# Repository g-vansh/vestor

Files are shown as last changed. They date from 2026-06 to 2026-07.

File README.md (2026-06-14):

# Vestor

An RGB LED matrix that shows aircraft passing over Boston as seen from a window in
Cambridge, MA — built on a Raspberry Pi 4 + Adafruit Triple RGB Matrix Bonnet driving
16× P5 (64×32) HUB75 panels. Grows from a single-panel flight tracker into a
modular dashboard (flights → weather → MBTA → Bluebikes → animations).

**Derived from [its-a-plane-python](https://github.com/ColinWaddell/its-a-plane-python)
(GPL-3.0).** See `NOTICE.md`.

## For the build agent
Read **`AGENTS.md`** — it is the complete, autonomous build brief (hardware, git
workflow, secrets, architecture, runbook, troubleshooting, roadmap). Progress is
logged in `docs/BUILD_LOG.md`.

## Phases
- **0** — software installed + one panel renders live flights.
- **1** — full 16-panel wall (3 chains of 6+5+5).
- **2** — rotating multi-scene dashboard.

## Quick map
- `config.py` — geometry, ZONE_HOME, scene config (no secrets)
- `display/__init__.py` — matrix init (Triple Bonnet: `regular` / `parallel` / `FM6126A`)
- `scenes/`, `data/` — modular scenes and data clients
- `scripts/` — `flash_sd.sh`, `setup_pi.sh`, `install_app.sh`, `install_service.sh`
- `services/vestor.service` — systemd unit

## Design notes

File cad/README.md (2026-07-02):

# cad/ — parametric CAD for the Vestor wall build

Parametric models (CadQuery) for a **virtual fit-check** of the wall + 16 panels +
mount, driven by the locked dimensions in `docs/design/WALL_PROFILE.md` +
`MOUNT_DESIGN.md`. Outputs a combined **STEP** (open in Fusion 360) + per-part STL
+ PyVista fit-check renders.

## Toolchain (macOS)
CadQuery/OCP need Python 3.12 (the system 3.14 is too new for the OCC wheels), in a
venv **outside** the repo:
```
brew install python@3.12
python3.12 -m venv <venv> && <venv>/bin/pip install cadquery build123d pyvista numpy trimesh
```
Current venv: `…/scratchpad/cadenv` (session-scoped; recreate with the above).

## Use
```
<venv>/bin/python cad/model.py     # build -> cad/out/*.stl + vestor_wall_assembly.step
<venv>/bin/python cad/render.py    # -> cad/out/img/{overview,corner,section}.png
```
`cad/out/` (STL/STEP/PNG) is gitignored — regenerate from source. All dimensions
are variables at the top of `model.py`; edit there and re-run.

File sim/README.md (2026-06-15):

# Vestor LED Wall Simulator

A faithful, zero-dependency browser simulator for the Vestor LED matrix wall.
It renders both the **64×32 single panel** (Phase-0 flights-only bring-up) and
the full **1024×32 wall** (16 panels, 201.6") exactly as the real HUB75 phosphor
will glow — round emitters with dark inter-pixel gaps, gamma 2.2, additive bloom,
64-px panel seams, scanlines, and a vignette.

> Full design rationale: [`../docs/design/DESIGN.md`](../docs/design/DESIGN.md).
> Data sources: [`../docs/design/API_REFERENCE.md`](../docs/design/API_REFERENCE.md).

## Run it
```bash
# from this folder
python3 -m http.server 8765
# open http://localhost:8765
```
Or just double-click `index.html` — it runs from `file://` (classic `<script>`
tags, no build step, no npm).

## Controls
- **Scene mode** — `DASHBOARD` (zoned city dashboard) · `FLIGHT TAKEOVER` (whole
  ribbon = one giant flight strip + departures board) · `MARQUEE` (scrolling
  ticker).
- **Data source** — `SIMULATED` (synthetic, offline, default) · `LIVE APIS`
  (pulls **real** Open-Meteo weather and Bluebikes availability; falls back to
  simulated on any error).
- **Brightness**, **View** (1:1 pan / fit-width), **Auto-pan**.

## Architecture
| File | Role |
|---|---|
| `led.js` | `LEDMatrix` (linear-light framebuffer, authored 5×7 + 3×5 pixel fonts, icon sprites, drawing primitives) and `LEDRenderer` (the faithful optical pipeline) |
| `scenes.js` | Every scene + animated helpers: `SplitFlap` (Solari flips), `Marquee`, `drawRadar`, `gauge`, and `FlightScene` / `WeatherScene` (°C **and** °F) / `BluebikesScene` / `ShuttleScene` / `ClockScene` / `ExtrasScene` / `StatusEndcap` |
| `data.js` | `DataModel` — believable synthetic animation, plus an optional real-API overlay shaped identically to the live endpoints |
| `app.js` | Builds both matrices/renderers, lays out the three wall modes, runs the render loop, binds the console |
| `index.html` + `styles.css` | The "Departure Board Noir" showcase page |

## Fidelity notes
The renderer models emission, not rectangles:
`linear framebuffer → brightness → gamma 2.2 LUT → nearest upscale →
destination-in round-dot mask → additive bloom (2 passes) → scanline/seam/vignette
overlay`. The single panel renders at a chunky 14-px pitch; the wall at a 5-px
pitch so the full 5120-px-wide ribbon pans like a transit ticker.

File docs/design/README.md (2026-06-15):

# VESTOR — Design & Simulation

This folder is the **design home** for the Vestor LED wall: what it shows, how it
looks, the data behind it, and the research that informed it. A fully interactive
**simulator** of everything here lives in [`/sim`](../../sim/).

## Contents
- **[DESIGN.md](DESIGN.md)** — the master visual design document: the two
  displays (64×32 Phase-0 and the 1024×32 wall), the "Departure Board Noir"
  aesthetic, palette, fonts, the faithful LED optical model, the wall zone map,
  per-scene specs, the three wall modes, and the design rules.
- **[API_REFERENCE.md](API_REFERENCE.md)** — every live data source with exact
  endpoints, station/route/stop IDs, field maps, and CORS/key notes.
- **[RESEARCH.md](RESEARCH.md)** — survey of cool HUB75/RGB-matrix projects and
  the 32-px-tall design patterns + power/color/motion findings that shaped the
  design.

## The simulator (`/sim`)
A faithful, dependency-free browser simulator that renders both displays exactly
as the phosphor will glow — round emitters, gamma 2.2, additive bloom, 64-px
panel seams, scanlines — driven by either synthetic or **real live** data.

```bash
cd sim && python3 -m http.server 8765   # then open http://localhost:8765
```
or just open `sim/index.html` directly (it runs from `file://`).

| File | Role |
|---|---|
| `sim/led.js` | `LEDMatrix` (framebuffer + 5×7/3×5 fonts + icons + primitives) and `LEDRenderer` (the optical model) |
| `sim/scenes.js` | All scenes + animated helpers (`SplitFlap`, `Marquee`, radar, gauges) |
| `sim/data.js` | `DataModel` — synthetic animation + optional live API overlay |
| `sim/app.js` | Wiring: builds both matrices, the 3 wall modes, the console |
| `sim/index.html` / `styles.css` | The showcase page |

**Controls:** scene mode (dashboard / flight-takeover / marquee), data source
(simulated / live), brightness, view (1:1 pan / fit-width), auto-pan.

## How this maps to the hardware
The simulator targets the final **1024×32 logical** surface. On the Pi, a
pixel-mapper folds the 3 physical chains (6+5+5 panels = 384×96) into that ribbon,
and Python scenes under `scenes/` render the same data shapes the simulator uses.
See `docs/HARDWARE.md` and `docs/RUNBOOK.md` for the build, and `tools/` for the
live data clients.

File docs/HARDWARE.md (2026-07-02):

# HARDWARE

- **Pi 4 Model B, 4GB** (not Pi 5 — hzeller driver maturity).
- **Adafruit Triple RGB Matrix Bonnet 6358** — active3, 3 chains, no onboard power, no soldering. Ports 1/2/3; Port 2 = center of 3 adjacent panels.
- **16× P5 HUB75** 64×32, ~320×160mm, 1/16 scan, **FM6124HJ** chip (a STANDARD driver — needs NO init string, unlike FM6126A/FM6127; A–D address, no E). **Brand CnGear, board rev JHT2.0, SMD2121** — verified off the physical boards 2026-06-29. Each panel has an **integrated plastic rear frame** (X-braced); **no magnets included** — mounting method TBD (see `INVENTORY.md` §6/§8).
- **Wall topology (LOCKED 2026-06-21): one continuous 16-wide row, fed from the CENTER as 2 chains of 8** (`--led-parallel=2 --led-chain=8`). Pi+bonnet center-mounted; chain 0 → left (panels 8→1, mounted 180°/SW-flipped), chain 1 → right (panels 9→16). Keeps every HUB75 ribbon <50cm. (Superseded the earlier 6+5+5 plan, which needed 1.9–3.5 m jump cables in a single row. See `docs/INVENTORY.md` §5.)
- **⚠️ Topology RECONSIDERED 2026-07-02 (corner electronics):** the Pi/bonnet now go in the room's **left corner** (the wall's grooved feature turns the corner). The corner is the row's left END, so the center-fed 2×8 would need a ~2.5 m bonnet ribbon (bad — HUB75 wants < ~50 cm). **CONFIRMED 2026-07-02: single chain of 16 from the corner** (`--led-chain=16 --led-parallel=1`), keeps every ribbon short + **removes the "snake"/180° left-half flip** in `display/__init__.py`. **Refresh MEASURED on the Pi** (slowdown=4): old 2×8 = 150 Hz @11-bit; 1×16 = 86 Hz @11-bit, **111 Hz @9-bit**, 123 Hz @8-bit, 139 Hz @7-bit. **Recommended: `pwm_bits=9` → 111 Hz** (flicker-free + 512 levels/ch, ample for text/logos/fades). Could raise further by dropping `gpio_slowdown` to 3/2 if signal stays clean (wall-time tune). Full analysis: `docs/design/MOUNT_DESIGN.md`.
- **Mount anchor (owner-confirmed 2026-07-02): a full-width STRUCTURAL WOODEN rail** at the top of the wall — a 2 cm lip standing **3.4 cm proud**, with a continuous **open-top pocket (1.4 cm wide × 5 cm deep)** running the full ~512 cm. Plan: hang the whole row from a **top cleat/tongue (≤1.4 cm) dropped into the pocket**; the 3.4 cm projection gives standoff behind the panels; PSUs mount separately. Full geometry, panel-row sizing, load path + constraints in **`docs/design/WALL_PROFILE.md`**. (Resolves the panel "mounting method TBD" above — the cleat replaces the need for magnets on the plastic rear frames.)
- **Power:** Mean Well **LRS-350-5** (5V/60A) ×2 for the wall (1 for Phase 0), fork-lug AC cord. Panels powered from PSU; **bonnet logic from Pi 5V GPIO rail**.
- **SD:** 64GB Verbatim microSDXC (V10/U1; image a backup once set up).
- **Flash host:** Mac + built-in SDXC + Raspberry Pi Imager.

## The 3 settings that matter
1. `--led-gpio-mapping=regular` (NOT adafruit-hat).
2. `--led-parallel=3` wall / `1` test; `--led-chain=6` wall / `1` test.
3. `--led-panel-type` **unset** — FM6124D is standard. Only if the panel stays BLACK, try `=FM6126A` then `=FM6127` as a fallback, then remove again.

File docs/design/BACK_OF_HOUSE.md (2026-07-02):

# VESTOR — BACK-OF-HOUSE (electronics siting + data topology)

Where every non-panel thing physically lives, how it's hidden, and the final data
topology. Backed by two cited research passes (HUB75 chain topology; back-of-wall
electronics hiding + PSU thermal). Companion: `../ELECTRICAL.md` (power),
`MOUNT_PARTS.md` (mount). Established 2026-07-02.

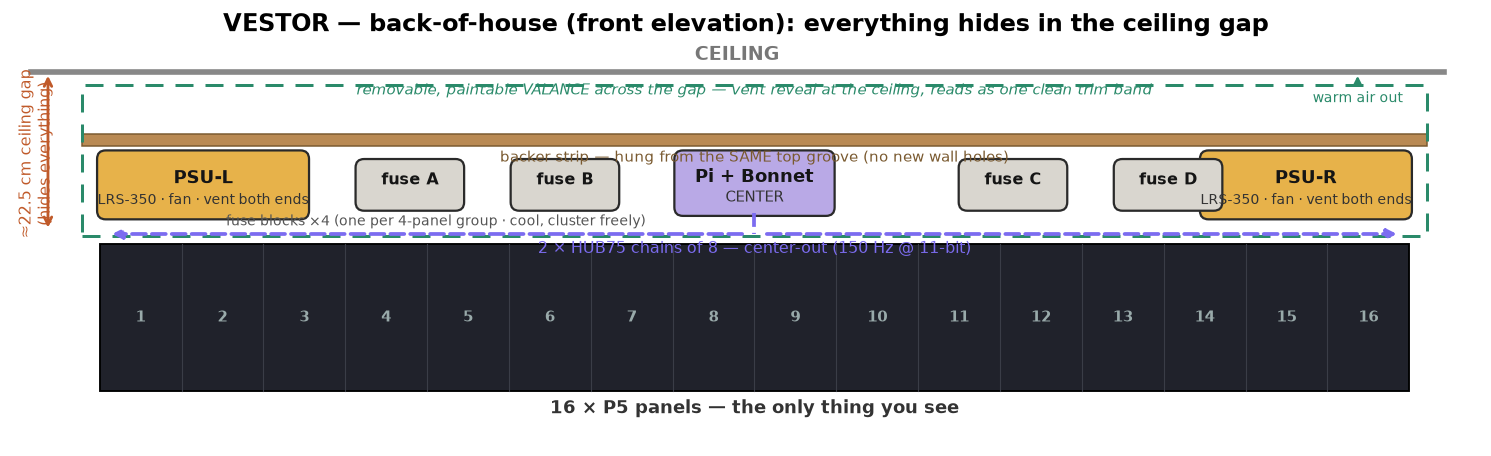
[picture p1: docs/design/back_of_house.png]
back of house


## The space: the ~22.5 cm ceiling gap is the service plenum

Behind the panels there is only ~1 cm — nothing hides there. The home for all the
hardware is the **~22.5 cm gap between the top of the panels and the ceiling**, running
the full 5.1 m. Everything mounts to a **continuous backer strip hung from the SAME top
wooden groove** (brackets drop a tongue into the groove and rise into the gap → **zero
new wall holes**; the groove is structural and the added load is ~2–3 kg). Optionally add
1–2 stud anchors for the strip itself as insurance — it's the only place dedicated anchors
would ever be worth it, and even that's optional given the groove's margin.

## What goes where (split by heat + the data topology)

| Item | Location in the gap | Why |
|---|---|---|
| **2× LRS-350-5 PSUs** (hot, fan) | **one near each END**, lying flat (horizontal), **both short-end vents clear**, ≥10–15 cm of air, not stacked over each other or a fuse block | Mean Well: fan is thermostatic (on ≥50 °C), airflow is **end-to-end**, and it derates above 50 °C ambient — so they must *breathe*. Ends stay coolest + shortest 5 V runs to each half. |
| **Raspberry Pi + Triple Bonnet** (cool) | **CENTER** | Feeds the two data chains outward (see topology). Runs cool → no thermal fuss; keep it off a PSU's exhaust. |
| **4× fuse blocks** (cool) | distributed, one per 4-panel group, on the strip | No heat → cluster freely wherever the DC trunks break out. |

**Thermal rule:** the valance (below) must make the gap behave like an **open shelf, not a
sealed box** — a gap sealed front+ends is a heat trap. If either end of the wall opens to a
cooler cavity/closet, dropping a PSU there (DC out into the gap) is the cleanest thermal answer.

## Hiding it: a breathing valance

Close the gap's front with a **removable, paintable valance** (MDF or 1× pine, full 5.1 m,
painted to match) standing off the wall — built as a **CHIMNEY, not a seal**: a **continuous vent
reveal at the ceiling (exhaust) + a low intake slot** so warm air convects out on its own
(optionally a quiet low-RPM exhaust fan). This is the highest-leverage permanent thermal decision —
retrofitting airflow into a closed 5 m gap is painful, and heat drives the top failure modes
(`../HARDENING.md`). It hides the row of silver boxes so the wall reads as **one clean trim band**,
and stays **removable** (magnets/cleat/few screws) for service — required, since a PSU can't be
permanently sealed (NEC) and terminals need re-torque access. Pro-standard for a floating wall with no rear clearance.

**EMI note:** run **wired Ethernet to the Pi and disable WiFi** — the wall is a broadband RF emitter
next to the Pi (Foundation-documented 2.4 GHz desense). Keep ribbons short and on a separate path
from the 60 A DC bus (cross at right angles). Details: `../HARDENING.md`.

## Wiring dress
- **10 AWG DC trunks** run along the strip, locked with adhesive/screw cable-tie mounts every
  ~15–20 cm; a **short vertical pigtail drop at each panel**.
- **Bundle like-with-like:** DC pigtails in one **spiral-wrap** loom (break out per panel), the
  16 **HUB75 ribbons** in a separate sleeved spine — power and data don't tangle. Keep ribbons
  gently arced (don't crease flat ribbon) and away from PSU exhaust.

## DATA TOPOLOGY — center-fed 2×8 (SUPERSEDES the single chain of 16)

**Locked: Pi in the CENTER, two chains of 8 in opposite directions** —
`--led-chain=8 --led-parallel=2 --led-pixel-mapper="U-mapper;Rotate:180"` (orientation tuned
once at bring-up). The Bonnet's two outputs land on the two **center panels (8 & 9)** → all
ribbons short. Chosen over the end-fed single chain of 16 because it wins on every axis that
matters for this content:

- **Color depth:** **11-bit (2048 levels) vs 9-bit (512)** — 4× finer gradients; banding shows
  worst in dark tones + slow fades, which *is* this board. (The big one.)
- **Signal integrity:** 16-on-a-chain = 32,768 px on one serial clock — 2× past hzeller's
  "already pushing limits," with ghosting on bright-text-over-dark as the documented failure.
  **8/chain is the safe sweet spot**; the active bonnet cleans the first hop but doesn't re-drive
  every panel. Center-feed also **shortens** every ribbon.
- **Refresh/camera:** **150 Hz vs 111 Hz** — margin for peripheral flicker (you stand close to a
  5 m wall), smoother swoop/split-flap motion, and cleaner phone video.
- **Cost:** the "snake" is a **built-in launch flag** (U-mapper/Rotate), not code you maintain;
  latency difference ~2 ms (imperceptible). Software already had the 2×8 snake logic.

**Implications:** revert `display/__init__.py` to `parallel=2, chain=8` + the U-mapper; the
"corner enclosure" CAD part becomes a **center enclosure**; the Pi's USB-C runs to center (its
GND bonds to the common V−). PSUs still split L/R (power is independent of data).

## Still to confirm on-site
- The **panel's power-connector position** (decides up-vs-down pigtail routing).
- Whether an end opens to a cooler cavity (better PSU home).
- Valance material/finish to match the room.

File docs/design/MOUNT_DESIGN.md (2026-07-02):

# MOUNT DESIGN — hanging the 16-panel wall (clean-slate, 2026-07-02)

**Supersedes `docs/INVENTORY.md` §8** (the old 80/20-into-studs plan, drawn before we
knew the wall has a built-in structural wooden pocket and before we had the MIT Hobby
Shop's full wood + metal + print capability). Reads with
`docs/design/WALL_PROFILE.md` (the wall) and `docs/FABRICATION.md` (the shop).

## ✅ LOCKED DECISIONS (2026-07-02)

1. **Hang from the wall's built-in grooves — zero new wall holes.** Wood **½″
   Baltic-birch top tongue-cleat** into the **top groove** (open-up, carries the load,
   ~10× margin) + a **bottom capture tab** up into the **bottom groove** (open-down,
   anti-swing). Fully captured top + bottom.
2. **Frame = two continuous horizontal aluminum rails** at the panel's 144 mm M3 rows
   (dead-flat reference). *(Can machine our own from bar/plate on the Hobby Shop mills/
   waterjet — no need to buy 80/20.)*
3. **Panels = MAGNETIC** (owner-tested OK): thin **steel strips** on the rails + the
   on-hand **magnet screws** (96/100) → snap-on, self-aligning, tool-free; **alignment
   pins** for lateral seams.
4. **Electronics in the LEFT CORNER** (the grooved piece turns the corner) — Pi + Triple
   Bonnet on the 3.4 cm ledge / hung. Resolves depth-behind-panels.
5. **Feed = SINGLE CHAIN OF 16 from the corner** (`--led-chain=16 --led-parallel=1`,
   **`pwm_bits=9` → measured 111 Hz**). All ribbons short; **removes the snake/180° flip**
   in `display/__init__.py`. (Supersedes the old 2×8 center-feed.)
6. **Power:** keep **PSU2 out near the right half** (short 5 V runs) — or a heavy 5 V bus
   if all-in-corner (keep drop < 3 %).
7. **Fit:** 16 × 320 = 5120 mm into **201.5″ (~5118 mm) usable → butt tight, no side
   frames.** Panels ~flush to the wall (connectors barely protrude).
8. **3D prints locate/interface only** (panel clips, Pi/PSU enclosures, cable clips) —
   PLA now, PETG/ASA later; nothing structural rides on PLA.

## ✅ DESIGN VALIDATED + REFINED (deep research, 2026-07-02)

Checked the locked plan against how commercial LED walls + architectural panels are
actually hung. It matches best practice on every axis; three refinements make it optimal.

**What the research says:**
- Coplanar seams come from a **rigid, precisely-LEVELED rail grid** + per-module
  **micro-adjustment in 3 axes** (esp. depth/Z). [LumenMatrix, ledlightsworld]
- Modules are **magnet-snapped** for quick positioning, then **alignment pins / micro-
  adjusters** refine seams; magnetic connectors cut install errors ~50%. [Radiant, MOUNT-IT]
- **Adjustable magnet HEIGHT is the standard coplanarity control** — exactly what our
  **thread-in magnet screws** provide (screw in/out = per-panel Z-adjust). [ledscreenparts]
- **6063-T5 aluminium** frames are the industry standard (dimensionally stable).
- **Continuous aluminium cleat / Z-clip rails** (6–12 ft lengths) are a proven concealed
  hanging system with easy **lateral adjustment** — validates a continuous cleat. [Eagle/Monarch/Orange Aluminum]
- Magnets are great for **indoor / light / low-vibration** + service; weaker than bolts in
  shear/vibration (irrelevant for 0.45 kg indoor panels) — but **rest the weight on the
  rail** so magnets only hold coplanarity, not shear.

**Three refinements to the locked plan:**
1. **Continuous cleat-tongue** in the top groove (not discrete cleats) → better load spread
   + easier leveling & lateral adjustment.
2. **Panel weight rests on the bottom rail / a lip** (magnets only hold it flat) → removes
   any long-term magnet-shear / creep worry.
3. **Alignment pins** between panels for lateral seam registration (magnets don't locate sideways).

**FINAL ARCHITECTURE (optimal, research-validated):**
1. Continuous **½″ Baltic-birch (or aluminium) tongue** in the TOP groove — the hang.
2. Two continuous **6063 aluminium rails** at the panels' 144 mm M3 rows → the flat reference
   grid, hung from the top groove + laser-leveled.
3. **Steel strips** on the rail faces → the ferrous plane for the magnets.
4. **Panels magnet-mount** via the on-hand magnet screws; **thread depth = per-panel Z
   coplanarity micro-adjust**; **alignment pins** set lateral seams; panel weight **rests on
   the bottom rail** (a lip), magnets hold it flat.
5. **Anti-swing tab** up into the BOTTOM groove (mid-height capture) → fully constrained,
   zero new wall holes.
6. **Corner electronics** hung from the LEFT-wall grooves (same tongue system).
7. **3D prints** = adjustable panel clips, alignment-pin holders, Pi/PSU enclosures, cable
   clips (PLA now → PETG/ASA later; nothing structural on PLA).

**Build sequence:** hang + **laser-level the rails on the wall** (using the top groove) →
populate panels **one at a time** (tool-free magnetic, self-coplanarizing via magnet-screw
depth + alignment pins), re-checking flatness every 2–3 → engage the bottom anti-swing tab →
hang the Pi/PSU in the corner → dress cabling. **Never handle a floppy 5 m assembly** (rails
first, then populate — the pro method).

## Design goals, in priority order

1. **Won't fall** (safety first).
2. **Dead flat / coplanar** across 5.12 m with tight, even seams — *this is the hard
   part; weight is trivial.*
3. **Reliable for years** — no creep, no sag, no humidity warp, no loosening.
4. **Serviceable** — pull one panel without dismantling the row.
5. **Minimal/zero new damage to the wall** — use what's already there.

## The key realization: the wall already gives us the hard part

The wall's **full-width structural wooden pocket** (1.4 cm × 5 cm, open-top —
`WALL_PROFILE.md`) is a **pre-built, continuous French cleat that's part of the
building**. Research: a wood French cleat holds **50–100+ kg**, and its reliability is
normally limited by *how well the cleat is anchored to studs* — here that's moot,
because the receiver is **solid structural wood spanning the whole width**. Our entire
assembly is **~10 kg**, so the hang has a **~5–10× safety margin** before we do
anything clever. **We hang from the pocket. Full stop.** No stud-hunting, no toggle
bolts, no lag screws — and the pocket supports *continuously*, which (per beam theory)
makes the frame go dead flat with a much lighter/shallower section than a stud-anchored
rail would need.

## Recommended architecture — "wood hangs it, metal keeps it flat, prints fine-tune it"

Each shop does what it's best at:

| Layer | Part | Material | Shop | Why |
|---|---|---|---|---|
| **Hang** | Continuous **tongue-cleat** dropped into the pocket (full width, ~2–3 sections) | **½″ (12 mm) Baltic-birch ply** | Woodshop (table saw / CNC) | Fits the 14 mm pocket; wood-on-wood; continuous compression into structural wood; the proven never-delaminate cleat material. |
| **Flatness** | Two continuous **horizontal rails** (top + bottom, ~144 mm apart = the panel's M3 hole rows), each in 2 halves (~2.56 m) spliced at center | **Aluminum T-slot (2020/2040)** | Metal shop (cold saw to length) | Dead straight + dimensionally stable (no humidity warp — the one knock on ply); T-slot = infinite micro-adjust, the pro requirement for coplanar seams. |
| **Registration** | **Adjustable panel clips** — bolt to the rail T-slot, screw into the panel's 6 M3 brass holes, with a screw for **depth (Z) micro-adjust** | **3D-print** (PLA now → PETG later) | Printers | Per-panel 3-axis fine-tune (research: micro-adjusters refine each seam); these *locate*, they don't bear sustained load → PLA-safe. |
| **Bottom capture** | **Tab that slides UP into the wall's BOTTOM groove** (1.8 cm × 5.7 cm, open at bottom) | ½″ birch or printed | Woodshop / printers | **UPDATE 2026-07-02:** the wall has a *second* groove open at the bottom → capture the frame's bottom in it (front-back + anti-swing) instead of a spacer-to-wall. Now the assembly is **fully captured at BOTH ends by built-in wall grooves → zero new holes.** |
| **Brain** | **Pi + Triple Bonnet enclosure** | 3D-print | Printers | Mount **below** the row center (depth — see below). |
| **Power** | **PSU cradles** ×2 (LRS-350-5, ~215×115×30 mm, ~0.6 kg ea) | Printed or wood/metal, **vented** | any | Separate from the hung row; warm → keep airflow, keep off PLA later. |

**Load path:** panel → printed clip → aluminum rail → bracket → **wood tongue-cleat →
wooden pocket → wall**. Every sustained-load link is **metal or structural wood**;
prints only locate. No PLA in the permanent load path → no creep.

```
 ceiling
 ▒▒│ TOP groove (open↓): ½" birch tongue-cleat drops in, rests on floor → HANGS load
 ██│ piece attached to wall (middle)
 ▒▒│ BOTTOM groove (open↑): tab slides up → CAPTURES bottom (anti-swing), no holes
 wall
        ┌─ TOP aluminum rail ────────────  ← panels clip/snap (top M3 row)
        │     [ open air: HUB75 + power behind panels ]
        └─ BOTTOM aluminum rail ─────────  ← panels (bottom M3 row, 144 mm)
              Pi+bonnet enclosure hangs just below center
```

## What the bottom groove changes (2026-07-02)

The wall has a **second groove, open at the bottom** (1.8 cm × 5.7 cm — see
`WALL_PROFILE.md`). This is a real upgrade:

- **Fully captured, zero new holes.** Before, only the top pocket carried load and
  the bottom needed a spacer/ledger (possibly a wall fixing). Now the frame is
  **captured at both ends by built-in wall grooves** — **top groove hangs the
  weight** (drop-in tongue rests on its floor), **bottom groove captures the bottom**
  (a tab slides up into it, locking it front-to-back and anti-swing). The wall does
  everything; we add **no holes at all.**
- **Rigidity.** Two engaged grooves 14 cm apart resist rocking/tip far better than a
  top hang + a contact spacer.
- **Assembly kinematics** (the one wrinkle): the **top groove opens up (drop in)** and
  the **bottom groove opens down (push up)** — opposite directions, so you can't
  translate a rigid frame into both at once. Plan: **hang the top tongue first** (bears
  the load), then engage the bottom with a **separate insertable/spring tab** pushed up
  into the bottom groove and locked. That tab is a small CAD part; the top hang alone
  is already safe (~10× margin), so the bottom tab is capture, not load.

## Magnet screws — the 100 on-hand feet (optional, good for service)

We have **100 magnet-screw feet** (they screw into the panels' M3 brass holes). Geometry
(owner-measured): they **jut 1.1 cm** off the panel back — **~0.8 cm of cylindrical
shaft**, then a **magnet base** (~0.3 cm) at the end. Magnets need **ferrous** metal
(they won't stick to wood/aluminum), so they only help if we **face the frame rails
with thin steel strips**.

- **If used (magnetic panel mount):** panels **snap on / pull off from the front**
  (tool-free service) and **self-align to the flat steel plane** (helps coplanarity in
  the depth axis). 6 magnets/panel × 16 = **96 (we have 100)**. Put the steel strips on
  the **flat aluminum rails** (aluminum sets flatness, steel gives the magnetic face),
  and add **alignment pins** for lateral (seam) registration — magnets don't locate
  sideways. **Watch the 1.1 cm standoff vs the panels' rear connectors** (~8–10 mm) —
  fine if the strips sit at the top/bottom **edge** rows (where there are no connectors;
  ribbons live in the open center).
- **If not used (magnet-free):** panels **screw** (M3) to printed brackets on the rails
  — positively located, no steel needed, but service = unscrew from behind (harder once
  wall-mounted).
- **CONFIRMED 2026-07-02 — GO MAGNETIC.** The owner tested it: the 1.1 cm standoff
  **clears the (barely-protruding) connectors + ribbons**, and the magnet hold is
  strong. So the plan is **magnetic panel mount**: thin **steel strips** on the flat
  aluminum rails + the on-hand magnet screws (6/panel × 16 = 96 of the 100) → panels
  **snap on/off from the front** (tool-free) and **self-align** to the flat steel plane.
  Add **alignment pins** for lateral (seam) registration. Magnet-free (M3 screws) stays
  a clean fallback but is no longer needed.
- **Note:** the magnets do **not** hang the panels from the wall (the grooves are wood,
  non-ferrous). They hold **panel → frame**; the **frame → wall** hang is the wood
  tongue in the grooves.

## The LEFT CORNER changes two electrical things (2026-07-02)

The Pi + Triple Bonnet now live **in the left corner** (see `WALL_PROFILE.md`) — great
for mounting/depth, but the corner is the **left END** of the row, which forces two
decisions (both researched):

### 1. Feed topology — recommend a SINGLE CHAIN OF 16 (supersedes the LOCKED 2×8)
- HUB75 is a high-speed parallel bus: **keep the bonnet→first-panel ribbon < ~50 cm**;
  long runs cause pixel corruption/noise. The old **center-fed 2×8** kept both feed
  ribbons short *because the bonnet was in the middle*. From the **corner**, a 2×8 split
  would need a **~2.5 m ribbon** to reach the middle panel (chain 1's start) — **not OK**.
- **A single chain of 16 from the corner keeps EVERY ribbon short** (bonnet→panel 1 at
  the corner, then short panel-to-panel daisy-chains 1→16). It's also **simpler in
  software** (direct 1024×32 map — **no "snake"/180° left-half flip**) and uses **1 of
  the bonnet's 3 ports** (2 spare).
- **Cost — MEASURED on the Pi (slowdown=4):** old 2×8 = **150 Hz** @11-bit color; 1×16 =
  **86 Hz** @11-bit, **111 Hz** @9-bit, 123 Hz @8-bit, 139 Hz @7-bit. All are flicker-free
  (eye fusion ~60–90 Hz; a monitor is 60–120 Hz). "Color depth" = brightness steps per R/G/B
  channel: 11-bit=2048, 8-bit=256 (= "true color", what a laptop screen shows). On flat
  text/logos the difference is **imperceptible** (only smooth photo gradients would band).
- **CONFIRMED: `--led-chain=16 --led-parallel=1`, `pwm_bits=9` → 111 Hz**, and **remove the
  snake/flip** in `display/__init__.py` (at wall-build). Could push higher by lowering
  `gpio_slowdown` (4→3/2) if the signal stays clean. Keep 2×8 only if max refresh mattered
  (it doesn't for a static board) — and it can't cleanly corner-mount anyway.

### 2. Power distribution — mind 5 V voltage drop over 5 m
- 5 V is drop-sensitive (**keep < ~3 % = 0.15 V**). The old plan put **PSU1 behind the
  left half, PSU2 behind the right half** so no 5 V run exceeds ~2.5 m.
- If **both** PSUs go in the corner, the right end is ~5 m away → big drop unless a
  **heavy 5 V bus** (thick gauge / copper bar, inject every ~1 panel).
- **Recommended:** Pi/bonnet in the corner; **keep PSU2 out near the right half** (short
  runs, less copper) — a PSU is just a box, it doesn't need to sit with the Pi. If you'd
  rather keep *everything* in the corner, run a **heavy 5 V bus + per-panel injection**
  and size it for < 3 % drop.

## Why this over the alternatives

- **vs the old 80/20-into-studs plan:** we no longer drill ~10 stud anchors; the
  pocket is a better (continuous, structural, zero-new-holes) anchor, and continuous
  support lets the rail be lighter/shallower — which matters because the lip only
  stands **34 mm** proud.
- **vs all-aluminum welded frame:** overkill for 10 kg; heavier; no aesthetic gain.
- **vs a solid plywood backer:** a solid sheet fights the panels' rear connectors and
  the depth budget; the open two-rail frame leaves the center free for cabling + the
  Pi/bonnet.

### Honest alternative — **all-Baltic-birch modular cassettes**

If you'd rather keep it **all-wood, all-in-house, and cheaper**: split the row into
**4 CNC-cut Baltic-birch cassettes of 4 panels** (~1.28 m each), each a ladder frame
(top+bottom rails + verticals) with the exact M3 hole grid + connector windows + a
tongue cut in one Laguna CNC job; hang each from the pocket; register cassette-to-
cassette with dowel pins. **Pros:** ~free (1 sheet or `reuse@mit`), matches the wooden
wall, modular = easy to carry/hang/service, short 1.28 m pieces stay flat. **Con:**
slightly less dimensionally stable than aluminum over years (humidity) — mitigated by
Baltic-birch quality, short spans, sealing, and the wall's continuous support. This is
a very strong option; I lead with the aluminum-rail version **only** because T-slot's
micro-adjust makes hitting perfect coplanarity easier. Either is reliable.

**My pick:** aluminum rails + wood cleat + printed clips for max flatness/adjustability;
switch the rails to Baltic-birch cassettes if you want zero-cost + all-in-house and
accept marginally less long-term stability.

## Measurements, checks & tests before CAD/build

The design is robust regardless, but these resolve the exact part geometry. Grouped:

### MEASURE (tape / calipers; do the wall ones at ~5 points across the 512 cm)
1. **Re-confirm the wall numbers + that they're UNIFORM full-width:** ceiling→top-of-piece
   (22.5), piece thickness (2), height (14), **top groove** width (1.4) + depth (5),
   **bottom groove** width (1.8) + height (5.7), middle attach (~3.3), wall step (0.4).
   Note the **usable** groove widths (a hair under, after paint/finish).
2. ~~Depth for the Pi behind the panels~~ — **RESOLVED 2026-07-02: the Pi/bonnet go in
   the LEFT CORNER, not behind the panels**, so no depth-behind constraint. (This was
   the only thing #2 needed; the flat cross-section already gives the wall geometry.)
   Still a *preference* to pick: the row's vertical position (top groove ≈ 22.5 cm below
   ceiling).
3. **Panel M3 hole grid:** vertical pitch (~144 mm) + horizontal column spacing + positions
   vs the panel edges. → the bracket/clip + steel-strip CAD.
4. **(nice-to-have)** confirm panel weight (~0.45 kg) — owner says light, so non-blocking.

### CHECK (eyes/hands)
6. **Continuity:** is the piece + both grooves **unbroken across all 512 cm** — any outlets,
   corners, nails, blobs, or spots where a groove is blocked/narrower?
7. **Groove interior:** clean wood a tongue slides freely in? Any paint/caulk narrowing it?
8. **Piece is solid + firmly attached** along its whole length (push/pull — does it flex?).

### TEST (5-minute, before committing parts)
9. **Tongue fit:** cut a short (~10 cm) scrap to the measured groove widths and **slide one
   into the top groove** (seats on the floor ~5 cm down, snug but free) and one into the
   **bottom groove** (1.8). Validates the cleat/tab thickness before making full-length ones.
10. ✅ **Magnet connector-clearance — PASSED (owner, 2026-07-02).** The 1.1 cm standoff
    clears the connectors/ribbons → **go magnetic.**
11. ✅ **Magnet hold — PASSED.** Firm hold (6/panel
    holds 0.45 kg with big margin, but confirm the magnets aren't weak).

## Build sequence at the Hobby Shop

1. **Measure** the depth + pocket-to-panel-height relationship (above) + confirm panel
   weight + pocket uniformity across 512 cm.
2. **Woodshop:** rip the ½″ Baltic-birch **top tongue-cleat** to fit the top groove
   (test-fit a short offcut first); make the **bottom capture tab** to fit the 1.8 cm
   bottom groove.
3. **Metal shop:** cold-saw the **aluminum rails** to length (2× ~2.56 m per rail,
   top+bottom); prep T-slot splice plates for the center joints.
4. **Printers:** run the **adjustable panel clips** (batch), the **Pi/bonnet
   enclosure**, **PSU cradles**, and **cable clips** (parametric CAD — see FABRICATION).
5. **Assemble on the wall:** drop the top tongue-cleat into the top groove → hang the
   top rail from it → **laser-level** → hang the bottom rail → **engage the bottom
   capture tab up into the bottom groove** and lock it → mount panels **one at a time,
   left of center outward** (snap-on if magnetic), refining each seam and **re-checking
   flatness every 2–3 panels** (research best practice) → hang the Pi/bonnet below →
   dress cabling → power up per chain.
6. **Maintenance:** re-check seam flatness + re-torque clips annually.

## Safety + longevity notes

- **~5–10× load margin** on the hang; verify nothing bears on PLA long-term (it
  doesn't, by design).
- **Heat:** panels run warm at `BRIGHTNESS ≤ 50`; keep PSUs **vented and separate**;
  don't tightly enclose electronics in wood/PLA.
- **Wall:** primary support is the built-in pocket → **no new structural holes**; the
  bottom spacer is contact-only if possible (a couple of discreet anchors optional as a
  belt-and-suspenders safety, TBD by wall material).

## Still open (small, non-blocking)
- Final rail material call (aluminum vs Baltic-birch cassettes) — after the depth
  measurement.
- Exact tongue-cleat ↔ rail bracket (a short CAD part) once depth is known.
- Whether to add a bottom safety fixing (depends on wall material below the lip).

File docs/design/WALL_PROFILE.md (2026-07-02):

# Wall top profile — the mounting rail for the 16-panel wall

Source: hand sketch `IMG_3822` (2026-07-02), reference image
[`wall_top_profile.jpg`](wall_top_profile.jpg). Cross-section (side view) of the
top of the wall where it meets the ceiling. Geometry **owner-confirmed** after
three passes. All units **cm** (inches noted where useful).

## TL;DR — what this is

Running the **full width of the wall (~201 in / ~512 cm)** there is a
**structural WOODEN rail** at the top: a **2 cm-thick lip, 14 cm tall, standing
~3.4 cm proud of the wall**, attached to the wall only across its **middle ~3.3 cm**
— so behind it are **TWO grooves** (updated 2026-07-02):
- **TOP groove** — 1.4 cm wide × ~5 cm tall, **open at the TOP** (drop a cleat in
  from above; bottoms out ~5 cm down).
- **BOTTOM groove** — 1.8 cm wide × 5.7 cm tall, **open at the BOTTOM** (slide a
  tab up into it from below; closed at its top).

It's load-bearing ("holds a lot of weight"). In effect it's a **built-in full-width
mounting rail captured at BOTH ends** — **hang** the panel row's weight from the
top groove and **capture** its bottom in the bottom groove, so the whole assembly
is fully constrained **with zero new holes in the wall**.

## Measured dimensions

| Label | Value | Role |
|---|---|---|
| `22.5 cm` | 22.5  | ceiling straight down to the **TOP of the piece** |
| `2 cm` | 2.0 | **thickness** of the jutting wooden piece/lip (uniform) |
| `14 cm` | 14.0  | **height** of the piece |
| **TOP groove** | ~5 cm tall × 1.4 cm | behind the piece **top**, **open at the top** |
| **BOTTOM groove** | 5.7 cm tall × 1.8 cm | behind the piece **bottom**, **open at the bottom** |
| middle | ~3.3 cm | band where the piece **attaches to the wall** (14 − 5 − 5.7) |
| projection | ~3.4 cm | piece front off the (main) wall — **uniform; the piece is straight** |
| wall step | 0.4 cm | the wall is **cut 0.4 cm deeper *below* the attachment** → that's why the bottom gap (1.8) > top gap (1.4), NOT because the piece tilts |

Full width (into the page): **~512 cm (~201 in)** — both grooves run the whole way.

## Geometry (confirmed; bottom groove added 2026-07-02)

A **2 cm-thick wooden piece** juts ~3.4 cm out from the wall, **14 cm tall**,
attached to the wall only across its **middle ~3.3 cm**. There is **no recess cut
into the wall itself** — the grooves *are* the space between the piece and the
wall, at the top and bottom:

- **TOP groove** — between the piece top and the wall: **1.4 cm wide × ~5 cm tall,
  OPEN AT THE TOP** (drop a cleat/tongue in from above; it bottoms out ~5 cm down).
- **MIDDLE ~3.3 cm** — the piece **attaches to the wall** here.
- **BOTTOM groove** — between the piece bottom and the wall: **1.8 cm wide × 5.7 cm
  tall, OPEN AT THE BOTTOM** (slide a tab up into it from below; closed at its top).
- Ceiling → top of piece: **22.5 cm**. Heights: 5 + 3.3 + 5.7 = **14**.
- The **piece is perfectly STRAIGHT** (uniform 2 cm, vertical front), projecting a
  **uniform ~3.4 cm** off the main wall. The bottom gap is **1.8 cm (vs 1.4 top)
  only because the WALL is permanently cut 0.4 cm deeper *below* the attachment**
  — the piece does NOT tilt.

```
   ceiling ─────────────────────────────
              │ 22.5 cm (to top of piece)
              ▼   ↓ drop cleat in
        ┌──┐▒▒│  ← TOP groove  OPEN at top   (1.4 wide × ~5 tall)
        │  │▒▒│
        │  │██│  ← MIDDLE ~3.3 cm: piece attached to wall
        │  │▒▒│  ← BOTTOM groove OPEN at bottom (1.8 wide × 5.7 tall)
   piece│  │▒▒│
        └──┘▒▒│  ↑ push tab up
   ────────wall────────   (piece 14 cm tall, 2 cm thick, ~3.4 proud)
```

## Full extent + the LEFT CORNER (owner update 2026-07-02)

- **Usable length: 201.5 in (~5118 mm) end-to-end.** The 16-panel row is 16 × 320 =
  **5120 mm** → an **essentially exact fit (~2 mm over)**. Plan for **zero spare
  width**: butt panels tight, **no side frames that add width**; any ~2 mm is
  absorbed at the corner / in seam tolerance.
- **The LEFT end is a room corner, and the whole grooved piece TURNS the corner**
  (continues onto the perpendicular return wall).
- **→ The left corner is the EQUIPMENT BAY.** The Pi + Triple Bonnet (and optionally
  a PSU) live **in the corner** — hung there or set on the piece's **3.4 cm ledge** —
  using the same grooved feature on the return. **This resolves the "where does the
  Pi go / depth behind the panels" question entirely** (electronics are off to the
  side, not behind the LED face). The panels themselves sit close to the wall (owner
  confirms the **rear HUB75 connectors + ribbons barely protrude**).

## What it must carry — the LED panel row

Wall topology is **LOCKED**: one continuous **16-wide row**, center-fed as 2
chains of 8 (see `docs/HARDWARE.md`). So the row is:

- **16 × 320 mm = 5120 mm = 512 cm (~201.6 in) wide** — matches the rail width.
- **160 mm = 16 cm tall** (single panel high).
- Logical render **1024 × 32 px**.
- Weight: est. **~0.5 kg/panel → ~8 kg of panels**, plus the mounting
  frame/cleat (confirm panel weight against `INVENTORY.md`).

The row (16 cm tall) is ~2 cm taller than the lip (14 cm), so panels hung at the
lip roughly **cover and hide the wooden rail** — a clean look.

## Mounting concept (leading candidate — pending on-site checks)

The pocket is a full-width, upward-open mortise → treat it as a **cleat slot**:

1. Build a rigid **top hanging rail** for the panel assembly (e.g. an aluminium
   extrusion / wood bar spanning the width) with a **downward tongue ≤ 1.4 cm
   thick** that **drops into the pocket from the top**. Aim ~1.0–1.2 cm tongue
   for clearance; engage ~4 cm of the 5 cm depth.
2. Mount the panel frame to/below that rail. **Load path:** panels → hanging rail
   → tongue → pocket → structural wooden rail → wall. The wood is load-bearing,
   so this carries the ~10–13 kg assembly.
3. The lip holds everything **3.4 cm off the wall** → a natural **air gap behind
   the panels** for HUB75 ribbons + cabling.
4. Add a **bottom restraint** (spacer/standoff to the wall, or a lower fixing) so
   the row can't swing/tip out at the bottom.

**Mount the two LRS-350-5 PSUs SEPARATELY** (heavy, hot, need airflow) — on the
wall/shelf below or behind, NOT hung from the pocket.

## Constraints to respect

- **Tongue/cleat thickness ≤ 1.4 cm** (pocket width). Straight & flat over 512 cm
  (or segment it).
- **Pocket depth 5 cm** — usable engagement; don't rely on the full 5 cm.
- **Standoff = 3.4 cm** only. The **center Pi + Triple Bonnet stack** (est.
  ~4–5 cm deep) likely needs MORE than 3.4 cm → plan a recess, a deeper local
  standoff, or mount the Pi/bonnet just **below** the row.
- **Level/flatness** of the rail over 512 cm — shim the tongue as needed.
- Panels shouldn't **sag/bow** across 5 m → the hanging rail must be rigid.

## Still to confirm on-site

1. **Depth behind the lip** for the Pi + bonnet stack (measure the stack; 3.4 cm
   may be tight).
2. **Panel weight** (confirm ~0.5 kg each) → total hung load.
3. Pocket is **uniform/continuous** across the full 512 cm.
4. Wall material behind (drywall/studs) for the **bottom restraint** fixing.
5. Exact **ceiling-to-floor** context (how far below the ceiling we want the row;
   the pocket puts the top ~22.5 cm down — is that the desired height?).

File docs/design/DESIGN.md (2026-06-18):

# VESTOR — Visual Design Document
### A 201-inch departure board for the sky over Cambridge

> Aesthetic codename: **"Departure Board Noir"** — sodium-amber phosphor on
> aviation-control black, the visual language of Solari split-flap boards,
> airport radar scopes, and 1970s flight-information displays, rebuilt pixel by
> pixel on real HUB75 LED hardware.

This document is the single source of truth for *what the wall shows and how it
looks*. The hardware/build truth lives in `docs/HARDWARE.md`, `docs/RUNBOOK.md`
and `AGENTS.md`; the API specifics live in `docs/design/API_REFERENCE.md`; the
projects/patterns survey lives in `docs/design/RESEARCH.md`.

A faithful, interactive **simulator** of everything described here lives in
[`/sim`](../../sim/) — open `sim/index.html` (or run the bundled static server)
to see both displays render exactly as the phosphor will glow.

---

## 1. The two displays

Vestor is **one panel geometry** driven in two configurations:

| | **Phase 0 — Single panel** | **Phase 1 — The Wall** |
|---|---|---|
| Pixels | **64 × 32** | **1024 × 32** |
| Panels | 1 | 16 (side by side) |
| Physical | 320 × 160 mm | **5120 mm = 201.6 in** wide |
| Wiring | data → Port 1 | 3 chains (6+5+5) on the Triple Bonnet |
| Content | **flights only** | full city dashboard |
| Purpose | hardware bring-up / tuning ladder | the finished installation |

The wall is deliberately an **ultra-wide 32:1 ribbon**, not a square. That aspect
ratio *is* the concept: it reads like the airport solari board / transit ticker
it's emulating, and it turns the awkward "16 panels of 64×32" into a single
narrative strip that the eye scans left-to-right.

### Electrical vs. logical geometry
hzeller's driver requires a uniform `chain_length`, so 3 chains of 6 give a
**384 × 96** physical canvas (3 rows of 6 panels). A **pixel-mapper** folds those
three stacked physical rows into the single **1024 × 32** logical ribbon the
scenes draw onto. The 6+5+5 split (16 panels, not 18) means the mapper leaves the
last two cells of chains 2 and 3 unpopulated — a Phase-1 engineering task tracked
in `docs/OPEN_QUESTIONS.md`. The simulator and all scene code already target the
final 1024×32 logical surface.

---

## 2. Aesthetic direction

A bold, committed point of view — not a generic dashboard.

### Palette (`PAL` in `sim/led.js`)
Authored in 0–255, stored as **linear light** so additive glow is physical.

| Token | Hex | Role |
|---|---|---|
| `amber` | `#FFB000` | **primary** — clocks, callsigns, headers (sodium-vapor) |
| `green` | `#39FF14` | phosphor — altitudes, "good", on-time |
| `cyan` | `#00E5FF` | data/labels, radar, routes, transit |
| `magenta`| `#FF2D95` | e-bikes, accents, alerts |
| `warm` | `#FFD678` | speeds, sun, secondary amber |
| `red` | `#FF3C32` | descending, delays, low-stock, LIVE dot |
| `blue` | `#5A96FF` | night, tide, cold |
| `purple` | `#AA78FF` | aircraft type chips, extras |
| `white` | `#EBF0FF` | emphasis only (used sparingly) |
| `ink` | `#08080C` | near-black substrate |

Dominant amber + sharp phosphor accents on black. Never a flat even palette;
never the AI-slop purple-on-white gradient.

### Typography
The simulator's *chrome* (the web page around the canvases) uses:
- **Major Mono Display** — the `vestor` wordmark (lowercase, mechanical)
- **Saira Condensed** — display headers (tall, transit-signage)
- **IBM Plex Mono** — all body/data text
- **Silkscreen** — pixel-perfect captions and labels

The *LED content itself* uses two **authored bitmap fonts** baked into
`led.js` — there are no system fonts on the matrix:
- **5×7** — the workhorse (uppercase, digits, punctuation, arrows, `°`, symbols)
- **3×5** — captions/labels where 5×7 is too tall (the ribbon is only 32px)

Both render at integer `scale` (1×, 2× …) so glyphs stay crisp on real pixels.

### Motion language
Motion is *diegetic* — it imitates real electromechanical/radar hardware:
- **Split-flap (Solari) flips** — `SplitFlap` advances each character cell
  mechanically through a charset toward its target, drawing a flap-seam line
  mid-glyph while turning. Used for callsigns and routes.
- **Radar sweep** — a rotating beam with a trailing afterglow; contacts brighten
  as the beam passes, then decay (pure additive deposition + the renderer's
  bloom = a real phosphor trail).
- **Seconds bar / sweeping fills** — smooth sub-pixel progress bars.
- **Marquee** — reserved for the low-priority ticker mode only (scrolling is
  costly to read; the dashboard prefers static zones + flips).
- **Pulses** — gentle sine-driven brightness on live/alert indicators.

---

## 3. The faithful LED optical model

The simulator is not "draw squares." `LEDRenderer` (in `sim/led.js`) reproduces
how a HUB75 panel actually emits, so the design is judged under real conditions:

1. **Linear framebuffer** — `Float32Array` of `cols×rows×3`, additive-capable.
2. **Brightness → gamma 2.2 LUT** → 8-bit per channel into a `cols×rows` texel
   buffer (one texel per LED).
3. **Nearest-neighbor upscale** to the display canvas → hard square pixels.
4. **Round-emitter mask** — a tiled radial-dot pattern composited `destination-in`
   carves every square into a round die with a dark inter-pixel gap, in **one**
   GPU pass for the whole 1024px ribbon (not 32k per-pixel draws).
5. **Additive bloom** — the dot image is downsampled, blurred and re-added
   `lighter` in two passes for the diffuser glow.
6. **Overlay** — faint horizontal scanlines, **64-px panel seams**, vignette.

Knobs: `pitch` (screen px/LED), `dot` (emitter diameter), `bloom`, `scan`,
`seam`, `vignette`, `brightness`. The wall renders at `pitch:5` (pannable like a
ticker); the single panel at `pitch:14` (chunky and tactile).

---

## 4. Wall zone map (1024 px)

All zone boundaries land on **64-px panel seams** so no element straddles a gap.

```
 px:  0      128     256                 576     704     832     960  1024
      |CLOCK |WEATHER|  FLIGHTS · RADAR  |BIKES  |SHUTTLS|EXTRAS |STAT|
      | DATE | °C/°F |  (hero, 5 panels) |       |MIT·BU |rotate |cap |
      |2 pnl |2 pnl  |                   |2 pnl  |2 pnl  |2 pnl  |1pnl|
```

| Zone | px | Source | Content |
|---|---|---|---|
| **Clock·Date** | 0–127 | system | Big `HH:MM` (2× flap-free), day, month/date, AM/PM, sweeping seconds bar |
| **Weather** | 128–255 | Open-Meteo | Condition icon + text, **°C and °F both**, hi/lo, humidity, wind vector, feels-like (both units) |
| **Flights** *(hero)* | 256–575 | ADS-B | **Carrier-led:** real full-colour airline logo, `ORIG CITY → DEST CITY` journey, type + ARRIVING/DEPARTING, FL/speed/vertical-rate, radar disc, carrier-tinted altitude gauge |
| **Bluebikes** | 576–703 | GBFS | Pacific St: **classic vs e-bike** counts (bike/bolt icons), free-dock bar |
| **Shuttles** | 704–831 | Passio + TransLoc | 4-line transit board: **Tech** / **Tech NW** / **SafeRide** (MIT) + **BU Hyatt**→GSU; "DUE" flash ≤1 min |
| **Extras** | 832–959 | mixed | Rotates every 6 s: ISS pass · MBTA Red Line · AQI · Moon phase · Charles tide |
| **Status** | 960–1023 | system | LIVE heartbeat, vertical `VESTOR` wordmark, data-freshness sparkline |

### Three wall modes
- **DASHBOARD** (default) — the zoned layout above; all domains at a glance.
- **FLIGHT TAKEOVER** — the whole 1024-px ribbon becomes **one cinematic boarding
  pass**, read left→right as three panels: **IDENTITY** (big real full-colour
  airline logo + callsign·type·reg), **JOURNEY** (split-flap origin/dest
  IATA codes with the full city names flipping beneath, and a carrier-coloured plane
  crossing the route line with a jet-wash trail), and **STATUS** (2×-scale `FL###`
  over `###KT`, a vertical altitude gauge, vertical-speed, an "IN RANGE" mini-board
  of nearby traffic, and a radar scope in the far corner).
- **MARQUEE** — a static LIVE/VESTOR end-block + one 2×-scale scrolling ticker
  combining every domain; for glanceable, low-attention moments.

---

## 5. Scene specifications

Each scene is a stateful class in `sim/scenes.js` with
`draw(matrix, x, y, w, h, data, t, dt)`. The Python app mirrors these as scenes
under `scenes/` driven by the same data shapes.

### 5.1 Flight (hero) — `FlightScene`
The showpiece — **carrier-led**, the way a real gate board identifies a flight by
the *real logo* before you read any text. Every layout opens with the carrier's
**genuine full-colour logo** (see §5.1a), then the human journey (cities, not just
codes), then telemetry. Two layouts auto-select by zone width:
- **Compact (64px / Phase 0):** real logo fit across the panel top, `ORIG → DEST`
  codes, bottom-left mini-radar, bottom-right stacked `FL###` /
  `###KT` / climb-descent. Exactly what the single-panel bring-up should show.
- **Wide (320px / wall):** left radar disc + "N TRK"; real carrier logo +
  callsign; `ORIG CITY → DEST CITY` journey; `TYPE ARRIVING/DEPARTING`
  + distance; `FL### · ###KT · ↑climb`; and a bottom **altitude gauge tinted to
  the carrier colour**.

**Full-wall TAKEOVER** (`drawTakeover` in `app.js`) is the same vocabulary blown
across all 1024 px as a three-panel boarding pass — see *Three wall modes* above.
The origin/dest IATA codes and full city names are **split-flaps** that physically
clack over each time the hero rotates; the plane's position along the route line
is derived from `distance` + the `_arriving` flag (arriving flights converge on
the destination dot, departing ones pull away from the origin).

Hero selection: nearest contact, weighted toward closer/arriving/international,
rotating every ~8 s. Radar contacts are mapped from each flight's bearing
(`track`) and range (`distance`).

### 5.1a Airline branding — `airlines.js` (REAL full-colour logos)
Real gate boards — and the reference product (theflightwall.com) — read as a
carrier *instantly* from the genuine logo, in full colour, at panel height. We
render the **real logo**, not a stylised mark.

**Source.** `pics.avs.io` (the TravelPayouts / Aviasales CDN) serves free,
CORS-enabled, transparent-background PNG wordmark logos keyed by **IATA** code at
any requested size. `tools/fetch_logos.py` downloads each carrier, crops to the
opaque bounding box, scales to a fixed **64-px tall** master, and writes
`sim/logos/<IATA>.png` plus a `manifest.json`. The wall is then fully **offline**
(no per-frame network, no CORS taint, no rate limits) — 64 carriers, ~1 MB.

**Flow.** ADS-B callsign → ICAO operator (first 3 chars, `DAL1387 → DAL`) →
**IATA** via the `ICAO_TO_IATA` table → logo PNG. At draw time the master is
downscaled into an offscreen canvas at the exact LED target height, read back with
`getImageData`, and alpha-composited over the black substrate straight into the
framebuffer (`m.set(x,y,[r,g,b],a)` — `set` premultiplies, so this *is* alpha-over-
black). The downscaled read-back is cached per `iata@height`, so the 60 fps
takeover only rasterises each carrier once.

**Colour.** `AIRLINE_DB` still carries hand-tuned **LED-boosted livery colours**
for the ~30 carriers we see most at KBOS (used to tint the route line, plane icon,
and altitude gauge); every other carrier gets an accent **sampled from its own
logo pixels** (weighted toward saturated/bright pixels, then normalised to glow).

**Fallback.** A carrier with no logo file (rare regionals/cargo) or an unknown
operator draws its **brand wordmark in the brand colour** — never a muddy mark.

API: `airlineFor(callsign)` → `{code, iata, name, color, accent}`;
`drawLogoH(m, iata, x, y, h, align)` → width; `fitLogoBox(m, iata, x, y, maxW,
maxH, align, valign)` → `[w, h]`; `logoReady(iata)`, `logoAspect(iata)`.
Re-fetch/refresh logos with `python3 tools/fetch_logos.py`.

### 5.2 Weather — `WeatherScene`  *(°C **and** °F — hard requirement)*
Condition icon (sun/moon/cloud/rain/snow by WMO code, day/night aware) + text;
large **`##°C`** (amber) stacked over **`##°F`** (green); right column hi / lo /
humidity / wind speed; an animated **wind-direction arrow**; a `FEEL ##°/##°`
ribbon (both units). °F is derived as `C×9/5+32` at render time.

### 5.3 Bluebikes — `BluebikesScene`
Header + "PACIFIC ST"; a **classic** row (bike icon, white, count) and an
**e-bike** row (lightning-bolt icon, magenta, count) — the two are always shown
separately per the brief; a bottom **free-dock bar** + count. Low-availability
(≤2 bikes) pulses the count red.

### 5.4 Shuttles — `ShuttleScene`
A multi-agency **departures board**. Bus icon + "SHUTTLES" header (with a green
live-feed dot when real data is flowing), then four right-aligned ETA rows at a
6-px pitch, each colour-coded:
- **TECH** (green) and **NW** (cyan) — MIT Tech lines at Grad Junction
- **SAFE** (purple) — MIT SafeRide at W98 @ Vassar (evening service)
- **BU** (scarlet) — BU "Hyatt" shuttle → GSU, boarding beside the wall

Each row shows the **lead** arrival bright + right-aligned with the **next-up**
dim to its left; **"DUE"** flashes when ≤1 min; **"—"** when the line is idle
(Tech overnight, SafeRide by day, BU outside service hours). BU is genuinely
live in-browser (CORS-OK TransLoc JSON); the MIT lines are synthetic in the sim
and live on the Pi.

### 5.5 Clock·Date — `ClockScene`
2×-scale `HH:MM` (amber), sub-minute **seconds bar**, day-of-week (cyan),
month+date (white), AM/PM (green).

### 5.6 Extras — `ExtrasScene` (rotating, 5 cards)
ISS overhead/"LOOK UP!" with an orbiting dot · MBTA Red Line @ Kendall/MIT
(Alewife/Ashmont ETAs, red bullet) · Air Quality (color-graded value + bar) ·
Moon phase (lit-fraction disc) · Charles tide (rising/falling + animated wave).
Rotation dots indicate position; cards cross-fade.

### 5.7 Status end-cap — `StatusEndcap`
Pulsing LIVE dot, vertical `VESTOR` wordmark, an 8-bar data-freshness sparkline.

---

## 6. Data model & live data

`sim/data.js` (`DataModel`) holds state shaped **exactly** like the real API
responses and animates it believably (flights advance along track, ETAs count
down and recycle, bikes check in/out, weather drifts). Two modes:

- **SIM** (default) — fully synthetic, offline, deterministic-ish; ideal for the
  showcase and for design review.
- **LIVE** — opportunistically overlays **real** data from the CORS-friendly
  public endpoints (**Open-Meteo** weather, **Bluebikes GBFS**) and falls back to
  SIM on any failure, so the wall never goes dark. *(Verified live: Open-Meteo
  and GBFS both return 200 with CORS from the browser.)*

On the Pi, the Python clients fetch the same shapes from the same endpoints plus
the ones that need a server (Passio GTFS-realtime protobuf, ADS-B). See
`docs/design/API_REFERENCE.md` and `tools/` clients.

---

## 7. Design principles (the rules)

1. **Zone to the seam.** Every element fits inside a 64-px panel; nothing
   straddles a physical gap.
2. **Anchors + rotation.** Persistent zones for always-needed info (time,
   weather, flights); rotation only inside the Extras zone.
3. **Brightness is the budget.** Worst-case all-white ≈107% of the 120A supply,
   so `BRIGHTNESS≤50` caps it (~64A). The design leans on a *dark* substrate with
   sparse bright glyphs — which is also the noir aesthetic. Win-win.
4. **Color carries meaning.** Amber=identity/time, green=good/altitude,
   red=caution/descending, cyan=transit/data, magenta=e-bike.
5. **Motion must mean something.** Flips on data change, sweep for the radar,
   pulse for live/alert. No decoration-only animation on the matrix.
6. **Legibility first.** 5×7 for primary, 3×5 only where height forces it; never
   smaller. Right-align numerics; left-align labels.

---

## 8. Running the simulator

```bash
# from the repo root
cd sim && python3 -m http.server 8765
# open http://localhost:8765
```
Controls: **scene mode** (dashboard/takeover/marquee), **data source**
(simulated/live), **brightness**, **view** (1:1 pan / fit-width), **auto-pan**.
The page also renders the **64×32 Phase-0 panel** live and lists every data
source. No build step, no dependencies — classic `<script>` tags, runs from
`file://`.

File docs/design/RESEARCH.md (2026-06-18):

# VESTOR — Research Findings
### Cool projects, design patterns, and what works on a 32-px-tall LED ribbon

Background research that shaped the design in `DESIGN.md`. Compiled 2026-06-15.

---

## 1. Projects surveyed (HUB75 / RGB-matrix dashboards)

What the hobbyist + maker community has built on exactly this hardware
(rpi-rgb-led-matrix + HUB75 panels), and the one idea worth stealing from each:

| Project / pattern | Steal-worthy idea |
|---|---|
| **its-a-plane-python** (our upstream, ColinWaddell) | Per-scene keyframe animation; FlightRadar24 nearest-plane focus; clean clock/date/weather rotation on a 64×32. Our flight scene extends its "one hero plane" idea with a **radar** + **split-flap**. |
| **TheFlightWall** (AxisNimble OSS + theflightwall.com) | The *cleanest* flight card we found: one flight, **framed**, three centered lines — **airline name in the brand colour + logo**, `From: <City>`, aircraft type. The wow is *legibility + branding*, not density. Drove our **carrier-led** rewrite: lead with the **real full-colour airline logo** (sourced from `pics.avs.io`) and show **city names** before codes. (OSS note "airline logo lookup added soon" — not in their OSS yet, and their product logos live in proprietary firmware; we found a free CORS-enabled CDN and built it.) |
| **Flightradar / "planes overhead" matrix builds** | A live **radar/compass sweep** with the home location at center reads instantly as "aircraft." We made it the flight zone's left anchor. |
| **MTA/transit countdown clocks & subway-sign clones** | Right-aligned **minutes-to-arrival** rows with a route **bullet**; the real signage flips between "now/2 min/4 min." Drives our shuttle + MBTA rows and the **split-flap** motion. |
| **Solari / split-flap board recreations** | The flip *is* the brand. Even a faked flip (cycling glyphs to target) sells "departure board." Implemented as `SplitFlap`. |
| **Weather-station matrix dashboards** | Icon + big number + a couple of micro-stats is the legible maximum on 32px; animated **wind arrow** and day/night icon swap add life cheaply. |
| **GBFS bike-share displays** | Show **availability split** (classic vs e-bike vs docks) as the headline number, not a map; a dock-fill bar communicates "can I return here." |
| **"Departures board for your city" art installs (ultra-wide)** | Ultra-wide ribbons want **zoned, anchored** content scanned L→R, with a single scrolling ticker reserved for overflow — not everything scrolling. |
| **ISS / satellite trackers** | A simple "overhead in N min / LOOK UP" beat is delightful and needs only one endpoint. |
| **Matrix "now playing" / sparkline status bars** | A thin **sparkline / heartbeat** end-cap signals "this thing is alive and fresh" — became the status zone. |

**Net takeaway:** the most-loved builds are *legible, anchored, and
motion-with-meaning*. The wow factor on a 201" ribbon comes from **one
unbroken narrative strip** + **diegetic motion** (flips, sweep), not from
cramming effects.

### Airline logos on a 32-px LED wall (resolved approach — REAL logos)

The reference product (theflightwall.com) shows **crisp, full-colour, real**
airline logos at panel height — not stylised marks. We chased the same look and
**found the source**, after an initial wrong turn into procedural marks (which
looked muddy and were rightly rejected).

- **Where the crisp logos come from → `pics.avs.io`.** The TravelPayouts /
  Aviasales CDN serves free, **CORS-enabled**, transparent-background PNG wordmark
  logos keyed by **IATA** code at any requested size
  (`https://pics.avs.io/<w>/<h>/<IATA>.png`). It returns the horizontal wordmark
  fitted to the requested width on a transparent canvas — ideal for a 1024-px-wide
  ribbon. (AirHex 403s without a paid key/hash; TheFlightWall's own
  `cdn.theflightwall.com` only serves *display names*, not logos — their product
  logos ship inside proprietary firmware.)
- **Real logos survive the optics — they don't become mush.** Downscaled with
  LANCZOS to LED-native height (≈20–26 px) and pushed through gamma 2.2 + round
  emitters + additive bloom, vector-derived wordmarks stay sharp and instantly
  legible: Southwest's gradient heart, United's globe, Delta's widget, the BA
  speedwing all read perfectly. (The thing that *did* turn to mush was hand-rolled
  procedural geometry — the opposite of what we first assumed.)
- **Transparent alpha keys cleanly against black.** Corners are `(0,0,0,0)`, so
  rendering is a straight alpha-over-black composite — no white-box matte to strip.
- **Decision → fetch once, render local.** `tools/fetch_logos.py` downloads ~64
  carriers, crops to content, stores 64-px masters in `sim/logos/`, and writes a
  manifest. The wall runs **fully offline** (no per-frame network, no taint, same
  pipeline usable on the Pi via Pillow). Mapped **ICAO→IATA** so the ADS-B feed
  resolves to a logo; brand colour still tints accents (hand-tuned for majors,
  sampled from the logo otherwise); no-logo carriers fall back to a brand
  wordmark. See `DESIGN.md` §5.1a.

---

## 2. Designing for a 32-pixel-tall surface

Hard constraints that drove concrete choices:

- **Vertical budget is brutal.** 32 px = at most **4 rows** of 5×7 text (with
  1px gaps) or **5 rows** of 3×5. Every scene is laid out on that grid:
  5×7 for primary values, 3×5 only where height forces it.
- **Zone to 64-px seams.** Real panels have a visible dark seam every 64 px.
  Straddling one cuts a glyph in half. All zone widths are multiples of 64 and
  all boundaries fall on seams.
- **Horizontal is the luxury dimension.** 1024 px wide is huge — use it for
  *whole words* (city names, "DEPARTING"), route arcs, and a real departures
  board, rather than squeezing vertically.
- **Right-align numbers, left-align labels.** Standard transit-board legibility;
  lets the eye lock onto the changing digits.
- **Dark substrate, sparse bright glyphs.** Both an aesthetic choice (noir) and
  a power choice (see §3).

---

## 3. Power & brightness reality (informs the visual budget)

From the hardware research (`docs/HARDWARE.md`):
- 16 panels at full white ≈ **107%** of the 2× LRS-350-5 (120 A) budget.
- `BRIGHTNESS = 50` caps worst case at ~64 A; typical dark-substrate content
  draws ~27–53%.
- **Design consequence:** a mostly-black board with bright accents isn't just the
  look — it's what keeps the install within its power envelope. The aesthetic and
  the electrical constraint point the same way.

---

## 4. Color semantics adopted

A consistent legend so the wall is readable at a glance from across a room:

- **Amber** — identity & time (wordmark, clock, callsigns, headers)
- **Green** — good / altitude / on-time / climbing
- **Red** — caution / delay / descending / low stock / LIVE
- **Cyan** — transit, data labels, radar, routes
- **Magenta** — e-bikes & special accents
- **Purple** — aircraft type / extras
- **Blue** — night, cold, tide
- **White** — emphasis only, used sparingly

---

## 5. Motion patterns adopted

| Pattern | Where | Why |
|---|---|---|
| Split-flap flip | callsign, route, big numbers | "departure board" signature; signals a data change |
| Radar sweep + decaying contacts | flight zone | instantly legible as aircraft; phosphor trail via additive bloom |
| Sweeping progress bar | seconds, dock-fill, gauges | smooth sub-pixel life without distraction |
| Pulse | LIVE dot, low-availability, "DUE" | draws the eye to the one urgent thing |
| Cross-fade | extras rotation | clean transitions between rotating cards |
| Marquee scroll | ticker mode only | reserved; scrolling is high-effort to read |

---

## 6. Open creative ideas (future scenes, not yet built)

Parked here so they aren't lost — candidates for the Extras rotation or future
modes:
- **Charles River sculling/regatta** activity or river temp.
- **MIT campus events / Stata "now open"** style status.
- **Sunrise/sunset golden-hour countdown** with a horizon gradient.
- **"On this day in aviation"** micro-trivia between flight foci.
- **Aurora / space-weather (Kp index)** alert when visible at this latitude.
- **A daily "wall woke up" boot animation** — staggered panel-by-panel power-on
  sweep across all 16 panels (great first-light moment for the install).
- **Sound-reactive** spectrum strip if a mic is ever added.

All of these fit the existing scene/zone framework and data-overlay model.

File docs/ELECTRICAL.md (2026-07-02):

# VESTOR — ELECTRICAL / POWER WIRING (validated)

The wiring plan for the 16-panel wall, verified by two cited research passes (power
distribution + fusing; LRS-350-5 datasheet + placement + grounding). Diagram source of
truth: the labeled wiring diagram in the design session. Companion: `INVENTORY.md` §9
(BOM), `HARDWARE.md`. **Safety-critical — read before wiring.**

## Architecture (one line)
**Split the two PSUs (one per 8-panel half) → each feeds 2 fuse blocks in a STAR with
10 AWG copper → every panel gets its own 5 A fuse → bond both PSU negatives + the Pi
ground at one point, keep the positives isolated → trim each PSU to ~5.15 V.**
Data is independent: a single HUB75 chain of 16 from the corner.

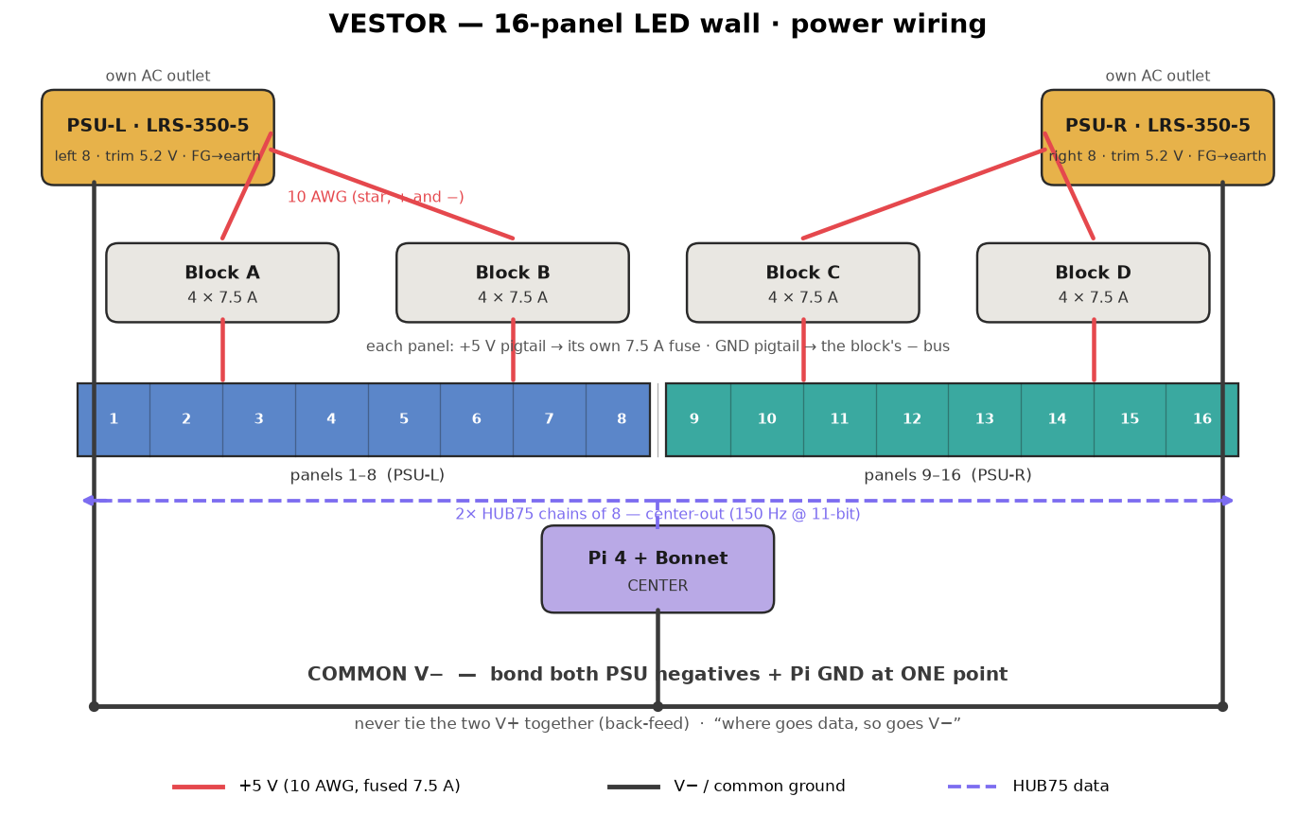
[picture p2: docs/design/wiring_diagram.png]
wiring diagram


## The decisions, with the numbers

### 1. Fuses — YES (per panel, 16 total). Value depends on the pigtail gauge.
- The LRS-350-5's own protection (OCP at **110–140 % → ~66–84 A**, hiccup auto-recover;
  **no 150 % peak on the 5 V model**) protects the *supply*, not your wiring. A soft short
  (pinched/chafed pigtail, backed-out terminal) draws **10–25 A** through a ~4 A pigtail and
  the 60 A PSU **never trips** → the wire becomes a cartridge heater. **The fuse protects the
  WIRE.** Genuine fire-safety item for a 24/7 wall.
- **The load:** each pigtail carries only its OWN panel (power is injected per-panel, not
  chained). A 64×32 P5 draws **~3.5–4 A at full white / 100 % brightness** (1/16 scan → 384
  sub-LEDs lit at once × ~10 mA; ~2.4 A measured on comparable panels), and only **~1–2 A at
  brightness ≤50**. So the fuse must sit **just above ~4 A** and **below the pigtail's ampacity**.
- **Value = 7.5 A (the fuses on hand).** The pigtail is marked **"RV … 450/750 V"** — RV is the
  Chinese spec for **solid-copper-core** flexible PVC wire, and it's already sized to carry the
  panel's own ~4 A, so it's ≥0.5 mm² copper (~7–10 A ampacity). **7.5 A > the 4 A load and ≤ the
  wire's ampacity → it protects the wire.** (5 A only if the pigtail turns out to be a thin
  0.3 mm² — glance at the mm² printed on it to be 100 % sure; ≥0.5 mm² → 7.5 A.)
- **Per-panel, not per-group.** A group fuse must be ≥16 A (4 panels) so it never blows for
  one panel's thin-pigtail short. 24 slots / 4 blocks → **16 fuses, one per panel**, 8 spare.

### 2. Trunks — **10 AWG copper**, star topology
Budget <3 % of 5 V (<0.15 V). Per-branch (4 panels ≈ 16 A) over ~2 m round-trip:

| Gauge | drop @16 A/2 m | % | verdict |
|---|---|---|---|
| **10 AWG** | 0.10 V | 2.1 % | ✅ use this |
| 12 AWG | 0.17 V | 3.3 % | marginal |
| 14 AWG | 0.27 V | 5.3 % | ✗ |

- **Star:** each fuse block gets its own 10 AWG feed straight off the PSU terminals (not
  daisy-chained). 2 branches × 4 panels per half → 4 trunks total.
- **Owner's trunk = 10 AWG CCA** (copper-clad aluminum, 25 ft spool). CCA carries like ~12 AWG
  copper, so drop is a bit higher — **acceptable here** given split PSUs, short runs, ~5.2 V trim,
  and the dark brightness-≤50 content (real ~4–8 A/trunk → <0.15 V; only a pathological all-white
  16-panel frame would droop, which this board never shows). Keep each block **close to its PSU**.
- Your **yellow 10–12 AWG ring terminals** land the trunk on the PSU/block studs (ring > fork on
  the high-current lugs; ≤2 wires per screw, ~8 kgf-cm). CCA → crimp + anti-oxidant + re-torque.

### 3. Placement — **SPLIT** (one PSU per half), each on its own AC outlet
- Split makes every panel ≤2.5 m from its PSU (vs ≤5 m). At 10 AWG, split holds ≥4.48 V even
  at a full-white 32 A worst case; **both-at-left on 10 AWG collapses to ~3.95 V (broken)** and
  would need 8 AWG + trim to barely reach ~4.3 V. Split = less copper, better voltage.
- **Separate AC outlets / circuits.** Steady draw is tiny (~1–2 A AC each at real load), but
  **cold-start inrush is ~60 A per unit** (2025 datasheet; older rev said 45 A — check your
  label). Two at once ≈ 120 A can pop a cheap switch → give each its own switched outlet, or
  stagger power-on. Left PSU + Pi in the corner, right PSU at the far end — outlets fall out
  naturally. Fan is thermostatic (on ≥50 °C) → usually silent at your <15 % load; keep 10–15 cm
  vent clearance. **Tie each PSU's FG to mains earth** (separate from the DC ground below).

### 4. Grounding — bond V−, isolate V+
- **Bond both PSU negatives (V−) together AND to the Pi/Bonnet GND at ONE star point.** HUB75
  data is ground-referenced across all 16 panels — "where goes data, so goes V−." A missing/
  divergent V− return gives flicker and "interesting random lighting."
- **NEVER connect the two V+ together.** Two 5 V supplies are never exactly equal → tying V+
  back-feeds circulating current into the lower unit (unequal load, OVP/hiccup trips). Each PSU
  owns only its half's V+.

### 5. CCA pigtail handling (the #2 ignition source after an unfused short)
- **Crimp, never solder** CCA (flux eats the cladding → cold joint). **Don't tin** the fork ends
  (solder creep loosens screw terminals). **Anti-oxidant paste** (Noalox-type) on the aluminum,
  and **re-torque the terminals after a few days** of thermal cycling. Keep pigtails as short as
  they ship (~55 cm); land them into crimped copper trunk — don't extend the CCA.

### 6. AC input + Pi/Bonnet power (the low-current side)
- **AC mains:** each LRS-350-5 has bare **L / N / ⏚ screw terminals** → each needs an **AC cord**
  (2 total; C13/hardwired to a plug). Set the **115 V** input switch. Each PSU on its **own outlet**
  (inrush). Land **⏚ (earth) → the PSU FG terminal**.
- **Pi power:** a USB-C charger (owner uses a 96 W MacBook charger — fine; the Pi pulls only the
  ~5 V/1.5 A it needs). Independent of the panel rail → no brownout.
- **Bonnet power: NONE separately.** The level-shifters run off the Pi's 5 V through the GPIO header,
  so the USB-C charger already powers them. **Leave the Bonnet's 5 V terminal EMPTY** — wiring a PSU
  there too would parallel two 5 V sources (back-feed).
- **Ground bond (critical, esp. with an isolated USB-C charger):** wire the **Bonnet's GND terminal →
  PSU-L V−**, plus a **~16 AWG V− bond between the two PSUs**. This is the ONLY solid ground reference
  tying the Pi/data to the panel supplies — the thin HUB75 ribbon ground isn't enough across 16 panels.
  Missing it → flicker/garbage. ("Where goes data, so goes V−.")

## Are the pigtails long enough? Yes — because the blocks are distributed
~55 cm reaches ±1.7 panels, so **one fuse block per 4-panel group** (blocks A/B/C/D at panels
1–4, 5–8, 9–12, 13–16) puts every panel within reach of its block. Distributing the 4 blocks is
what makes the pigtails sufficient *and* keeps the 10 AWG runs short. (Putting all blocks in the
corner would strand the far pigtails 5 m away.)

## Shopping delta — the electrical side needs NOTHING
- **All on hand:** 2× LRS-350-5, 2 AC cords, 4× 6-way fuse blocks (built-in +/− bus), 7.5 A fuses,
  10 AWG CCA trunk, copper RV pigtails, yellow rings, 100 cable ties + mounts, Pi 4 + Triple Bonnet,
  a 96 W USB-C charger for the Pi, 16 panels + ribbons (ribbons reach panel-to-panel).
- **CCA trunk (reliability pass corrected the earlier "skip the paste"):** for a permanent wall,
  either **treat every CCA joint** — Noalox anti-oxidant + AL/CU-rated crimp lugs + **re-torque at
  ~30 days then annually** — **or swap the ~7 m trunk to copper**. Ampacity is fine for the 16 A
  branches; the risk is termination oxidation/creep over years. See **`../HARDENING.md`**.
- **Not needed:** 5 A fuses (7.5 A work), a negative bus bar (block has one).
- **Add per the hardening pass:** bootlace ferrules + crimp (not solder-only), Belleville/Nord-Lock
  washers on the M3.5 PSU studs, latching JST-VH plugs, bulk decoupling caps at the center feeds,
  clip-on ferrites, and **wired Ethernet (disable WiFi)** — full list in `../HARDENING.md`.
- **PSU placement LOCKED = split:** PSU-L at the corner, PSU-R at the right end (its own AC outlet, confirmed).
- (Only ~16 AWG for the V− bond + Bonnet-GND wire — reuse trunk offcut.)

## Confirmed on the owner's parts (2026-07-02, from photos)
- **Fuse blocks (×4): 6-way, enclosed, blown-fuse LEDs, with BOTH a fused +bus and a −ground bus.**
  Terminal map: **bottom center stud = + IN** (PSU +5 V trunk), **top center stud = − IN** (PSU ground),
  **6 side screws = fused + OUT** (one per panel), **6 top-bar screws = − ground OUT** (one per panel).
  → no separate negative bus bar needed; each block = a complete +fused/−bus unit for ≤4 panels.
- **Trunk cable = 10 AWG CCA** (TYUMEN, 25 ft) → acceptable (see §2).
- **Pigtail = "RV … 450/750 V" = solid-copper flexible wire** → **7.5 A fuses on hand are the right value.**
- **100 cable ties + adhesive mounts** → dress the HUB75 ribbons + power leads along the rails so nothing
  sags or **chafes** (chafing is the fault the fuses guard against — tidy routing is itself a safety measure).

## Only thing left to eyeball
- The **mm² printed on the pigtail** (≥0.5 mm² → 7.5 A good; a rare 0.3 mm² → drop to 5 A). Optionally
  clamp-meter one panel at full white to log the real per-panel max (~2.4–4 A expected).

## Sources
Mean Well LRS-350 datasheet + Enclosed-Type install manual; hzeller rpi-rgb-led-matrix `wiring.md`
(4.5 V floor, ≤50 mV target, star, common ground); AusChristmasLighting (fuse-the-wire, 5 A pixel
wire, "where goes data, so goes V−", power injection); electricaltechnology.org AWG tables; VoltPlan
fuse sizing; Romtronic/MWS/IAEI on CCA ampacity. (Full URLs in the research transcripts.)

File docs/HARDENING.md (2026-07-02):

# VESTOR — RELIABILITY HARDENING (permanent 24/7 wall)

Synthesis of six cited research passes (strain relief · IDC ribbons · grounding/
decoupling · 24/7 failure modes · power terminals · EMI/RFI) into one prioritized,
buildable checklist. This is what makes a 16-panel HUB75 wall still work in 5–10 years.
Companion: `ELECTRICAL.md`, `design/BACK_OF_HOUSE.md`, `design/MOUNT_PARTS.md`.

## What actually fails first (years-scale, 24/7) — plan around this
1. **PSU cooling fan** — the only moving part, in a warm dusty gap. *But you load each
   LRS-350-5 to ~13 % (≤50 brightness), far under the 50–60 % derate knee → the fan
   essentially never spins.* Keep it that way + stock a spare 80 mm fan.
2. **PSU electrolytic caps** — wear-out item; life halves per +10 °C. Run cool + light (both true).
3. **Panel driver/shift-register ICs** — cause whole-row/half-panel/stuck-color death; not
   repairable → **swap the panel** → keep same-batch spares.
4. **Solder joints + IDC ribbon/connectors** — "a loose ribbon is the #1 cause of a dark section."
5. **Individual LEDs / lumen droop** — slowest mode; the ≤50 cap makes this a non-issue for years.
   → **The ≤50 brightness cap is your single best free move** (Arrhenius: cuts LED-junction,
   driver-IC, PSU, and cap stress all at once). Keep it; drop lower at night.

## DESIGN-IN-NOW (impossible/painful to retrofit behind a mounted wall)

### Connectors & cabling — the dominant long-term risk
- **Retain every one of the ~17 HUB75 connectors** — a zip-tie/clip/side-bead of hot glue
  capturing the *housing* (not the mating faces, so it stays serviceable). No latch + tin
  contacts + daily thermal cycling → fretting corrosion → flicker over years; gravity walks
  them off a vertical wall.
- **First anchor point 50–100 mm from every connector** (screw-down `cable_clip`, Part 8 —
  **NOT adhesive**, which peels in a warm gap and drops the load onto the connector).
- **Cut every cable with a 25–75 mm service loop** at each end — for service *and* to absorb
  daily thermal expansion. You cannot add slack to an exact-cut cable. (The ~15 % slack in the
  10 AWG cut list stays.)
- **Support each vertical drop's weight at the top** so no pigtail/ribbon header ever bears cable weight.
- **Ribbons: keep short, turn corners with a rolled U-fold (never crease — ~40 % of cable
  failures are bend-radius), engage the IDC strain clip, don't zip-tie tight across the flat.**
- **Bootlace ferrules** on every stranded wire into a screw terminal; **crimp, never solder-only**
  (ABYC — solder melts at a hot joint + fatigue-cracks).
- **Latching JST-VH panel plugs** + strain relief on each pigtail.

### Electrical
- **CCA trunk decision (corrects "skip the paste"):** for a permanent wall, either **(a)** treat
  every CCA joint — **Noalox anti-oxidant + AL/CU-rated crimp lugs + the re-torque schedule** —
  **or (b)** swap the ~7 m trunk to real copper. Ampacity is fine for the 16 A branches; the risk
  is termination oxidation/creep over years. Pick one; don't leave CCA bare-crimped.
- **Belleville (or Nord-Lock) + flat washer** under the PSU-stud/busbar nuts (split lock-washers
  are proven useless) to hold preload against creep. LRS-350 studs = **M3.5 @ 8–10 kgf·cm**.
- **Single-point V− star + isolated V+** (already designed): both PSU negatives + both chain
  returns + Pi/Bonnet GND to ONE node; never a second ground path; never tie the two V+.
- **Space for bulk decoupling caps** at the two center feed points (~2200–4700 µF low-ESR ≥16 V)
  — cuts scan-transient flicker/sag; cheap, but leave the terminals reachable.
- **Per-branch positive fusing** (7.5 A, already designed); **stagger PSU turn-on** for cold-start inrush.
- **Leave every terminal + fuse block physically accessible** (the removable valance does this) for
  re-torque + IR scans.

### EMI — wire it out now
- **Run wired Ethernet as the primary link and disable/strip WiFi** (`dtoverlay=disable-wifi`,
  remove bluez/pi-bluetooth). A 16-panel HUB75 wall is a broadband RF emitter right next to the
  Pi; the Pi-4 2.4 GHz desense is Foundation-documented. 5 GHz is a fallback, **Ethernet is robust.**
- **Shortest ribbons; route the ~17 ribbons on a SEPARATE path from the 60 A DC bus** (cross at
  right angles, don't bundle) → less crosstalk/ghosting + less coupling into the Pi.
- **Grounded metal backing behind the Pi/Bonnet**; keep the Pi as far from the panel mass as wiring allows.

### Thermal / structural
- **Make the ceiling gap a chimney:** the valance's top vent reveal is the exhaust — **add a low
  intake** so warm air convects out (optionally a quiet low-RPM exhaust fan). Retrofitting airflow
  into a closed 5 m gap is the painful one. Panels don't need active cooling; the *trapped ambient* does.
- **PSUs at the ends, lying flat, both short-end vents clear, ≥10–15 cm air.**
- **Service access:** a single panel pulls off the front (magnets) and a PSU pulls out (removable
  valance) without dismounting the 5 m row — verify this holds in the final layout.

## ADD-LATER / TUNE AFTER POWER-ON (cheap, non-structural)
- **Clip-on ferrite cores** (common-mode, whole-ribbon) at the Bonnet end of each ribbon + on DC
  leads at the panel input — add/adjust after observing behavior. Don't over-wind power leads.
- **Software:** `--led-slowdown-gpio=2`(+), `--led-pwm-lsb-nanoseconds` 150–300 (ghosting),
  `--led-pwm-bits`, `--led-limit-refresh`, `isolcpus=3`, `dtparam=audio=off`. Favor a rock-solid
  100–150 Hz over a jittery max.
- **Dielectric/contact grease** in the HUB75 + JST plugs (anti-fretting; do at assembly if you can).
- **Bulk decoupling caps** installed at the feed points.
- **Blue (low-strength) Loctite** on threads *where the ring terminal, not the thread, carries current.*

## SPARES KIT (buy the panels NOW; rest as budget allows)
- **1–2 same-batch P5 64×32 panels** ← the one that must be bought with the order (batch-matching
  avoids driver init incompatibilities). The not-repairable, single-point-of-visible-failure item.
- 1 spare **LRS-350-5**, 1–2 spare **80 mm fans**, a few short **HUB75 ribbons**, 1 spare **Triple
  Bonnet**, 1 spare **Pi 4 + a cloned SD image** (SD corruption on 24/7 Pis is common).

## MAINTENANCE (low-effort, high-payoff)
- **~30 days after commissioning: re-torque every power terminal** (thermal-creep settle-in — the
  single most valuable free action). Then **annually.**
- **Every 3–6 months:** listen for PSU fan noise, blow out dust, re-seat any backed-out connectors.
- **Annually:** IR-scan the terminals/fuse blocks under load (a phone-clip thermal cam) — a hot
  terminal is a loosening one; check PSU case temp + output voltage under load.
- **The tell:** end-of-chain pixels going pink/dim = 5 V droop → add injection/trim, not a panel swap.

## Small shopping additions from this pass
Noalox (if keeping CCA) · bootlace ferrules + crimper · Belleville/Nord-Lock washers (M3.5) ·
latching JST-VH housings · dielectric grease · a bag of clip-on ferrite cores · bulk low-ESR caps ·
an Ethernet run to the Pi · the spares above. (Screw-down `cable_clip` prints free.)

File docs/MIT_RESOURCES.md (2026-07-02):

# MIT BUILD RESOURCES — fabricate the wall on campus (free/cheap)

For the owner (g-vansh), an **MIT grad student**, building the Vestor LED wall frame
(see `INVENTORY.md` §8). Researched 2026-06-21 (3 web-research agents). **Bottom
line: fabrication and 3D printing are FREE for grads; materials are free-to-cheap via
MIT give-away channels + a $500 grant. The frame can cost close to nothing.**

> ⚠️ Access rules / fees / perks change each year — treat the specifics below as
> "verify when you go," not gospel. Emails + URLs included so you can confirm.

---

## 1. WHERE TO BUILD (machine shops & makerspaces, grad access)

| Space | Bldg/Room | Cost (grad) | Tools relevant to the frame | How to get in |
|---|---|---|---|---|
| **MIT Hobby Shop** ⭐ | **N51-120** | **Free** for students (fee reportedly dropped for AY26-27) | **Waterjet, MIG+TIG welding, metal lathes/mills, bandsaws** (cut extrusion/steel to length), drill presses, FDM + resin 3D printers | Email **hayami@mit.edu** → Calira invite → **1-hr in-person orientation** (Wed 1-2 / Fri 3-4, first 6 wks of term). [studentlife.mit.edu/hobby-shop](https://studentlife.mit.edu/campus-communities/hobby-shop/) |
| **MITERS** ⭐ | **N52-115** | **Free, no fee, no application** | Bridgeport + CNC mill, lathe, h/v bandsaws, drill press, **MIG welder**, 3D printers, full EE bench | Show up during open hours with a project; a keyholder onboards you. 24/7 keyholder status after ~1-2 semesters. [miters.mit.edu/membership](https://miters.mit.edu/membership.html) |
| **Project Manus / MIT MAKE — Metropolis** | **6C-006B** | Free w/ training | FDM hub: Prusa MK3S/MK4 (~250×210×210); laser cutters; drill press, bandsaw, hand tools | Free **M1T** (ex-MakerLodge) orientation → tool trainings → free credentials. [make.mit.edu/metropolis](https://make.mit.edu/metropolis) |
| **Project Manus — The Deep** | **37-072** | Free w/ training | SLA/resin (Form 3 ~145×145×185), 3D printers, prototyping | Same M1T path. [project-manus.mit.edu](https://project-manus.mit.edu/thedeep-metropolis.html) |
| **Edgerton 6C Student Shop** | 6C | Free w/ training | Mills/lathes; 1st-floor fab has CNC + **waterjet** | **12-hr training** (build a steel flashlight); contact **Mark Belanger, mdbelang@mit.edu**. [edgerton.mit.edu student-shops](https://edgerton.mit.edu/for-MIT-students/student-shops) |
| Pappalardo (MechE) | Bldg 3 basement | Course-2 gated | Lathes, CNC, **big waterjet**, laser | Mostly via 2.00x classes/UROP — harder for non-MechE. |

### ⭐ HOBBY SHOP — the plan for THIS build (scouted 2026-06-29; owner getting access)
N51-120 · 265 Mass Ave · (617) 253-4343 · Director **Hayami Arakawa hayami@mit.edu**,
Assoc. instructor **Charlotte Reiter creiter@mit.edu**. **FREE for students.**
- **Cut the 2 steel rails to ~1.6 m:** **Baileigh 14" cold saw** (best — clean square cuts
  on flat bar/angle); backups: DoAll 24" metal bandsaw, Omax waterjet. **Confirm max stock
  length with staff** (1.6 m is long).
- **Wall-anchor holes in steel:** Clausing drill press. (Also Bridgeport/Haas mills,
  MIG+TIG welders if needed.)
- **3D printers — CONFIRMED 2026-07-02 (Charlotte Reiter email). The Stratasys uPrint is
  GONE.** Now **3 printers: Bambu P2S** (FDM, 256³ mm), **Bambu H2S** (FDM, 340×320×340 mm,
  65 °C chamber / 350 °C hotend → PLA/PETG/ABS/ASA/PC/CF), **Formlabs Form 3L** (resin SLA,
  335×200×300). **PLA is FREE** (only filament stocked now; more soon). **Resin = $0.25/mL**
  (assorted). → Full fabrication plan (parts, printer/material per part, PLA-creep strategy)
  in **`docs/FABRICATION.md`**. Also Epilog **120 W laser** (40×28") + Laguna 4×8 CNC router
  for acrylic/ply jigs.
- **Steel stock = BRING YOUR OWN** (no metal store). Source order: **`reuse@mit.edu`** (free
  scrap + Unistrut) → **MIT Central Machine Shop** ([web.mit.edu/cmshop](https://web.mit.edu/cmshop/services.html), stocks/pulls steel/alu) → OnlineMetals off-campus. Ask Hayami for offcuts.
- **⚠️ Orientation REQUIRED before any tool use** — Wed 1–2 / Fri 3–4, **first 6 wks of term
  only** (tours Mon 12–12:30). **Email hayami@mit.edu now** for a Calira slot; ask (a) max
  cold-saw stock length, (b) steel/Unistrut offcuts availability.
- Hours: Mon 10–8, Tue–Fri 10–7, Sat 10–4, Sun closed. **Cash/TechCash only.** Ethos =
  finished projects; staff give 1-on-1 help.

#### 🧰 Full equipment (access GRANTED 2026-07-02) — what each buys THIS build
The Hobby Shop is a full metal **and** wood shop. Relevant machines, grouped by build use:
- **Precision metal cutting:** **Omax Micro Jet waterjet** (cut aluminum/steel plate to any
  shape — brackets, cleats, **steel magnet strips**), **Baileigh 14″ cold saw** + **DoAll 24″
  bandsaw** (cut rail/extrusion to length), **Epilog 120 W laser** (acrylic diffusers/bezels,
  thin jigs/templates), **sheet-metal tools** (form the steel magnet strips).
- **Precision machining:** **Bridgeport mills ×2**, **Prototrak DPM2 mill**, **Haas Mini Mill 2**,
  **Menig micro mill**, **Prototrak/Trak lathes** → machine custom aluminum rails/brackets with
  exact hole patterns (means we **don't have to buy 80/20** — we can mill our own rails), turned parts.
- **Welding:** **Miller MIG + TIG** → a welded steel/aluminum frame if ever wanted (likely overkill).
- **Big CNC (wood/plastic sheets):** **Laguna Swift 4×8 CNC router** (8 ft!) + **ShopBot Buddy**
  → cut wood cassettes/frames/tongues from full sheets with exact hole grids + connector windows.
- **Shaper Origin** (handheld precision CNC) → cut the tongue-cleat, mortises, brackets — even
  in-place work.
- **Flat-stock prep:** **Martin 20″ jointer + 24″ planer + SawStop table saws ×2 + Oliver 30″
  bandsaw** → mill our OWN dead-flat/straight hardwood (mitigates the ply-warp concern), **Laguna
  LMB 200 mortiser** (precise mortise-and-tenon for the tongues), **Finishing Room** (SEAL wood
  against humidity → dimensional stability), **glue-up table** (laminate cleats / torsion boxes).
- **Formtech 989 vacuum former** → thermoform plastic covers/diffusers if desired.
- **Printers:** Bambu **P2S** + **H2S**, Formlabs **Form 3L** (the auto-generated access list still
  shows a Stratasys uPrint, but **Charlotte's email says it's GONE — treat as gone**).
- Not build-relevant (but available): leatherworking, tufting guns, sewing, **softserve machine**.

**Upshot:** we can build the mount to a high standard entirely in-house in **either metal or wood**,
and make every precise interface part (tongues, steel strips, brackets) on the waterjet/mills/CNC.
This removes the "buy 80/20" dependency and de-risks flatness/precision. Hours: Mon 10–8, Tue–Fri
10–7, Sat 10–4. Orientation required first (email hayami@mit.edu).

**⚠️ None stock 80/20 T-slot extrusion** — buy the raw extrusion/steel (or source free,
§2) **or machine our own rails from aluminum bar/plate on the mills/waterjet** (now viable).

**Best plan:** **Hobby Shop** for the metal cutting/welding/waterjet (one orientation,
everything in one room) **+ MITERS** for free 24/7 iterative drilling + electronics +
printing. Use **Metropolis/The Deep** for extra 3D printing & laser-cut brackets.

---

## 2. MATERIALS — free first, then cheap

### Free
- **`reuse@mit.edu` + `reuse-ask@mit.edu`** ⭐ — MIT give-away list; lab/shop cleanouts
  dump steel, extrusion, fasteners, electronics. **Post a request now:** "grad student
  looking for 80/20 extrusion / steel sheet / M3 T-nuts." High odds for steel/scrap/
  fasteners; real-but-moderate for 80/20. Sub: [mailman.mit.edu/.../reuse](https://mailman.mit.edu/mailman/listinfo/reuse) + [.../reuse-ask](https://mailman.mit.edu/mailman/listinfo/reuse-ask). [web.mit.edu/reuse](https://web.mit.edu/reuse/)
- **Edgerton Student Project Lab (4-409)** — free-use plywood, metal rods, machine
  screws/nuts/wood screws. [edgerton.mit.edu/.../student-project-lab-4-409](https://edgerton.mit.edu/for-MIT-students/student-shops/student-project-lab-4-409)
- **Makerspace scrap bins** — MITERS scrap piles (ask members in person).
- **Rheaply / Equipment Exchange (WW15)** — surplus routed through departments; ask
  your lab/dept admin to grab extrusion or steel shelving for you. [vpf.mit.edu/acquire-surplus](https://vpf.mit.edu/acquire-surplus-equipmentfurniture)

### Cheap
- **MIT Swapfest (Flea at MIT)** — 3rd Sunday monthly, **Apr–Oct**, Albany St Garage,
  9am-2pm, ~$6 cash, haggle. Metal, extrusion, test gear, hardware. [w1mx.mit.edu/flea](https://w1mx.mit.edu/flea-at-mit/)
- **MIT Furniture Exchange (FX), WW15-182** — Tue/Thu 10-4 + 1st Sat; cheap shelving to
  cannibalize for steel. [fx.mit.edu](https://fx.mit.edu/)
- **Off-campus:** Home Depot (Cambridge/Somerville) — Superstrut/Unistrut, plywood, lag
  screws, **TOGGLER SNAPTOGGLE** toggle bolts. Boston Building Resources & Habitat
  ReStore — cheap reuse lumber/steel/hardware. New 80/20 via [8020.net distributor lookup](https://8020.net/distributorlookup) (Air Inc. = regional distributor).

---

## 3. FUNDING (apply as a grad student)

- **Project Manus "Design-to-Making" mini-grant — up to $500** ⭐ for supplies/materials;
  best fit for a personal hardware build. + **$100 MakerBucks** after free MakerLodge/M1T
  training (spend on stock + machine time). [make.mit.edu](https://make.mit.edu/) · [project-manus.mit.edu/students](https://project-manus.mit.edu/students)
- **MIT Sandbox — $1K–$25K** seed; open to grad students but **venture-oriented** — only
  worth it if framed as a product/startup prototype. [mit-sandbox.smapply.io](https://mit-sandbox.smapply.io/)
- **Departmental discretionary funds** — ask advisor/admin; a faculty cost-object can buy
  MIT surplus for free.

---

## 4. 3D PRINTING — print the interface parts, buy the structural metal

**Where (grad-accessible, free):** Metropolis (FDM, free white **ABS** + MakerBucks for
PLA/PETG), The Deep (SLA/resin), MITERS (free), MakerWorkshop (lists FDM as free).
**Libraries do NOT 3D print.** The old paid Project Manus print service ended Dec 2023 —
it's all self-serve after training now.

**Material:** **ABS (free at Metropolis) or PETG/ASA** for anything load-bearing or near
the warm PSUs. **Avoid PLA** (creeps under load, softens with heat). Reserve SLA/resin
for cosmetic detail only (too brittle for brackets).

**Why this split:** structural metal (the extrusion carrying ~15 kg over 5 m) must be
bought/machined — stiffness/load is a job polymer can't do over that span. The
*interface* parts (brackets, clips, trays) are geometry-matching, not load-bearing, and
you need ~60 identical ones → printing wins.

**What to print:**
| Part | ~Size / qty | Why print | Material |
|---|---|---|---|
| **Panel-corner T-slot brackets** ⭐ | ~40×40×15 mm, 60+ | biggest win — M3 clearance into panel corners, hammer-nut onto 80/20; 60+ to buy | ABS/PETG |
| **Depth spacers / M3 standoffs** | 5-15 mm | set uniform panel standoff for ribbon clearance | ABS/PETG |
| **HUB75 ribbon + 5V cable raceways/clips** | snap into T-slot | corral cable along 5.1 m | PETG |
| **Pi 4 + bonnet tray** | ~90×60 mm | bolts to T-slot, clean HUB75 routing | ABS/PETG |
| **LRS-350-5 PSU brackets** | ~50×30 mm ×2 | clamp PSU flange to extrusion (heat) | **ASA/PETG** |
| **End caps** | 20×20 mm | cap 80/20 ends; pennies vs $1-2 ea | any |
| **Magnet holders** (magnet-mount only) | for 10-12 mm discs | vs Adafruit ~$0.63 ea × 60+ | ABS/PETG |

**Reusable designs:** Printables [1055338](https://www.printables.com/model/1055338),
[1294572](https://www.printables.com/model/1294572-brackets-for-joining-hub75-led-panels),
[1259766](https://www.printables.com/model/1259766) (HUB75 joiners); [463278](https://www.printables.com/model/463278),
[10750](https://www.printables.com/model/10750-corner-brackets-for-2020-extrusion) (2020 brackets);
Thingiverse [thing:2815656](https://www.thingiverse.com/thing:2815656).

---

## 5. RECOMMENDED MOVE ORDER
1. **Subscribe** to `reuse` + `reuse-ask` and **post a request now** (longest lead time).
2. Do the **free M1T/MakerLodge training** → bank $100 MakerBucks + makerspace access.
3. **Email Hobby Shop** (hayami@mit.edu) for the orientation — your one-stop metal shop.
4. **Apply** for the $500 Design-to-Making mini-grant.
5. Hit the next **Swapfest** + **FX** for cheap fill-ins.
6. **3D print** brackets/clips/PSU mounts in ABS/PETG at Metropolis or MITERS.

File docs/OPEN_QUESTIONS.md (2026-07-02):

# OPEN QUESTIONS
Anything ambiguous or needing the owner. Everything else was built. Updated 2026-07-01
(Phase 0 / first light complete).

## Resolved this session (owner provided / decided)
1. **WiFi** — SSID + password provided by the owner and baked ONLY into the
   gitignored `scripts/custom.toml` (plaintext, `password_encrypted = false`). Never
   committed; lives only in the SD image.
2. **pi user password** — provided by the owner; baked into `scripts/custom.toml`
   under `[user]` (plaintext). Never committed.
3. **Project code name / hostname = `vestor`.** The owner set the code name to
   "vestor"; the whole repo is standardized to it — hostname `vestor`
   (`ssh pi@vestor.local`), on-Pi path `/home/pi/vestor`, `services/vestor.service`.
4. **Entry point = `vestor-tracker.py`** (renamed from upstream `flight-tracker.py`);
   `services/vestor.service` `ExecStart` points at it.

## ✅ RESOLVED — Pi reachability (2026-07-01)
8. **Tailscale — DONE.** Auth key baked in, the Pi enrolled, and it's reachable:
   **root Tailscale SSH works from the Mac** (`ssh root@vestor` / `100.91.127.127`,
   identity auth, no password). *Gotcha fixed 2026-07-01:* WiFi wouldn't re-provision
   because `cmdline.txt` hardcoded the cloud-init instance-id (`ds=nocloud;i=…`),
   overriding `meta-data` — so an added network never applied. Fixed by changing `i=`
   in `cmdline.txt` (see BUILD_LOG). Pi runs on **MIT 5 GHz** (client isolation is moot
   for outbound Tailscale); `Vestor` phone hotspot configured as a backup network.

## Decisions I made autonomously (flagged so the owner can override)
- **Tailscale chosen over MIT SECURE / Ethernet for reachability.** MIT SECURE
  (802.1X) was rejected (Kerberos credential exposed on a wall appliance, brittle,
  uncertain it even fixes peer reachability); no Ethernet cable on hand; personal
  APs/routers are barred on MITnet. Tailscale is outbound-only, policy-compliant, and
  durable for a wall-mounted display. To undo: `sudo tailscale down && sudo apt remove
  tailscale` on the Pi and delete the node in the console.
- **GitHub repo renamed `g-vansh/flightwall` → `g-vansh/vestor`** to match the code
  name. GitHub auto-redirects the old URL. To revert: rename back in repo Settings
  and `git remote set-url origin`.
- **On-Pi directory `/home/pi/vestor`** (matches repo + code name). The clone target
  in `install_app.sh` and all service paths use it. Safe because the Pi is not yet
  provisioned — nothing to migrate.

## Not blocking (can be done anytime later)
5. **API keys** (`OPENWEATHER_API_KEY`, `MBTA_API_KEY`) are blank placeholders in the
   Pi's `.env`. The app runs fine without them. Add the free keys later, then
   `sudo systemctl restart vestor`. NWS weather + Bluebikes need no key.

## Wall mount — profile captured (owner-confirmed 2026-07-02)
9. **RESOLVED — how to hang the row.** The top of the wall has a **full-width
   (~512 cm) structural WOODEN rail** with a continuous **open-top pocket
   (1.4 cm × 5 cm)** and a **3.4 cm-proud lip**. Plan: **top cleat/tongue (≤1.4 cm)
   dropped into the pocket** carries the whole row; lip gives standoff; PSUs mount
   separately. Full spec: `docs/design/WALL_PROFILE.md`. (Supersedes the panel
   "mounting method TBD" / magnet question — the plastic rear frames don't need
   magnets if the assembly hangs from a cleat.)
10. **TO CONFIRM ON-SITE (before building the cleat):**
    - Depth behind the 3.4 cm lip for the **center Pi + Triple Bonnet stack**
      (~4–5 cm deep) — may exceed 3.4 cm → recess it or mount the Pi/bonnet just
      below the row.
    - **Panel weight** (≈0.5 kg each?) → total hung load (~10–13 kg est.).
    - Pocket is **uniform/continuous** across the full 512 cm.
    - Wall material behind (studs?) for a **bottom restraint** fixing.
    - Desired **height** of the row (pocket puts the top ~22.5 cm below the ceiling).

## ✅ CONFIRMED on hardware at first light (2026-07-01)
6. **RGB order / row addressing / slowdown — CONFIRMED, no tweaks needed.**
   `rgb_sequence=RGB` (colors correct, no swap), `row_address_type=0`, `gpio_slowdown=4`
   all worked on the first real run. Matches `display/__init__.py` / `config.py` as-is.
7. **FM6126A init — NOT needed (confirmed).** Panel lit fully with **no** `--led-panel-type`;
   adding `FM6126A` made zero difference. FM6124HJ = standard driver, exactly as
   determined. *(The actual first-light gotcha was physical — ribbon on the wrong bonnet
   port shows a stuck half-lit block that mimics a driver fault; see BUILD_LOG 2026-07-01.)*

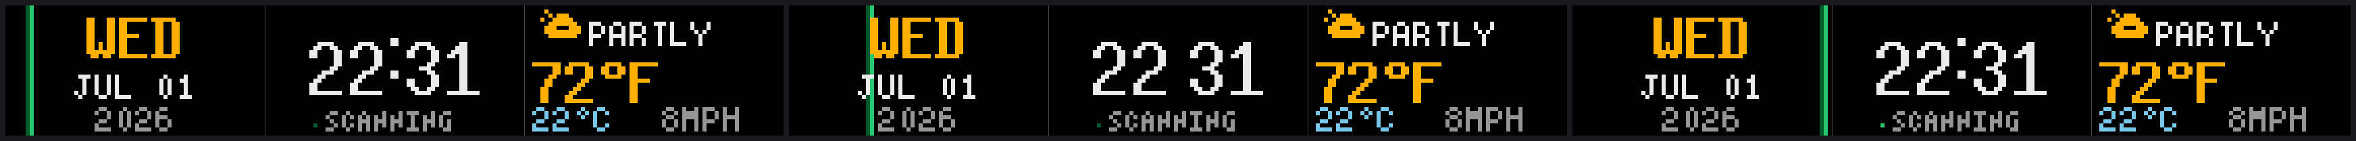
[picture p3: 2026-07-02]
docs/design/idle_preview.png

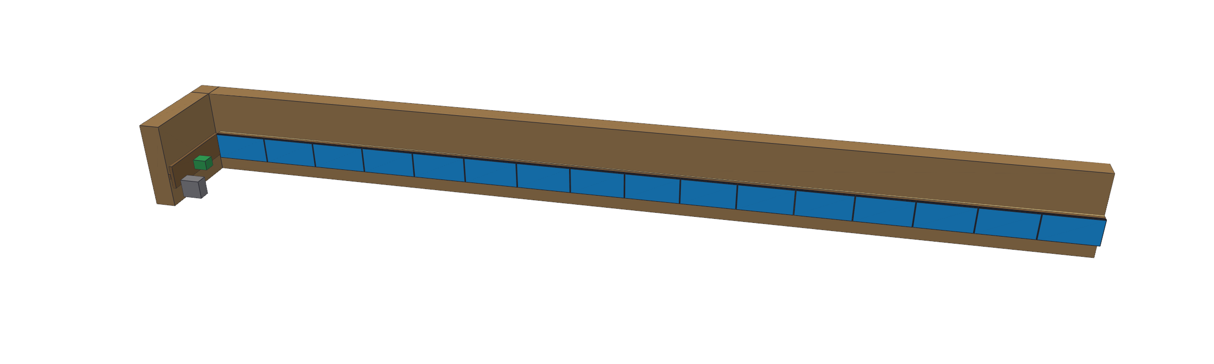
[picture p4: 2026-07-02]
docs/design/cad_overview.png

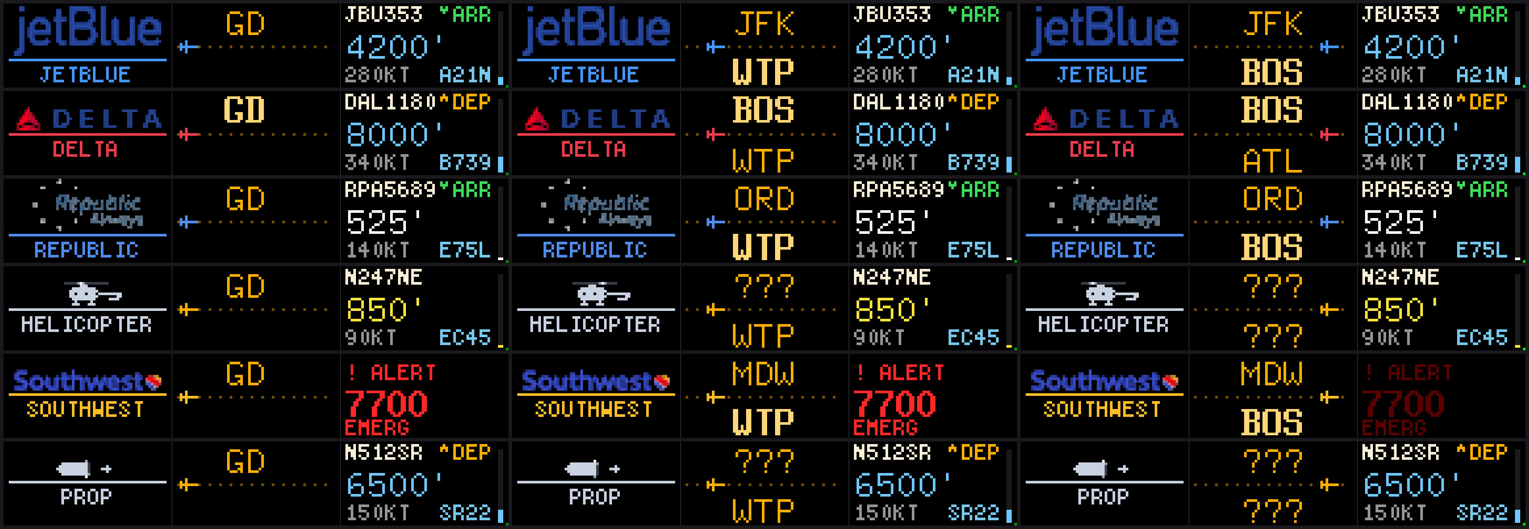
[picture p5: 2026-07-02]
docs/design/flight_card_preview.png

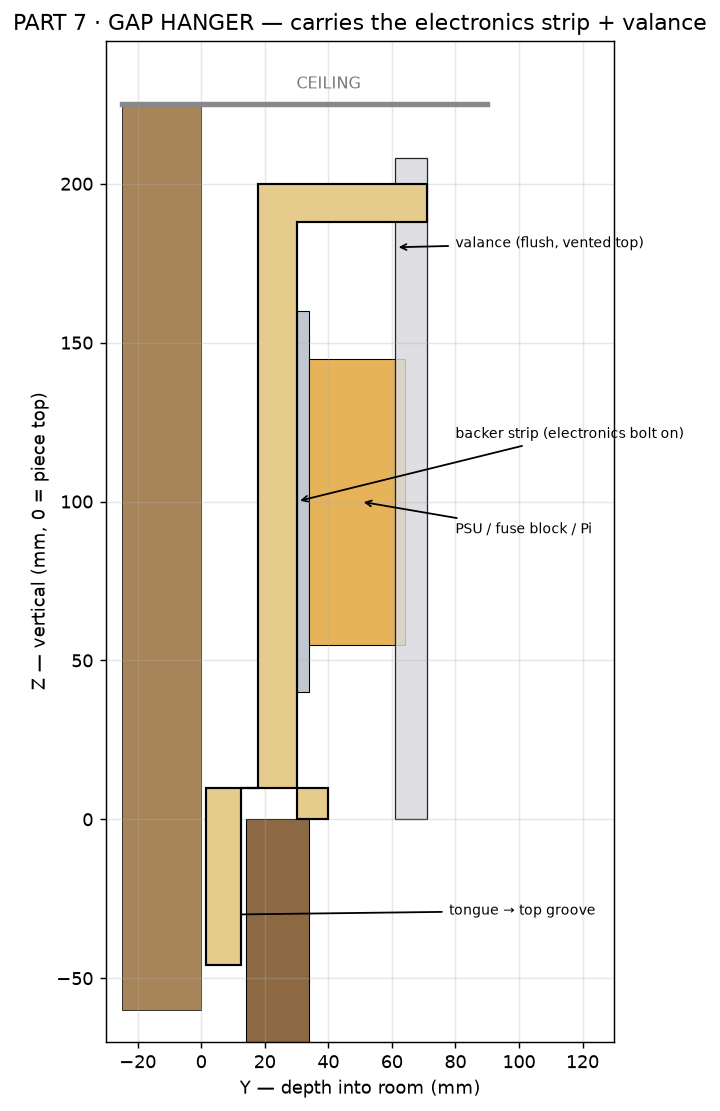
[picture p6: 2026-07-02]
docs/design/part_gap_hanger_fit.png

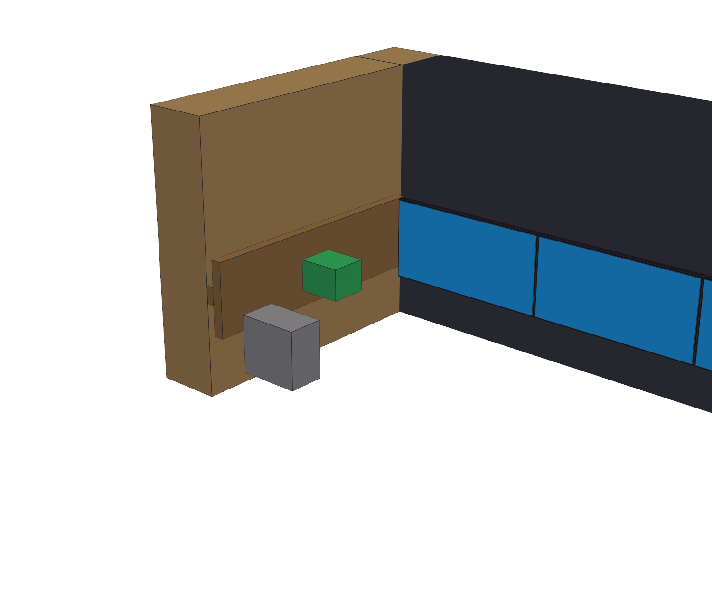
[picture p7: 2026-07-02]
docs/design/cad_corner.png

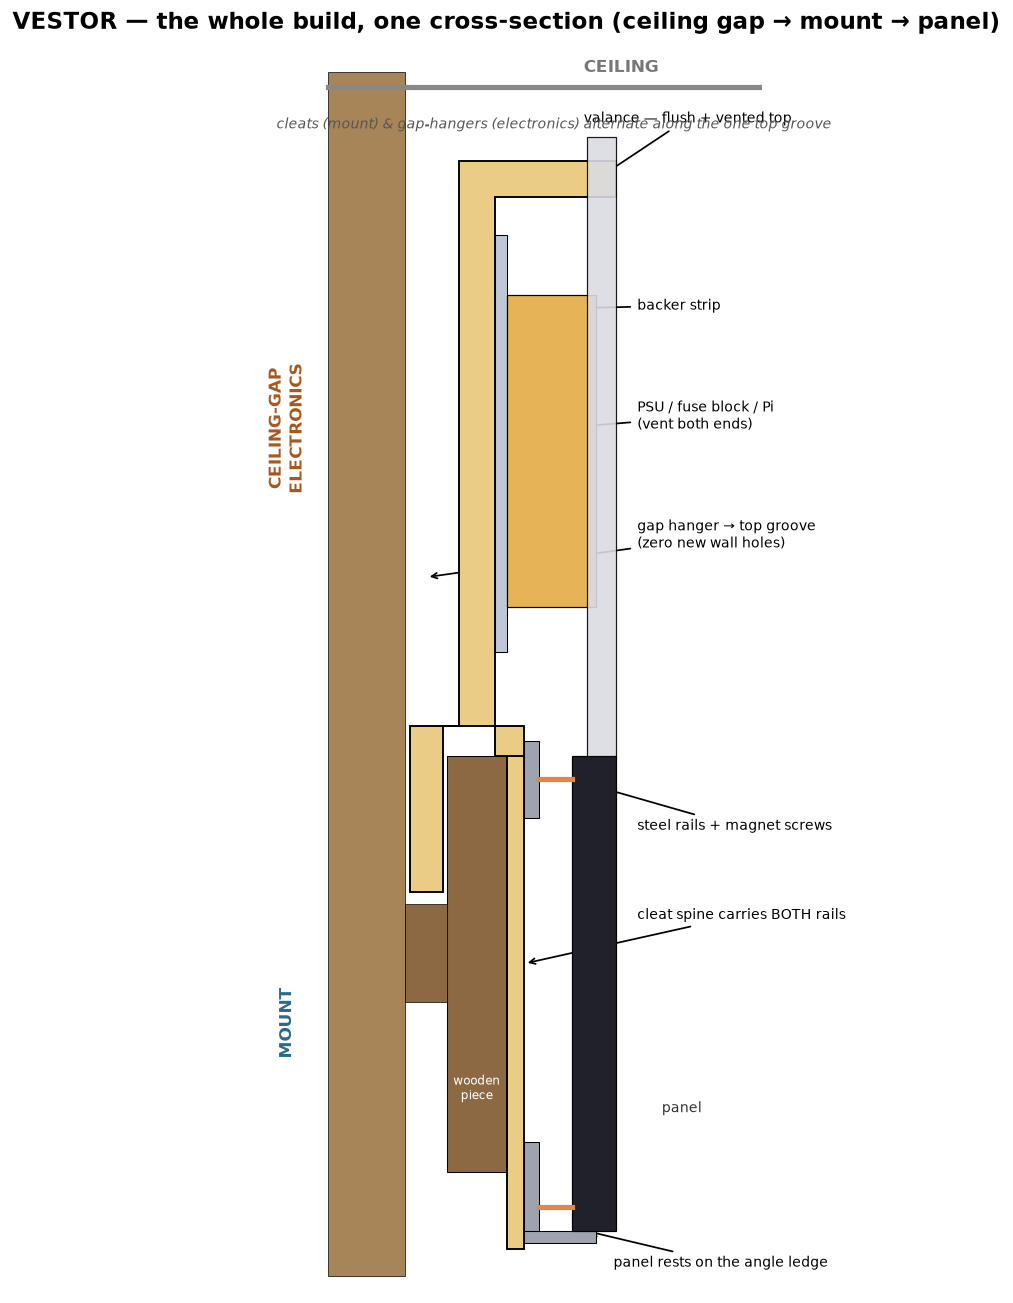
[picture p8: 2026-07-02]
docs/design/full_section.png

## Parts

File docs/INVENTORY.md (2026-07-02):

# INVENTORY — Vestor 16-panel wall

Inventory & gap analysis. Compiled 2026-06-21, **revised 2026-06-21** against the
owner's actual on-hand list. Sources: `HARDWARE.md`, `AGENTS.md`, `BUILD_LOG.md`
(2026-06-14 power research), Adafruit product pages (6358 / 1466), Mean Well
LRS-350-5 datasheet/listings.

> **Headline (updated 2026-07-01):** ✅ **Phase 0 DONE — one panel is lit** (Pi + Triple
> Bonnet + riser + LRS-350-5 + hzeller, driven over Tailscale SSH). All electrical parts
> are on hand or ordered. **Remaining for the full 16-panel wall:** finish per-panel QC,
> then the **mount + power distribution** (fuse blocks, steel rails, magnets) — full
> plan in **§9**, order status in **§9.2**.

---

## 1. WHAT I HAVE  ✅

| Item | Spec | Status |
|---|---|---|
| Raspberry Pi 4 Model B | brain; runs the hzeller driver | ✅ on hand |
| Adafruit **Triple** RGB Matrix Bonnet | PID 6358, "active3", 3 chains, **no onboard power** | ✅ on hand |
| **45 W USB-C power supply** | powers the **Pi** (and the bonnet's logic via the Pi header) | ✅ **fine** |
| microSD card | flashed with the Vestor image | ✅ on hand |
| **CnGear P5 HUB75 panels ×16** | 64×32, FM6124HJ, 1/16 scan; framed; each w/ data ribbon + fork-terminated power pigtail | ✅ **on hand (arrived 2026-06-29)** |
| **Mean Well LRS-350-5 ×2** | 5 V / 60 A / 300 W | 🛒 **ORDERED 2026-06-29** (Wired Watts #225740, $29.50 ea; up to 10 biz days) |
| **Double Stack Mount Kit** (Mean Well) | bracket to stack the 2 PSUs | 🛒 ordered (same order, $4.50) |
| **Panel Magnets ×100** | $0.10 ea screw-in magnet feet for the M3 holes | 🛒 ordered (same order, $10) — enables magnetic mount (96 = 6×16) |

> ⚠️ **GAP in that order: NO AC power cords.** The LRS-350-5 has bare L/N/⏚ screw
> terminals — it needs a **2× AC mains cord** (3-conductor, US plug → bare/fork ends,
> ~$8 ea) to power on. Order 2. Also: set each PSU's input-voltage switch to **115 V**.

**45 W USB-C note:** safe and more than enough. A spec-compliant USB-C PD charger
outputs **5 V by default** and won't go above 5 V unless the device negotiates up
— which the Pi 4 never does. The Pi 4 only draws ~15 W, so the extra headroom is
harmless. Just make sure it's a reputable/compliant unit (the official Raspberry
Pi 45 W is ideal).

---

## 2. WHAT I NEED

### 🔴 BUY NOW — unblocks Phase 0 *and* required for the wall anyway
| Need | Spec | Qty | ~Cost | Why |
|---|---|---|---|---|
| **Mean Well LRS-350-5** PSU | 5 V / **60 A** / 300 W | **2** (1 lights Phase 0; 2 for the full wall) | ~$33 ea | The only thing that can power the panels. Stocked at DigiKey/Mouser/Arrow/Jameco/Amazon. |
| **AC mains cord** for the PSU | fork/ring-lug or IEC tail → 120 V; fused+switched is nicer | **2** (1 per PSU) | ~$8 ea | LRS-350-5 has bare L/N/⏚ screw terminals — needs a mains cord. |

> With **one** LRS-350-5 + **one** AC cord you can do **Phase 0** the day the panels
> land: wire PSU → the panel's power cable, panel ribbon → bonnet **Port 1**, Pi on
> its 45 W USB-C, and run the single-panel flight test.

### 🟠 BUY BEFORE THE FULL WALL — power distribution (SIMPLIFIED, no-solder — see §9)
**Revised 2026-06-29 (3-agent optimization pass).** The panels each ship a
**fork-terminated power pigtail**, so distribution collapses to **one automotive
fuse block per PSU** — no bus bars, no copper trunks, no crimping, no soldering.

| Need | Spec | Notes |
|---|---|---|
| **8-way ATC fuse block** w/ negative bus | ~20 A/circuit, ~75 A/block, ~$16 | **1 per PSU** (PSU1→8 panels, PSU2→8). Panel **+5 V forks land on the fused studs, GND forks on the common negative bus** — the block's negative bus *is* your ground bus. One fuse per panel. |
| **ATC blade fuses** | **7.5 A** (10 A if running bright) | one per panel + spares; panel ≈4 A @ BRIGHTNESS 50. |
| **10 AWG wire**, red + black | short PSU→block jumpers | Carries the **full ~32 A per PSU** (current only splits *after* the fuses → NOT 14 AWG). Land bare stranded under the screws — no lugs needed. |
| **Common-ground bond** | 14 AWG | One jumper **PSU1 V− ↔ PSU2 V−**; the bonnet already ties Pi GND to panel GND via the ribbon. Bare wire under screws. |
| *(NOT needed)* Hanson distro / bus bars / crimp tool / ferrules / copper AWG6 / 3rd PSU | — | All cut. Fork terminals + screw blocks do it all, solder-free. Keep `BRIGHTNESS≤50` so each PSU sits ~32 A < 60 A. |

### 🟡 BUY BEFORE THE FULL WALL — mounting / structure
| Need | Notes |
|---|---|
| Rigid frame/backing | **Layout LOCKED: one continuous 16-wide row ≈ 5120 × 160 mm** (16.8 ft). **WON'T free-stand — wall-mount above the window** (full buildout + parts list + cost in **§8**). TL;DR: **80/20 1530 backbone** ≈ $210, panels **screwed** via M3 corner holes (magnets need a ferrous sheet — see §8.2), supported every 3–4 ft so it stays flat. Mount **Pi + bonnet at center-back**; **PSU1 behind the left half, PSU2 behind the right half**. |
| ~~HUB75 ribbon extensions~~ | **Not needed** — the center-mount 2×8 topology (§5) keeps every ribbon short (bonnet→center panel, then panel-to-panel). The included short data cables suffice. |

---

## 3. WHAT TO RETURN

### ✅ Adafruit 5V **4A** supply — PID **1466** ("P1466") — *already returning, correct call*
It's the companion for the **single** Matrix Bonnet (3211), not the Triple. On the
6358 there's **no barrel jack to plug it into**, its logic comes from the **Pi
header**, and at **4 A** it's ~6 % of one LRS-350-5 (one P5 panel alone can pull
~8 A all-white). It also can't power the Pi 4 (USB-C, not barrel). Redundant on
connector, role, and capacity. Refund ≈ $14.95.

> *Optional:* if you want to flash-test a single panel **before** the LRS-350-5
> arrives, the P1466 + a $2 "barrel-jack → screw-terminal" adapter can limp one
> panel at low brightness. But real Phase-0 tuning should use the LRS-350-5 (a
> sagging 4 A supply causes flicker/color shift that masquerades as driver-config
> bugs). If you don't want the hassle, just return it.

---

## 4. STATUS SUMMARY

| Phase | Can I do it with what I'll have tomorrow? |
|---|---|
| **Phase 0** (light 1 panel) | ✅ **DONE 2026-07-01** — one panel fully lit (demo -D4), driven over Tailscale SSH. Config confirmed: standard driver, slowdown 4, RGB. |
| **Phase 1** (full 16-panel wall) | ❌ Need **2× LRS-350-5 + AC cords + 2 bus bars + trunk wire + lugs + ground bond + a frame**. |

---

## 5. LAYOUT — LOCKED: one long 16-wide row, fed from the center  (2026-06-21)

**Decision: one continuous 1024×32 row (5120 × 160 mm), Pi+bonnet center-mounted,
2 chains of 8 daisy-chaining outward** (`--led-parallel=2 --led-chain=8`).

**Why not 3 chains of 6+5+5?** HUB75 ribbons must stay **< 50 cm** (raw parallel
TTL @ ~15–20 MHz, no differential signaling). All three bonnet ports sit at one
physical point; splitting 6+5+5 from one end forces **1.9 m / 3.5 m jump cables**
to the starts of chains 2 & 3 → corruption + flicker. Center-feeding two 8-panel
chains keeps **every** ribbon short.

| Item | 2×8 center-feed (chosen) | 3×6 from end | 1×16 single chain |
|---|---|---|---|
| Long jump cables | **none** ✅ | 1.9 m + 3.5 m ❌ | none ✅ |
| Wasted panel slots | **0** (16=2×8) ✅ | 2 (needs 18) | 0 ✅ |
| Refresh on Pi 4 | hundreds of Hz ✅ | highest | marginal/flicker ⚠️ |
| Assembly wrinkle | left 8 mounted **180°** + SW flip | rotation/long cable | none (simplest) |

**Bring-up plan:** validate first-light with the dead-simple `parallel=1 chain=16`
(no rotation), then switch to the 2×8 center-feed for the real install.

**Software:** we own `display/__init__.py`, so the hardware canvas is **512×64**
(chain 0 = left half, chain 1 = right half); compose the 1024×32 render into it
with the **left half rotated 180°** (snake). Replaces the earlier 6+5+5
`pixel_mapper_config` TODO in `BUILD_LOG`.

**Confirm on the bench:** which HUB75-D connector is IN vs OUT (sets the daisy
direction and which half needs the 180° flip).

---

## 6. PANEL-SPEC COMPATIBILITY — ✅ VERIFIED FROM PHYSICAL PANELS 2026-06-29
The 16 panels arrived. Specs read directly off the boards (photos IMG_3780-82).
**Brand: CnGear. Board rev: JHT2.0. Marking: `P5(2121)64×32-16S-JHT2.0`.**

| Spec | Verdict | Note (verified on-board) |
|---|---|---|
| 64×32, P5, **SMD2121** | ✅ | silkscreen `P5(2121)64×32`. 16 wide = 1024 px (matches sim/design). |
| 1/16 scan (`16S`), **A–D** address (no E) | ✅ | `row_addr_type=0`. Pinout table shows only A B C D — confirms standard 1/16. |
| HUB75-D pinout (R1 G1 / B1 GND / R2 G2 / B2 GND / A B / C D / CLK LAT / OE GND) | ✅ | Read off the board's own pinout table. Standard HUB75 — plug-compatible with the bonnet. |
| Driver **FM6124HJ** | ✅ start standard | `HJ` is a package/grade variant of the standard FM6124 (≈ICN2037/2038S), **no init**. `panel_type` empty. Fallback `FM6126A`→`FM6127` only if black. (Listing image said `FM6124ZD` — same family, no impact.) |
| **HUB75-D connector**, 16-pin 2×8 | ✅ | IN + OUT per module (daisy). |
| 5 V power — **4-pin keyed plug** (`POWER`), NOT screw terminals | ✅ | Panel power cable plugs into this; PSU-side end TBD (confirm on unboxing). |

**Likely bring-up tweaks (not blockers):** (1) **R/B swap** is common on FM6124 →
set `--led-rgb-sequence` (`RBG`/`BGR`); (2) raise `--led-slowdown-gpio` 4→5 if
flicker. The scary `row-addr-type=3` / forced-`FM6126A` GitHub cases are all
**128×64 1/32-scan "ABC"** panels — **not** this 64×32 1/16-scan A–D panel.

> ✅ **MOUNTING RESOLVED (2026-06-29) — framed panels with 6 brass M3 holes.** Each
> CnGear panel has an **integrated plastic rear frame** with **6 M3-threaded brass
> holes** (4 corners + 2 mid-edge, ~144 mm vertical pitch) = the magnet-mount points.
> **No magnets shipped**, but the holes take screws/brackets. Depth ~15 mm; panels
> don't interlock. Full mounting plan + recommendation in **§8.0**. Power/data cabling
> fully included (§7.3) — the distro now mounts on the **backbone**, not a panel, so the
> 144 mm-on-panel fit is **moot**.

---

## 7. WHAT THE ALIEXPRESS REVIEWS CHANGE — sourcing & QC, NOT compatibility  (2026-06-21)

Reviewed the listing's reviews + seller back-photos (NovaStar receiving-card demo
rig, power-wiring guide, customer module-back shots). **Verdict: nothing here
changes panel compatibility (§6) or the locked 2×8 center-feed topology (§5).**
The complaints are the well-known failure modes of cheap HUB75 panels — wire
quality, shade variation, and unit-to-unit defects. Three hardening actions:

### 7.1 The included power pigtails are probably CCA — buy copper, inject at ≥2 points/half
Reviewers report **copper-clad-aluminum (CCA)** power leads: ~**1.55–1.6× copper
resistance** and **won't take solder** (aluminum-oxide skin). Voltage-drop math
(5 V rail, far panel must stay ≥4.8 V → **≤0.2 V budget**):

| Wire | Current | Length | Drop | Verdict |
|---|---|---|---|---|
| AWG10 Cu | 32 A | 2.5 m | **0.52 V** | ❌ far panels redshift |
| AWG10 Cu | 64 A | 2.5 m | 1.05 V | ❌❌ |
| AWG8 Cu | 32 A | 0.64 m | **0.085 V** | ✅ |

**Starvation looks exactly like a driver bug** — blue dies sag first, so an
under-fed panel tints **red**. Don't chase it in software. Fix is geometry + copper:
- **Center each PSU behind its own half** (PSU1 ≈ behind panel 4, PSU2 ≈ behind panel 12) so the longest run is ~4 panels, not 8.
- **Inject 5 V at ≥2 points per 8-panel half = 4 injection points total** (parallel taps off the bus bar, never daisy-chain panel power through HUB75).
- **Keep the two PSU 5 V positives ISOLATED** — don't parallel two LRS-350-5 onto one rail (they won't current-share; one hogs, the other coasts). Split is already PSU1→left 8, PSU2→right 8.
- **Common-ground bond still mandatory** (PSU1 ⏚ ↔ PSU2 ⏚ ↔ Pi/bonnet ⏚) — that's a *signal-reference* tie, not a power-rail parallel.
- **~40 A fuse per PSU 5 V output.** **Crimp, never solder, the CCA** (won't tin). Use included CCA pigtails only for the final short bus→panel hop; trunks = pure-copper **AWG6**, taps **AWG8/10**.

> ⚠️ **SUPERSEDED by §9 (2026-06-29):** the Hanson-distro plan below is replaced by
> **one 8-way ATC fuse block per PSU** (cheaper, fewer items, no-solder, panel forks
> land directly). The voltage-drop *principles* here still hold; the *part* changed.

**~~Recommended part for the injection points: Hanson "hanpaneldistro" fused distro
boards~~** (wiredwatts.com, ~$14.50, **US-stocked Alpharetta GA**, vetted 2026-06-21).
Each is a passive **5 V-in → 4× fused (7 A) 5 V-out** PCB that bolts to a panel back
(144 mm M3 holes). It IS a bus-bar + fuses + mount in one part — controller-agnostic
(power only; never touches HUB75), so it works identically with the Pi + Triple
Bonnet + hzeller. **Better than one 40 A PSU fuse:** per-panel fusing isolates a
shorted panel to its own 7 A fuse; panel-back mount shortens the high-current runs.
- **Derate for P5: 1 panel per 7 A fuse → 4 panels/board → buy 4 boards** (2 per PSU
  = the 4 injection points above). The listing's "up to 8 panels" is a **P10**
  (low-current) figure; our P5 pulls ~4 A (bright) to ~8 A (all-white), so a single
  white panel would pop a 7 A fuse and 8×4 A > the 30 A board. **Keep BRIGHTNESS≤50.**
- **Still need:** 2× LRS-350-5, AC cords, **copper trunk PSU→board input** (~16 A/board
  → AWG10+ Cu), and the common-ground bond. The board only does the *last leg* +
  fusing; it is **not** a PSU and does nothing for data.
- **Land** the panel pigtail's fork lug or bare wire on the screw terminals (no adapter).
- **✅ Update (2026-06-29):** each panel ships its own **fork-terminated power pigtail**,
  so **mount the distro on the BACKBONE, not a panel** — the 144 mm-on-panel fit concern
  is **moot**. Just land the blue forks (4 per board). Still worth a clamp-meter check of
  one all-white panel vs the 7 A fuse before buying 4. Bus bars + inline fuses also fine.
- **US alternatives if it doesn't fit:** Falcon3DParts distro, QuinLED Dig-Octa
  powerboard (12–16 fused outs), CZH-Labs panel-mount fuse blocks (~$15), or plain
  copper bus bars + inline ATO fuse holders (cheapest, most flexible injection points).
- **Split at the PSU too:** the Hanson **PDist1** (~$15) bolts onto the LRS-350-5 screw
  terminals (4×15A+1×10A fused) — clean injection split *at the supply*, feeding the
  panel-side boards. See `docs/GEAR.md` §1.
- **🔧 No remote-sense on the LRS-350-5 → trim its output to ~5.1–5.2 V** (front trim
  pot) to pre-compensate the run drop; target far-panel ≥4.8 V, don't exceed ~5.3 V.
  **Verify with a DC clamp meter** (most cheap meters read AC only — get a UNI-T UT210E).

### 7.2 Panel-to-panel shade variation is real — and hzeller can't fully fix it
"Different shades between panels" reviews are accurate. **Every hzeller color/brightness
knob is GLOBAL** — `--led-brightness`, `--led-pwm-bits`, `--led-pwm-lsb-nanoseconds`,
`--led-pwm-dither-bits`, `--led-rgb-sequence`, CIE-1931 (on by default). There is
**no per-panel / per-region LUT, no gamma or color-temp flag, and no way to ingest
a NovaStar `.cal` file**. True per-panel correction = hand-patching `MapColors()`
with per-coordinate R/G/B multipliers (hzeller issues #222, #193) — a DIY fork, last
resort. Mitigations, in priority order:
1. **Insist on one batch / one production lot** (biggest lever).
2. **Run lower brightness** (BRIGHTNESS≈50 already planned — also fixes §7.1 sag).
3. **Favor dark/sparse content** — our departure-board aesthetic (black bg, text/logos) hides field uniformity far better than full-screen color would.
4. **Warm up** before judging; LED tint drifts in the first minutes.
> Accept it won't match a NovaStar-controlled wall. At low brightness on black, fine.

### 7.3 Incoming-QC protocol — test all 16 BEFORE mounting (do tomorrow)
DOA units, dead ICs, dead rows, and stuck-color data faults all show up in reviews.
Test each panel **individually** on Port 1 with the hzeller `demo`:

```
sudo ./demo --led-cols=64 --led-rows=32 --led-chain=1 --led-parallel=1 \
            --led-gpio-mapping=regular --led-slowdown-gpio=4 \
            --led-brightness=80 -D <mode>
```

| Mode | Shows | Fault signature |
|---|---|---|
| `-D3` | DOA / first-light | whole panel black = DOA (try `--led-panel-type=FM6126A` before condemning) |
| `-D4` | per-channel color cycle | missing R/G/B = bad channel / RGB-seq |
| `-D5` | grayscale ramp | **16-px-wide dead column = dead FM6124 IC**; horizontal line = dead row; uneven = shade |
| `-D11` | brightness pulse | flicker/lag on one IC = weak driver |
| `-D0` | rotating square | tearing/wrong position = addressing/`row_addr_type` |

- **Log panels 1–16** (pass / which fault). **Keep 2–3 as spares** (~10–15%).
- **RMA defects with video** inside the AliExpress Buyer-Protection window — push for **partial refund without return** (shipping a panel back rarely worth it).
- ✅ **CONFIRMED on unboxing (2026-06-29):** **16 data ribbons** (short 16-pin 2×8 keyed IDC, `UL2651 28AWG`) + **16 power pigtails** (1-per-panel: white 4-pin plug → **blue fork/spade** terminal at the PSU end) + **ZERO magnets**. Data + panel-power cabling is fully covered by the box — buy neither. The forks land directly on distro/bus-bar screw terminals.

---

## 8. MOUNTING & FRAME — how the wall physically hangs  (researched 2026-06-21)

> ⛔ **SUPERSEDED 2026-07-02 by `docs/design/MOUNT_DESIGN.md`.** This §8 plan (80/20
> backbone lag-bolted into wall studs) predates knowing the wall has a **built-in
> full-width structural wooden pocket** (`docs/design/WALL_PROFILE.md`) and predates
> Hobby Shop access. The new plan **hangs from that pocket** (a pre-built French cleat,
> ~10× margin) instead of drilling studs. Kept below for the still-valid panel facts
> (dims, 6× M3 holes, ~0.45 kg, depth budget, "won't free-stand").

> 🏗️ **Build it at MIT for free/cheap:** the owner is an MIT grad student — see
> **`docs/MIT_RESOURCES.md`** for where to cut/weld/3D-print on campus (Hobby Shop,
> MITERS, Project Manus), free materials (`reuse@mit.edu`, Swapfest), and a $500
> Design-to-Making grant. Print the corner brackets/clips, buy only the metal.

### 8.0 ✅ MOUNTING INTERFACE CONFIRMED (2026-06-29, from the real panels)
The CnGear panels have an **integrated plastic rear frame** with **6 brass M3-threaded
holes** = **4 corners + 2 mid-long-edge** (a 3-col × 2-row grid; vertical pair ≈144 mm).
**These 6 holes ARE the magnet-mount points** — the (missing) magnet feet screw into
them. With no magnets, the holes are free for screws/brackets. Panel = 320 × 158 ×
**~15 mm** deep; panels **do NOT interlock** (each mounts independently → the backbone
must set alignment/coplanarity).

**RECOMMENDED MOUNT (best for a 16-wide row): 80/20 backbone + 3D-printed brackets**
(free at MIT) that screw into the 6 brass holes and bolt into the T-slot, *locating*
each panel so the row stays coplanar + evenly gapped. No magnets, no steel backing,
and serviceable (unbolt a panel's brackets to pull it). Print designs: Printables
1294572 / 578204 (HUB75 joiners), adapt for the 144 mm hole pitch.

**Native alternative (tool-free swaps):** buy ~64 magnet feet (~$8–40, screw into the
6 holes) + face the backbone with **two steel strips** at the top-/bottom-row hole
heights; panels snap on, butt edges to align. More serviceable, but +magnets +ferrous
strip and alignment isn't positively located.

> **Provenance note (resolved):** the earlier "magnets + screws" claim came from the
> listing's "Free Parts" image. **Reality: zero magnets shipped**, but the frame's 6
> M3 brass holes mean screw/bracket mounting works regardless.

### 8.1 It will NOT free-stand — wall-mount it
A rigid strip **5120 × 160 mm (16.8 ft × 6.3 in)** has a ~**32:1 aspect ratio** and a
paper-thin base. It **tips sideways**, **bows/sags** under its own ~7 kg, and
**twists** (near-zero torsional stiffness). Free-standing would need a heavy wide
base + A-frame supports every 2–3 ft + a truss spine — far more than just hanging
it. **Wall-mounting (above the window, as planned) is dramatically the right fit:**
the wall is the spine, the anti-tip, and the anti-sag, for free.

### 8.2 No off-the-shelf frame fits — build it (~$200)
Commercial LED cabinets are **640×480** (4×3) or **960×960** — *too tall*, waste
rows. A 1-row cabinet = OEM/custom; truss ground-support stands ≈ **$2000** (wrong
proportions). So we build a backbone.

**Governing physics** (`sag = 5WL³/384EI`): an *unsupported* 5.1 m span sags badly
(metric 4040 ≈ 32 mm in the middle). **The decisive lever is intermediate support,
not beam size** — anchor the rail every **~3–4 ft** and *any* reasonable profile
goes dead flat (<0.2 mm).

**CRITICAL — magnets need FERROUS metal.** They will **NOT** stick to aluminum
extrusion, wood, or MDF. Two paths:
- **(A) Screw-mount (simplest):** bolt panels' **M3 corner holes** to the frame with
  T-nuts — **skip magnets entirely.** Recommended for a permanent install.
- **(B) Magnet-mount:** add a **steel sheet** (e.g., 26-ga galvanized on plywood) as
  the substrate, then panels snap on.

| Build | What | Anchoring | ~Cost |
|---|---|---|---|
| **Recommended (stud-mount)** | continuous **80/20 1530** alu extrusion backbone; panels bolt via T-nuts (path A) | lag screws into wall studs every 16–32" (≤1.7 m bays → dead flat) | **~$210** |
| **Renter-friendly** | lightweight backbone (2040 alu or ½" plywood); 26-ga steel sheet if using magnets (path B) | **French cleats + TOGGLER SNAPTOGGLE** toggle bolts (~238 lb each in ½" drywall; wall ≈ 15 kg = 10× margin); ~6 spackle-fillable holes, no stud-hunting | **~$190** |

### 8.3 Budget for
- **Depth:** ~**30–35 mm** behind the LED face (panel ~15 mm + magnet studs 16.6 mm +
  IDC/power connectors). Leave frame clearance.
- **Weight:** ~0.45 kg/panel → **~7 kg panels** + ~1.5 kg PSUs + frame ≈ **12–15 kg**
  total. Trivial for studs; fine for the toggle-bolt variant's 10× margin.
- **Handling:** the strip is **floppy out-of-plane until mounted** — build & carry in
  **2–3 sections**, join on the wall. Laser-level the ledger/rail before final tighten.

### 8.4 Shopping (frame) — buy before the full wall
| Item | Spec | Why |
|---|---|---|
| **80/20 1530** profile (or 2040 for renter variant) | ~17 ft, cut to ~5.1 m + splice plates | the backbone |
| **T-nuts + M3 bolts** | ~80 pc (4 corners × 16 panels + frame) | screw-mount panels (path A) |
| **Lag screws ⅜"×3"** *(stud)* **or TOGGLER SNAPTOGGLE** *(renter)* | ~10 anchors | wall attachment |
| *(magnet path only)* **26-ga steel sheet** | laminate to ½" ply | ferrous substrate |
| **Leveling shims / end brackets** | — | flat & level over 5 m |

**Sources:** Adafruit DIY LED Video Wall (frame), 80/20 deflection calculator
(1530 Ix=1.80 / 1545 Ix=5.69 in⁴), Unistrut P1000 load tables, TOGGLER SNAPTOGGLE
rating, Adafruit #2277 (453 g, 318×158×15 mm, M3) / #4631 mini magnet feet.

---

## 9. ⭐ FINAL OPTIMIZED BUILD — fewest parts, cheapest, NO-SOLDER  (2026-06-29)
Result of a 3-agent optimization pass (power / mounting / prebuilt+control) against
the owner's priorities: **fewest items, cheap, no soldering, buy-don't-build.**
Supersedes the per-part recommendations above where they conflict.

### 9.1 Verdicts
- **Control = $0.** Keep the **Pi 4 + Triple Bonnet** + existing Python. No prebuilt
  1024×32 wall worth buying (custom signage = several× the panel cost, locks you to
  NovaStar video). NovaStar/ESP32 are downgrades. Keep **2×8 center-feed**
  (`parallel=2 chain=8`); cap `--led-pwm-bits 7–8` for refresh headroom. *(The "use
  3 lanes / 6+5+5" idea is rejected — a 3rd chain needs a >50 cm jump cable in a
  single 1-D row; see §5.)*
- **Power = ~$52, no-solder.** **One 8-way ATC automotive fuse block (w/ negative
  bus) per PSU.** Panel **fork terminals land directly** (+5 V on fused studs, GND on
  the common bus). Replaces the 4× Hanson distro + bus bars + crimping. Per-panel
  fusing kept (a 60 A rail will feed a fire into a shorted 4 A panel — fusing is
  consensus-mandatory). Bare stranded wire clamps under screws → no crimp tool.
- **Mounting = MAGNETIC (revised 2026-06-29 — owner bought 100 panel magnets).** Screw
  a magnet into each panel's 6 M3 holes (96 used) → panels **snap onto 2 horizontal
  ferrous rails** at the top-row and bottom-row magnet heights. **Tool-free panel
  removal** (great for QC/service) and **no brackets to design/print.** The earlier
  "reject magnets" call was about a full flat steel *sheet* (heavy/not-flat) — **2
  narrow rails** (Unistrut steel strut, or steel flat bar/angle) avoid that: the rail
  is spine + magnetic surface + wall mount in one. Wall is only ~30 lb assembled →
  anchor the rails every ~2–3 ft (toggle bolts, no studs needed). *Fallback if you skip
  steel: 2020 aluminum extrusion + 3D-printed brackets bolted to the 6 holes (free at
  MIT), keep the magnets as spares.*

### 9.2 ORDER STATUS

**✅ ALL EQUIPMENT ARRIVED (2026-06-29) — on hand:**
- **Control:** Pi 4 · Triple Bonnet · 45 W USB-C · microSD
- **Panels:** 16× CnGear P5 + data ribbons + fork-terminated power pigtails
- **Power:** 2× LRS-350-5 · Double Stack Mount Kit (spare) · 100× Panel Magnets
- **Power dist:** 4× 6-way fuse block · 7.5 A fuses · 10 AWG wire · yellow #8/#10 ring terminals
- **AC + cable mgmt:** 2× AC mains cord · cable ties + self-adhesive tie mounts

**→ Phase 0 (first-light single-panel test) IN PROGRESS. Full-build assembly begins.**

**STILL TO BUY:**
| Item | Qty | ~$ | Source |
|---|---|---|---|
| **2 ferrous rails** (steel — light flat bar/angle **or** Unistrut, ~17 ft ea; magnets need STEEL, not aluminum) | 2 | **FREE** at MIT, else ~$40–70 | `reuse@mit.edu` / Hobby Shop → else Home Depot |
| **Wall anchors / toggle bolts + rail brackets** (or French cleat) | ~8 | $20 | hardware store |
| **3D-printed alignment aids** (end-stops + registration combs — see §9.7) | ~6–10 | **FREE** | print at MIT |
| *(recommended)* **DC clamp meter** UT210E (QC current checks) | 1 | $35 | Amazon |

**Total still-to-buy ≈ $20 essential** (rails + prints free at MIT; only wall anchors)
**+ ~$35 recommended** (clamp meter). If buying steel rails too, add ~$40–70.
*(Power layout LOCKED — pigtail = 55 cm → 4 fuse blocks, PSUs SPLIT one per half. See §9.5.)*

### 9.3 CUT / already covered (do NOT buy)
Hanson distro boards · copper AWG6 trunks · ferrule/crimp tool · fork-lug kit · bus
bars · 3D brackets+extrusion (magnetic route instead) · steel *sheet* · data cables ·
panel power cables · 3rd PSU · NovaStar/ESP32.

### 9.4 No-solder assembly order (screwdriver only)
1. **Power:** fuse block by each PSU → 10 AWG jumpers PSU V+→block input, V−→bus →
   land the panel forks → 14 AWG bond PSU1 V− ↔ PSU2 V−.
   - *Trunk → block STUDS: use a **ring terminal** (gas-tight, set-and-forget for 16 A/24-7).
     ~8 needed (4× +input, 4× V−); crimper free at MIT. **Alt = bare-wire J-hook** under the
     nut — $0/no tool, but stranded wire loosens over thermal cycling → resistance/heat at
     16 A; needs a tight twist + periodic re-tighten. PSU-end is screw-clamp = bare wire OK.*
2. **Frame:** mount 2 ferrous rails to the wall (level, every ~2–3 ft) at the top/bottom
   magnet heights → screw a magnet into each panel's 6 M3 holes → snap panels on,
   butting edges.
3. **Data:** daisy the included ribbons panel→panel, 2 chains of 8, bonnet at center.
4. **Power on** with the PSU switch set to **115 V**.
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

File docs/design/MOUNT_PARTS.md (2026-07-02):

# VESTOR MOUNT — PARTS MANIFEST (buildable)

> **⚠️ REVISED 2026-07-02 by the manufacturing-strategy research → see `MANUFACTURING_PLAN.md`
> (authoritative).** Key changes since this manifest was first written: rails are now
> **steel** (flat bar top + **angle** bottom), not aluminium + a glued strip; the cleat is
> now a **tall C-bracket carrying BOTH rails** (coplanarity datum); the **16 rest-shoes are
> deleted** (the bottom angle's leg is a continuous ledge); rails are center-anchored +
> slotted for thermal. The CAD (`cad/parts/`) already reflects this; the tables below are
> being updated to match — trust `MANUFACTURING_PLAN.md` + the code where they differ.

Every printable/stock part of the mount, modelled as a real CadQuery solid on a
**single shared parameter set** (`cad/parts/mount_params.py`) so nothing can drift
out of alignment. Source: `cad/parts/*.py`. STL (print) + STEP (Fusion) regenerate
into `cad/out/` (gitignored). Companion specs: `SETUP_SPEC.md` (the wall),
`MOUNT_DESIGN.md` (why this design). All dims mm. Frame: X = along wall, Y = depth
into room (0 = wall surface), Z = vertical (0 = piece top, −down).

## The idea in one paragraph

Two aluminium **bars** run the full 5.1 m at the panels' two M3 hole rows. The
**top bar** hangs from the wall's top groove on printed **cleats** (all vertical
load → compression into solid wood, zero new holes). The **bottom bar** is captured
in the wall's bottom groove by printed **anti-swing feet**. Thin **steel strip** on
the front of both bars is the magnet target; each panel's six **magnet screws** snap
it on and, being individually adjustable, dial out any residual waviness — so the
bars need only be *roughly* straight. Panels **butt each other** from the corner to
self-space in X, and each rests on a printed **shoe** so magnets never carry weight
in shear. The brain lives in the **corner** on the side wall; the PSUs sit in vented
**cradles** off the mount.

## Full cross-section — all parts, one frame

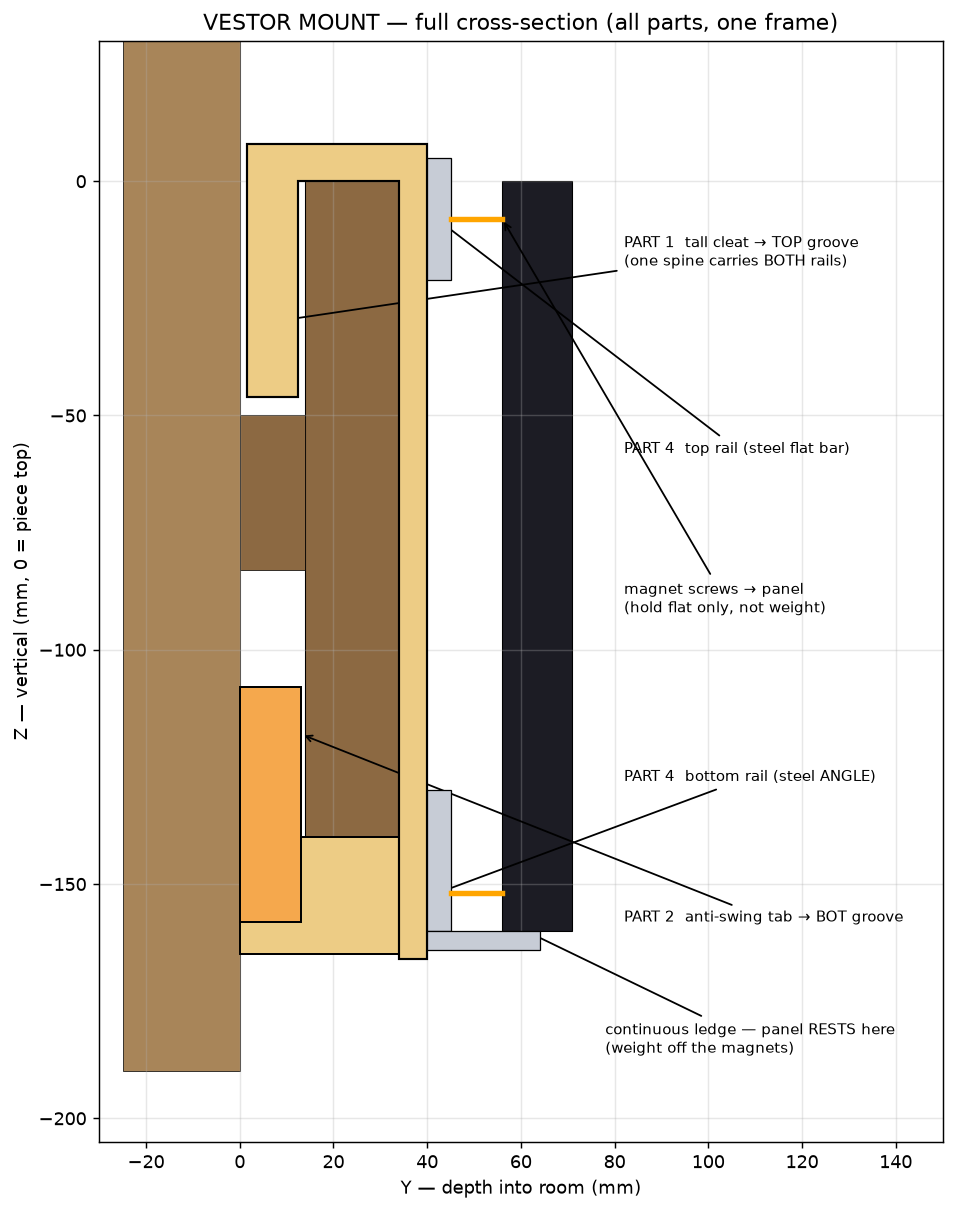
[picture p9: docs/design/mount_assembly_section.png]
assembly section


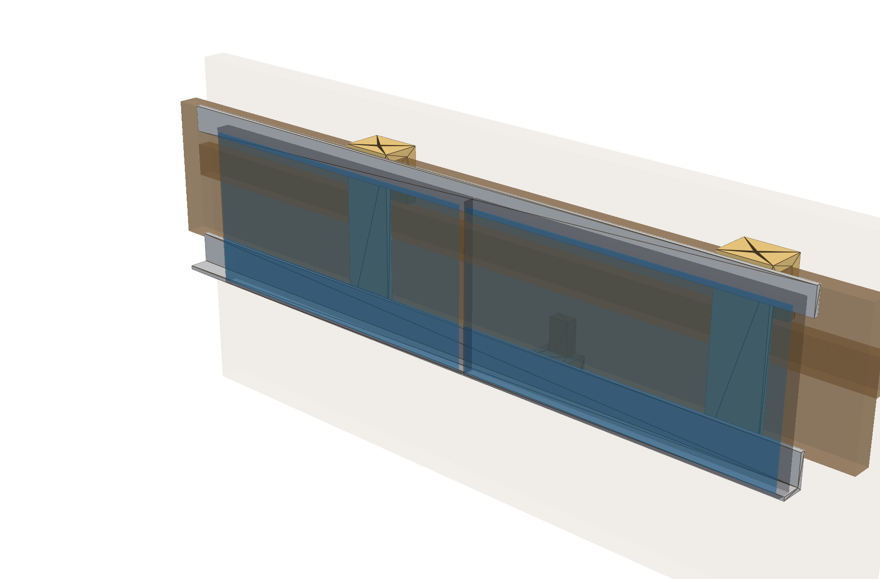
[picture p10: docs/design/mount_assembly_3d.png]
assembly 3D


*Verified: an automated boolean `collide_check()` confirms no bracket shares solid
volume with a panel or the wooden piece (it already caught + fixed a 2 mm upright
interference).*

## Parts

| # | Part | File / STL | Qty | Fn | Load | Material |
|---|---|---|-----|----|---|---|
| 1 | **Top cleat** | `top_cleat.py` | 13 (1/station) | Hangs everything from the TOP groove; carries the top bar | Full weight (compression into wood) | PLA now → **PETG/ASA** later |
| 2 | **Anti-swing foot** (base + slide-up tab) | `anti_swing_foot.py` | 7 (every 2nd station) | Wedges a tab UP into the BOTTOM groove; carries the bottom bar | Light (anti-swing only) | PLA |
| 3 | **Panel rest shoe** | `panel_rest.py` | 16 (1/panel) | Ledge under each panel bottom → creep stop + sets height | Light (panel weight relief) | PLA |
| 4 | **Bars + steel strip** | `bars.py` (stock) | 4 bar cuts + 2 steel runs | Continuous flat reference + magnet target | Structural (spread) | 6063-T5 alu + adhesive ferrous steel |
| 5 | **Corner enclosure** | `corner_enclosure.py` | 1 | Hangs Pi 4 + Triple Bonnet from the LEFT-wall groove | Light | PLA |
| 6 | **PSU cradle** | `psu_bracket.py` | 4 (2/PSU) | Holds each LRS-350-5, raised + vented, off the mount | Light | PLA |

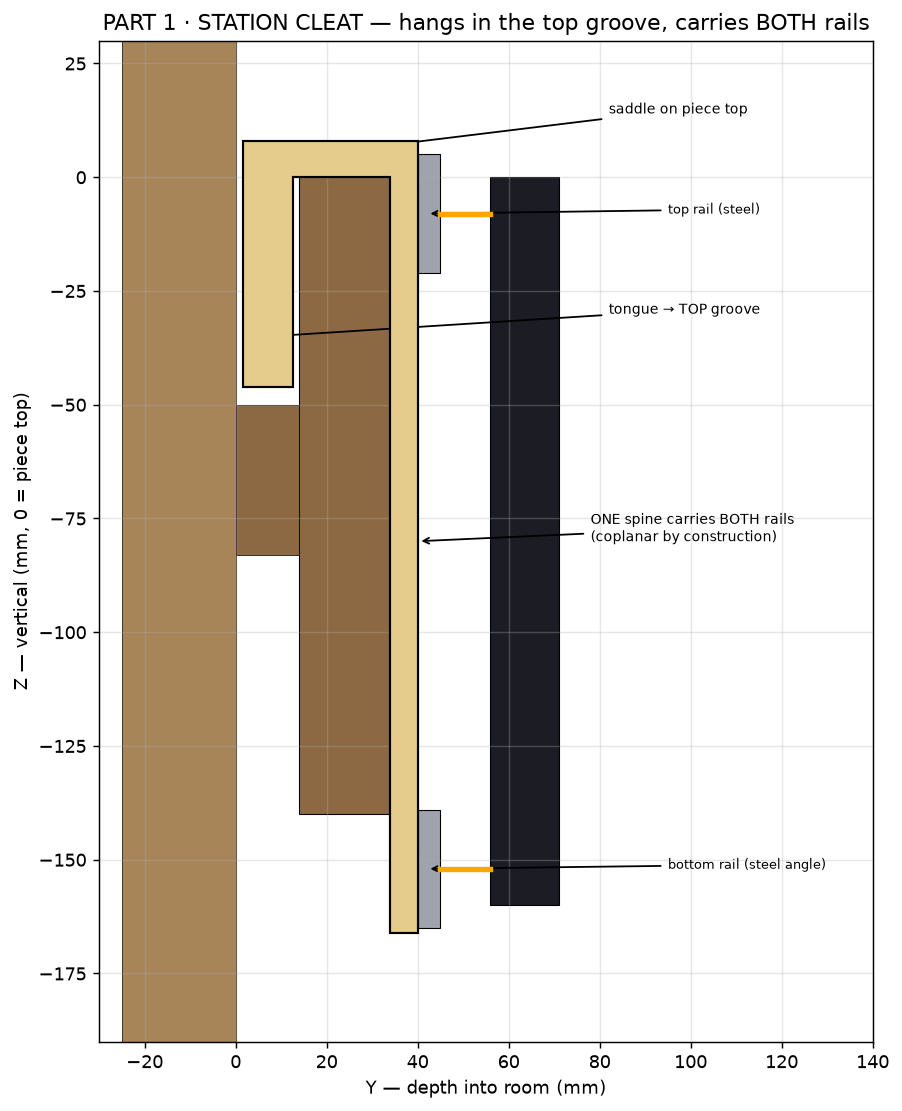
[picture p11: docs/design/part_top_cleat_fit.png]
### 1 · Top cleat  
Upside-down hook: **tongue** (11 mm in the 14 mm groove, 46 mm deep → rests near the
50 mm floor) + **saddle** on the piece top (resists the forward-tip moment) +
**upright** flush on the piece front (Y 34→40; the piece face shares the load). Two
**M4 heat-set inserts** in the upright bolt the top bar; one saddle set-screw levels
it. Bbox 50 × 39 × 54. *Print the upright vertical-ish so layer lines don't split
under the pull; over-built in PLA, reprint in PETG/ASA for the long term.*

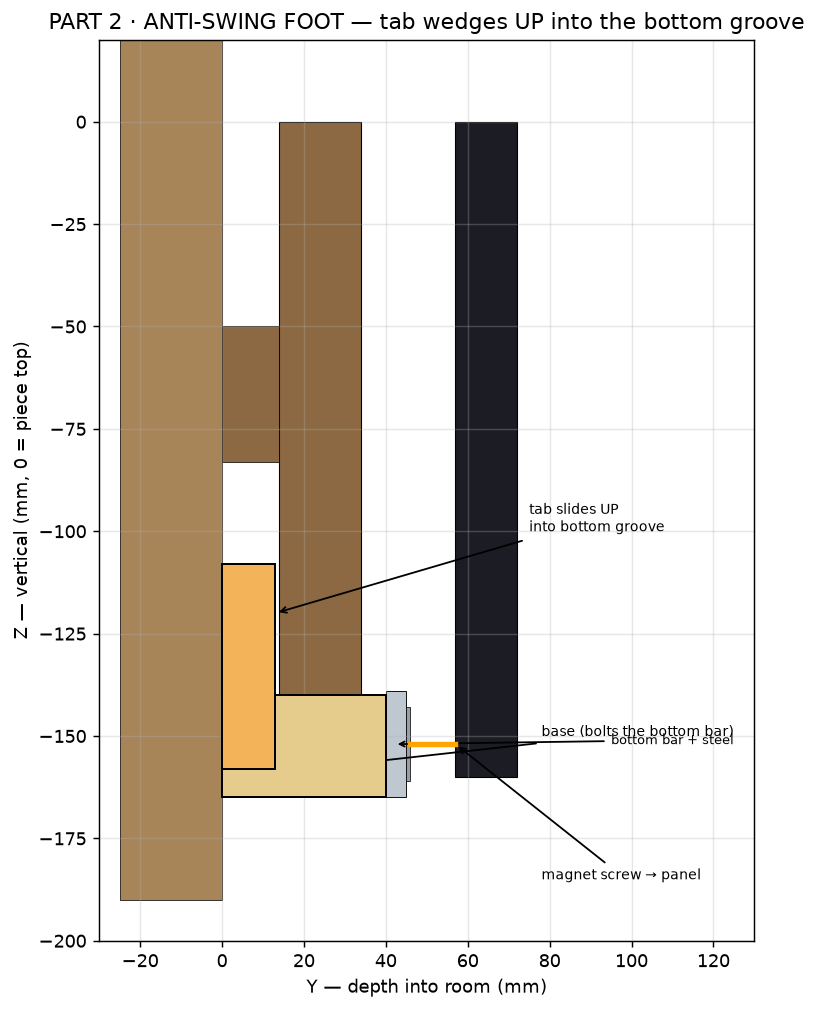
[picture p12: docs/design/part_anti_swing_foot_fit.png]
### 2 · Anti-swing foot  
The bottom groove opens **upward**, so its tab can't drop in with the assembly (it
would hit the solid attach band). The **base** bolts the bottom bar and sits entirely
below the piece; after hanging, you **slide the tab up** ~32 mm into the groove and
pinch it with a side M4 set-screw. Base 40 × 40 × 25, tab 20 × 12 × 50.

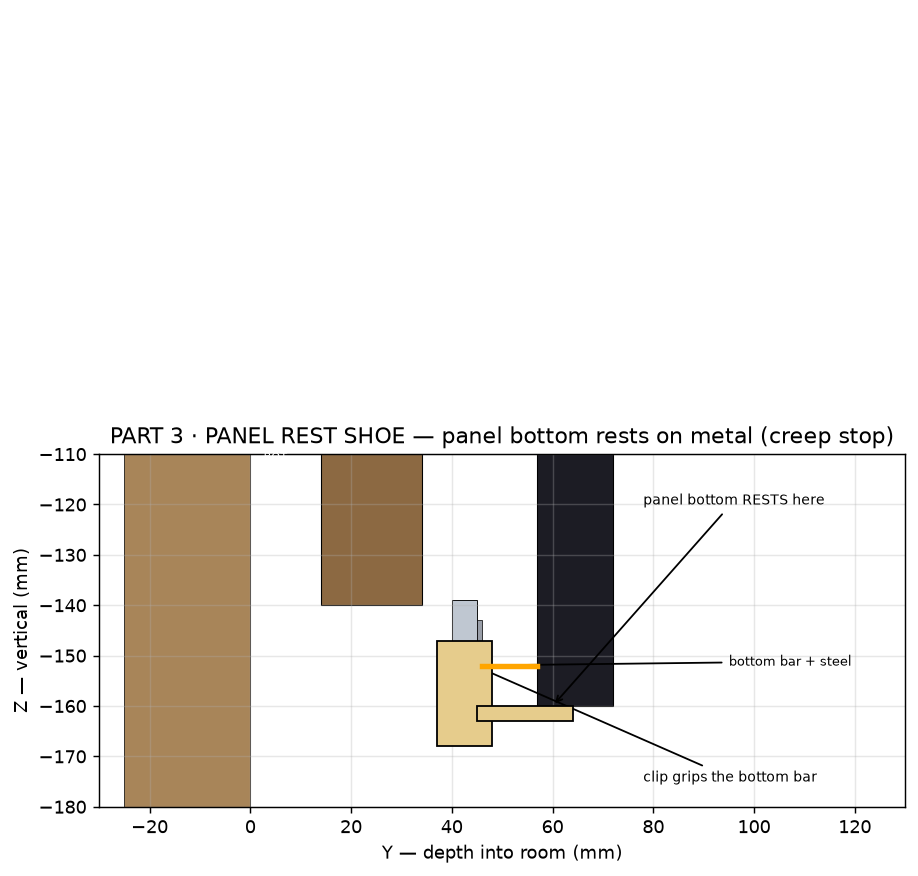
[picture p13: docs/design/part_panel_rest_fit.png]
### 3 · Panel rest shoe  
Clips the bottom bar's lower edge; a ledge at Z = −160 catches each panel's bottom
edge below the magnet row. Magnets then only hold the panel *flat*, not *up*. 40 × 27 × 21.

### 4 · Bars + steel (cut list)
`26 × 5 mm` 6063-T5 flat bar: **4 × 2559 mm** (2 per rail × top+bottom); joints land
at the middle station so a cleat/foot splices them (no splice plate). Steel magnet
strip (adhesive ferrous, ~20 mm × ~1 mm): **2 × 5118 mm**. Drill M4 at all 13 stations.

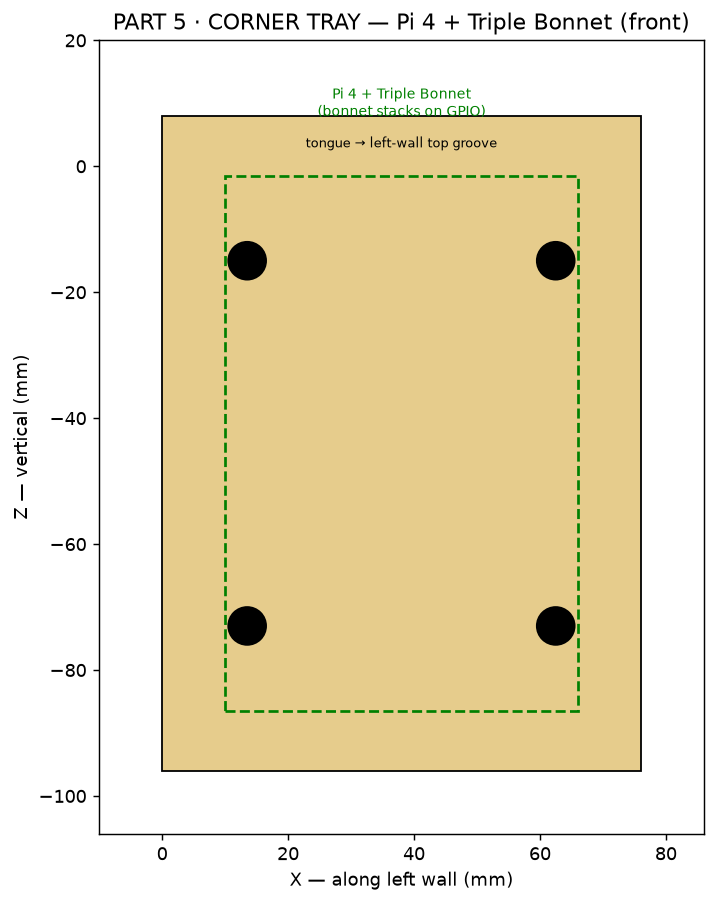
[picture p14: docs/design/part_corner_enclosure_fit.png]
### 5 · Corner enclosure  
Open, vented tray, hangs on the left-wall top groove (same tongue). Four M2.5 bosses
on the Pi 4's 58 × 49 pattern; Bonnet stacks on the GPIO; HUB75 ribbon → panel 0. 76 × 39 × 104.

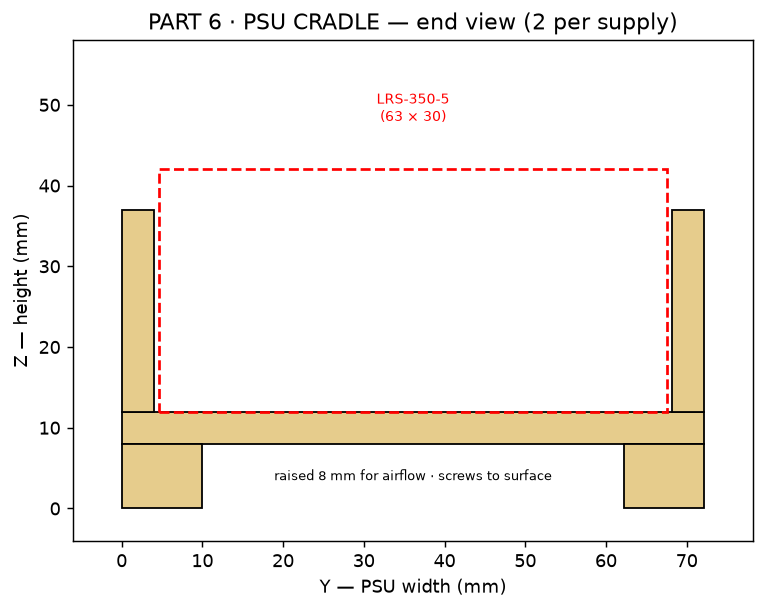
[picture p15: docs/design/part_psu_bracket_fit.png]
### 6 · PSU cradle  
LRS-350-5 (215 × 63 × 30) drops in; corner nubs + zip-tie retain; raised 8 mm and
vented; screws to a surface (spot TBD on-site). 34 × 72 × 37, two per PSU.

## Stackup (Y, depth off the wall)
`piece front 34 → cleat/foot face 40 → alu bar 45 → steel 46 → +11 magnet → panel back 57 → panel face 72`
→ panels float **~38 mm proud** of the trim (generous ribbon room; can tighten to
~28 mm by seating the cleat face flush at 34 if a slimmer look is wanted).

## Install sequence
1. **Drill + splice the bars**, stick on the steel strip. Bolt the **cleats** to the
   top bar and the **feet bases** to the bottom bar at their stations.
2. **Drop the top bar in** — cleat tongues into the top groove; saddles rest on the
   piece; set-screws level it. The whole frame now hangs, zero wall holes.
3. **Slide each foot tab up** into the bottom groove; pinch the set-screws → captured.
4. Clip the **rest shoes** under each panel position.
5. Screw **magnet feet** into all 6 M3 holes of every panel.
6. **Hang panels** from the corner, butting each to its neighbour; drop each onto its
   shoe; magnets snap to the steel. Dial the 6 screws per panel until the face is
   coplanar with neighbours.
7. Hang the **corner enclosure** on the left-wall groove; wire the Pi/Bonnet, run the
   HUB75 chain of 16 rightward; seat the **PSUs** in their cradles; power up.

## Bill of materials (mount)
- 6063-T5 alu flat bar 26 × 5 — ~10.3 m (4 cuts). Steel magnet strip — ~10.3 m.
- **Printed (free PLA @ Hobby Shop):** 13 cleats, 7 foot-bases + 7 tabs, 16 shoes,
  1 enclosure, 4 cradles (~1 kg total).
- M4 bolts + **M4 heat-set inserts** (2 × 13 = 26 in cleats), M4 set-screws (feet + saddles),
  M2.5 for the Pi. **Magnet screws:** 96 (own; have 100).
- Reprint the load path (cleats) in PETG/ASA when the H2S is stocked — PLA creeps.

## Still to confirm on-site (non-blocking)
- Real panel **M3 hole positions** (the −8 / −152 rows + column pitch) — the one CAD estimate.
- Groove widths **after finish** (tongue/tab clearances), uniform over 5.1 m.
- Left-wall groove identical (for the enclosure); wall material where the PSUs mount.

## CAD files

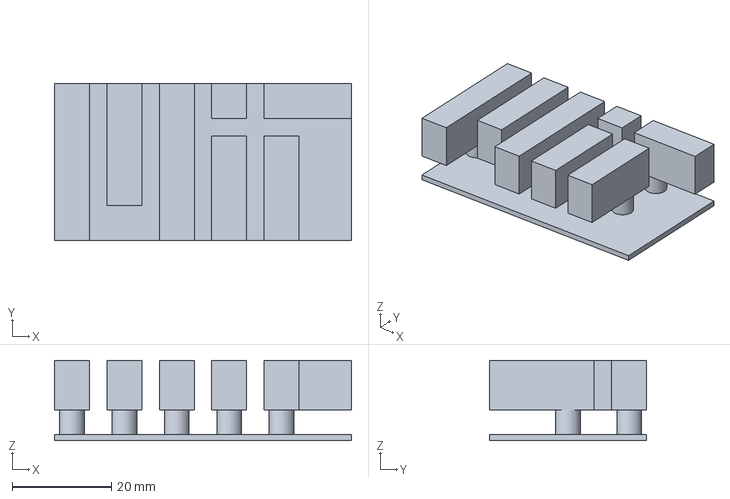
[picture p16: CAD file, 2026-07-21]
cad/print_profiles/Vestor_Light_P2S.3mf
60.0 x 31.8 x 16.2 mm

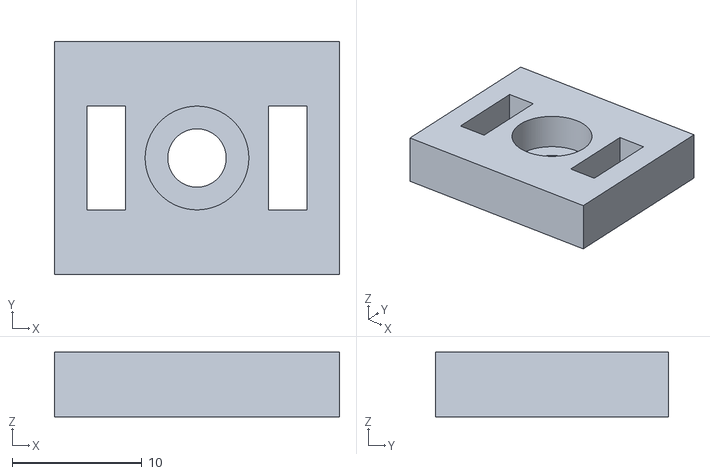
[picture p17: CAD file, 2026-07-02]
cad/print_stl/08_cable_clip.stl
22.0 x 18.0 x 5.00

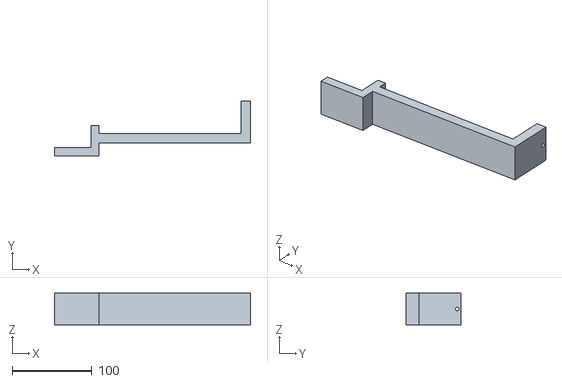
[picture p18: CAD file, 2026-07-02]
cad/print_stl/07_gap_hanger.stl
246.0 x 69.5 x 40.0

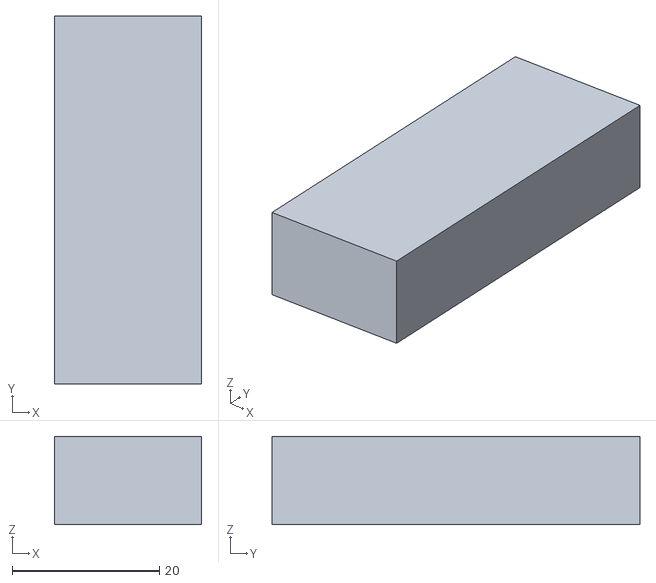
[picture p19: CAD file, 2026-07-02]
cad/print_stl/02_foot_tab.stl
20.0 x 50.0 x 12.0

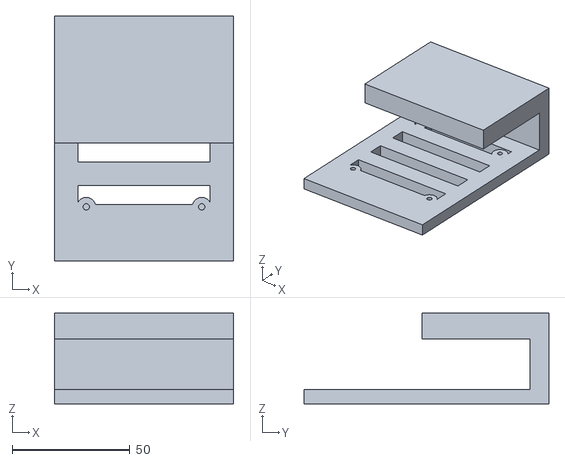
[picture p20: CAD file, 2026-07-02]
cad/print_stl/05_center_enclosure.stl
76.0 x 104.0 x 38.5

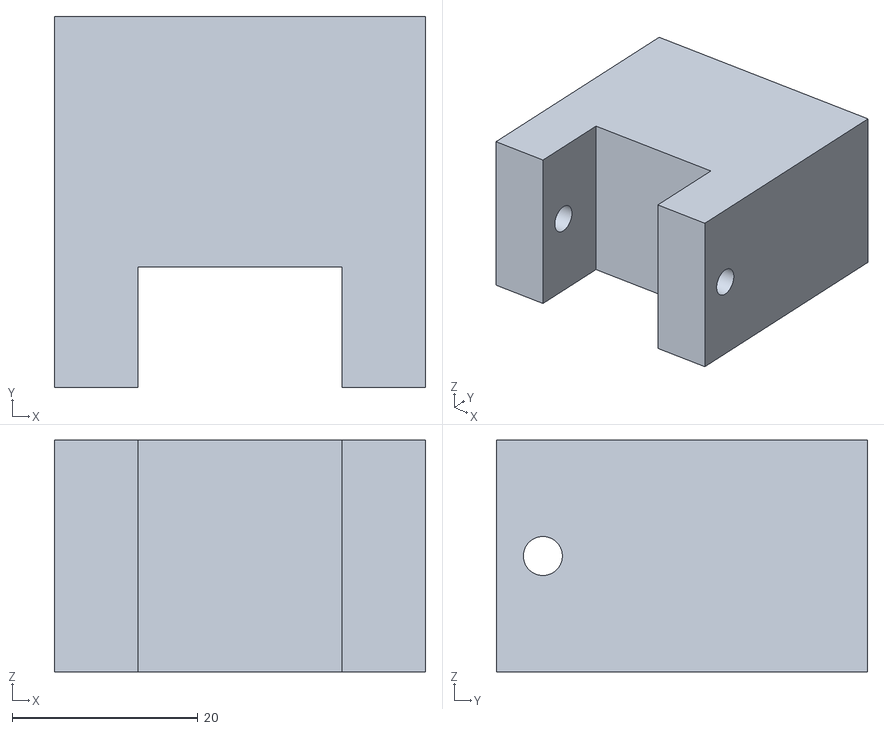
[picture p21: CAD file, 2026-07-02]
cad/print_stl/02_foot_base.stl
40.0 x 40.0 x 25.0

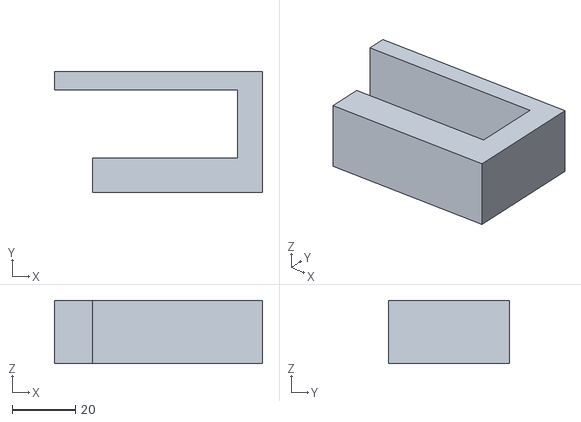
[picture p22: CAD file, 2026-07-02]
cad/print_stl/00_coupon_tongue.stl
66.0 x 38.5 x 20.0

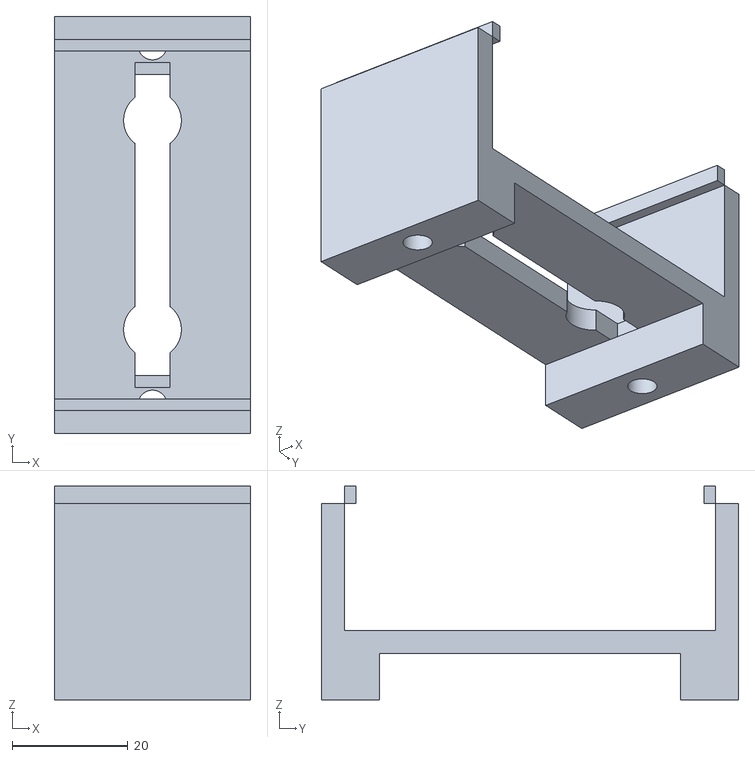
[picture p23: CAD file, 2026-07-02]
cad/print_stl/06_psu_cradle.stl
34.0 x 72.2 x 37.0

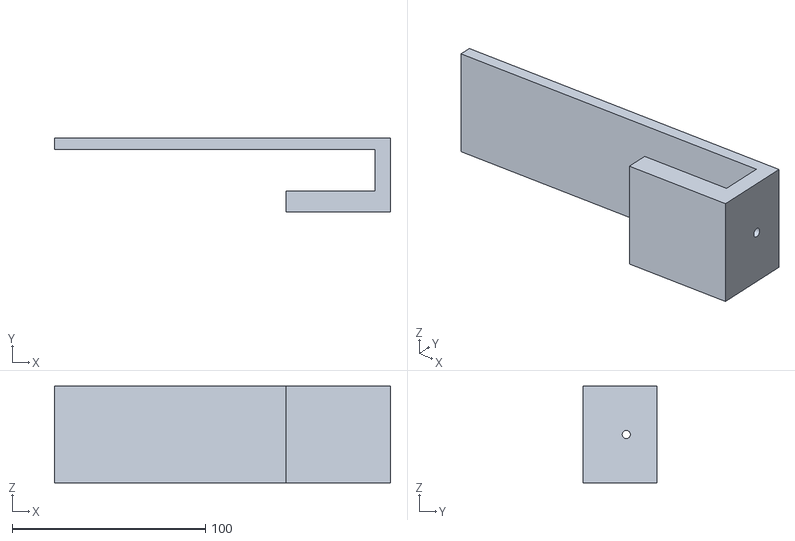
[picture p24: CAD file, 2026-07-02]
cad/print_stl/01_top_cleat.stl
174.0 x 38.5 x 50.0

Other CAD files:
cad/print_profiles/Vestor_Light_H2S.3mf
cad/print_profiles/Vestor_Structural_P2S.3mf
cad/print_profiles/Vestor_Structural_H2S.3mf

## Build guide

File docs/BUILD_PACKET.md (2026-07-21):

# VESTOR — BUILD PACKET (print & carry)

One self-contained sheet for the Hobby Shop + install. Everything here is decided; the
deep detail lives in `MANUFACTURING_PLAN.md`, `ELECTRICAL.md`, `HARDENING.md`,
`design/BACK_OF_HOUSE.md`, `design/PRINTING.md`. **Do Phase 0 (measure) before cutting steel.**

**What you're building:** a 16× P5 64×32 LED wall, one row 5120 mm × 160 mm, hung from the
wall's built-in top groove (zero new wall holes). Center-fed 2×8 data; split 2× LRS-350-5 power;
all electronics + wiring hidden in the ~22.5 cm ceiling gap behind a vented valance.

---

## ▢ PHASE 0 — MEASURE + FIT-TEST (at the wall, before you cut steel or batch-print)

### A. Measure the printed coupon itself (do this first — it separates printer error from wall variance)
- ▢ **Tongue blade thickness** with calipers, 2–3 spots → **should be 11.0 mm.**
  If it reads 11.2–11.4, the printer is running oversize (normal: elephant foot / over-extrusion)
  and I compensate in CAD rather than blaming the groove.
- ▢ **Tab thickness** → should be **13.0 mm** (nominal, before clearance).

### B. Measure the actual grooves (calipers, or feeler gauges)
- ▢ **Top groove WIDTH at ≥5 points** along the 5.1 m → record the **narrowest** (that's what governs).
- ▢ **Top groove DEPTH** (how far a probe drops before bottoming) — expected ~50 mm.
- ▢ **Bottom groove width + depth** — expected 18 × 57 mm.
- ▢ Confirm grooves are unbroken (no outlets/nails); note the AC outlet at the right end.

### C. Fit-test the TONGUE coupon in the TOP groove (the real answer)
1. ▢ **Drop it in.** It should seat **under its own weight** — no forcing, no hammering.
2. ▢ **Saddle contact:** does the flat saddle land on the piece top, or is there a **gap under it**?
   A gap = the tongue is bottoming on the groove floor first (groove shallower than 50 mm) → the
   saddle can't bear, and I shorten the tongue. **This is the most important single observation.**
3. ▢ **Spine contact:** is the front face flush against the piece front, or held off it?
4. ▢ **Play:** seated, rock it front-to-back. **Target ~0.5–1.5 mm total.**
   *No feeler gauges?* Printer paper ≈ 0.1 mm, business card ≈ 0.3 mm — slide them in the gap and count.
5. ▢ **Repeat at 2–3 spots** along the wall (grooves vary; the tightest one governs).

### D. Fit-test the TAB in the BOTTOM groove
- ▢ Slide it **UP** into the groove: should go smoothly, not forced. Falling back out is **fine**
  (a set-screw pinches it in the real build) — **binding is not.**

### ▢ Report back these six things
`printed tongue thickness` · `narrowest top-groove width + depth` · `bottom-groove width + depth` ·
`fit verdict (forced / slight play / loose)` · `saddle sits flat? Y/N` · `spine flush? Y/N`
→ I retune the tongue/tab clearances + the rail drill layout, then you cut steel and batch-print.

---

## ▢ SHOPPING / BRING LIST

**On hand — just bring:**
▢ 16 panels + ribbons ▢ 2× LRS-350-5 + 2 AC cords ▢ 4× 6-way fuse blocks ▢ 7.5 A fuses (16+)
▢ 10 AWG CCA red/black trunk (25 ft) ▢ copper RV pigtails ▢ yellow ring terminals ▢ 100 magnet feet
▢ Pi 4 + Triple Bonnet + 96 W USB-C charger ▢ 100 cable ties + (adhesive mounts — light dressing only)

**Steel (rails):**
▢ Mild-steel **flat bar 25 × 5 mm**, 2 × ~2.6 m (top rail) — Hobby Shop stock or metal supplier, **bare**
▢ Mild-steel **angle 25 × 25 × 3 mm**, 2 × ~2.6 m (bottom rail = magnet target + panel rest ledge), **bare**

**Fasteners / hardware:**
▢ **M4 brass heat-set inserts** (100-pack) ▢ M4 bolts 10–16 mm (~60) ▢ M4 grub/set screws 8–12 mm (~50)
▢ M2.5 screws + 4 inserts (Pi) ▢ **M3.5 Belleville or Nord-Lock washers** + flat washers (PSU studs)
▢ M4 screws for the cable clips → strip

**Electrical hardening (the reliability pass):**
▢ **Bootlace ferrules** + ferrule crimper ▢ **dielectric/contact grease** ▢ bag of **clip-on ferrite cores**
▢ **bulk low-ESR caps** ~2200–4700 µF ≥16 V (×2–4, for the center feeds) ▢ **16 AWG wire** (V− bond ~5.5 m + Bonnet-GND ~1 m)
▢ **Ethernet cable/run to the Pi** ▢ **Noalox anti-oxidant** *(only if keeping the CCA trunk — else swap the 7 m to copper)*
▢ latching JST-VH housings *(optional, for the pigtail plugs)*

**Cabling / valance / strip:**
▢ **backer strip** — aluminium angle 40×40 or 1×3 pine, ~5.1 m ▢ **valance** — MDF/1× pine board ~5.1 m × ~0.25 m, paintable
▢ spiral-wrap (DC loom) + cable sleeving (HUB75 spine)

**Spares (buy the panels NOW with the order):**
▢ **1–2 same-batch P5 64×32 panels** ← must be same batch. Later: spare PSU, 80 mm fan, ribbons, Bonnet, Pi + cloned SD.

**Tools:** ▢ torque driver (in·lb / kgf·cm) ▢ crimper ▢ soldering iron (inserts) ▢ clamp meter ▢ laser level or string + feeler gauge ▢ IR thermometer

---

## ▢ PRINT LIST (Bambu H2S, PLA, chamber door OPEN) — pre-oriented STLs in `cad/print_stl/`
**Coupons FIRST** (check the real groove fit before batching):
▢ `00_coupon_tongue` ×1 ▢ `02_foot_tab` ×1  → test in grooves; if off, I tweak params + you reprint.

**Then the batch (~1 kg PLA total):**
▢ `01_top_cleat` ×13 ▢ `02_foot_base` ×7 + `02_foot_tab` ×7 ▢ `05_center_enclosure` ×1
▢ `06_psu_cradle` ×4 ▢ `07_gap_hanger` ×6 ▢ `08_cable_clip` ×40

**Settings:** 0.2 mm layer · **4–5 walls · 15–20 % gyroid infill** · supports **off** (except `05` = light) ·
**brim** on cleat/tab/hanger · **keep the exported orientation** (cleat + hanger print on-side — do NOT auto-rotate).
Optional later: reprint the 13 cleats in **PETG/ASA** for zero creep worry.

---

## ▢ CUT & DRILL LIST
**Steel (bandsaw/cold saw + drill press):**
▢ Top rail: 25×5 flat bar → **2 × 2559 mm** (splice at the center station)
▢ Bottom rail: 25×25×3 angle → **2 × 2559 mm**
▢ Drill **M4 clearance holes at 13 stations × 2 per rail** (X per your measured M3 columns); **slot all but the center station** (thermal). Deburr; keep magnet faces bare.

**10 AWG trunk (cut with service-loop slack included):**
▢ PSU-L → block A ~**1.1 m** ▢ PSU-L → block B ~**2.4 m** ▢ PSU-R → block D ~**1.1 m** ▢ PSU-R → block C ~**2.4 m**
▢ 16 AWG V− bond ~**5.5 m** + Bonnet-GND ~**1 m** (separate wire, not the 10 AWG)

**Wood/strip (saw):** ▢ backer strip ~5.1 m ▢ valance ~5.1 m (cut a **top vent reveal + low intake slot** = chimney)

---

## ▢ HOBBY-SHOP SESSION (order of operations)
1. ▢ **Start the prints first** (long pole, unattended) — coupons, then the batch across ~3 H2S plates.
2. ▢ **Saw** the 4 steel rail pieces + backer strip + valance to length.
3. ▢ **Drill + slot** the rail bolt holes (to your measured M3 columns).
4. ▢ **Set heat-set inserts** (soldering iron) into the 13 cleats + the enclosure.
5. ▢ **Crimp** ring terminals (trunk) + ferrules (stranded ends); **stick nothing structural with adhesive.**

---

## ▢ INSTALL SEQUENCE (on-site) — full detail in `BUILD_WALKTHROUGH.md`
1. ▢ **QC all 16 panels** on the Pi (`demo`) before mounting; log 1–16, set spares aside.
2. ▢ Bolt cleats + feet to the rails; **splice rails at center; slot all but the center bolt.**
3. ▢ **Drop the 13 cleats into the top groove**; **laser-line + shim their faces flat to ≤0.3 mm** ← the precision hour, before any panels.
4. ▢ Bolt on the two steel rails (anchor center, slotted ends); wedge the anti-swing feet into the bottom groove.
5. ▢ Hang the **gap hangers** + backer strip in the ceiling gap; mount PSUs at the ends (vents clear), Pi+Bonnet at center, 4 fuse blocks distributed.
6. ▢ Screw magnet feet into all 6 M3 holes of each panel; **hang panels from center outward**, resting on the ledge, butting neighbors; magnets snap on.
7. ▢ **Data:** Bonnet → center panels 8 & 9, chain 8 each way; **retain every connector housing + first-anchor strain relief + service loops.**
8. ▢ **Power:** star trunks → fuse blocks → per-panel 7.5 A → pigtails; **bond both V− + Pi GND at one node, never V+**; decoupling caps at the feeds; trim ~5.2 V under load.
9. ▢ **Ethernet to the Pi**; dress DC + ribbon in separate looms; close the vented valance.
10. ▢ Power on → config below → tune.

---

## ▢ QUICK-REFERENCE CARD
- **Fuse:** 7.5 A per panel (16). **Brightness:** ≤ 50.
- **Data config:** `--led-chain=8 --led-parallel=2 --led-pixel-mapper="U-mapper;Rotate:180" --led-pwm-bits=11 --led-slowdown-gpio=2` · `dtparam=audio=off` · `isolcpus=3` · disable WiFi, use Ethernet.
- **Ground:** bond both PSU V− + both chain returns + Pi/Bonnet GND at ONE node. **Never tie the two V+.**
- **Torque:** LRS-350 M3.5 studs **8–10 kgf·cm** (~7–8.5 in·lb). **Re-torque at ~30 days, then annually.**
- **PSU trim:** ~5.1–5.2 V measured at the farthest panel under load (stay ≤ 5.5 V).
- **Do-not-forget:** service loops in every cable · screw-down (not adhesive) anchors · rolled ribbon folds (no crease) · same-batch spare panels bought with the order.

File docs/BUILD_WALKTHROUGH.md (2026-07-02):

# VESTOR — FULL BUILD WALKTHROUGH (16-panel wall)

The master checklist from parts to a lit, running wall. Each stage points to the deep
doc for detail. Frame/mount = `design/MANUFACTURING_PLAN.md` + `design/MOUNT_PARTS.md`
+ `design/PRINTING.md`; wall geometry = `design/SETUP_SPEC.md`; electrical = `INVENTORY.md`
§9 + `HARDWARE.md`; operate = `RUNBOOK.md`. Phase 0 (one panel, first light) is already ✅.

Order matters: **fabricate → QC → hang the frame flat → panels → power → software.**

---

## STAGE 0 · Measure + gather (do before printing the batch)
- [ ] **Measure the real grooves** at ~5 points along the 5.1 m: top-groove width/depth,
      bottom-groove width/depth, and that they're uniform + unbroken (no outlets/nails).
      Compare to the CAD (top 14×50, bottom 18×57). Tell me any delta — I retune clearances.
- [ ] **Measure a real panel's M3 holes** (the two rows' Z + the 3 columns' X pitch) off one
      panel. The rail drill positions key off this — send me the numbers if they differ from
      the estimate (rows at −8/−152 mm, ~144 mm apart).
- [ ] **Gather stock/hardware:** free PLA (H2S); steel flat bar + angle (rails); M4 bolts +
      **52 M4 heat-set inserts** + M4 jack/set screws; M2.5 for the Pi; the **100 magnet feet**;
      2× LRS-350-5 + 2 AC cords; 2× 8-way ATC fuse blocks + 7.5 A fuses + 10/14 AWG wire + forks;
      Pi 4 + Triple Bonnet; the 16 panels + their ribbons/pigtails. (Buy-list status: `INVENTORY.md`.)

## STAGE 1 · Print the mount parts (H2S, PLA — chamber door OPEN for PLA)
- [ ] **Coupons FIRST:** print `00_coupon_tongue.stl` + `02_foot_tab.stl` → test in the real
      grooves (want a slight ~0.5–1 mm wiggle). If off, I tweak `mount_params.py` + you reprint.
- [ ] **Batch:** 13× `01_top_cleat`, 7× `02_foot_base`, 7× `02_foot_tab`, 1× `05_corner_enclosure`,
      4× `06_psu_cradle`. Keep the exported orientation (cleat on its side). Settings: `PRINTING.md`
      (4–5 walls, 15–20 % infill, supports only on the enclosure). ~0.9 kg total, ~3 H2S plates.
- [ ] **Heat-set inserts:** press 52× M4 into the cleats (4 each) + M2.5 into the enclosure with a
      soldering iron. (Optional creep-proof upgrade later: reprint the 13 cleats in PETG/ASA on the H2S.)

## STAGE 2 · Fabricate the two steel rails
- [ ] **Cut** (bandsaw/cold saw): TOP = low-carbon steel flat bar ~26×5 mm, 2×2559 mm. BOTTOM =
      steel angle ~30×24×4 mm, 2×2559 mm (leg = magnet target, other leg = panel rest ledge).
- [ ] **Drill** M4 at each of the 13 stations × 2 per rail, positioned to your measured M3 columns.
      **Slot** every hole except the center station in X (lets the 5 m rail expand ~1.2 mm/20 °C).
- [ ] Splice each rail's two halves at the center station (a cleat bridges the joint). **Deburr.**
      Keep the **magnet faces BARE** (no paint/zinc). Optional: a thin wax on the back/edges vs rust.

## STAGE 3 · QC all 16 panels (before they go on the wall)
- [ ] Run each panel on the Pi (`demo -D3/-D4/-D5`) one at a time. Dead IC = a 16-px column out;
      dead row = a horizontal line. **Log 1–16, keep 2–3 as spares**, RMA any dud with video. (`INVENTORY.md` §7.3)

## STAGE 4 · Prep panels + electronics (bench work)
- [ ] Screw **6 magnet feet into every panel's M3 holes** (96 total). Don't over-drive (rear parts).
- [ ] Build the **corner brain:** Pi 4 + Triple Bonnet stacked on the GPIO, mounted in `05_corner_enclosure`.
- [ ] Seat the **2 PSUs** in their cradles; pre-wire each PSU → its 8-way fuse block (10 AWG trunk,
      common-negative bus, 7.5 A fuses). Set the PSU input switch to **115 V**. (`INVENTORY.md` §9)

## STAGE 5 · Hang the frame — THE PRECISION STAGE (get this flat)
- [ ] **Drop the 13 cleats** into the TOP groove, ~427 mm apart; saddles rest on the piece; snug the
      Z set-screws. Zero wall holes.
- [ ] **Laser-level the cleat faces:** run a laser line (or taut string) across all 13 front faces and
      **jackscrew/shim each cleat until every face is in one vertical plane, ≤0.3 mm.** ← do this now,
      before any rail or panel. This one step is what makes the seams disappear.
- [ ] **Bolt on the two steel rails:** anchor the **center** station first, then work outward with the
      slotted holes snug-but-sliding. Splice the halves at center. Verify both rails are flat, parallel
      (144 mm apart), and their magnet faces are coplanar (same Y).
- [ ] **Wedge the anti-swing tabs** up into the BOTTOM groove (between cleats) and pinch the set-screws.

## STAGE 6 · Hang the panels
- [ ] Start at the **corner**. Panel 0: rest its bottom edge on the angle ledge, butt it to the corner,
      let the magnets snap to both rails. Panel 1: **butt tight to panel 0** (they self-space), rest,
      snap. Repeat across all 16 (the +2 mm slack lands at the far end).
- [ ] **Chain the HUB75 ribbons: single chain of 16 from the corner** (panel 0→1→…→15). All ribbons stay short.
- [ ] **Coplanarity trim:** the flat rail does most of it — set each panel's 6 magnet screws to a uniform
      depth with a gauge, then nudge any proud corner. Sight down the face under raking light.

## STAGE 7 · Power + data → first light of the full wall  (full spec: `ELECTRICAL.md`)
- [ ] **Split the PSUs — one per half**, each on its **own AC outlet** (inrush ~60 A). Mount with 10–15 cm
      vent clearance; tie each **FG to earth**. Trim each to **~5.15 V** (measured at the farthest panel).
- [ ] Distribute the **4 fuse blocks** (one per 4-panel group). Feed each block its own **10 AWG** copper
      run straight from the PSU (**star**). Land each panel's pigtail on **its own 5 A fuse** (16 total —
      **NOT the 7.5 A**, too high for the thin CCA pigtails). Crimp CCA + anti-oxidant paste; re-torque.
- [ ] **Ground:** bond both PSU **V−** + the Pi GND at ONE point (a negative bus bar). **Never tie the two V+.**
- [ ] Connect the Bonnet's HUB75 output → panel 0; power up the Pi. **Full-wall first light.**

## STAGE 8 · Software
- [ ] **Config the single chain of 16:** `--led-chain=16 --led-parallel=1`, `pwm_bits=9` (~111 Hz),
      `BRIGHTNESS ≤ 50`, `panel_type=""` (FM6124HJ), regular mapping. **Remove the old snake / 180° left-half
      flip** in `display/__init__.py`, and revert the Phase-0 Port-3 shim. (`ROADMAP.md`, `RUNBOOK.md`)
- [ ] **Port the multi-zone app** (weather °C/°F + flights + Bluebikes + MIT shuttle) onto the 1024×32 wall —
      this is the real Phase-1 software build (design lives in `sim/` + the design docs). Tune + verify health.

## STAGE 9 · Finish + harden (optional)
- [ ] Cable management; optional smoke-gray acrylic front tint (deepens blacks, hides shade variation);
      always-on hardening (systemd watchdog, remote power-cycle plug). (`GEAR.md`, `ROADMAP.md`)

---

### The 3 things that most decide success
1. **STAGE 5 laser-leveling** — flat frame first = invisible seams. Everything downstream rides on it.
2. **STAGE 0 measurements** — the grooves + real M3 positions are the only unknowns; measure before you cut/batch.
3. **STAGE 3 QC** — find dead panels on the bench, never after they're mounted and wired.

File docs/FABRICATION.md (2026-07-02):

# FABRICATION — 3D-printed parts for the Vestor wall

Notes on how to fabricate the wall's mounting/enclosure parts now that the owner
has **MIT Hobby Shop** access. Companion to `docs/INVENTORY.md` §8 (the 80/20
metal backbone plan) and `docs/design/WALL_PROFILE.md` (the wooden mounting rail).
Written 2026-07-02.

## Machines available (Hobby Shop — confirmed with Charlotte Reiter, 2026-07-02)

Three printers (the Stratasys uPrint is **gone**):

| Printer | Tech | Build volume | Notes |
|---|---|---|---|
| **Bambu H2S** | FDM CoreXY | **340 × 320 × 340 mm** | 65 °C heated chamber, **350 °C** hotend, ~1000 mm/s. Runs PLA/**PETG/ABS/ASA/PC**/PA/PET/TPU + CF/GF. → our **large + structural + future-engineering-filament** workhorse. |
| **Bambu P2S** | FDM CoreXY | 256 × 256 × 256 mm | 300 °C nozzle, 110 °C bed, enclosed (no *active* chamber). → **small parts, parallel printing, everyday**. |
| **Formlabs Form 3L** | Resin SLA | 335 × 200 × 300 mm | 25 µm XY, 25–300 µm layers. → **small precision / cosmetic parts only**. |

**Materials:** **PLA is FREE** for students — but it's the **only filament stocked
right now** (more "coming soon"). **Resin is $0.25/mL** (assorted). Everything else
(machine time, PLA, tools, metal cutting/welding/waterjet) is free.

## Material strategy — the one real gotcha: **PLA creep**

Research is unambiguous: **PLA is the worst common filament for CREEP** — it slowly
deforms under *sustained* load, worse when warm (the textbook failure is "a printed
shelf bracket that sags over weeks"). PETG/ASA/ABS/PC resist creep far better; **PETG
is the standard choice for load-bearing printed mounts.** Our shop only has PLA today.

So the plan is deliberately **hybrid** — don't let creep-prone PLA solely carry the
permanent ~12–15 kg hang:

1. **Metal carries the sustained load.** The wall's own **structural wooden pocket**
   + a **metal spine (80/20 extrusion)** take the weight. Printed parts **locate and
   interface**; they are not the sole load path.
2. **PLA is fine NOW for:** panel alignment brackets, the Pi/bonnet enclosure, cable
   clips, jigs, spacers, and any low- or short-term-load part. PLA is free →
   **over-build** (thick walls, high infill, load oriented along the layers).
3. **Any part under real sustained load** (cleat hooks, PSU cradles): print in PLA
   now as a first install, then **reprint in PETG/ASA on the H2S** once the shop
   stocks it. Design so PLA loads in **compression/shear** (strong), never long-term
   bending/tension across layer lines.
4. **Anti-creep design rules:** short unsupported spans; ribs + fillets; spread load
   over a **large contact area**; orient layer lines with the principal load; keep
   parts **away from PSU heat** (PLA softens ~55–60 °C).

## Mounting architecture (updated by the wooden pocket)

> **The authoritative mount design is now `docs/design/MOUNT_DESIGN.md`** (clean-slate,
> 2026-07-02: wood tongue-cleat in the pocket + aluminum rails + printed adjustable
> clips). The summary below is consistent with it; the printed-parts BOM here still
> applies (clips, Pi/bonnet enclosure, PSU cradles, cable clips).

The full-width **structural wooden pocket** (1.4 cm × 5 cm, open-top, ~512 cm long —
see `WALL_PROFILE.md`) is a **built-in continuous cleat rail**. It **replaces the
lag-screws-into-studs / toggle-bolt wall anchoring** from `INVENTORY.md` §8, and being
*continuous* it lets us hang the spine at close intervals → the metal spine can be
**smaller/shallower** than the originally-specced 80/20 1530 (good, because the lip
only stands **34 mm** proud — depth is tight).

**Load path:** panel (M3 holes) → printed alignment bracket → **metal spine** →
printed **cleat hook (tongue in the wooden pocket)** → **wooden rail** → wall.
A printed **bottom spacer** holds the assembly's lower edge 34 mm off the wall so it
can't swing/tip (classic French-cleat behavior: top cleat bears load, bottom spacer
keeps it flush).

```
   ceiling
   ┌─pocket─┐   ← printed CLEAT HOOK tongue drops in here (≤1.4 cm, ~4 cm deep)
   │██wood██│
   │   ┌────┴──── metal spine (80/20 or lighter) ── printed panel brackets ── PANELS
   │   │  Pi+bonnet enclosure (center, behind/below)
   wall│  ...  bottom spacer (34 mm) keeps the row flush
```

## The printed BOM

Qtys are for the full 16-panel wall. "Later" = reprint in PETG/ASA when stocked.

| # | Part | Qty | Printer | Material (now → later) | Load | Notes |
|---|---|---|---|---|---|---|
| 1 | **Cleat hook** (spine-top → wooden pocket) | ~8–10 | H2S | PLA over-built → **PETG/ASA** | ~1.5 kg ea (compression on tongue) | Tongue ≤ 14 mm wide (target ~11), engage ~40 of the 50 mm pocket. Rest tongue on pocket floor so load is compression. Bolts to spine T-slot. |
| 2 | **Panel alignment bracket** (M3 holes ↔ spine) | ~32–48 | P2S (+H2S) | PLA | locating only | Screws into the panel's 6 M3 brass holes (4 corners + 2 mid-edge, ~144 mm pitch), bolts to spine. **Sets coplanarity + even gaps** across 16 panels. Adapt Printables 1294572 / 578204 to our pitch. |
| 3 | **Bottom spacer / anti-swing foot** | ~6–8 | P2S | PLA | low | 34 mm deep standoff to the wall along the bottom edge. |
| 4 | **Pi + Triple Bonnet enclosure/mount** | 1 | H2S | PLA → PETG | low | Center-back. **Depth-critical:** stack is ~40–50 mm; lip only gives 34 mm → recess it or **hang it just BELOW the row**. Vented. Parametric (CadQuery). |
| 5 | **PSU cradle** (LRS-350-5, ~215×115×30 mm, ~0.6 kg ea) | 2 | H2S | PLA → **PETG/ASA** | moderate + warm | Open/vented (PSUs run warm — PLA risk). Mount **separately** from the hung row (wall/shelf), PSU1 left half, PSU2 right half. |
| 6 | **Cable management** (HUB75 ribbon clips, power-wire routing, strain reliefs) | many | P2S | PLA | none | Print a batch; also a mount for the 8-way ATC fuse block. |
| 7 | **Spine splice alignment jig** (if spine is 2–3 sections) | 2 | P2S | PLA | none | Metal splice plates do the joint; print alignment aids so sections stay coplanar. |
| 8 | **Assembly jigs**: gap combs, cleat-position drill template | few | P2S / **Form 3L** | PLA / resin | none | Resin worth it here for precision (small volume, ~$5–10). |
| 9 | **(Optional) front bezel / seam trim, Vestor logo badge** | — | P2S / Form 3L | PLA / resin | none | Bezel over 5 m = FDM segments (resin too costly). Logo badge = resin (nice finish, ~$2). |

## Resin — when it's worth $0.25/mL

Reserve the Form 3L for **small precision or cosmetic** parts; FDM (free) does all
structure. Rough costs: logo badge ~5–10 mL → **~$1.25–2.50**; a gap-comb jig set
~20–40 mL → **~$5–10**; a detail bezel corner ~15–30 mL → **~$4–8 ea**. A structural
bracket in resin (~30–60 mL → $7.50–15) is **not** worth it — brittle *and* paid.
Budget **~$10–30** total for nice-to-haves; everything load-bearing stays free PLA/PETG.

## Parametric CAD workflow (Claude/Codex, per the owner's stack)

The owner drives CAD with Claude/Codex → generate **parametric code**, not one-shot
STLs. Proposed repo layout (new `cad/` dir), one folder per part:

```
cad/
  cleat_hook/      model.py (CadQuery/build123d)  exports/{step,stl,3mf}  checks/validate.py  README.md
  panel_bracket/   ...
  pi_enclosure/    ...
  psu_cradle/      ...
```

Rules for every part script: **all dims as top variables**; export **STEP (CAD edit)
+ STL/3MF (slice)**; print bounding box; assert min wall thickness; comment each
design choice; design for **FDM constraints** (overhangs ≤45°, no unsupported
bridges > ~10 mm, holes sized for M3). Validate mesh (trimesh/MeshLab) before
printing. Slice in **Bambu Studio** (H2S/P2S profiles); OrcaSlicer for tuning.

## Print-setting defaults (structural PLA, H2S/P2S)

- Walls: **4–6 perimeters**; infill **40–60 %** (gyroid); top/bottom 5 layers.
- Layer height 0.2 mm (0.28 for big non-cosmetic parts to save time).
- **Orientation = load along layers**, weak Z-axis never across the load.
- Brim on tall/small-footprint parts; PLA needs no chamber but the enclosed P2S/H2S
  reduce warp.
- For eventual PETG/ASA: H2S only (chamber); expect to re-tune supports/gaps.

## Measure on-site BEFORE printing finals

1. **Depth behind the 34 mm lip** — does the Pi+bonnet stack fit, or recess/relocate it?
2. **Panel weight** (confirm ~0.45 kg ea) → total hung load → cleat-hook count.
3. **Pocket uniformity** across the full 512 cm (width, depth, straightness).
4. **Ceiling-to-desired-row-height** (pocket puts the row top ~22.5 cm below ceiling).
5. Wall material at the bottom edge (for the anti-swing spacer fixing, if any).

## Next steps

- Confirm the 5 measurements above.
- Decide the metal spine (lighter than 1530 now that the pocket supports continuously).
- Then I can generate the parametric CAD (`cad/`) for parts #1–#6, starting with the
  **cleat hook** and **panel alignment bracket** (the two that gate everything).

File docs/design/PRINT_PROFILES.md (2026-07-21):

# VESTOR — PRINT PROFILES ("Vestor Structural" + "Vestor Light")

Evidence-based slicer settings, from a research pass over CNC Kitchen's tensile/hook tests
and peer-reviewed FDM studies. **Supersedes the "4–5 walls / 15–20 % infill" guidance in
`PRINTING.md`.** Optimization target: filament + machine-hours are FREE, so we spend both to
buy strength. Plate/schedule: `PRINT_PLAN.md`.

## What actually matters (ranked by measured strength-per-effort)
1. **Orientation — worth ~2×** (PLA hook: 73 kg with load *along* layers vs 40 kg across).
   **Already correct** in our STLs — never let Studio auto-orient the cleat or hanger.
2. **Total wall cross-section.** 2 → 4 wall loops took a test hook from **20 kg → 33 kg (+65 %)**.
   Wall *width* matters as much as count: 2 loops at 200 % width (39 kg) **beat** 4 loops at 100 % (33 kg).
3. **Solid vs sparse.** Infill **20 %→80 % is statistically flat** (noise-level, non-monotonic).
   Only going fully **100 %** does anything (+37 % modulus over 60 %).
4. **Don't print cold or wet.** 190 °C loses **50 %** of layer adhesion vs 230 °C. Wet filament = steam voids.
5. **Layer height ≤ 50 % of nozzle.** 0.3 mm on a 0.4 nozzle **halves** interlayer strength.

**Placebo / counterproductive — don't bother:** infill % between 20–80 · very slow printing
(30 vs 500 mm/s was "minimal") · **annealing** (zero layer-adhesion gain, up to **10 % dimensional
distortion** — wrong trade for precision brackets) · 0.28 mm layers "for strength" · a bigger nozzle ·
**the H2S heated chamber with PLA** (65 °C chamber > PLA's 60 °C Tg → curling + heat-creep jams).

---

## ▶ Ready-made profile files (just load these)
`cad/print_profiles/Vestor_Structural_H2S.3mf` and `..._P2S.3mf` — built from the shop's own
Medium profile with every value below already applied.

**To load:** Bambu Studio → **File → Import → Import Configs…** → pick the `.3mf`. That imports the
*settings only* (no model). Then import the STLs from `cad/print_stl/` as usual.
*(If you open the `.3mf` as a project instead, it will also bring the shop's placeholder model —
just delete it and import ours.)*

⚠️ **After importing, always check the plate:** parts must be **lying down**, not standing.
Use **Arrange (`A`)** to shuffle in XY — never **Auto orient**, which re-picks the resting face.
If a part is upright: select it → **Place on face** → choose the big flat profile face.

## ▶ "VESTOR STRUCTURAL" — for `01_top_cleat`, `07_gap_hanger`, `02_foot_base`, `02_foot_tab`
Start from the shop's **H2S Medium** profile, then change:

**Quality**
- Layer height **0.16 mm** · first layer **0.20 mm**
- Line width — outer wall **0.42** · inner wall **0.55** · sparse infill **0.55** · internal solid **0.50**
  *(0.55 ≈ 140 % of nozzle, near the measured layer-adhesion peak)*
- Precise wall **ON** · seam position: put it on a **non-loaded face**

**Strength**
- **Wall loops: 8** ← the big one. Our parts have thin 6–12 mm sections, so 8 loops makes them
  **effectively solid** and infill becomes irrelevant. Check the preview: no sparse infill left in
  the critical section.
- Top shell **6** · bottom shell **6**
- Sparse infill **100 %** (if any sparse region survives, use **grid**, not gyroid — grid tested
  strongest in-plane: 21.9 vs 13.1 MPa for adaptive cubic)
- Infill/wall overlap **25 %** · wall order **Inner/Outer/Inner**

**Material / temp**
- Nozzle **230 °C** (first layer 235) · bed 55–60 °C
- **Chamber heating OFF** (keep internal < ~40 °C; crack the door if it climbs)
- Dry the filament **45–55 °C for 6–8 h** if a dryer is available

**Cooling**
- Part cooling **40 %** (min 30 / max 50) · **0 % for the first 3 layers** · min layer time ~5 s

**Speed** *(speed is nearly a myth for strength — this is free insurance)*
- Outer wall **80** · inner wall **150** · sparse infill **200** · solid infill **150** mm/s
- **Max volumetric speed 12 mm³/s** (well under PLA's ~21) so the melt is fully saturated at 230 °C

**Other:** supports **OFF** · brim **ON** · **do NOT anneal**

> **Time cost:** this roughly **doubles** print time vs the shop Medium profile (near-solid parts).
> That's the right trade when machine time is free — see `PRINT_PLAN.md` for the adjusted schedule.
> **If you need it faster:** 6 wall loops + 50 % grid infill gets ~85 % of the strength at ~65 % of the time.

## ▶ "VESTOR LIGHT" — for `08_cable_clip`, `06_psu_cradle`, `05_center_enclosure`
These carry no meaningful load. **Use the shop's Medium profile as-is** (0.20 mm, 2 walls, 15 %),
with one change: **supports OFF** — except `05_center_enclosure`, which wants **light supports**.

---

## Material verdict: PLA is genuinely the right choice (with one thing to verify)
PLA **beats** PETG and ASA on the three properties that matter here — hook strength (73 vs 55 vs 57 kg),
bending modulus (3300 vs 1900 vs 2300 MPa), and layer-adhesion retention (55 % vs 46 % vs 29 %).
It loses only on impact (irrelevant — static load) and heat.

**Creep is not our failure mode.** 24 kg ÷ 13 cleats ≈ **1.85 kg ≈ 18 N each** → roughly **0.1–0.2 MPa**
in the load-bearing section, i.e. **under 2 % of PLA's ~60 MPa UTS**. The creep studies that show PLA
failing operate at **50–90 % of UTS**. At ~35 °C below its Tg, PLA is firmly glassy here.

### ⚠ The one assumption to check on-site
Our "18–27 °C indoor" figure is the **room** — not the air **behind the panels**, where the LEDs, and
especially the PSUs, add heat. Once the wall runs, **IR-gun the actual temperature at the bracket
locations** (this also validates the ceiling-gap chimney from `../HARDENING.md`):
- **< 40 °C** → PLA, comfortably. Proceed as built.
- **40–50 °C** → switch the **cleats** to PETG (accept ~25 % lower strength, compensate with wall thickness).
- **> 50 °C** → ASA, and re-check orientation (its layer adhesion is poor).

## Validate it, don't trust it
Print **one extra cleat and pull it to destruction.** Service load is ~18 N per cleat; you want
**≥ 10× that**. Free to do, and it turns the whole analysis into a measured fact.

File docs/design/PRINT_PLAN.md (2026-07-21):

# VESTOR — PRINT PLAN (orientations · nesting · overnight batching)

How to get the whole part set printed in the **fewest overnight runs** using both free
Hobby-Shop printers. Nesting numbers are computed (`cad/parts/plate_plan.py`), not guessed.
Profile settings: see `PRINT_PROFILES.md`. Files: `cad/print_stl/` (already oriented).

**Optimization target:** filament and machine-hours are FREE and unlimited, and jobs can run
overnight. So we spend both freely to buy **strength and spare parts** — never to save time or plastic.

---

## 1. Orientations (already baked into the STLs — do NOT let Studio auto-orient)

| Part | Printed orientation | Why | Supports | Brim |
|---|---|---|---|---|
| `01_top_cleat` | **on its side** — profile flat on the bed, the 50 mm width up Z | constant-section prism → **zero supports**, and the ~1.5 kg hanging load runs **along** the layer lines, not across them (the difference between a PLA hook failing at ~15 kg vs holding 100+) | none | yes |
| `07_gap_hanger` | **on its side**, same logic | support-free + load along layers | none | yes |
| `02_foot_base` | channel + bolt holes vertical | holes print clean, no bridging | none | yes |
| `02_foot_tab` | 50 mm length flat on the bed | layers run along the tab's length | none | yes |
| `06_psu_cradle` | base down | retaining nubs bridge fine | none | no |
| `05_center_enclosure` | backplate flat | only part needing help | **light** | no |
| `08_cable_clip` | flat | trivial | none | no |

> Do not print the cleat or hanger standing upright to save bed space — that puts the layer
> lines **across** the load and is the one orientation that would actually make them fail.

## 2. What fits per plate (computed: 10 mm edge margin, 6 mm spacing, 5 mm brim where used)

| Part | Size (mm) | Need | +spares | **P2S** /plate | **H2S** /plate |
|---|---|---|---|---|---|
| `01_top_cleat` | 174×39×50 | 13 | **15** | 4 | **5** |
| `07_gap_hanger` | 246×70×40 | 6 | **7** | **✗ too big** | **3** |
| `02_foot_base` | 40×40×25 | 7 | 9 | 16 | 25 |
| `02_foot_tab` | 20×50×12 | 7 | 10 | 18 | 36 |
| `06_psu_cradle` | 34×72×37 | 4 | 5 | 18 | 28 |
| `05_center_enclosure` | 76×104×39 | 1 | 1 | 4 | 6 |
| `08_cable_clip` | 22×18×5 | 40 | 50 | 80 | 132 |

**The binding constraint:** the **gap hanger is 246 mm long — it does not fit the P2S at all**
(256 mm bed, no room for brim + edge exclusion). All 7 must run on the H2S, 3 per plate.
That single fact sets the whole schedule.

## 3. The batching plan — 3 overnight rounds, both printers in parallel

| Round | **H2S** (340×320) | **P2S** (256×256) |
|---|---|---|
| **1** | 3 × gap hanger | 4 × top cleat |
| **2** | 3 × gap hanger | 4 × top cleat |
| **3** | 1 × gap hanger **+ 4 × top cleat** | 3 × top cleat **+ all small parts** |

**Totals delivered:** 7 gap hangers ✓ · 15 top cleats ✓ (13 needed + 2 spares) · all feet, tabs,
cradles, enclosure, and 50 cable clips ✓.

**Why not 2 rounds?** 7 hangers ÷ 3 per H2S plate = 3 plates minimum, and the hangers can't be
offloaded to the P2S. Even dropping the spare hanger (6 → 2 plates) leaves ~7 cleats + all the
small parts undone. **3 is the floor.**

**How to compress it anyway:** the small-parts plate is quick (a few hours, not a full night).
If someone can swap a plate mid-day, run **small parts as a daytime job on day 1** and pull the
round-3 work forward — that can collapse this into **~2 nights + a daytime swap**.

## 4. Spares are free — print them
Included above: **+2 top cleats, +1 gap hanger, +2 foot bases, +3 foot tabs, +10 cable clips.**
Zero cost, and it means a bad fit or a cracked part never blocks the build. The cleats are the
load-bearing part — having 2 in reserve is the highest-value spare.

## 5. Practical notes
- **Trust Bambu Studio's time estimate** over any number here — hit *Slice* and read it.
- ⚠ **The "Vestor Structural" profile (`PRINT_PROFILES.md`) roughly DOUBLES print time** (near-solid
  parts, 0.16 mm layers). Expect a big structural plate ≈ **15–25 h**, not 10–15. So think in
  **~24 h plate cycles, not strict overnights** — start a plate in the evening, collect it the next
  afternoon. The 3 rounds above become **~3 days** with both printers running, which is still the floor.
- The small-parts plate uses **Vestor Light** and stays quick (≈ 4–6 h) — run it as a **daytime job**
  so it never consumes a cycle.
- If you want it faster, the **6 walls + 50 % grid** variant in `PRINT_PROFILES.md` gets ~85 % of the
  strength at ~65 % of the time.
- **Save each sliced plate as a `.3mf` to your USB** — the shop computer won't keep your profile
  between sessions, and you'll want to re-run a plate if a part fails.
- **Label parts as they come off** (masking tape) — the foot bases and tabs look similar.
- **Check the first layer** on every plate start; after that they're unattended.
- If a coupon fit came back off, **re-slice only the affected part** before committing a full plate.

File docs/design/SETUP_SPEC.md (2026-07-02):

# VESTOR — FULL SETUP SPEC (authoritative)

The single source of truth for the physical build, owner-confirmed and validated in
CAD (`cad/model.py`; STEP: `cad/out/vestor_wall.step`). Build to these numbers.
Companions: `WALL_PROFILE.md`, `MOUNT_DESIGN.md`, `FABRICATION.md`, `../HARDWARE.md`.
All dims in **mm** (inches noted). Established 2026-07-02.

---

## 1. The room

Three walls: **FRONT** (the panels go here), **LEFT**, **RIGHT**. You walk in and
face the front wall. The **LEFT wall is a room corner on your left that comes toward
you**, and it is **built IDENTICALLY to the front wall** — same grooved wooden piece,
same top/bottom grooves. (The right wall is not used by the build.)

---

## 2. The grooved wooden piece (cross-section) — IDENTICAL on BOTH walls

A structural **wooden** piece runs the full length near the top of each wall. Profile
(side view; the piece is perfectly STRAIGHT / uniform):

```
   ceiling ───────────────────────────────
              │ 22.5 cm (225 mm) ceiling → TOP of the piece
              ▼   ↓ drop a cleat in
        ┌──┐▒▒│  ← TOP groove   OPEN at top    (1.4 cm wide × ~5 cm tall)
        │  │▒▒│
        │  │██│  ← MIDDLE ~3.3 cm: piece ATTACHED to the wall
        │  │▒▒│  ← BOTTOM groove OPEN at bottom (1.8 cm wide × 5.7 cm tall)
   piece│  │▒▒│
        └──┘▒▒│  ↑ push a tab up
   ───────wall────────  piece: 2 cm thick, 14 cm tall, 3.4 cm proud
```

| Feature | Value | Notes |
|---|---|---|
| Piece thickness | **2.0 cm** (20 mm) | uniform, straight |
| Piece height | **14 cm** (140 mm) | = 5 + 3.3 + 5.7 |
| Piece projection (proud of wall) | **3.4 cm** (34 mm) | = groove 1.4 + piece 2.0 |
| Ceiling → top of piece | **22.5 cm** (225 mm) | |
| **TOP groove** | **1.4 cm wide × ~5 cm tall** | behind the piece top; **OPEN AT THE TOP**, closed at its bottom |
| Middle attach band | **~3.3 cm** (33 mm) | piece joined to the wall here |
| **BOTTOM groove** | **1.8 cm wide × 5.7 cm tall** | behind the piece bottom; **OPEN AT THE BOTTOM**, closed at its top |
| Wall step | **0.4 cm** (4 mm) | the WALL is cut 0.4 cm deeper BELOW the attach band → that's why the bottom gap (1.8) > top gap (1.4). The piece does NOT tilt. |

The grooves are the **gap between the piece and the wall** (not cut into the wall).
Both grooves run the **full length** of each wall.

**Why the grooves matter (the whole mounting idea):** the TOP groove is a continuous,
structural, open-top slot → a **built-in French cleat**: drop a wood tongue in, it rests
on the slot floor and carries load in compression into solid wood (wood cleats hold
50–100+ kg; the whole assembly is ~10 kg → ~10× margin, zero new wall holes). The BOTTOM
groove (open at bottom) takes an anti-swing tab pushed up into it → the assembly is
**captured at both ends**. Both walls have this, so the corner electronics hang the same way.

---

## 3. The corner + the usable face (CRITICAL)

- **Usable panel FACE = 201.5 in (5118 mm)** — the flat mountable length, measured from
  the far end to the **INSIDE CORNER**.
- The **inside corner is where the LEFT wall's proud piece BEGINS**, NOT the left wall's
  back surface. The panels **stop there**.
- Because the left wall's piece juts **34 mm** into the room (identical build), the left
  wall's **SURFACE sits 34 mm BEHIND the inside corner** (`left-wall surface = corner + 34`).
- So the panels butt the corner cleanly; the left piece front lands exactly where the last
  panel ends — **no overlap**.

---

## 4. The panels

- **16× CnGear P5 HUB75**, 64×32 px, **~320 × 158 × 15 mm**, **~0.45 kg** each, FM6124HJ
  (standard driver, no init string).
- **6× M3 brass threaded holes** per panel: a **3-col × 2-row grid**, top+bottom rows
  ~**144 mm** apart (vertical). These are the mount points.
- Rear HUB75 connectors + ribbons **barely protrude**.
- Row = **16 × 320 = 5120 mm** wide × **160 mm** tall (one panel high) → logical **1024×32 px**.
- Fit: 5120 mm into 5118 mm usable → **+2 mm, which overshoots the FAR end** (never the
  corner). Butt panels tight; no width-adding side frames.

---

## 5. Mount — LOCKED (rationale in `MOUNT_DESIGN.md`; **buildable parts in `MOUNT_PARTS.md`**)

1. **Hang from the wall's built-in grooves — zero new holes.** A **½″ (12 mm) Baltic-birch
   tongue-cleat** drops into the **TOP groove** (carries the load) + a **tab** up into the
   **BOTTOM groove** (anti-swing). Captured top + bottom.
2. **Frame = two continuous aluminium rails** at the panels' 144 mm M3 rows (dead-flat
   reference). Can be machined in-house (Hobby Shop mills/waterjet) — no need to buy 80/20.
3. **Panels = MAGNETIC** (owner-tested OK): thin **steel strips** on the rails + the on-hand
   **magnet screws** → panels snap on/off from the front, self-align; add alignment pins for
   lateral seams. Magnet-free (M3 screws) is the fallback.
4. **Electronics in the LEFT CORNER**, hung from the LEFT wall's grooves (same tongue system).
5. **3D prints locate/interface only** (panel clips, Pi/PSU enclosures, cable clips) — PLA
   now (over-built), reprint load-bearing parts in **PETG/ASA** on the H2S when stocked.
   Nothing structural rides on PLA (it creeps).

---

## 6. Electrical — LOCKED

- **Feed: center-fed 2×8** — `--led-chain=8 --led-parallel=2 --led-pixel-mapper="U-mapper;Rotate:180"`,
  **`pwm_bits=11` → measured 150 Hz** on the Pi. Pi in the CENTER, two chains of 8 outward
  (Bonnet outputs land on center panels 8 & 9). Chosen over the single chain of 16 for **11-bit
  vs 9-bit color depth, 150 vs 111 Hz, and safe 8/chain signal integrity** (16/chain risks
  bright-text ghosting) — see `BACK_OF_HOUSE.md`. (Reverses the earlier "single chain of 16".)
- **Power: 2× Mean Well LRS-350-5** (5 V/60 A), **SPLIT one per half** (PSU-L left end, PSU-R
  right end, each own AC outlet); per-panel **7.5 A** fused; **10 AWG** star trunks; trim ~5.2 V;
  bond both V− + Pi GND, never V+. `BRIGHTNESS ≤ 50`. Full detail: **`../ELECTRICAL.md`**.
- **Brain: Raspberry Pi 4 + Adafruit Triple RGB Matrix Bonnet 6358** — in the **center** of the
  ceiling gap; USB-C powered; Bonnet 5 V terminal empty, Bonnet GND → PSU-L V−.
- **Siting: all electronics in the ~22.5 cm ceiling gap** on a groove-hung backer strip, hidden
  by a removable vented valance (`BACK_OF_HOUSE.md`).

---

## 7. Materials on hand / hardware

- **100 magnet-screw feet** — screw into the panels' M3 holes; jut **1.1 cm** off the panel
  back (**~0.8 cm cylindrical shaft** + a **magnet base** ~0.3 cm). Need a **ferrous** face
  to stick (→ steel strips on the rails). 6/panel × 16 = 96 used.
- 2× LRS-350-5 PSUs; AC cords; 8-way ATC fuse blocks; fork terminals (see `INVENTORY.md`).
- Wood/metal/print stock free at the MIT Hobby Shop (`MIT_RESOURCES.md`).

---

## 8. CAD

`cad/model.py` — parametric box model (dims match this spec). Coords: **X = along the wall
(0 = far end .. 5118 = inside corner)**, **Y = depth into room** (0 = wall surface, +Y toward
viewer), **Z = vertical** (0 = piece top, −down). `render_pv.py` (shaded 3D), `render_mpl.py`
(ortho + cross-section), `export_step.py` → `cad/out/vestor_wall.step` for **Fusion 360**.
Toolchain: Python 3.12 venv (CadQuery/PyVista) — see `cad/README.md`.

---

## 9. Still to confirm on-site (non-blocking)

- Groove dims **uniform across the full 512 cm** (measure at ~5 points); **usable** groove
  widths after paint/finish; grooves unbroken (no outlets/nails).
- Panel **M3 hole positions** (column spacing + edge offsets) from a real panel — the one
  estimate in the CAD.
- Depth of room behind the corner for the electronics; wall material for any bottom fixing.
- Exact usable face length (if a hair under 5118, the shortfall shows at the FAR end).

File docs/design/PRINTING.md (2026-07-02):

# VESTOR MOUNT — 3D PRINTING GUIDE

Everything you need to print the mount parts on the Hobby Shop's Bambu P2S / H2S.
Pre-oriented STLs are in `cad/out/print/` (regenerate: `cad/parts/print_orient.py`).
STEP files for Fusion 360 review are in `cad/out/*.step`. The parts are parametric —
to change any dimension, edit `cad/parts/mount_params.py` and re-run, don't edit STLs.

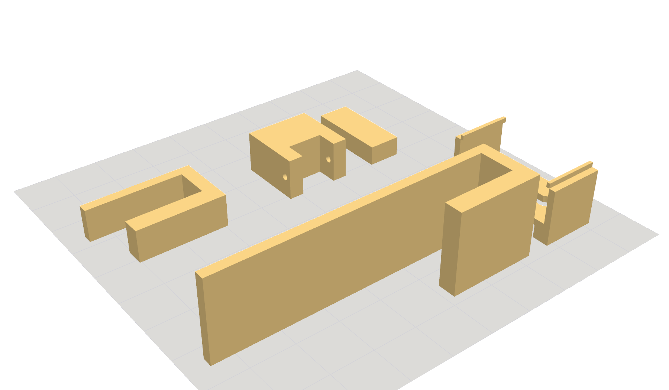
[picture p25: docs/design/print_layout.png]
print bed layout


## Golden rule: print the COUPONS first

Do **not** batch-print 13 cleats until you've verified the fit against your *actual*
grooves (their width changes with paint/finish). First print just the two coupons:

| Coupon | File | Tests | ~Time / filament |
|---|---|---|---|
| **Tongue** | `00_coupon_tongue.stl` | the cleat tongue dropping into the **TOP** groove + saddle seating on the piece top | ~25 min · ~13 g |
| **Tab** | `02_foot_tab.stl` | the anti-swing tab sliding up into the **BOTTOM** groove | ~40 min · ~7 g |

**Check:** the tongue should drop in with a **slight** side-to-side wiggle (~0.5–1 mm total),
not force-fit and not sloppy; the saddle should sit flat on the piece top. The tab should
slide up smoothly and stay when pinched.
**Adjust:** if too tight/loose, change `TONGUE_Y0/TONGUE_Y1` (tongue width) or `TAB_W` in
`mount_params.py`, re-run `print_orient.py`, reprint the coupon. Only then batch the rest.

## Parts, orientation & quantities

| # | File | Qty | Orientation (as exported — keep it) | Supports | Notes |
|---|---|-----|---|---|---|
| 1 | `01_top_cleat.stl` | **13** | **on its side, 50 mm width UP** | none | the load-bearing part — orientation is critical (see below) |
| 2 | `02_foot_base.stl` | ~7 | channel + holes vertical | none | |
| 2 | `02_foot_tab.stl` | ~7 | 50 mm length flat on bed | none | also Coupon B |
| 5 | `05_corner_enclosure.stl` | 1 | backplate flat | **light** | supports only under the tongue/saddle overhang |
| 6 | `06_psu_cradle.stl` | 4 | base down | none | retaining nubs bridge fine |

Total ≈ **0.9 kg** of filament (free PLA). Everything fits **both** the P2S (256 mm) and
H2S (340 mm) beds. On the P2S you fit ~5 cleats per plate → ~3 plates for all 13; the H2S
fits more. The cleats are the bulk of the print time — run them on the **H2S** (faster) or
overnight.

### Why the cleat orientation matters (don't let the slicer auto-rotate it)
The cleat is printed with its cross-section flat on the bed and the 50 mm width pointing up.
Two reasons, both from the research: (1) the body is then a constant-section prism → **zero
supports**; (2) the ~1.5 kg hanging load runs **along** the layer lines, not across them —
a PLA hook printed this way holds **100+ kg** vs failing at ~15 kg the weak way. If Bambu
Studio's "auto orient" flips it upright, undo that.

## Bambu Studio settings

Quick-start: install Bambu Studio → pick your printer (P2S/H2S) and **Bambu PLA Basic** →
drag in the `cad/out/print/*.stl` → **turn OFF auto-orient** (they're already placed) →
apply the settings below → Slice → send to printer or export to SD.

| Setting | Value | Why |
|---|---|---|
| Nozzle / layer height | 0.4 mm / **0.2 mm** (0.28 "draft" fine for coupons) | strength + speed balance |
| **Wall loops** | **4** (5 for cleats) | walls carry the load in FDM — more walls beats more infill |
| **Infill** | **15–20 %** gyroid | load is 4–5× under the PLA creep limit, so light infill is plenty (saves time/filament) |
| Top/bottom layers | 4 / 4 | |
| Supports | **off**, except `05_corner_enclosure` (tree/normal, under the tongue only) | prisms need none |
| Brim | **5 mm** on the cleat + tab (tall/narrow footprints) | anti-tip / adhesion |
| Build-plate adhesion | textured PEI, 55 °C bed | standard PLA |
| Seam | back / aligned | cosmetic (parts are hidden anyway) |

**Material:** start in **free PLA** — it's genuinely fine here (validated 4–5× margin). If
you want zero long-term creep worry or a cleat sits near LED heat, reprint the **13 cleats**
in **PETG or ASA** on the H2S (65 °C chamber) later — same STL, just a hotter profile. The
feet/shoes/cradles can stay PLA forever.

## Hardware that goes into the prints (order alongside)
- **M4 heat-set inserts** (brass) — 2 per cleat rail-mount × 2 rails × 13 = **52**; press in
  with a soldering iron after printing. Plus **M4 bolts** (rail → cleat) and **M4 grub/jack
  screws** (leveling + saddle set-screw + tab pinch).
- **M2.5** screws + heat-set for the Pi in the corner enclosure.
- (Rails, steel, magnet feet: see `MANUFACTURING_PLAN.md` §7.)

## Regenerating / tweaking
```
cadenv/bin/python cad/parts/print_orient.py     # → cad/out/print/*.stl + print_layout.png
cadenv/bin/python cad/parts/assembly.py         # re-check the fit (collide_check) + renders
```
Change a dimension once in `cad/parts/mount_params.py`; every part + coupon + the assembly
move together. (Toolchain setup: `cad/README.md`.)

## Fusion 360 (optional)
Open any `cad/out/*.step` in Fusion to spin the part around or tweak it by hand. But since the
parts are parametric in `mount_params.py`, dimension changes are cleaner there (edit → re-export)
than redrawing in Fusion. Fusion is best for a visual review or a one-off manual mod.

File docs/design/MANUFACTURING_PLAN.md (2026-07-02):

# VESTOR MOUNT — MANUFACTURING PLAN (validated, least-labor)

The airtight answer to "what is the easiest way to actually build this mount, given
the MIT Hobby Shop." Backed by four parallel research passes (LED-wall best practice,
off-the-shelf hardware, makerspace process-labor, adversarial engineering validation),
each web-sourced and cross-checked. Companion: `MOUNT_PARTS.md` (the parts),
`SETUP_SPEC.md` (the wall). Established 2026-07-02.

## Bottom line

**Print the interface parts, saw-and-drill two steel rails, hang it in the grooves.**
No CNC, no waterjet, no laser for any part. Your hands-on time is roughly **one
slicing session + a few plate swaps + ~1 hr of sawing/drilling + a half-day install**
— the printers do the work unattended. The research changed the *design* (steel rails,
one-piece tall cleats, weight on a ledge) more than the *method* (printing was right).

---

## 1. Manufacturing method — why printing wins (and CNC/waterjet lose)

FDM 3D-printing the custom brackets is the least-*human-labor* route by a wide margin —
not because it's fast (it's slow in wall-clock) but because it's the only process where
**quantity is nearly free**: nest more parts on the plate, hit go, walk away. Zero
fixturing, no material sourcing (free PLA), near-zero post-processing.

| Process | Why it loses here |
|---|---|
| **Waterjet** | The cleat needs its width from **50 mm-thick plate** → cuts at ~2–4 ipm with taper, tabs you hand-grind, and small parts fall through the bed slats. Per-part manual labor printing doesn't have. |
| **CNC mill** | A 3-D hook needs **~3 re-clamped setups per part × ~13** + the steepest CAM learning curve in the shop. Worst fit. |
| **Laser** | Can't cut aluminum or 50 mm plastic; Hobby Shop isn't even confirmed to have one. |
| **Custom extrusion** | Die is **$750+ / 2–3 wk lead** — absurd for ~13 parts. |

The cleat's constant cross-section is a **printing** advantage, not a machining one:
lay it on its side (profile in the build plane, the 50 mm width up Z) → overhangs stay
support-free *and* the shear load runs **along** the layer lines (the orientation that
takes a PLA hook from failing at ~15 kg to holding 100+ kg).

*Sources:* [Hubs 3DP-vs-CNC](https://www.hubs.com/knowledge-base/3d-printing-vs-cnc-machining/) · [MakerStage](https://www.makerstage.com/resources/3d-printing-vs-cnc) · [TechniWaterjet speeds](https://www.techniwaterjet.com/waterjet-cutting-speed/) · [WARDJet tabbing](https://my.wardjet.com/news/tabbing-waterjet-parts) · [SUNLU PLA strength/orientation](https://store.sunlu.com/blogs/products-knowledge/is-pla-strong-enough-real-life-strength-tests-explained) · [Sovol 45° rule](https://sovol.eu/blogs/new/45-degree-rule-3d-printing-overhangs-support-quality-guide) · [MIT Hobby Shop equipment](https://mitadmissions.org/blogs/entry/machine_shops_part_1/) (waterjet/mills/saws confirmed; laser + CNC router NOT).

## 2. What the adversarial validation changed (the "airtight" fixes)

The load-bearing skeleton was already sound (the wood groove has **20–100× margin**;
PLA cleats run **4–5× under** the creep threshold). Every real risk was in the *panel
interface* — and each has a low-labor fix now baked into the CAD:

1. **🔴 Coplanarity (was a showstopper).** A "roughly straight" bar + dialing 96 magnet
   screws will *not* make P5 seams vanish (need ≤0.2–0.3 mm panel-to-panel); it just
   telegraphs the bar's waviness. The nearest real build to ours (Caudell's 48-panel
   jumbotron, magnet-screws-on-bars) ended up **cable-tying panels on**.
   **FIX:** make the rails a single flat **datum** you level once. The cleat is now a
   **tall C-bracket carrying BOTH rails on one rigid spine** → both rails coplanar by
   construction; you laser-level ~13 cleats (jackscrew + slotted holes), screws are trim.
2. **🟠 Magnet shear is marginal.** Friction is only ~15 % of pull force → 0.5–1.8×
   margin, decaying with heat/vibration/dust — the slow "walk down over months" failure.
   **FIX:** the **bottom rail is a steel angle whose horizontal leg is a continuous ledge
   every panel RESTS on.** Magnets then only hold the panel *flat*, never *up*.
3. **🟠 Thermal expansion.** A 5 m metal rail grows ~1–2.4 mm per 20 °C into a butt-tight
   row → bowed seams. **FIX:** anchor each rail to **one central cleat**, slot the other
   cleats' rail-holes, leave a sub-mm end gap (hidden at the corner). Steel (below) also
   halves the movement vs aluminium.
4. **🟢 Steel spec.** Magnets need **bare low-carbon steel ≥2–3 mm** — thin/coated/alloy
   silently loses 40–60 %. **FIX:** the rails ARE steel (see below), bare on the magnet face.
5. **🟢 PLA / wood / galvanic** all cleared: PLA fine if chunky + oriented (PETG/ASA a
   free upgrade near LED heat); wood groove 20–100× margin (leave 0.3–0.5 mm tongue
   clearance for humidity); galvanic a non-issue indoors.

*Sources:* [LED flatness](https://ledscreenfactory.com/understanding-led-screen-flatness-a-comprehensive-guide/) · [Caudell jumbotron (magnet failure)](https://medium.com/@phillipcaudell/how-to-build-your-very-own-large-led-jumbotron-video-wall-and-go-insane-in-the-process-8c515a49a07d) · [K&J magnet friction/shear](https://www.kjmagnetics.com/blog/leverage-and-friction-when-using-magnets) · [K&J steel thickness](https://www.kjmagnetics.com/blog/steel-thickness-and-magnetic-fields) · aluminium/steel CTE (material data) · [PLA creep](https://www.ryandynamics.com/insight/materialcreep/).

## 3. The one change that simplifies everything: steel rails, double duty

Replacing "aluminium bar + glued steel strip + 16 printed rest-shoes" with **two steel
rails** collapses several risks into one material choice:
- **Top rail** = steel **flat bar** (~26×5 mm) — the magnet target, 3× stiffer than
  aluminium (holds the flat datum), no adhesive strip to shear-peel.
- **Bottom rail** = steel **angle** (~30 × 24 × 4 mm) — vertical leg is the magnet target,
  **horizontal leg is the continuous rest ledge**. Deletes all 16 rest-shoes at once.

Weight goes from ~4 kg (alu) to ~16 kg (steel) — still **trivial** for the wood groove
(20–100× margin). The only real cost is heavier handling; the payoff is stiffness +
magnet grip + thermal + fewer parts.

## 4. The magnets decision — kept, with the fixes

The best-practice research leaned toward **bolting** panels' M3 straight to the rails
(most reliable, fewest parts). But bolting a wall-hugging panel has **no rear access**,
forcing face-down **section assembly** and losing tool-free service. Since you **own +
bench-tested the 100 magnet screws**, want tool-free front service, and the engineering
pass confirms **magnets are fine once the weight rests on the ledge and the rail is a flat
datum** — magnets stay. *Fallback if you'd trade tool-free service for the most bomb-proof
seams: bolt panels' M3 to the rails in 4-panel sections on a table, then hang the sections.*

## 5. Revised parts (was ~43 printed → now ~25)

| Part | Change | Qty |
|---|---|---|
| **Tall station cleat** | now carries BOTH rails (coplanarity datum) + jackscrew leveling | 13 |
| **Anti-swing foot** | pure anti-swing now; sits between cleats | ~7 |
| ~~Rest shoe~~ | **deleted** — the bottom-rail angle is a continuous ledge | 0 |
| **Rails** | **steel** (flat bar top + angle bottom); no separate strip | 2 (4 cuts) |
| Corner enclosure, PSU cradles | unchanged | 1 + 4 |

cross-section
3D

*Verified by an automated boolean `collide_check()`: no bracket shares solid volume with
a panel, the piece, or another bracket.*

## 6. Your actual labor

**Make:** slice/nest the printed parts once → run unattended on the P2S/H2S (free PLA;
PETG/ASA for the cleats if you want zero creep worry) → saw the 4 rail pieces + drill
the bolt holes (~1 hr) → set M4 heat-set inserts in the cleats (~1 hr, soldering iron).

**Install:** drop the 13 cleats into the top groove (no wall holes) → **laser-line the
cleat faces + jackscrew/shim them flat to ≤0.3 mm** (the one precision hour — do this
before any panels) → bolt on the two rails (center-anchored, ends slotted) → wedge a few
anti-swing tabs into the bottom groove → screw the magnet feet into the panels → hang
panels from the corner, each **resting on the ledge + butting its neighbour**, magnets
snap to the steel. Set the 6 screws to a uniform depth with a simple gauge; the flat rail
does the coplanarity.

## 7. Bill of materials
- **Steel:** low-carbon (A36/1018) flat bar ~26×5 mm ×5.1 m + angle ~30×24×4 mm ×5.1 m
  (each in 2 cuts, spliced at the center cleat). Bare on the magnet faces; 430 stainless
  if corrosion is a worry. ~16 kg total.
- **Printed (free PLA / optional PETG-ASA):** 13 tall cleats, ~7 anti-swing feet + tabs,
  1 corner enclosure, 4 PSU cradles (~1 kg). No rest-shoes.
- **Fasteners:** M4 bolts + **M4 heat-set inserts** (2/rail × 13), M4 jackscrews + set-screws,
  M2.5 for the Pi. **Magnet feet:** 96 (own, have 100).

## 8. Still to confirm on-site (non-blocking)
- Real panel **M3 hole positions** (the −8 / −152 rows + column pitch).
- Groove widths **after finish** (tongue/tab clearances); uniformity over 5.1 m.
- Where the PSUs mount (wall vs corner shelf) for the cradles.

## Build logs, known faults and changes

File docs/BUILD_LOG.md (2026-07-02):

# BUILD LOG
Append a dated entry after each meaningful step: what you did, what worked, what changed.
Never record secret values — only that a secret was set.

---

## 2026-07-02 — Manufacturing strategy researched + design revised → `MANUFACTURING_PLAN.md`
Owner asked to deep-research the EASIEST/least-labor way to actually build the mount
(print vs CNC vs waterjet vs off-the-shelf) and make the plan airtight. Ran 4 parallel
web-research agents: (1) LED-wall mounting best practice, (2) off-the-shelf hardware,
(3) makerspace process-labor, (4) adversarial engineering validation.
- **Method verdict:** printing the custom parts + saw/drill the rails is least-*human*-labor
  by a wide margin (quantity is nearly free on a printer; waterjet needs 50 mm plate + tab-
  grinding, CNC needs ~3 setups/part, laser can't do it, custom extrusion die $750+). Print
  cleats on-side (support-free + shear along layers). Hobby Shop confirmed waterjet/mills/saws,
  no laser/router.
- **Validation caught 3 real problems** (skeleton was fine — wood 20-100× margin, PLA 4-5×
  under creep): 🔴 coplanarity (roughly-straight bar + 96 screws won't give invisible P5 seams;
  the Caudell jumbotron that used our exact magnet-on-bars scheme cable-tied panels on),
  🟠 magnet shear-only is marginal (friction ~15% of pull; needs a load-bearing ledge),
  🟠 5 m thermal growth (~1-2.4 mm) into a butt-tight row.
- **Design revised (CAD updated, collide-check clean):** (a) cleat → **tall C-bracket carrying
  BOTH rails** on one rigid spine = coplanarity datum you level once (jackscrew + slotted holes);
  (b) rails → **steel** (flat bar top + **angle** bottom whose leg is a continuous rest ledge →
  weight off the magnets, deletes 16 rest-shoes); (c) center-anchor + slotted rail holes (thermal);
  (d) bare 2-3 mm low-carbon steel for magnet grip. **Magnets KEPT** (owner owns/tested them +
  tool-free service; engineering says fine once weight's on the ledge & rail is flat) — bolt-in-
  sections documented as the fallback. Part count ~43 → ~25. Full cited writeup: `docs/design/
  MANUFACTURING_PLAN.md`; `MOUNT_PARTS.md` banner-flagged as superseded.
- Next: owner review; then print 1 cleat + 1 foot as fit coupons against the real grooves.

## 2026-07-02 — Mount hardware designed (all 6 parts) → `cad/parts/`
Built the whole mount as real CadQuery solids on ONE shared parameter set
(`cad/parts/mount_params.py`) so parts can't drift: **(1)** top cleat, **(2)**
anti-swing foot (base + slide-up tab), **(3)** panel rest shoe, **(4)** two alu bars
+ steel strip (cut list), **(5)** corner Pi/Bonnet enclosure, **(6)** PSU cradle.
Each exports STL + STEP + a fit-check PNG; `assembly.py` unions them all and renders
the full cross-section + a 3D section. Manifest: **`docs/design/MOUNT_PARTS.md`**.
Design calls: two independently wall-referenced rails (no ladder stiles); coplanarity
via the adjustable magnet screws (bars only need to be roughly straight); panels
self-space in X by butting from the corner; bottom capture is a SEPARATE slide-up
motion (kinematic constraint — the bottom groove opens up, a rigid drop-in tab would
hit the solid attach band). **Verified:** an automated boolean `collide_check()` — no
bracket shares volume with a panel or the piece. It CAUGHT a real 2 mm upright/piece
interference → fixed (upright now bears flush on the piece front, sharing the forward
load). Dropped from the earlier brief: the machined continuous T-slot rail (magnet
adjust makes it unnecessary) + the seam-alignment key (butting self-registers). Next:
owner review, then print PLA test coupons (one cleat + one foot) to check the
tongue/tab fit against the real grooves before batch-printing.

## 2026-07-02 — Corner + magnets + length confirmed → feed-topology reconsidered
Owner updates: usable wall length **201.5 in (~5118 mm)** ≈ 16×320=5120 mm (**exact fit, zero spare**).
The **left end is a room corner and the grooved piece turns it** → host the **Pi/bonnet (+ maybe a PSU)
in the corner** (hung or on the 3.4 cm ledge) — **resolves the depth-behind-panels question** (electronics
off to the side; connectors barely protrude). **Magnets tested → viable → GO MAGNETIC** (steel strips on
the aluminum rails + on-hand magnet screws, panels snap on/self-align + alignment pins). **Corner forces a
feed change:** center-fed 2×8 would need a ~2.5 m bonnet ribbon (HUB75 wants <~50 cm, research-backed) →
**propose a single chain of 16 from the corner** (`--led-chain=16 --led-parallel=1`, pwm_bits≈8–9, ~100 Hz —
fine for this static board; also removes the snake/180° flip). **Supersedes LOCKED 2×8, pending owner OK.**
Power: keep PSU2 near the right half (short 5 V runs) or a heavy bus if all-in-corner. Updated WALL_PROFILE,
MOUNT_DESIGN, HARDWARE.

## 2026-07-02 — Mount design, clean-slate (hang from the wooden pocket)
Owner asked to disregard the old §8 mount plan and design fresh given the confirmed wall pocket +
full Hobby Shop (wood + metal + print). Research: a wood French cleat holds 50–100+ kg and is
limited by its anchoring — but our pocket IS solid structural wood spanning the full width, and the
assembly is only ~10 kg → **~5–10× margin, hang straight from the pocket** (no stud lags/toggles).
The hard part is coplanarity over 5 m, not weight. New design in **`docs/design/MOUNT_DESIGN.md`**:
**wood ½″ Baltic-birch tongue-cleat in the pocket (hang) + two continuous aluminum T-slot rails
(flatness, top+bottom at the 144 mm M3 rows) + 3D-printed adjustable clips (per-panel micro-adjust)
+ bottom spacer (anti-swing, no new holes) + Pi/bonnet below the row + PSUs separate/vented.** Every
sustained-load link is metal or structural wood; prints only locate (no PLA creep). Honest
alternative documented: all-Baltic-birch modular cassettes (4×4 panels, CNC'd) — cheaper/in-house,
marginally less stable. Gating measurement: clear depth wall→lip-front + pocket-to-panel height
(decides Pi behind vs below). Marked `INVENTORY.md` §8 SUPERSEDED; pointed `FABRICATION.md` at it.

## 2026-07-02 — 3D-printing plan (MIT Hobby Shop: Bambu P2S/H2S + Form 3L)
Owner joined the MIT Hobby Shop. Confirmed (Charlotte Reiter) 3 printers (Stratasys gone):
**Bambu P2S** (256³), **Bambu H2S** (340×320×340, 65 °C chamber/350 °C hotend → PLA/PETG/ABS/ASA/PC/CF),
**Formlabs Form 3L** (resin). **PLA free** (only filament now, more soon); **resin $0.25/mL**. Wrote
**`docs/FABRICATION.md`** — the printed BOM per part, printer/material assignment, and the load path
integrating the wooden pocket (`WALL_PROFILE.md`) + the 80/20 spine (`INVENTORY.md` §8). **Key finding:**
PLA is the worst common filament for **creep** (sags under sustained load) → the ~12–15 kg hang goes
through METAL; printed parts locate/interface; reprint load-bearing parts (cleat hooks, PSU cradles)
in PETG/ASA on the H2S when stocked. Resin reserved for small precision/cosmetic (~$10–30 total).
Parametric CadQuery/build123d workflow proposed (`cad/`) for Claude/Codex-generated parts. Updated
`MIT_RESOURCES.md` with the confirmed lineup. Next: measure depth behind the 34 mm lip + panel weight,
then generate CAD for the cleat hook + panel bracket first.

## 2026-07-02 — Wall mount profile captured (full-width wooden cleat rail)
Owner sketched + confirmed the top-of-wall cross-section (photo `docs/design/wall_top_profile.jpg`).
It's a **full-width (~512 cm / ~201 in) structural WOODEN rail**: a 2 cm lip standing **3.4 cm
proud** of the wall, with a continuous **open-top pocket (1.4 cm wide × 5 cm deep)** behind it
(open from the top, closed at the bottom; piece anchored to the wall at its bottom). Ceiling → top
of piece = 22.5 cm; piece 14 cm tall. It's load-bearing ("holds a lot of weight"). This is a
**built-in full-width cleat rail** → the plan to **hang the entire 16-panel row (512 cm × 16 cm,
~8 kg) from a top cleat/tongue (≤1.4 cm) dropped into the pocket**, with the lip's 3.4 cm giving
standoff for cabling; PSUs mount separately. Full geometry, panel-row sizing, load path,
constraints, and on-site checks in **`docs/design/WALL_PROFILE.md`**; summarized in `HARDWARE.md`
(resolves panel "mounting method TBD") and `OPEN_QUESTIONS.md`. Took 3 sketch-reading passes to get
the geometry right (was NOT a stepped ledge, and the pocket is open at the TOP not the bottom).

## 2026-07-02 — Plane-swoop scene transitions + fuller center jet
A big airliner now swoops left→right on every scene change (flight↔flight, flight↔clock):
NEW screen reveals to the LEFT of the plane, OLD stays frozen to the RIGHT, with a bright
sweep line at the seam + a contrail (commit 14f435f, deployed + verified: 68/68 logos, 0
restarts, ~54% CPU steady, 51°C). Design doc image: `docs/design/swoop_preview.png`.
- **How the wipe works on a single-buffer renderer:** the display draws into ONE persistent
  canvas and each scene clears+redraws only its own zone per frame. `utilities/transition.py`
  installs a **clip window `[0,edge)`** that every primitive obeys during a wipe, so scenes
  only repaint the revealed left side and the OLD frame is left frozen on the right — no second
  framebuffer, no pixel readback. `edge` sweeps 0→WIDTH under the plane. Steady-state hot path
  is byte-identical (clip is `None`). Text can't be pixel-clipped in the C `DrawText`, so a
  whole-glyph **prefix** is drawn using the real binding's `CharacterWidth` (a straddling glyph
  sits under the wide plane body anyway).
- `install()` also **subsumes the Port-3 lane-offset shim** (the old ad-hoc `graphics.DrawText`
  `+64` monkeypatch is gone). `TransitionMixin` provides `set_pixel`/`draw_square` (offset+clip),
  overrides `reset_scene` to launch a swoop instead of a hard cut, and adds the `swoop` keyframe
  (alphabetically after all scene draws, before `sync`). Toggle: `config.TRANSITIONS_ENABLED`.
- **Two display variants:** repo `display/__init__.py` = clean (lane 0, parallel 1). The Pi runs
  a Port-3 variant (lane 64, parallel 3, `panel_type=FM6126A`) with the SAME transition wiring —
  deployed by hand (NOT rsynced), previous copy backed up on-Pi as `display/__init__.py.preswoop`.
- `journey.py`: center track plane is now a fuller mini-jet (2px fuselage + tail fin + swept
  wing), not a 1px stick. Offline validation: `tools/preview_transition.py` (swoop filmstrip).

## 2026-07-01 — Route accuracy + operator logos (NetJets/PAL/Envoy) + real plane sprite
Five field-reported fixes (commit f6e2904), deployed + verified on-Pi (68/68 logos, 0 restarts):
- **`BOS→???` for ENY4047 (real: BOS-DCA):** FR24's lightweight feed returned the origin
  but an empty destination that instant, and we cached that partial route for the full 30-min
  TTL — so it stuck. Now: partial FR24 routes are completed from adsbdb **only when adsbdb
  corroborates the endpoint FR24 already knows** (adsbdb is often a stale *different* leg —
  it had ENY4047 as PHX-SLC), and partial routes cache for just **25 s** (`INCOMPLETE_TTL`)
  so the next FR24 scan (refreshed every 20 s) fills the gap. Self-heals in ~25 s vs. never.
- **NetJets logo:** `EJA→1I`; wordmark from kiwi (served on white → white-keyed to alpha).
- **PAL Airlines (PVL7668) showed "AIRLINER":** `PVL→PB` + `AIRLINE_DB["PVL"]="PAL"`. Note
  **adsbdb mislabels ICAO PVL as an Italian operator "Professione Volare"** — our AIRLINE_DB
  overrides the name; PVL=PAL Airlines confirmed (IATA PB, callsign PROVINCIAL, airhex/wiki).
- **Envoy shown as "American Eagle":** `ENY` mapped to `MQ` (= American Eagle). Now `ENY→ENY`,
  keying Envoy's **own** navy "envoy" wordmark (Wikimedia SVG, rasterised via the MediaWiki
  thumbnailer). MQ.png (American Eagle) is now orphaned/unused but left on disk.
- **Center-panel plane** was a 7×5 blob → **14×5 side-view jet** (tail fin + swept wing +
  brightened nose tip) in `scenes/journey.py`.
- `tools/fetch_logos.py` gains a `SPECIAL_LOGOS` pipeline (non-avs sources + optional white-key)
  so NetJets/Envoy are reproducible; `PVL→PB` added to the avs map. Re-run reproduces all 66.

## 2026-07-01 — Single-panel flight-tracker app RUNNING LIVE (as a service)

Found the "one-screen" app already installed on the Pi at `/home/pi/vestor` (venv,
`rgbmatrix` + `FlightRadarAPI` import OK, `.env` present). Ran it and it's now **live and
persistent**: enabled `vestor.service` with a `User=root` drop-in (the hzeller lib must
start as root for GPIO, then drops privileges). `Restart=always`, starts on boot. Pulls
live Logan/Boston flights (found + detailed a real flight) + weather + clock.

**Port-3 shim (TEMP):** the test panel is on bonnet **Port 3** (lane 2), but the app
hardcodes `parallel=1` (Port 1). Rather than move the ribbon, patched the Pi's
`display/__init__.py`: `parallel=1→3` + a +64-row draw offset on `graphics.DrawText/
DrawLine` and `SetPixel` (app uses no image blits, so 3 primitives cover it). Backup at
`display/__init__.py.port1bak`. **REVERT before the full-wall build** (which uses 2×8
center-feed, `parallel=2`, Ports 1&2). Manage: `systemctl {start,stop,restart,status}
vestor`; `journalctl -u vestor -f`.

- Docs: RUNBOOK (+Phase-0-confirmed/operate section, fixed stale 6+5+5 → 2×8);
  OPEN_QUESTIONS + INVENTORY headline updated post-first-light. On-Pi code is a static
  copy (not a git repo) and slightly behind the repo's comment edits — functionally same.

## 2026-07-01 — ✅ FIRST LIGHT — Phase 0 COMPLETE

One panel fully lit and animating (demo -D4 pulsing color, all 32 rows, correct
colors), driven over Tailscale SSH from the Mac. **Every link validated together:**
CnGear FM6124HJ panel + Triple Bonnet + riser + LRS-350-5 (5 V, correct polarity) +
hzeller driver on the Pi 4.

**Confirmed working config (matches the locked plan exactly):**
`--led-rows=32 --led-cols=64 --led-gpio-mapping=regular --led-slowdown-gpio=4
--led-brightness=50` · **no `--led-panel-type`** (FM6124HJ = standard, no init — FM6126A
made no difference) · **default RGB sequence** (colors correct, no swap).

**The one gotcha (not config — physical):** the demo drives chain/lane 0 = bonnet Port 1;
the ribbon was on **Port 3**. A panel on the wrong port gets no data and shows a stuck
half-lit ("top-half white") block that looks like a driver fault but isn't. Drove it with
`--led-parallel=3` (lane 2 = Port 3) → full panel lit. Lesson: "only half lights / static
white" first suspect = wrong bonnet port or IN/OUT connector, not the panel-type.

**Next:** QC the remaining 15 panels on the rig (per-panel demo -D3/-D4/-D5), log 1-16,
keep spares; then full-wall build (mount + power distribution).

## 2026-07-01 — Pi ONLINE + bonnet working; WiFi root cause found (cmdline instance-id lock)

Long bring-up session. Bare Pi connected once, then nothing would connect (bonnet or
bare) for hours. **Root cause found by inspecting the SD boot partition:** `cmdline.txt`
had `ds=nocloud;i=rpi-imager-1781482529670` — the cloud-init instance-id **hardcoded in
the kernel command line**, which **overrides `meta-data`**. So the earlier "bump the
instance-id in meta-data" never took effect → cloud-init never re-rendered `network-config`
→ the added `Vestor` network was **never applied**; the Pi only ever knew `MIT`.

**Fix:** changed `i=` in `cmdline.txt` (+ matched `meta-data`) to a new value
(`vestor-fix-20260701`). Next boot, cloud-init re-provisioned → **`Vestor` + `MIT` both
configured**. Also added a `user-data` runcmd that writes `/boot/firmware/vestor-netdiag.txt`
(offline instrumentation) — validated + used.

**Confirmed working (root Tailscale SSH from the Mac):**
- Online via **MIT on 5 GHz** (ch 149), signal **-52 dBm/80% bare, -48 dBm/85% with the
  bonnet** → **the bonnet does NOT shadow the WiFi antenna**; all prior bonnet-WiFi
  failures were the config bug, not RF. `Vestor` hotspot kept as configured backup.
- Power clean: 42-44 C, `throttled=0x0` (official Pi brick + **riser header** for solid
  GPIO contact — the riser was required to clear the Pi 4 PoE pins; a marginal USB-C
  supply had caused brown-out before).
- **hzeller `demo` present** at `~/rpi-rgb-led-matrix/examples-api-use/demo` → first light
  ready once a panel is powered.
- Tailscale SSH works as `root` (identity auth, no password); `pi` sudo needs a password;
  `iw` not installed (use `nmcli` / `/proc/net/wireless`); nmcli can't modify the
  netplan-managed connections (powersave toggle deferred).

**Recommendations captured:** operational wall should use **MIT 5 GHz (or wired MITnet)**,
not a 2.4 GHz phone hotspot — 5 GHz also dodges the matrix's future 2.4 GHz RFI. Resolves
the OPEN_QUESTIONS Tailscale/reachability item.

**Next:** power one panel (LRS-350-5 + AC cord, 115 V, red->+V/black->-V) → run the demo
over SSH → first light.

## 2026-06-29 — PSU sizing confirmed: keep 2× LRS-350-5 (not downsizing)

Owner asked whether the lower-than-budgeted draw means a smaller/cheaper supply
would suffice (and whether to cancel the order). Worked the math:
- Per 64×32 P5 panel: **~4 A** full-white-full-bright conservative max (Adafruit); 2.4 A
  measured (WiredWatts). 16 panels = **64 A (max) / 38 A (measured)**; per-PSU (8) =
  32 A / 19 A. **Real use (BRIGHTNESS≤50 + dark content) ≈ 5–16 A total** (~10–20 %/PSU).
- **One PSU? No** — 64 A max > a single 60 A unit, and central feed reintroduces the
  voltage-drop the split avoids. **Keep two.**
- **2× LRS-350-5 (60 A): correctly sized** — 53 % at conservative peak, ~10–20 % typical.
- **Alternative considered: 2× LRS-200-5 (40 A, FANLESS).** Would suffice (32 A peak =
  80 %); main upside is fanless (silent/fewer failure modes) for a living-space wall.
- **DECISION: keep the LRS-350-5s.** Overspecced = cooler/longer life; the fan is
  thermostatic and won't run at ~10–20 % load (so fanless benefit is moot in practice);
  ~$15 savings not worth the cancel/reorder. Switch to 200s only if guaranteed-fanless
  is a personal priority — it's a preference, not a fix.
- No doc/BOM change (order stands). Recorded in `INVENTORY.md` §9.5.

## 2026-06-29 — Layout VALIDATED (research agents) → PSUs split + config notes

Validation research (data-integrity / power-injection+voltage-drop / grounding+thermal
sub-agents) against real long-row HUB75 builds. Layout sound; one change + notes
(`INVENTORY.md` §9.5):

- ✅ **2×8 center-feed confirmed** — 8/chain is the sweet spot; ghosting/tearing starts
  at 12+/chain (hzeller README + issue #1370). Center-feed halves worst-case run.
- ✅ **Per-panel power + 4 fuse blocks confirmed best practice** (HUB75 can't pass power;
  AusChristmasLighting consensus: fuse +only, common −, never tie the 2 V+ together).
- ✅ **Real draw lower than assumed:** 1.7–2.4 A/panel full white (WiredWatts measured),
  not 4 A → 7.5 A fuses + budget very comfortable.
- 🔧 **CHANGE: split the PSUs (one behind each half), do NOT center-stack.** (a) voltage
  drop ~4× less (far panel ~4.95 V; hzeller targets <50 mV); (b) **LRS-350-5 has a
  built-in fan** (verified — not convection) → don't block airflow, ~10–15 cm clearance;
  (c) inrush ~20 A cold-start each @115 V → separate outlets vs a 15 A breaker. **Double
  Stack Mount Kit now unused** (keep as spare).
- ⚡ **Grounding:** star-point bond PSU1 V− ↔ PSU2 V− ↔ Pi GND (data ground reference);
  never parallel V+.
- 📝 **Pi config notes** banked: pwm-bits=7, lsb-ns≈100→300, dither=1, isolcpus a core,
  **audio off + blacklist snd_bcm2835** (mandatory), slowdown 2–4. ~400–500 Hz.
- 📝 Magnet hold over 5 m is anecdotal → bench-test a few panels on the rail first.
- Changed: `INVENTORY.md` §9.5 (PSU split + grounding + config + draw). Diagram's center
  box → Pi+bonnet only; PSUs move behind each half.

## 2026-06-29 — Physical layout LOCKED (power pigtail = 55 cm)

Owner measured the panel power pigtail = **55 cm** (white 4-pin plug → 2 blue forks).
This sets the power distribution. Worked the full back-of-wall layout (`INVENTORY.md`
§9.5; diagram shown to owner):
- 55 cm reach ÷ 320 mm pitch ≈ **±1.7 panels → one fuse block serves ~4 panels.**
- **→ 4× 6-way fuse blocks** (not 2× 12-way), one per 4-panel group (1–4/5–8/9–12/13–16),
  fed by 10 AWG trunk from the center PSUs. Each panel's 55 cm pigtail reaches its block;
  no extension leads needed.
- **PSUs center-stacked** (uses the Double Stack Mount Kit) in a center "brain box" with
  the Pi + Triple Bonnet + AC entry — single service point. Data 2×8 center-feed
  unchanged; magnetic mount unchanged.
- **No redesign** — only the fuse-block count/spacing changed (2→4, +~$18). BOM total
  still-to-order ~$115–145.
- Launched a background agent to validate injection spacing / voltage drop / grounding /
  cable mgmt against real long-row HUB75 builds; fold in refinements.
- Changed: `INVENTORY.md` §9.2 (4× 6-way blocks) + §9.5 (layout resolved).

## 2026-06-29 — PSUs + magnets ordered; mounting revised to MAGNETIC

Owner placed Wired Watts order #225740 ($90.60): **2× LRS-350-5** ($29.50 ea — the
Phase-0/wall power blocker is now resolved, up to 10 biz days), a **Double Stack Mount
Kit** ($4.50, stacks the 2 PSUs), and **100× Panel Magnets** ($10, screw-in feet for
the M3 holes — "just in case").

- **⚠️ GAP: no AC cords ordered.** LRS-350-5 has bare L/N/⏚ terminals → needs **2× AC
  mains cords** (~$8 ea). Added to the still-to-order list. Set PSU input switch to 115 V.
- **Mounting revised → MAGNETIC** (`INVENTORY.md` §9.1/9.2). 100 magnets = 6×16 + spares,
  so screw a magnet into each panel's 6 holes and snap onto **2 ferrous rails** (Unistrut
  / steel flat bar) at the magnet-row heights. Tool-free service, no bracket printing.
  The earlier "reject magnets" was about a full steel *sheet*; 2 narrow rails avoid that.
  3D-bracket+extrusion kept as the fallback.
- **New open item (§9.5):** measure the **panel power-pigtail length** — it sets whether
  one fuse block per half reaches all 8 panels or we split/extend. Also the Stack Kit
  implies central PSU placement → plan 5 V runs to reach both ends, or mount split.
- Still to order (~$95–125): 2 AC cords, 2× Nilight fuse blocks, 7.5 A fuses, 10/14 AWG
  wire, 2 ferrous rails (free at MIT possible), wall anchors, optional clamp meter.
- Changed: `INVENTORY.md` §1 (ordered items + AC-cord gap), §9.1/9.2/9.3/9.4 (+§9.5).

## 2026-06-29 — Panels arrived: specs verified off the boards + framed-panel discovery

**Context:** the 16 panels landed. Owner photographed the backs (IMG_3780-82, HEIC →
converted + zoomed). Read exact specs directly off the PCBs.

**Verified on-board (supersedes listing-image assumptions):**
- Marking **`P5(2121)64×32-16S-JHT2.0`** → P5 pitch, SMD2121 LEDs, 64×32, **1/16 scan**.
- Pinout table on the board: **R1 G1 / B1 GND / R2 G2 / B2 GND / A B / C D / CLK LAT /
  OE GND** — standard HUB75, **A–D only (no E)**. Connector labeled **HUB75-D**, 16-pin 2×8.
- Driver **FM6124HJ** (chip UB2). `HJ` = package/grade variant of the standard FM6124;
  no init needed. (Listing image had said `FM6124ZD` — same family, no impact.)
- Power: **4-pin keyed plug** labeled `POWER` (NOT screw terminals).
- Brand **CnGear**; 220 µF/10 V decoupling caps.
- **Electrical verdict: 100% compatible, zero config changes** to the locked plan.

**Key new finding — FRAMED panels, not bare PCBs:**
- Each panel has an **integrated black plastic rear frame** (X-braced, brass corner
  screws). **No magnets included** (owner confirmed). This invalidates the prior
  "6 M3 magnet holes on a flat PCB back" mounting assumption and may affect whether the
  Hanson distro bolts flat. **§8 mounting + distro fit now PENDING owner detail.**

**Asked owner for (can't get from photos):** confirm 16 individual panels; panel
W×H×**depth** (incl. frame); straight-down photo of the frame's rear mounting
provisions; whether frames join/align panel-to-panel; full accessory inventory (power
cable type + count, data ribbon count + **length**, screws/clips, confirm zero magnets).

- Changed: `docs/INVENTORY.md` §6 (verified table + mounting-changed flag),
  `docs/HARDWARE.md` (FM6124HJ/CnGear/JHT2.0/framed). Docs only.

**Update (same day, later) — 3-AGENT OPTIMIZATION PASS → §9 final no-solder build:**
Owner asked to minimize parts/cost/hassle (no soldering) and check for prebuilt
options. Ran 3 research agents (power, mounting, prebuilt+control) across web + Reddit
+ xLights/Falcon forums. Outcome (full detail → `INVENTORY.md` §9):
- **Control = $0:** keep Pi 4 + Triple Bonnet + Python. No prebuilt 1024×32 wall worth
  buying (custom = several× panel cost, NovaStar-locked). NovaStar/ESP32 = downgrades.
  Keep 2×8 center-feed; cap `--led-pwm-bits 7–8`. **Rejected the agent's "3-lane/6+5+5"
  idea** — a 3rd chain needs a >50 cm jump in a 1-D row (the constraint that locked 2×8).
- **Power = ~$52, no-solder:** drop the 4 Hanson distros → **one 8-way ATC automotive
  fuse block (w/ negative bus) per PSU**; panel forks land directly (+5 V fused, GND on
  bus). Per-panel fusing kept (60 A rail + shorted 4 A panel = fire). Bare wire under
  screws → no crimp tool. **Corrected agent error:** PSU→block trunk carries full ~32 A
  (splits only *after* fuses) → **10 AWG, not 14 AWG**.
- **Mounting = ~$48 + free MIT parts:** 2020 extrusion + 3D-printed brackets (free at
  MIT). Magnets+steel **rejected** for a long thin row (flat 16.8 ft steel = heavy/
  pricey/not-flat). ~30 lb assembled → French cleat + few toggle bolts, no studs.
- **Net:** earlier ~$230–330 BOM → **~$100** (≈$155 if buying extrusion). Cut: Hanson
  distros, copper AWG6, crimp tool, bus bars, magnets/steel, data+power cables, 3rd PSU.
- Changed: `INVENTORY.md` §2 (fuse-block table), §7.1 (Hanson superseded), **+§9**.

**Update (same day) — mounting + cabling RESOLVED from frame/cable photos (IMG_3783-85):**
- Owner confirmed **16 individual panels**, each its own CnGear frame; **320 × 158 ×
  ~15 mm**; panels **do NOT interlock**.
- **Mounting interface:** frame has **6 brass M3-threaded holes** (4 corners + 2 mid-
  long-edge, 3×2 grid, ~144 mm vertical pitch) = the magnet-mount points. **Zero
  magnets** shipped → holes free for screws/brackets.
- **RECOMMENDED:** 80/20 backbone + **3D-printed brackets** (free at MIT) into the 6
  holes, locating panels coplanar; no magnets/steel needed; serviceable. Alt: buy ~64
  magnet feet + 2 steel strips on the rail. → `INVENTORY.md` §8.0.
- **Cabling fully included:** 16 short 16-pin IDC data ribbons (`UL2651 28AWG`) + 16
  power pigtails (white 4-pin plug → **blue fork** PSU end). **Buy neither.** Forks land
  on distro/bus-bar screw terminals → distro mounts on the **backbone** (144 mm-on-panel
  fit moot). → §6, §7.1, §7.3.
- Net buy-list shrinkage: no data cables, no panel power cables, no magnets (if bracket
  route). Real blocker still just 1× LRS-350-5 + AC cord.

## 2026-06-21 — Panel-spec compatibility check + single-row data-routing decision

**Context:** owner shared the actual MUEN P5 listing + module-back photos (driver
marked `FM6124(Z)D`, connector `HUB75-D`) and locked the physical layout to **one
long 16-wide row**. Deep-researched whether every spec is compatible end-to-end.

**Compatibility — all PASS (4 web-research passes, primary sources):**
- 64×32 / 1/16 scan / **A–D address (no E)** / HUB75-D pinout (R1 G1 / B1 GND /
  R2 G2 / B2 GND / A B / C D / CLK LAT / OE GND) = the standard HUB75 the Adafruit
  bonnet drives. Plug-compatible.
- **FM6124(Z)D ≈ ICN2037/ICN2038S** — basic constant-current driver, **no init**.
  Confirms `panel_type=""`; `FM6126A`→`FM6127` stays a black-screen-only fallback.
  The alarming `--led-row-addr-type=3` / forced-`FM6126A` GitHub threads are all
  **128×64 1/32-scan "ABC"** panels — NOT our 64×32 1/16 A–D panel.
- Likely live tweaks: **R/B swap** (`--led-rgb-sequence RBG/BGR`, common on FM6124),
  slowdown 4→5 if flicker. "Epstar" = LED emitter die brand, not the driver.
- Power re-confirmed: 16 × ~4 A design ≈ 64 A @ BRIGHTNESS=50 on 2× LRS-350-5
  (120 A). All-white-full = 128 A > 120 A → keep brightness capped (already do).

**Decision — single-row data routing → 2 chains of 8, fed from CENTER.**
HUB75 ribbons must stay <50 cm; a 16-panel row is ~5 m and all 3 bonnet ports are
co-located, so the old **6+5+5** plan would need **1.9 m + 3.5 m** jump cables to
the starts of chains 2 & 3 → corruption/flicker. **New plan:** Pi+bonnet
center-mounted, `--led-parallel=2 --led-chain=8`; chain 0 → left (panels 8→1),
chain 1 → right (panels 9→16). Every ribbon short (included cables suffice, no
extensions). 16 = 2×8 exactly (no wasted slots vs 3×6's 18-slot canvas). Refresh
stays in the hundreds of Hz on a Pi 4. **Cost:** left 8 panels mount **180°** and
that half is flipped in software (`display/__init__.py`, hardware canvas 512×64) —
the classic snake. Bring up first-light with the trivial `parallel=1 chain=16`,
then move to 2×8.

- Changed: `docs/HARDWARE.md` wall topology line (6+5+5 → 2×8 center-feed);
  `docs/INVENTORY.md` §5 (layout LOCKED) + §6 (panel-spec compat table) + §2
  (ribbon extensions struck — not needed). Supersedes the 6+5+5
  `pixel_mapper_config` TODO from the 2026-06-14 geometry note.
- Next: Phase 0 still gated on ≥1 LRS-350-5 + AC cord (see INVENTORY §2).

## 2026-06-21 — AliExpress review/QC pass (3 research agents)

**Context:** owner shared the listing's reviews + seller back-photos. Question:
"anything that needs to change?" Ran 3 parallel research agents (power/voltage-drop,
hzeller color uniformity, incoming-QC). **Bottom line: compatibility (§6) and the
2×8 center-feed topology (§5) are UNCHANGED.** Reviews are sourcing/QC issues, not
spec mismatches. Three hardening actions added → `docs/INVENTORY.md` §7:

1. **CCA wire / voltage drop (§7.1).** Included pigtails are likely copper-clad
   aluminum (~1.55–1.6× Cu resistance, won't solder). AWG10 Cu @32 A/2.5 m = 0.52 V
   drop → far panels redshift (blue sags first; *looks* like a driver bug). Fix is
   geometry+copper: center each PSU behind its half, inject 5 V at ≥2 points/half
   (4 total), keep the two PSU positives ISOLATED, ~40 A fuse each, crimp-not-solder,
   AWG6 Cu trunks. Updated §2 harness rows accordingly.
2. **Shade variation (§7.2).** All hzeller knobs are GLOBAL — no per-panel LUT, no
   NovaStar `.cal` ingestion. Per-panel = DIY `MapColors()` patch (issues #222/#193).
   Mitigate: same batch, low brightness, dark/sparse content (our aesthetic), warm-up.
3. **Incoming QC (§7.3).** Test all 16 individually with `demo` -D3/-D4/-D5/-D11/-D0
   before mounting; dead FM6124 = 16-px dead column, dead row = horizontal line.
   Log 1–16, keep 2–3 spares, RMA with video for partial refund. If dark/garbled,
   try `--led-panel-type=FM6126A` before condemning.

- Changed: `docs/INVENTORY.md` (+§7, updated §2 trunk/fuse rows). No code touched.

## 2026-06-21 — Software audit vs. locked plan (post-topology / post-QC)

**Context:** owner asked "anything on software that needs to change?" after the
topology + review/QC research. Audited the live code against the locked decisions.

**Found + FIXED (`display/__init__.py`):** the code still hard-coded the **rejected
6+5+5 wall plan** in its comments — told a future session to set `parallel=3,
chain=6` and to "build a mapper for the uneven 6+5+5 chains." That contradicts the
LOCKED 2×8 center-feed decision and would cause the wrong wiring/config. Rewrote the
comments to the 2×8 center-feed plan: `parallel=2, chain=8`, compose 1024×32 →
512×64 canvas with the LEFT half rotated 180° **in our code, not pixel_mapper_config**.
Also lowered the `except`-fallback `BRIGHTNESS` default **100 → 50** (+ slowdown
1→4, HAT_PWM True→False) so a missing config can't over-draw the 120 A PSU budget.

**Confirmed already-correct (no change):** `config.py` `BRIGHTNESS=50`,
`GPIO_SLOWDOWN=4`, `panel_type=""`, `row_address_type=0` all match the verified
panel spec + power budget.

**Big note written down:** the on-Pi app is STILL the upstream single-panel (64×32)
flight tracker. The full multi-zone 1024×32 design (weather + planes + Bluebikes +
shuttle, dual °C/°F) lives **only in `sim/`** — porting it (the 512×64 snake
composition layer + new data sources) is the real Phase-1 software build. Captured
as the ⭐ prerequisite at the top of `ROADMAP.md`. Also added TROUBLESHOOTING rows
for voltage-drop redshift, shade variation, and dead-IC/row signatures.

- Changed: `display/__init__.py` (comments + brightness fallback), `docs/ROADMAP.md`
  (wall-composition layer), `docs/TROUBLESHOOTING.md` (+3 rows). No behavior change
  to the running single-panel app.

## 2026-06-21 — Mounting & frame research (3 agents)

**Context:** owner asked where the "magnets/screws" claim comes from, whether the
wall free-stands, and how to buy/build a frame. Ran 3 research agents (panel mount
hardware, DIY frame/sag, free-standing physics + commercial options). New
`docs/INVENTORY.md` §8.

- **Provenance:** "magnet screws" traces to the **MUEN listing's "Free Parts" image**
  (owner-supplied), not a datasheet. Generic P5 modules usually ship 4 M3 magnet
  screws but it's vendor-dependent (Adafruit-brand ships none since 2020). Panel
  backs have **M3-threaded corner holes** regardless → screw-mount always works.
  Flagged "confirm on unboxing."
- **Free-stand: NO.** 32:1 aspect ratio, ~6.3" base → tips/bows/twists. Wall-mount
  (above the window, as planned) is the right fit.
- **Buy vs build: BUILD.** No off-the-shelf 1-tall × 16-wide frame; cabinets are
  640×480 / 960×960 (too tall), custom 1-row = OEM, truss stands ≈ $2000. DIY ≈ $200.
- **Physics:** `sag=5WL³/384EI`; unsupported 5.1 m sags badly (4040 ≈ 32 mm) but
  **intermediate support every ~3–4 ft makes any profile flat**. **Magnets need a
  FERROUS surface** (won't stick to alu/wood) → either screw panels via M3 corners
  (recommended) or add a steel sheet.
- **Recommended:** 80/20 1530 backbone, panels bolted via T-nuts, lag-screwed to
  studs (~$210). **Renter variant:** plywood/2040 backbone on French cleats +
  TOGGLER SNAPTOGGLE toggle bolts (~$190, ~6 fillable holes). Depth budget ~30–35 mm;
  total weight ~12–15 kg; build/carry in 2–3 sections (floppy until mounted).
- Changed: `docs/INVENTORY.md` (+§8 mounting/frame, §2 🟡 row + §7.3 caveat). Docs only.

## 2026-06-21 — Ecosystem gear scout (5 agents) → docs/GEAR.md

**Context:** owner asked to scour wiredwatts.com + adjacent vendor/community sites for
any tech that makes the build easier. Ran 5 domain agents (power, HUB75 cabling,
mounting, front-face/diffusion, reliability/remote-ops). New `docs/GEAR.md` (ranked,
with honest SKIP flags). Highlights folded into existing docs:

- **CCA fix:** ferrule kit + ratchet crimper (AWG6–10, ~$45) = gas-tight no-solder
  connection. **DC clamp meter** (UNI-T UT210E, ~$35) to verify the power plan
  (cheap meters read AC only). → noted in INVENTORY §7.1.
- **PSU-side distro:** Hanson **PDist1** (~$15 ×2) bolts onto LRS-350-5 terminals
  (4×15A+1×10A fused). **PSU has no remote-sense → trim output to ~5.1–5.2 V** to
  pre-compensate run drop. → INVENTORY §7.1.
- **Front face = dark TINT, not white diffuser** (white smears 5 mm text). Smoke-Gray
  #2064 acrylic deepens blacks + hides shade variation (§7.2). → ROADMAP finishing.
- **Reliability (all FREE, work with Tailscale/systemd):** systemd hardware watchdog,
  overlayfs read-only root, remote logging; **smart plug** (Shelly/Kasa) to remote-
  power-cycle the PSUs. → ROADMAP "always-on hardening". **Hard constraint logged:**
  Triple Bonnet eats the full 40-pin header → no GPIO UPS HATs / fan SHIMs.
- **Honest skips:** included ribbons cover 14/16 data links (only make 2 feed cables);
  Electrodragon board = the bonnet's active-3 (no gain); die-cast cabinets, 230V inrush
  units, Pi UPS HATs — overkill/wrong-spec.
- Changed: new `docs/GEAR.md`; INVENTORY §7.1 (PDist1 + PSU trim + clamp meter);
  ROADMAP (+hardening +finishing). Docs only.

## 2026-06-21 — Vetted Hanson "hanpaneldistro" fused power-distribution board

**Context:** owner found the Hanson Electronics "Panel Power Distribution" board
(wiredwatts.com, $14.50) and asked if it's useful/compatible. Vetted via research
agent. **Verdict: YES — buy 4.** It's the recommended concrete part for the §7.1
injection points.

- **What it is:** passive **5 V-in → 4× fused (7 A) 5 V-out** PCB, bolts to a panel
  back (144 mm M3 holes), 30 A board rating. = bus-bar + fuses + mount in one.
- **Compatible:** fully — touches only power rails, never HUB75 data, so identical
  behavior on Pi 4 + Triple Bonnet + hzeller. Falcon/xLights heritage irrelevant.
- **Derate:** the "8 panels" claim is a low-current **P10** figure. Our P5 pulls
  ~4 A (bright) to ~8 A (white) → **1 panel per 7 A fuse = 4 panels/board = 4 boards**
  for 16 panels (2 per PSU = the 4 injection points). Keep BRIGHTNESS≤50.
- **Better than 1× 40 A PSU fuse:** per-panel fusing isolates a shorted panel; panel-
  back mount shortens high-current runs (helps §7.1 voltage drop).
- **Doesn't replace:** PSUs, AC cords, copper trunk PSU→board (~16 A → AWG10+), or the
  common-ground bond. Nothing for data.
- **Sourcing:** US-stocked (Alpharetta GA, ~2–4 days). "Origin: Australia" = mfg only.
- **Bench-verify before buying 4:** (1) measure panel rear M3 hole spacing ≈144 mm;
  (2) clamp-meter one all-white panel vs 7 A fuse; (3) board-vs-frame-bracket M3 hole
  contention. US alts: Falcon3DParts, QuinLED Dig-Octa, CZH-Labs, or bus bars + ATO.
- Changed: `docs/INVENTORY.md` §7.1 (+distro recommendation) + §2 🟠 row. Docs only.

## 2026-06-21 — MIT on-campus build resources (3 agents)

**Context:** owner is an MIT grad student; asked whether they can build/source/3D-print
the frame on campus cheap/free. Ran 3 research agents (makerspaces+access, materials+
funding, 3D printing+printable parts). New `docs/MIT_RESOURCES.md`.

- **Build (free for grads):** **Hobby Shop (N51-120)** = one-stop metal shop (waterjet,
  MIG/TIG, lathes/mills, bandsaws, 3D printers; free, 1-hr orientation via hayami@mit.edu).
  **MITERS (N52-115)** = free, 24/7, no paperwork (mill/lathe/MIG/3D). **Project Manus
  Metropolis 6C-006B / The Deep 37-072** = FDM/SLA via free M1T training. None stock
  80/20 — bring your own metal.
- **Materials (free→cheap):** **#1 = `reuse@mit.edu` + `reuse-ask@mit.edu`** (post a
  request now). Swapfest (3rd Sun Apr-Oct), Edgerton Project Lab 4-409 (free ply/screws),
  FX shelving, MITERS scrap. Off-campus: Home Depot/ReStore.
- **Funding:** Project Manus **Design-to-Making mini-grant up to $500** (best fit) +
  $100 MakerBucks after training. Sandbox ($1K-25K) is venture-oriented.
- **3D print** the interface parts (corner T-slot brackets ×60, cable raceways, Pi/bonnet
  tray, PSU brackets, end caps) in **ABS/PETG/ASA — not PLA**; buy the structural metal.
  Free FDM at Metropolis/MITERS. Reusable designs on Printables.
- Caveat noted in-doc: access rules/fees change yearly — verify on arrival.
- Changed: new `docs/MIT_RESOURCES.md`; `docs/INVENTORY.md` §8 cross-link. Docs only.

## 2026-06-14 — Dry session plan (no hardware)

**Goal of this session:** every software/repo/config/script task achievable with NO LED
panels attached. STOP before any live panel hardware test (hard stop #5).

**Environment discovered (Mac, this session):**
- git 2.50.1, gh 2.83.2 **authenticated as `g-vansh`** (scopes: repo, workflow) → can create + push the repo autonomously.
- brew 5.1.11, python3 3.14.5, openssl 3.6.2.
- Installed this session: shellcheck 0.11.0, Raspberry Pi Imager (cask).
- **No SD card present** (only internal disk0/disk9 + disk images) → flashing is PENDING (hard stop #1, no card to risk).
- **Pi not reachable** (`flightwall.local` / `flightpi.local` both silent) → all Pi-side steps PENDING.
- Network to github.com OK.

**Plan (mirrors AGENTS.md §7 / master prompt execution plan):**
1. [done] Read AGENTS.md + scaffold + setup guide. Write this plan.
2. [done] Mac tooling: shellcheck + rpi-imager installed & verified.
3. Repo: cloned upstream `ColinWaddell/its-a-plane-python` → `flightwall`, renamed origin→`upstream`. Overlay scaffold. Create `g-vansh/flightwall`, push main.
4. Overlay scaffold files/scripts; verify tree.
5. GPL: keep upstream `LICENSE`; finalize `NOTICE.md` attribution.
6. Edit `display/__init__.py` → Triple Bonnet options (regular / FM6126A / parallel=1 test, 3 wall / HW pulsing on).
7. Write `config.py` (540 Memorial Drive geometry + Pi4 tuning, no secrets).
8. Secrets: gitignored `.env` + `config_secrets.py` placeholders; commit only `.example` templates; verify git status clean.
9. Flicker/quality tweaks in scripts; validate `bash -n` + shellcheck.
10. systemd service: venv python, not root, correct entry point.
11. SD flashing prep: `flash_sd.sh` + `custom.toml` (mark flashing PENDING — no card).
12. Pi-side steps → PENDING in OPEN_QUESTIONS.md with exact commands.
13. Final verification + report.

**Key decisions made this session (recorded, not stalled):**
- **Repo strategy:** clone-and-re-point (not fork). Keeps full upstream history + lets us `git fetch upstream` later. `origin` → `g-vansh/flightwall`, `upstream` → ColinWaddell.
- **Entry point:** upstream's real entry is `flight-tracker.py` (NOT `main.py`). The scaffold `services/flightwall.service` shipped `main.py` — **corrected to `flight-tracker.py`**. (Discrepancy with scaffold; the actual file on disk wins.)
- **Hostname:** master prompt says `flightwall` (`flightwall.local`); AGENTS.md + setup guide say `flightpi`. **Chose `flightwall`** (matches repo/project name, master prompt is the immediate instruction). Standardized scripts/docs/.env to `flightwall.local`. Owner can override — see OPEN_QUESTIONS.md.
- **Secrets in config.py:** `config.py` is committed and must stay secret-free, but `scenes/weather.py` does `from config import OPENWEATHER_API_KEY`. Resolved by reading keys from `os.environ` in `config.py` (`os.environ.get(...)`), populated by `.env` via the systemd `EnvironmentFile`. No gitignored-file import at module top (would crash the whole app if missing).
- **gpio_slowdown / brightness in display:** kept upstream's config-driven `options.gpio_slowdown = GPIO_SLOWDOWN` / `options.brightness = BRIGHTNESS` (config.py sets GPIO_SLOWDOWN=4, BRIGHTNESS=50) rather than hardcoding — resolves to the prompt's values while staying DRY.

**config.py symbol contract (from grepping the codebase):** required `WEATHER_LOCATION`,
`ZONE_HOME`, `LOCATION_HOME`, `BRIGHTNESS`, `GPIO_SLOWDOWN`, `HAT_PWM_ENABLED`; used-optional
`TEMPERATURE_UNITS`, `MIN_ALTITUDE`, `JOURNEY_CODE_SELECTED`, `JOURNEY_BLANK_FILLER`,
`OPENWEATHER_API_KEY`. (`RAINFALL_ENABLED`, `LOADING_LED_ENABLED/_GPIO_PIN` are guarded by
try/except in the code and intentionally left unset → disabled.)

---

## Log entries

### 2026-06-14 — Repo established
- Did: cloned upstream → `flightwall`; `git remote rename origin upstream`; installed shellcheck + rpi-imager; overlaid scaffold (AGENTS, README, NOTICE, .gitignore, .env.example, config_secrets.example, docs/, scripts/, services/).
- Verified: `git remote -v` shows `upstream` → ColinWaddell; `LICENSE` present (GPL-3.0, 35 KB); tree matches intended layout.
- Changed from brief: none structural. Scaffold `.gitignore` replaces upstream's (which ignored `config.py` — we commit `config.py`).
- Next: display edit, config.py, secrets, scripts, service, push.

### 2026-06-14 — Config, code edits, scripts, service (all dry)
- Did:
  - `display/__init__.py`: replaced single-bonnet options with Triple Bonnet active3
    (`hardware_mapping="regular"`, `panel_type="FM6126A"` added, `chain_length=1`/`parallel=1`
    for Phase 0 with wall values commented, `disable_hardware_pulsing=False`, `drop_privileges=True`).
  - `config.py`: 540 Memorial Drive geometry (ZONE_HOME/LOCATION_HOME), MIN_ALTITUDE=100,
    BRIGHTNESS=50, GPIO_SLOWDOWN=4, JOURNEY_CODE_SELECTED="BOS", weather Cambridge,MA,US;
    keys read from os.environ (no secrets committed).
  - Secrets: created gitignored `.env` + `config_secrets.py` (placeholders, chmod 600);
    committed only `.env.example` + `config_secrets.example.py`.
  - Scripts: rewrote `flash_sd.sh` (canonical Bookworm custom.toml, refuses internal disk,
    requires ERASE + filled toml); added `scripts/custom.toml.example`; `.gitignore` now
    blocks the filled `custom.toml`. `setup_pi.sh` already covers blacklist snd_bcm2835 +
    audio=off + isolcpus=3 (with .bak backups, single-line append).
  - `services/flightwall.service`: corrected entry point `main.py`→`flight-tracker.py`,
    added PYTHONUNBUFFERED; runs as `pi` (not root).
- Verified:
  - `python3 -m py_compile` clean on display/__init__.py + config.py; config symbol contract PASS.
  - display grep shows regular / FM6126A / parallel / drop_privileges.
  - `bash -n` + `shellcheck` clean on all 4 scripts.
  - `git check-ignore` confirms `.env` + `config_secrets.py` ignored; `git status` shows no secrets.
  - systemd unit structural check PASS (not root, flight-tracker.py present).
- Changed from brief: entry point `main.py`→`flight-tracker.py`; hostname `flightpi`→`flightwall` (repo-wide).
- Next: commit in logical groups, create `g-vansh/flightwall`, push main. Flashing + all Pi steps PENDING (no card, Pi offline).

### 2026-06-14 — Rebrand to "vestor" (owner code name)
- Did: owner set the project code name to **vestor**. Standardized the whole repo:
  - `git mv flight-tracker.py vestor-tracker.py`; `git mv services/flightwall.service
    services/vestor.service` (ExecStart + WorkingDirectory + EnvironmentFile →
    `/home/pi/vestor`, entry point `vestor-tracker.py`).
  - Hostname `flightwall` → `vestor` everywhere (`vestor.local`): scripts, AGENTS,
    RUNBOOK, OPEN_QUESTIONS, `.env`/`.env.example` PI_HOST, `custom.toml.example`.
  - On-Pi path `/home/pi/flightwall` → `/home/pi/vestor`; clone URL + repo refs
    `g-vansh/flightwall` → `g-vansh/vestor` (install_app.sh, install_service.sh, AGENTS).
  - Brand `FlightWall` → `Vestor` in README, NOTICE, config.py header, display comment.
  - Fixed stale `main.py` entry-point refs in AGENTS/RUNBOOK → `vestor-tracker.py`.
- Verified: `git grep -i flightwall` / `flight-tracker` → no tracked refs remain
  (except upstream artifact `assets/FlightTracker.service`, left untouched for
  attribution); `python3 -m py_compile` clean; `bash -n` clean on scripts.
- Owner inputs received this session: WiFi SSID/password, pi password = `vestor`
  (baked only into gitignored `scripts/custom.toml`, never committed).
- Changed from brief: code name flightwall → vestor (owner instruction); GitHub repo
  renamed to `g-vansh/vestor` (flagged in OPEN_QUESTIONS).
- Next: generate gitignored `custom.toml`, commit+push, flash SD (rpi-imager GUI —
  device confirmation needed), then owner powers on the Pi.

### 2026-06-14 — SD card flashed (rpi-imager GUI, screen-controlled)
- Did: flashed the microSD (in this Mac's built-in SDXC reader) with **Raspberry Pi
  Imager v2.0.8**, driven via screen control after the owner explicitly confirmed the
  target device AND authorized GUI automation ("yes i can confirm both").
  - Device = Raspberry Pi 4; OS = **Raspberry Pi OS Lite (64-bit)**; Storage =
    "Apple SDXC Reader Media" (verified earlier as 58.2 GB / `/Volumes/Untitled` —
    NOT the internal SSD; satisfies hard stop #1, 100% device certainty).
  - Applied settings via Imager's **built-in OS Customisation wizard** (not custom.toml):
    hostname `vestor`; locale Washington D.C. → tz America/New_York, keymap us;
    user `pi` / password `vestor`; Wi-Fi SSID `MIT` (password verified char-by-char via
    the reveal eye before writing); **SSH enabled, password authentication**; Raspberry
    Pi Connect left OFF (declined cloud sign-in — local SSH is sufficient).
  - Confirmed the ERASE warning named "Apple SDXC Reader Media" before clicking
    "I UNDERSTAND, ERASE AND WRITE". Imager v2.0.8 began the write without prompting for
    the macOS admin password.
- Changed from brief / deviations (recorded, not stalled):
  - **OS version: Bookworm → Trixie.** Imager no longer offers a Bookworm 64-bit Lite
    image; the current "Raspberry Pi OS Lite (64-bit)" is Debian **Trixie**-based. Chose
    Trixie Lite 64-bit. Implication: the hzeller `rgbmatrix` build + `gpio_slowdown=4`
    were tuned for Bookworm; Trixie ships a newer kernel/libgpiod, so re-confirm timing
    at the Phase 0 single-panel test.
  - **First-boot config method: Imager wizard, not `custom.toml`.** The settings were
    baked into the image by the wizard, so the gitignored `scripts/custom.toml` is now a
    redundant backup path rather than the active mechanism. No plaintext secrets land on
    the FAT boot partition this way.
- Verified: write initiated; "Writing in progress — do not disconnect the storage
  device" / "Unmounting drive…" observed. (Completion + eject pending.)
- Next: confirm "Write Successful", eject the card, owner inserts it in the Pi and powers
  on. Then SSH to `vestor.local` (pi/vestor). STOP before any live LED-panel test (#5).

### 2026-06-14 — Tailscale first-boot enrollment (reachability fix, coded)
- Context: the Pi booted fine but is **unreachable** over MIT's "MIT" SSID. That SSID
  is a Juniper Mist **per-user-PSK (BYOD/IoT)** network with **client isolation +
  blocked mDNS by design** — `vestor.local` never resolves, the Mac's ARP table shows
  only the gateway, and MIT publishes no DNS for the device. Mac SSH client itself
  verified healthy (OpenSSH 10.2, GitHub auth OK), so this is a network-fabric block,
  not an SSH problem. MIT SECURE (802.1X) rejected: storing a Kerberos master
  credential on a wall appliance is brittle + a credential-exposure risk, and likely
  wouldn't fix peer reachability anyway. Personal APs/routers are barred on MITnet.
- Decision: **Tailscale** overlay mesh. The Pi dials OUTBOUND (WireGuard / DERP
  relays) to the tailnet, sidestepping L2 isolation; opens no inbound ports; is not a
  personal AP → MITnet-policy-compliant. Keeps the Pi on the correct MIT PSK Wi-Fi.
  Doubles as the connectivity test (node appears in the Tailscale admin console).
- Did (all code, no hardware, no secrets committed):
  - `scripts/tailscale_bootstrap.sh` — **[PI] stage-2** oneshot. Idempotent +
    self-cleaning: installs Tailscale if missing, `tailscale up --hostname=vestor
    --ssh --accept-dns=false` using a key read from `/etc/vestor/tailscale.authkey`,
    reports the tailnet IP, then **shreds the key and `systemctl disable`s itself**.
  - `services/vestor-tailscale-bootstrap.service` — `Type=oneshot`,
    `After/Wants=network-online.target` (install + control-plane both need internet,
    which the early firstrun stage lacks). No `Restart=`; stays enabled so a failed
    run retries next boot, script self-disables on success.
  - `scripts/install_tailscale_firstboot.sh` — **[MAC]** stager. Run AFTER Imager's
    wizard flash, BEFORE eject. Copies the 3 payload files into `<bootfs>/vestor/`
    and **prepends a fully `|| true`-guarded block after firstrun.sh's shebang**
    (stage 1) that, on first boot, installs the script+unit+key into the rootfs and
    enables the oneshot. Self-guarded so it can NEVER abort the wizard's `set -e`
    Wi-Fi/SSH setup. Idempotent (marker-guarded). **Does NOT touch cmdline.txt**
    (hard stop #2 untouched).
  - `scripts/vestor-tailscale.auth.example` (committed) + gitignore for the real
    `vestor-tailscale.auth` / `*.authkey` (hard stop #3).
- Verified: `bash -n` + `shellcheck` clean on both scripts; `git check-ignore`
  confirms the real auth-key file is ignored; **dry-ran the stager against a synthetic
  bootfs/firstrun.sh** → block injected after shebang, result still valid bash, second
  run idempotent (1 marker), cmdline.txt line-count unchanged, key staged chmod 600.
- Two-stage rationale: Tailscale is *how* we'll get SSH, so it can't be installed
  *over* SSH — it must self-bootstrap from the card. Stage 1 (firstrun, no network)
  only drops a persistent unit; stage 2 (next boot, network up) does the networked
  install + enroll.
- Changed from brief: adds a VPN layer not in the original plan, forced by MIT client
  isolation. `ssh pi@vestor.local` (mDNS) is replaced by `ssh pi@vestor` over the
  tailnet (Tailscale SSH / MagicDNS).
- Next (owner-gated): owner creates a free Tailscale account + a **Reusable +
  Pre-approved** auth key → I re-flash (cached Trixie image, same settings) + run the
  stager + eject → owner powers on → `vestor` appears in the console → install
  Tailscale on the Mac → `ssh pi@vestor` → run setup/install scripts. STOP before any
  live LED-panel test (#5).

### 2026-06-14 — Tailscale armed on the existing card (no re-flash) + key received
- Owner provided the Tailscale auth key (Reusable). Stored ONLY in gitignored
  `scripts/vestor-tailscale.auth` (chmod 600); `git status` confirms untracked.
  Owner also installed + logged into Tailscale on the Mac.
- Decision: **skip the re-flash.** The card already boots and joins MIT Wi-Fi
  (proven), so instead of erasing a working install (and driving the Imager GUI
  again) I re-armed the Pi's own first-boot mechanism directly on the FAT `bootfs`
  partition. macOS can't write the ext4 rootfs, so a tiny on-Pi `firstrun.sh` is the
  bridge that copies the payload into the rootfs and enables the one-shot.
- Did (card in Mac's SD slot = `/dev/disk9`, boot partition `/Volumes/bootfs`;
  positively NOT the internal SSD = disk0/disk3, 500 GB APFS):
  - Backed up `cmdline.txt` → `cmdline.txt.bak` (hard stop #2).
  - Staged `bootfs/vestor/{tailscale_bootstrap.sh, vestor-tailscale-bootstrap.service,
    vestor-tailscale.auth}`.
  - Wrote `bootfs/firstrun.sh` (set +e, guaranteed `exit 0`; installs the stage-2
    one-shot + key into the rootfs, `systemctl enable`, shreds the FAT key copy, logs
    to `bootfs/vestor-firstboot.log`, then strips its own token + deletes itself).
  - Appended exactly one token to the single-line `cmdline.txt`:
    `systemd.run=/boot/firmware/firstrun.sh systemd.run_success_action=reboot
    systemd.unit=kernel-command-line.target`.
  - Captured the whole procedure as a reusable, shellcheck-clean script:
    `scripts/rearm_tailscale_existing_card.sh` (idempotent; verifies one line; restores
    backup if the edit ever produced >1 line).
- Verified: `firstrun.sh` passes `bash -n`; `cmdline.txt` 169→282 bytes, still ONE
  line, no trailing newline, `diff` shows ONLY the appended token, token present once;
  AppleDouble metadata cleaned (`dot_clean`); card ejected (`diskutil eject` →
  "disk9 ejected", device gone).
- Boot flow expected: power on → systemd runs firstrun (early, no net) → installs +
  enables `vestor-tailscale-bootstrap.service` → reboots → service waits for
  network-online → installs Tailscale + `tailscale up --hostname=vestor --ssh` →
  shreds key, self-disables. `vestor` then appears in the Tailscale console; reach via
  `ssh pi@vestor`. ETA a few minutes after power-on (Tailscale download dominates).
- Changed from brief: chose the no-reflash re-arm over the documented re-flash path
  (`install_tailscale_firstboot.sh`); both now exist in the repo.
- Next: owner powers on the Pi. STOP before any live LED-panel test (#5).

### 2026-06-14 — On-Pi provisioning over Tailscale (driver + app + service, NO panel)
- Owner confirmed "vestor is on tailscale now." Pi enrolled: `vestor` @ `100.91.127.127`
  (direct LAN path 10.31.134.31). SSH works over the tailnet via **Tailscale identity
  auth** — no Unix password needed (`ssh pi@100.91.127.127`, Trixie, Python 3.13.5).
- Did (all over SSH, as `pi`, never root; sudo via `echo vestor | sudo -S`):
  - git + clone `g-vansh/vestor` → `~/vestor`; clone hzeller upstream matrix →
    `~/rpi-rgb-led-matrix` (commit `41809e4`, 2026-06-07).
  - apt build toolchain: build-essential, python3-dev/venv, **cmake + ninja-build**,
    libcap2-bin, curl.
  - venv `~/vestor/env`; upgraded pip/wheel; Cython.
  - Built the `rgbmatrix` binding from the matrix **repo root** via scikit-build-core +
    CMake, then `pip install` of app deps with `rgbmatrix` filtered out. `import
    rgbmatrix` → **OK**.
  - `setcap cap_sys_nice=eip` on the resolved interpreter (`/usr/bin/python3.13`) for
    non-root RT scheduling (#4). Verified via `getcap`.
  - Scaffolded `.env` (chmod 600; weather/MBTA keys optional, default ""). Byte-compiled
    app sources; ran a **hardware-free import smoke test** (`import config; import
    display` — `BRIGHTNESS=50`, full scene/animator/rgbmatrix import graph resolves
    WITHOUT constructing `RGBMatrix`, which only happens in `Display.__init__`).
  - Flicker tweaks (root, with backups): `dtparam=audio=off` in config.txt; blacklist
    `snd_bcm2835`; appended `isolcpus=3` to cmdline.txt — verified still **ONE line**,
    no trailing newline (#2). Backups: `config.txt.vestorbak`, `cmdline.txt.vestorbak`.
  - Installed `vestor.service` + daemon-reload, then **left it `disabled` + `inactive`**
    — the panel must not start unsupervised (#5).
- **Key deviation (driver build):** modern hzeller upstream moved Python packaging to
  **scikit-build-core/CMake with a root `pyproject.toml`** — there is NO
  `bindings/python/setup.py` anymore, so the old `pip install bindings/python` fails.
  Correct path is `pip install <repo-root>`, which needs cmake + ninja. Its CMakeLists
  also compiles `shims/pillow.c` unconditionally, which `#include`s Pillow's private
  libImaging headers (`Imaging.h`, `ImPlatform.h`, `Mode.h`, `Arrow.h`,
  `ImagingUtils.h`) — NOT shipped in Pillow wheels. Fix: fetch those 5 headers (pinned
  Pillow 12.2.0) onto `CPATH` at build time only. The app never calls
  `SetImage(PILImage)` and the shim doesn't link libpillow, so this adds **no runtime
  Pillow dependency** (Pillow stays absent from requirements.txt).
- Reconciled the repo scripts to this proven process (shellcheck-clean):
  `setup_pi.sh` (drop the interactive Adafruit installer → apt cmake/ninja + clone
  upstream; newline-safe cmdline edit), `install_app.sh` (repo-root scikit-build-core
  build + CPATH Pillow headers + filtered requirements + correct ordering),
  `install_service.sh` (install only — no `enable --now`), and RUNBOOK steps 3–5.
- Verified: `rgbmatrix import OK`; app import graph OK; `getcap` shows cap_sys_nice;
  cmdline.txt = 1 line; `systemctl is-enabled vestor` = disabled, `is-active` = inactive.
- Changed from brief: adapted to upstream's scikit-build-core migration (cmake/ninja +
  Pillow-header workaround) — not anticipated in the brief, which assumed the classic
  `make` + `bindings/python` build.
- Next: **supervised Phase 0** — wire ONE panel (data→Port 1, power→PSU), `systemctl
  start vestor` (or run `vestor-tracker.py`) WHILE watching; tune rgb-sequence /
  row-address / gpio-slowdown on real hardware; only then `systemctl enable vestor`.

## 2026-06-14 — Pre-hardware validation (panels ~2 weeks out)

**Goal:** while the 16 P5 panels ship, (a) deeply confirm the whole hardware chain is
compatible and (b) run every software test possible WITHOUT panels, to maximize Phase 0
confidence. No live LED test (hard stop #5 still in force).

**Panels being bought (owner, confirmed from listing photos):** 16× MUEN P5 indoor,
320×160 mm, **64×32**, **1/16 scan**, HUB75, SMD2121, 5V, driver chip **FM6124D**.
Driven by the Adafruit **Triple** RGB Matrix Bonnet (PID **6358**, "active3"); powered by
**2× Mean Well LRS-350-5** (5V/60A each).

### Research (3 web-research passes, primary sources) — findings & what changed
- **Triple Bonnet 6358 → `hardware_mapping="regular"` (NOT adafruit-hat), `parallel=3`.**
  Adafruit's own guide: the active3 pinout = library `regular` mapping + `--led-parallel=3`
  (there is no mapping literally named "active3"). The `adafruit-hat`/`-pwm` mappings only
  support 1 parallel chain. **Confirms our committed config.** The Address-E line is
  irrelevant for 64×32 1/16-scan panels (A–D only); the bonnet's on-board E switch matters
  only for 64×64. `disable_hardware_pulsing=False` is correct (the no-hardware-pulse flag is
  debug-only and hurts stability; the right fix for the PWM/audio conflict is blacklisting
  `snd_bcm2835`, already done).
- **FM6124D needs NO init sequence → `panel_type` should start EMPTY.** FM6124 is a standard
  constant-current driver (like MBI5124/ICN2038S); only **FM6126A**/**FM6127** need a
  power-on init string. The `demo` binary's own `--help` lists only `FM6126A`/`FM6127` as
  supported panel-types — FM6124's absence is deliberate. Forcing `FM6126A` onto an FM6124
  sends register writes it interprets as pixel data → garbage, which masks a working panel.
  **CHANGE:** `display/__init__.py` `panel_type` `"FM6126A"` → `""`, with a comment demoting
  `FM6126A`→`FM6127` to fallback #1 (set only if the panel stays black, then remove again).
- **Power: 2× LRS-350-5 = 120 A / 600 W is comfortable for real content, NOT for all-white.**
  LRS-350-5 is 5V/60A/**300W** (derated; "350" is the series, not the 5V wattage). Per 64×32
  P5 panel: ~8A all-white max, ~4A Adafruit design figure, ~2A typical. 16 panels: all-white
  **128A/640W = 107% (over)**; design **64A/320W = 53%**; typical **32A/160W = 27%**. Verdict:
  fine for flight-tracker content, but cap brightness so a stray full-white frame can't exceed
  capacity — our `BRIGHTNESS=50` already ~halves worst case (→ ~64A, well within 120A). For
  unrestricted full white, add a 3rd LRS-350-5. **Injection:** parallel-inject 5V at every
  panel/pair (never daisy-chain power through HUB75), bus-bar topology, AWG 10–12 trunks /
  AWG 14–16 pigtails, keep the far panel ≥4.8V, common-ground all PSUs + the Pi/HAT.

### Tests run on the Pi (network/CPU only — no LED hardware)
- **Live flight-data fetch (FlightRadar24 / `utilities.overhead.Overhead`)** for the Cambridge
  ZONE_HOME: **PASS** — returned a live flight (e.g. `DAL888` A321 MCO→BOS @650ft). Benign
  noise: FR24 sets `Content-Encoding: gzip` on already-decompressed JSON; the API layer logs a
  warning and falls back to raw bytes (parses fine). Data items are **dicts**
  (`plane/origin/destination/vertical_speed/altitude/callsign`), which is what the scenes read.
- **End-to-end headless render via RGBMatrixEmulator (`raw` adapter):** **PASS.** Added a
  committed test harness `tools/emulator_capture.py` + a `tools/rgbmatrix_emulator_shim/`
  package that makes `import rgbmatrix` resolve to the emulator (inserted at `sys.path[0]`, no
  app source edits). Ran the REAL `display.Display()` and captured 12 PNG frames. Visual
  inspection confirmed: **clock** (`23:46`), **day/date** (`Sunday 14-6-2026`), and a full
  **live-flight render** (`DCA ▶ BOS`, `AAL3207`, `1/2`, `Airbus`) — i.e. clock/day/date/weather/
  overhead/journey/plane-details scenes, fonts, colours, and scene transitions all render
  correctly. (Emulator + its Pillow dep installed in the venv for testing only; not a runtime
  dependency of the app.)

### Bug found & fixed via the render test
- **`scenes/weather.py: grab_current_temperature` crashed the whole app** when a temperature
  fetch fails AND `TEMPERATURE_UNITS="imperial"`: it caught `WeatherError`, left `current_temp`
  = `None`, then ran `None * (9.0/5.0)` → `TypeError`. That `TypeError` is not a `WeatherError`,
  so it escaped the provider loop's `except WeatherError` and killed the app. This path triggers
  whenever the (optional) weather provider is unreachable — i.e. it would also crash on real
  hardware. **FIX:** guard the conversion (`if units == "imperial" and current_temp is not
  None:`) so failure returns `None` — the contract the caller already handles (`if
  self.current_temperature:`). Re-ran the render test: all 12 frames clean, exit 0.

### Geometry math (validated)
- **Phase 0:** 1×64×32 P5 = 2048 px; 64×5mm × 32×5mm = **320×160 mm** — matches the datasheet
  (P5 pitch internally consistent).
- **Phase 1 wall (6+5+5):** hzeller requires a **uniform** `chain_length`, so canvas =
  `chain_length=6 × parallel=3` = **384×96** logical px. 16 real panels = 32 768 lit px; the
  remainder **4096 px = exactly 2 panel-slots** are unused/dark (the missing 6th panel on the
  two 5-panel chains). Physical rows: 1920 / 1600 / 1600 mm wide × 480 mm tall. **Phase-1 TODO:**
  a `pixel_mapper_config` (e.g. `Rotate`/`Remap`) to fold the layout into the intended physical
  shape — exact mapper depends on the final wall arrangement (not yet locked); leave the two
  tail slots unrendered or remap them out.

### Phase 0 supervised test plan (ready; DO NOT run until owner present + panel wired)
hzeller `demo` binary already built at `~/rpi-rgb-led-matrix/examples-api-use/demo` (ARM64,
verified via `--help`; not yet run on hardware). With ONE panel (data→Port 1, power→PSU):
1. **Driver-level smoke test** (sudo; drops privs after init):
   `sudo ~/rpi-rgb-led-matrix/examples-api-use/demo -D0 --led-gpio-mapping=regular
   --led-rows=32 --led-cols=64 --led-chain=1 --led-parallel=1 --led-slowdown-gpio=4
   --led-show-refresh`  (NO `--led-panel-type` first; FM6124D is standard).
2. **Tuning ladder if output is wrong:** black → add `--led-panel-type=FM6126A` (then `FM6127`),
   then REMOVE again · wrong colours → cycle `--led-rgb-sequence` RBG/GRB/GBR/BRG/BGR ·
   split/doubled rows → `--led-multiplexing=1..3` · scrambled rows → `--led-row-addr-type=1/2` ·
   flicker → raise `--led-slowdown-gpio` to 5. Confirm refresh >100 Hz (>300 Hz if filmed).
3. **Then the app:** `sudo systemctl start vestor` + `journalctl -u vestor -f` while watching;
   port the winning rgb-sequence/row-addr/slowdown into `display/__init__.py`; only once correct
   `sudo systemctl enable vestor` for boot persistence.

- Did: 3 research passes; reconciled `panel_type`→`""`; live FR24 fetch test; headless
  end-to-end emulator render (new `tools/` harness+shim); found+fixed the weather `None`
  crash; validated geometry; verified the prebuilt `demo` binary; wrote the Phase 0 plan.
- Verified: FR24 returns live Cambridge flights; 12 emulator frames render clock/date/flight
  correctly; weather fix → clean exit 0; `demo --help` confirms FM6124 needs no panel-type.
- Changed from brief: discovered FM6124 (not FM6126A) is our chip → `panel_type` emptied;
  found a real upstream weather crash on the no-API-key path and fixed it.
- Next: **supervised Phase 0** once panels arrive — run the demo command above WHILE watching
  the single panel, tune, then port settings into the app and enable the service.

## 2026-06-15 — Design system + faithful simulator + live data clients
Big autonomous build answering the "design it mind-blowingly, simulate it, save the
docs" request. Two display targets: the **64×32** Phase-0 flights-only panel and the
full **1024×32** (16-panel, 201.6") wall as one ultra-wide ribbon.

- Did:
  - **`sim/`** — a zero-dependency browser simulator (`file://`, classic `<script>`,
    no build step) that renders the real HUB75 phosphor optically: linear framebuffer
    → gamma 2.2 LUT → round-dot mask (destination-in) → 2-pass additive bloom →
    scanline/seam/vignette. `led.js` (LEDMatrix + LEDRenderer, two authored bitmap
    fonts), `scenes.js` (split-flap Solari board, radar sweep, flight hero, weather
    **°C + °F**, Bluebikes, shuttle, clock, extras, status endcap), `data.js`
    (synthetic model + live overlay), `app.js` (3 wall modes: dashboard / flight
    takeover / marquee + the single panel). "Departure Board Noir" aesthetic
    (sodium-amber on control-black; Major Mono / Saira / IBM Plex Mono / Silkscreen).
  - **`docs/design/`** — DESIGN.md (full visual system), API_REFERENCE.md (every
    source with verified endpoints/ids/CORS), RESEARCH.md (projects surveyed + 32px
    patterns), README.md index.
  - **`tools/clients/`** — stdlib Python clients shaped to mirror the sim DataModel:
    `weather.py` (Open-Meteo, both units), `bluebikes.py` (GBFS, classic/e-bike
    split), `mit_shuttle.py` (Passio GTFS-rt + static-GTFS route fallback),
    `flights.py` (adsb.lol + hexdb enrichment, haversine, TTL cache), `_http.py`,
    `test_live.py` harness.
- Verified (all live, 2026-06-15):
  - `test_live.py` → **ALL PASS**: weather (22°C/72°F), bikes (18 classic/0 e-bike),
    shuttle (empty — Tech is daytime-only, correct), flights (hero on Logan approach).
  - Browser sim renders all 7 zones, both panel sizes, 3 modes — **no console
    errors**; LIVE toggle pulls real weather + bikes + **airplanes.live** flights
    (hero seen live: TAP216L BOS→LIS, JBU560 KIN→JFK, with hexdb route/city/operator
    enrichment). Synthetic shuttle math validated with an injected protobuf
    (`tech=[3,12]`, `tech_nw=[7]`).
- Changed from brief / corrected earlier research:
  - **Shuttle "Tech NW = 63319" was wrong** — that route doesn't exist. Grad Junction
    West (`180113`, confirmed) is served by `63220` "Tech Shuttle" and
    `56642`/`71674` "Tech Shuttle 2" (the 2nd is what `tech_nw` now carries).
  - **ADS-B CORS split:** adsb.lol/adsb.fi omit CORS → browser blocked; **airplanes.live**
    sends CORS with the identical schema, so the sim reads it while the Pi reads
    adsb.lol. Documented in API_REFERENCE.md.
- Next: wire the Python clients into the real `display/` render path (Phase-1) and
  fold the 384×96 electrical canvas → 1024×32 logical via `pixel_mapper_config`.

## 2026-06-16 — Simulator visual QA pass + label polish
Full "does everything fit and look good" review of the wall, driven by a crisp
debug-readout technique: read `wallM.buf` (linear-light Float32) directly, apply
gamma 2.2 per pixel, and blit each logical LED at integer scale into an injected
overlay canvas — legibility verification decoupled from the optical bloom/dot-mask
layer. Top-level `<script>` consts (`wallM`, `data`, `mode`, `WMO_TEXT`) are
reachable by name from the page eval context, which makes this possible.

- Verified (all fit, no overflow/collision):
  - Dashboard ribbon — all 7 zones: clock (`11:47` + date), weather (icon · °C · °F ·
    H/L · %RH · wind · feels-like), **flight hero** (radar sweep + "N TRK", split-flap
    callsign, type, route, city pair, FL/kt/vspeed, distance), bikes (classic vs
    e-bike split + docks), shuttle (TECH / TECH NW soonest-big + next-ups dim),
    extras (moon phase + %), status endcap (vertical VESTOR, ● LIVE, heartbeat
    sparkline).
  - Flight **takeover** mode — giant Solari callsign + arriving/route across the full
    1024px ribbon, fits.
  - **°C and °F both rendered** in the weather zone (the explicit brief requirement),
    confirmed at scale 8.
- Changed (polish):
  - Weather condition label ladder cleaned: WMO code 1 `MFAIR` → **`FAIR`** (read like
    a render glitch; now CLEAR→FAIR→PARTLY→CLOUDY reads as a clarity gradient).
    `sim/scenes.js` `WMO_TEXT`. (Python `weather.py` keeps the verbose "MOSTLY FAIR" —
    it isn't pixel-constrained.)
  - Wind unit `KH` → **`KPH`** (`sim/scenes.js`); one extra 3×5 glyph, still clears the
    left-column temps in the 128px zone.
  - Added `?v=2` cache-busting to the four local `<script>` tags in `sim/index.html`
    so reloads (dev + Pi kiosk) reliably pick up edited JS instead of heuristically
    caching it (server sends only `Last-Modified`, no `Cache-Control`).
- Next: same Phase-1 wiring as the 06-15 entry (Python clients → real `display/`
  render path; 384×96 electrical → 1024×32 logical via `pixel_mapper_config`).

## 2026-06-16 — Layout-bug fixes: circular radar, takeover hero spacing, bikes overlap
User-reported visual defects, all root-caused with the crisp debug-readout technique
(read `wallM.buf` linear → gamma → blit each LED at integer scale into an overlay
canvas) and fixed by arithmetic, then re-verified at high zoom.

- **Radar was an ellipse, not a circle.** `drawRadar` (`sim/scenes.js`) multiplied every
  vertical coordinate by `0.62` (a zone-fit squash) — on a square-pixel canvas that
  reads as a flattened oval. Fix: equal x/y radius (true circle); instead *shrink* the
  radius and re-center it higher so the full circle fits a 32px-tall zone. Denser
  angular sampling (`step = 0.9 / rr`) so the outer ring reads continuous; outer ring
  brightened. Call sites updated: flight-hero wide (`r=12, cx=x+16, cy=y+14`), takeover
  (`drawRadar(wallM, 24, 14, 12)`); dropped the "RADAR" word and centered "N TRK" under
  the disc so the taller circle doesn't collide with labels.
- **Takeover hero: yellow callsign overlapped/clipped by the lines below it.** Root cause
  = font-baseline metrics: 5×7 glyphs draw downward from `y`, so route at `y+26` spanned
  rows 26–32 and clipped (zone is rows 0–31), and the type/route lines crowded the
  scale-2 callsign. Fix (`sim/app.js drawTakeover`): callsign `y=0` (rows 0–13), type +
  ARRIVING/DEPARTING `y=16`, route `y=23` (rows 23–29). Mid-stats column similarly
  un-clipped: ALT label `y1`/value `y8`, SPD label `y17`/value `y24`; climb & distance
  aligned to those value rows. Verified `AAL519 / B738 DEPARTING / BOS-DCA` and
  `ALT 18,220 FT / SPD 306 KT / +CLIMB / 13.9` all clear with no row-31 clip.
- **Bikes: "10 DOCKS" overlapped "E-BIKE".** A 2-digit dock count widened the bottom-left
  `N DOCKS` label until it ran horizontally and vertically into the e-bike row. Fixed by
  a layout-flow change (`sim/scenes.js BluebikesScene`), not a nudge: the free-dock count
  now shares the station-name row, right-aligned (`textRight(x+w-1, y+7, …)`); classic
  row at `y+14`, e-bike row at `y+23`, occupancy bar on the bottom edge. Stress-tested at
  worst case (classic 18 / e-bike 14 / 12 docks) — every count 2-digit, zero collision.
- Also: corrected a stale source-card doc (`sim/app.js buildSources`) — MIT shuttle
  routes are `56642/71674` (Tech / Tech NW), not the old `63319`. Bumped script
  cache-bust `?v=2` → `?v=3` so reloads pick up the new JS.
- **API liveness (answering the user's question):** all four Python clients live-tested
  PASS. In the browser sim, SIM mode is synthetic; the LIVE toggle pulls real Open-Meteo
  weather + Bluebikes GBFS + airplanes.live flights (CORS-OK). The shuttle stays
  synthetic *in-browser only* (zero-dep JS can't decode GTFS-realtime protobuf); on the
  Pi the Python `mit_shuttle.py` client decodes it for real. **Tech Shuttle confirmed
  live**: route 63220 present, real arrivals `tech=[1,13,15]` min at Grad Junction West
  (180113); the NW line was simply not running that late evening (correctly shows `--`).
- Next: wire the Python clients into the real `display/` render path (Phase-1).

## 2026-06-18 — Multi-agency transit: + MIT SafeRide + BU "Hyatt" shuttle (live tracking)
User asked to add **MIT SafeRide** and the **BU shuttle from the Hyatt to BU**, using the
live-tracking features. Deep-researched both, found they need *two different* integrations,
and built both the Pi (Python) and the in-browser (sim) live paths.

- **Research — SafeRide is the *same* MIT Passio feed, not a new system.** Every MIT shuttle
  (Tech, Tech 2, SafeRide, Boston Daytime, Grocery) shares ONE GTFS-realtime TripUpdates
  feed (`passio3.com/mit/passioTransit/gtfs/realtime/tripUpdates`). Discovered the SafeRide
  trips live on `route_id 56140` "Saferide Campus" serving **`stop_id 3813` = "W98 @ Vassar
  St"** — at **~43 m this is the closest stop of all to the wall**. SafeRide is an
  **evening/overnight service (~6 pm–3 am)**, so by day the feed has no SafeRide trips and
  the field is correctly empty (the inverse of the daytime-only Tech lines).
- **Research — the BU "Hyatt" shuttle runs on TransLoc, not Passio.** Boston University's
  fleet ("the BUS") is on **TransLoc**; the named **"Hyatt"** route (`RouteID 5`) boards at
  **Amesbury St @ Vassar St** (`StopId 21`) — *right by the wall, beside the Hyatt Regency* —
  and crosses the Charles to BU's GSU. The TransLoc3 JSONPRelay backend
  (`bu.transloc.com/Services/JSONPRelay.svc`, public map key `8882812681`) returns plain
  **JSON with `Access-Control-Allow-Origin: *`** → the **simulator can fetch it live in the
  browser** (unlike the protobuf MIT feed). Endpoints: `GetRoutesForMapWithScheduleWithEncodedLine`,
  `GetStopArrivalTimes?routeIDs=5`, `GetMapVehiclePoints?routeIDs=5`. Live ETAs come from
  `Times[].Seconds` where `EstimateTime` is non-null (tracked vehicle vs schedule-only).
- **Did (Pi clients):**
  - `tools/clients/mit_shuttle.py` — extended to classify each trip into `tech`/`tech_nw`/
    `saferide` by **route name** (`route_long_name` starts "Saferide") rather than hard-coded
    ids, pull SafeRide from stop `3813`, and expose `shuttle.saferide[]`. `discover()` now
    reports `saferide_routes_live` + `w98_vassar_present`.
  - `tools/clients/bu_shuttle.py` — **new** TransLoc client: `fetch()` → `BuShuttleArrivals`
    (`hyatt[]` minutes ascending, `live_vehicles`), `.NET /Date()/` parser, `discover()`.
  - `tools/clients/test_live.py` — added `bu_hyatt` to the smoke test + EMPTY checks +
    summary lines for SafeRide and BU.
- **Did (simulator):**
  - `sim/led.js` — added `scarlet`/`scarletDim` to PAL (BU brand colour).
  - `sim/data.js` — `shuttle` now carries `saferide[]`; new `buShuttle{hyatt[],vehicles,…}`;
    synth ticker drives all four lines; **new `_liveBuHyatt()`** does the real CORS fetch to
    bu.transloc.com (same fields as the Python client) and is wired into `fetchLive()`.
  - `sim/scenes.js` — `ShuttleScene` redesigned from a 2-line MIT board into a **4-line
    multi-agency departures board**: header "SHUTTLES" + live dot, then TECH (green) / NW
    (cyan) / SAFE (purple) / BU (scarlet), each lead-bright + next-up-dim, "DUE" flash ≤1 min,
    "—" when idle.
  - `sim/app.js` — zone renamed "SHUTTLES" (src "Passio + TransLoc"); marquee now lists
    SafeRide + BU; added a **BU HYATT SHUTTLE** source card and corrected the MIT card.
  - `sim/index.html` — hero lede now says "MIT & BU shuttles"; cache-bust `?v=3` → `?v=5`.
- **Verified:** `python3 -m tools.clients.test_live` → **5/5 PASS**; BU live path proven on an
  active route (returns real `Seconds`→minutes ETAs; route 5 itself idle on a summer
  afternoon → correctly empty, same pattern as SafeRide-by-day / Tech-overnight). In the sim,
  reloaded at `?v=5` (no console errors), and re-ran the crisp debug-readout on the shuttle
  zone (x=704, w=128, scale 4–5): all four rows render cleanly — `TECH 16·4M / NW 24·9M /
  SAFE DUE / BU 18·3M` — no label↔ETA overlap and no row-31 clip (BU row at y+26 → rows
  26–30). Marquee segment renders "TECH … NW … SAFERIDE … BU HYATT …" with no exception.
- **Changed from brief:** SafeRide turned out to need *no* new integration (same Passio feed)
  — the work was discovery + name-based classification. BU needed a genuinely new vendor
  (TransLoc), but its CORS-open JSON means the *simulator* shows it **live**, while MIT
  shuttles stay synthetic in-browser (protobuf) and live on the Pi.
- **Next:** wire all Python clients (incl. `bu_shuttle.py`) into the real `display/` render
  path for Phase-1; SafeRide will populate the board after dusk on the Pi.

## 2026-06-18 — Carrier-led flight redesign + airline branding (sim)

**Prompt:** referenced `AxisNimble/TheFlightWall_OSS` — *"look how clean their airplane
tracking is… we have so much space to play around with… this also shows airline logos we
should do that too."* Goal: make the flight display dramatically cleaner/more spacious and
add airline branding.

- **Why the reference reads clean (diagnosis):** it identifies a flight by **brand colour +
  emblem + human "From: City"** in a single framed card — one flight, spacious, branded. Ours
  led with a cryptic callsign + cluttered radar/gauges. Fix = lead with the *carrier*, show
  *cities* not just codes, and spend the 1024 px on breathing room.
- **New `sim/airlines.js`:** `AIRLINE_DB` of ~27 carriers keyed by **ICAO operator code**
  (first 3 callsign chars → works for SIM *and* LIVE). LED-boosted brand colour + accent +
  `mark`. **Procedural** marks (shape math, no bitmaps/PNGs/CORS) so one emblem renders crisp
  at h=26 (takeover) and h=7 (panel): swept tail-fin (default, livery-tinted) + bespoke Delta
  widget / United globe / Southwest heart / Lufthansa ring / Air Canada roundel. Generic
  sodium-amber fin fallback for unknown operators. API `airlineFor` / `drawAirlineMark` /
  `markWidth`.
- **`sim/scenes.js` `FlightScene` rebuilt** — both `_drawCompact` (64 px Phase-0) and
  `_drawWide` (320 px dashboard hero) now open with the emblem + brand-coloured wordmark, show
  `ORIG CITY → DEST CITY`, then telemetry; wide adds a carrier-tinted altitude gauge.
- **`sim/app.js` `drawTakeover` rebuilt** as a **3-panel cinematic boarding pass**:
  IDENTITY (big emblem + 2× brand wordmark + callsign·type·reg) · JOURNEY (split-flap IATA
  codes + full city names that clack over on hero rotation, plane crossing the route on a
  `distance`/`_arriving`-derived track with a jet-wash trail) · STATUS (2× `FL###`/`###KT`,
  vertical alt gauge, V/S, "IN RANGE" traffic mini-board, corner radar scope).
- **`sim/led.js`:** added a `·` (middot) glyph to **both** FONT3x5 and FONT5x7 — the takeover
  separator was rendering as `?` (unknown-glyph fallback).
- **Verified (preview emulator, crisp gamma-corrected pixel readout @ scale 3–8):**
  takeover panel-by-panel across **two carriers** — *Southwest* (heart + gold "SOUTHWEST" +
  `SWA2299·B737·N8642E`, BWI/BALTIMORE→BOS/BOSTON, gold plane mid-route) and *United* (globe +
  blue "UNITED", SFO/SAN FRAN→BOS/BOSTON, blue plane, `ARRIVING · 12.0 MI`). Also confirmed
  the 320 px dashboard hero and 64 px Phase-0 panel render carrier-led and clean. No overlap,
  no row-31 clip; fixed one tight spacing on the IN-RANGE rows (`21 + i*6`). Cache-bust
  `?v=5` → `?v=8`.
- **Changed from brief:** chose **procedural pixel marks + brand colours baked into JS** over
  fetching AirHex/airline PNGs — at 7–26 px tall, real logos turn to anti-alias mush and the
  fetches are CORS-blocked; the *brand colour* is the strongest identifier on an LED wall
  anyway. Bespoke geometry only for the few truly iconic marks.
- **Next:** mirror `airlines.py` brand table + the carrier-led layout into the Pi's Python
  `display/` render path for Phase-1; consider per-carrier accent on the dashboard zone seams.

### 2026-06-18 — REAL airline logos (procedural marks rejected, replaced)
- **Why:** owner compared the procedural marks against the actual theflightwall.com product
  (photos: Southwest gradient heart, United globe, Air France wing-stripe — crisp, full-colour,
  full panel height) and called them "nowhere close." Direct instruction: *find where the real
  crisp logos come from and use them; 32 px / full height is fine.* The prior call (procedural
  because "real logos are CORS-blocked mush") was wrong on both counts — corrected here.
- **Source found → `pics.avs.io`** (TravelPayouts/Aviasales CDN): free, **CORS-enabled**,
  transparent-background PNG wordmark logos keyed by **IATA** code, any size. Verified 200s +
  `access-control-allow-origin: *`. (AirHex 403s w/o paid key; TheFlightWall's own CDN serves
  only display *names* — their logos live in proprietary firmware. Both ruled out.)
- **`tools/fetch_logos.py` (new):** ICAO→IATA table → downloads 64 carriers → crops to opaque
  bbox → scales to a 64-px master → `sim/logos/<IATA>.png` + `manifest.json` (~1 MB total).
  5 codes 404 (UPS/Republic/PSA/Piedmont/ABX) → handled by wordmark fallback. Re-runnable;
  wall is then **fully offline** (no per-frame net, no CORS taint, Pi-reusable via Pillow).
- **`sim/airlines.js` rewritten:** dropped all procedural mark geometry. New pipeline loads a
  logo PNG → offscreen-canvas downscale to exact LED height → `getImageData` → alpha-composite
  over black into the framebuffer (`m.set` premultiplies). Read-back **cached per `iata@height`**
  so the 60 fps takeover rasterises each carrier once. Brand accent colour = hand-tuned for ~30
  KBOS majors, else **sampled from the logo's own saturated pixels**. No-logo/unknown →
  brand **wordmark** in brand colour (never a muddy mark). New API: `airlineFor`, `drawLogoH`,
  `fitLogoBox`, `logoReady`, `logoAspect`.
- **Call sites updated:** `app.js drawTakeover` PANEL 1 now fits the real logo big into rows
  3–23 (wordmark fallback) + callsign·type·reg beneath; `scenes.js _drawWide` opens with the
  logo at h=9; `_drawCompact` (64 px) fits the logo across the panel top. Cache-bust `?v=8`→`?v=9`.
- **Verified (preview emulator, gamma-corrected pixel readout):** Southwest takeover (blue
  "Southwest" + gradient heart, crisp, full height) across all 3 panels; United on the 320 px
  dashboard hero **and** the 64 px Phase-0 panel (wordmark + globe + `SFO→BOS` + `FL185`/radar);
  18-carrier sweep rendered 17/18 real logos crisply (1 a load-timing miss, not a missing file);
  wordmark fallback confirmed for Republic (YX, no file) + unknown operators. Buffer-sampled to
  confirm logo + radar pixels lit in every layout.
- **Changed from brief:** reversed the earlier procedural-mark decision entirely. Updated
  `DESIGN.md` §5.1a and `RESEARCH.md` "Airline logos" section to document the real-logo approach
  and retract the "logos turn to mush / CORS-blocked" claim.
- **Next:** port the same logo pipeline to the Pi's Python `display/` path (PIL: load
  `sim/logos/*.png` → resize → blit with gamma) for Phase-1; the manifest + ICAO→IATA map are
  already shared-ready.

### 2026-07-01 — Legendary single-panel flight card (on-Pi, logos + split-flap)
- **Did:** built the airline-branded 64×32 flight scene on the real Pi — the
  hardware sibling of the sim's logo takeover. New/rewritten:
  `scenes/airlinelogo.py` (logo band + livery rule), `scenes/journey.py` (route
  with **split-flap flip-in** + brand-colour chase marker, relocated to rows
  13–25), `scenes/flightdetails.py` (telemetry: warm-white callsign + right
  field **rotating** altitude/type/index, off-blue), `scenes/planedetails.py`
  (now a headless ~7 s dwell/cycle controller). `setup/airlines.py`
  (ICAO→IATA + brand + names + **FR24 altitude ramp**), `setup/logos.py`
  (stdlib pack loader). `utilities/overhead.py` +`aircraft_code`.
  `setup/frames.py` → **20 fps**. `display/__init__.py` wires `AirlineLogoScene`.
- **Logo pipeline (this delivers the last BUILD_LOG "Next"):** reuse the sim's
  64 wordmark PNGs + manifest, but bake them **offline** with
  `tools/bake_logos.py` → `assets/airline_logos.pkl` (12px tall, alpha flattened
  on black, **no gamma** — the driver auto-applies CIE1931; packed 5 bytes/px,
  ~75 KB). On the Pi we render with **`SetPixel` (no runtime Pillow)**, so the
  code rides the existing Port-3 `+64` shim and stays panel-lane-agnostic.
  *(Chose pre-baked pixels over PIL-at-runtime: dependency-free + shim-friendly.)*
- **Verified:** `tools/preview_card.py` — a pixel-accurate offline harness that
  mocks `rgbmatrix` with a real BDF renderer — confirmed the full composition
  (United/jetBlue/British Airways, split-flap settling, FR24 altitude colours,
  climb/descent triangles, BA Speedmarque revealed by the marquee); 0 stray red
  in non-BA route bands. On hardware: `import display` OK in the venv, pack
  loads, **service active, no tracebacks**, 35% CPU (driver baseline, not
  pegged), 52 °C, `throttled=0x0`, pulling live Logan flights at 20 fps. The
  FR24 `Content-Encoding=gzip` log lines are a benign library warning (JSON
  still decodes).
- **Changed from brief:** the Pi path renders logos via pre-baked `SetPixel`
  pixels rather than the sim's live-canvas/PIL blit — same assets + ICAO→IATA
  map, but zero runtime image deps and compatible with the temporary shim.
  Dropped the upstream blue callsign (worst LED text colour per research).
- **Next:** (1) revert the Port-3 shim + `parallel` when the centre-fed wall is
  wired; (2) optional polish — a pulsing brand "LIVE" dot, scene wipe
  transitions; (3) port the same card into the wall's multi-panel layout.
- **Design doc:** [design/FLIGHT_CARD_PI.md](design/FLIGHT_CARD_PI.md)
  (+ `design/flight_card_preview.png`).

### 2026-07-01 — Fix: American logo + switch logos to runtime Pillow
- **Did:** the American logo showed as faint gray "American Airlines" text — its
  livery is a **dark-navy wordmark**, the worst case on a black HUB75 panel
  (blue = dimmest subpixel; the driver's CIE1931 curve dims mids further). Added
  an **LED legibility lift** in `setup/logos.py` (raise HSV *value* `v**0.62`
  floored at 0.50, keep hue) so dark liveries read and their colourful marks pop
  (AA eagle, BA Speedmarque); already-bright logos barely move.
- **Also (owner directive — "install/use whatever packages you need, don't
  reinvent the wheel"):** replaced the offline pre-baked pixel-pack
  (`tools/bake_logos.py` → `assets/airline_logos.pkl`, both removed) with
  **runtime rendering via Pillow** straight from `sim/logos/*.png`, cached per
  carrier. Pillow is now a **declared dep** (`requirements.txt`) and is used on
  the Pi as intended (venv already had 12.2). One code path, no custom byte
  format, `sim/logos/` is the single source of truth. Shipped `sim/logos/` (64
  PNGs, 1 MB) to the Pi.
- **Verified:** offline preview (American now bright + recognisable, United/
  Delta unaffected); on the Pi `get_logo("AA")` → 239-px lifted logo; service
  active, no tracebacks, ~41% CPU (per-carrier render cached), 52 °C.
- **Changed from brief:** dropped the "no runtime Pillow dep" goal entirely — it
  was needless wheel-reinvention. To tune a carrier now: edit `LIFT_*` in
  `setup/logos.py` + restart (no bake step). Updated
  [design/FLIGHT_CARD_PI.md](design/FLIGHT_CARD_PI.md) §2.

### 2026-07-01 — Fix: logos showed as name-text (drop_privileges vs file reads)
- **Symptom:** panel showed airline **names as plain text** (the AirlineLogoScene
  text fallback), not logos — even though the new code was deployed and
  `get_logo("AA")` worked in a manual `ssh root` venv test.
- **Root cause:** `display/__init__.py` sets `options.drop_privileges = True`.
  `RGBMatrix()` maps the PWM hardware as root, then **drops to the `daemon`
  user**. `daemon` cannot read the logo PNGs because **`/home/pi` is 0700**
  (`drwx------ pi`) — so `daemon` can't even traverse into it. Fonts render fine
  because `setup/fonts.py` `LoadFont` runs at **import** (pre-construction, still
  root); my logos loaded **lazily at render time** (post-drop) → `Image.open`
  → PermissionError → `_render` returns None → text fallback. The manual test
  never constructed the matrix, so it never dropped privileges — masking the bug.
- **Fix:** `setup/logos.py preload_all()` renders + caches all 64 logos, called
  from `Display.__init__` **before** `RGBMatrix()` (i.e. while still root).
  Post-drop rendering hits the warm module-level cache and never touches disk.
  Logs `"[logos] preloaded 64/64 airline logos"` at startup for observability.
- **Rule learned (important):** with `drop_privileges=True`, **every file the app
  reads must be read before the matrix is constructed** — load assets at import
  or in `__init__` pre-`RGBMatrix()`, never lazily during rendering. (Backup on
  Pi: `display/__init__.py.prepreload`.)
- **Verified:** restart → `preloaded 64/64`, service active, no errors, still
  drops to `daemon` (cache warm).

### 2026-07-01 — Live data: FR24 → airplanes.live + adsbdb (free, no key, 10s poll)
- **Why:** FR24's unofficial feed throttles/blocks under continuous polling (a
  45-mile Boston box returned 0 flights after our polling tripped it). It's also
  ToS-fragile for a 24/7 wall. Researched the free community ADS-B landscape and
  chose **airplanes.live** (positions + aircraft type, `/v2/point/{lat}/{lon}/
  {radius}`, ~1 req/s, no key) + **adsbdb.com** (callsign→route, cached, no key)
  — the same route enricher upstream its-a-plane uses. (Rejected OpenSky: 4000/
  day cap + OAuth2 + no route; AeroDataBox: ~600 units/mo free ≠ 24/7.)
- **Did:** new `utilities/overhead.py` self-polls on a background daemon thread
  every `POLL_SECONDS` (config, default **10s**) and emits the identical
  per-flight dict, so every scene AND `display/__init__.py` are unchanged (no
  Pi-shim re-patch). Config adds `SEARCH_RADIUS_NM=10`, `POLL_SECONDS=10`,
  `MAX_FLIGHTS=5`. FR24 impl preserved as `utilities/overhead_fr24.py`.
- **CA gotcha (same family as the logo bug):** `requests` verifies with certifi's
  bundle under `/home/pi` (0700) — unreadable by the dropped `daemon` user — so
  point `verify` at the OS trust store `/etc/ssl/certs/ca-certificates.crt`.
  Tested by replicating the service's `import-as-root → setuid(daemon) → HTTPS`
  sequence: airplanes.live + adsbdb both 200 as uid 1.
- **Verified:** real flights over Cambridge with routes (JFK→BOS on approach,
  Republic IND→PHL, a NetJets Citation TVC→BED), types (A21N/E75L/C68A), vspeed;
  service healthy, `preloaded 64/64` logos, no fetch errors across poll cycles,
  `DEMO_MODE=False`.
- **Legit, not evasion:** declined FR24 identity-rotation (ToS-violating, fragile
  on a fixed-IP appliance); switched to a source that's free + unthrottled by
  design. Ultimate path remains a local RTL-SDR + dump1090 receiver.

### 2026-07-01 — Fix: logos invisible (SetPixel can't be monkeypatched) + static logos + box
- **Symptom (from panel photos):** route codes + telemetry rendered, but the
  logo band was empty — no logo AND no fallback text — even for carriers with
  logos (United LAX→JFK, Delta ATL→CDG).
- **Root cause:** the Port-3 shim added its +64 lane offset to `SetPixel` by
  monkeypatching `FrameCanvas.SetPixel` — but that's an **immutable method on the
  compiled C-extension type** (`TypeError: cannot set 'SetPixel' attribute of
  immutable type`), swallowed by the shim's `try/except`. So every SetPixel-drawn
  element (the whole logo, chase marker, vs triangle, loading dot) was written to
  lane 0 (**Port 1 = no panel**) and vanished, while `DrawText`/`DrawLine`
  (module-level functions, genuinely patched) rendered on Port 3. Verified the
  TypeError directly on-Pi.
- **Fix:** stop monkeypatching. Added `Display.set_pixel(x,y,r,g,b)` that adds
  `self._lane_offset_y` (**0** in-repo, **64** on the Pi shim) — mirroring how
  `draw_square` wraps `DrawLine`. All scenes now call `self.set_pixel`, never
  `canvas.SetPixel`. Lesson: **never rely on monkeypatching methods of the
  rgbmatrix C-extension types.**
- **Also (owner requests):** logos now **static** — `setup/logos.py` fits each
  logo WHOLE within 64×12 (no marquee); `airlinelogo.py` centres it H+V.
  `MAX_ALTITUDE` back to **10000** (visible-overhead only). Bounding box: added
  `USE_ZONE_BOX` — `overhead.py` filters airplanes.live results to `ZONE_HOME`
  (the same box FR24 used; point+radius stays the query, radius must cover it).
- **Verified:** offline preview (all logos static + whole), on-Pi import OK,
  service stable (`set_pixel` resolves or the every-frame logo draw would
  AttributeError-loop), `preloaded 64/64`, box+10000ft returned Cape Air
  LEB→BOS at 225 ft with a 24×12 static logo.

### 2026-07-01 — 3-panel departure board (airline | route | telemetry)
- **Did:** owner chained 2 more panels left of the original. **Calibrated** the
  geometry with a labelled test pattern (`scratchpad/calibrate3.py`): canvas col
  0..63 = physical LEFT, 64..127 = middle, 128..191 = right; L/R + v correct →
  **no mirror/flip**, canvas X = physical X. Rebuilt the card as a 192×32
  three-zone board: LEFT = big static airline logo + name + livery rule
  (`airlinelogo.py`); MIDDLE = big stacked ORIGIN/DEST codes, split-flap
  flip-in, plane sprite on a dotted track (`journey.py`); RIGHT = callsign +
  big FR24-coloured altitude + climb/descent marker + type + N/M + vertical
  altitude gauge (`flightdetails.py`). `config CHAIN_LENGTH=3` drives
  `display.chain_length` + `setup/screen` zone offsets (ZONE_AIRLINE/ROUTE/
  TELEM = 0/64/128); `setup/logos` fits to a larger 62×22 box. Scenes draw
  canvas-absolute per zone; the Pi's Port-3 `+64` row shim is unchanged.
- **Verified:** offline preview (`tools/preview_card.py` now 192×32) + live —
  service active, restarts 0, preloaded 64/64, ~54% CPU (3× draw load, fine),
  50 °C, no throttle. JetBlue JFK→BUR and United IAD→BOS rendered with full
  logo+route+telemetry.
- **Connectivity fix (earlier):** a deploy `rsync` hung on a WiFi blip (no
  keepalive) → zombie session saturated the Pi's tailscaled SSH → banner
  timeouts; a power-cycle cleared it. Added a `Host vestor` block to
  `~/.ssh/config` (ConnectTimeout + ServerAliveInterval) so a blip fails fast
  instead of hanging. tailscale ping/TCP were always healthy — it was never WiFi.
- **Next:** 4th panel → extend zones; enhance the idle (no-flight) state to
  span all panels (currently the clock draws only on the left panel).

### 2026-07-01 — Accurate CURRENT routes: FR24-primary + adsbdb fallback
- **Why:** free route DBs (adsbdb/hexdb) key on flight number and return STALE
  scheduled routes — a flight number can fly different routes in one day. Tested
  live: for DAL2816/RPA5679/AAL909 adsbdb was wrong; **FR24 returned the correct
  current route every time** (it reads the filed flight plan). FR24 also gives
  origin/dest on the *basic* get_flights object (no per-flight detail calls).
- **Did:** `overhead.py` route enrichment is now **FR24-first, adsbdb-fallback**.
  When any overhead callsign has no cached route, do ONE FR24 `get_flights` over
  the zone → `{callsign: (origin,dest)}`; routes are cached in-memory with a
  **30-min TTL** (`ROUTE_TTL`, pruned each grab, never persisted) — long enough
  to survive one overhead pass, short enough that a reused callsign (a different
  leg later) re-fetches. Callsigns FR24 doesn't cover fall back to adsbdb + the
  BOS plausibility fix. Positions still come from airplanes.live every 10s.
- **Won't re-throttle:** routes are static, so it's ~0 FR24 calls in steady
  state and one per new arrival; plus a hard **`FR24_MIN_INTERVAL=20s`** rate-cap
  and graceful `{}`-on-error fallback. (The original throttle was polling FR24's
  feed + 5 detail calls every 30s forever.)
- **Verified:** JBU251 now shows **BOS→MCO** (was `BOS → ?`); service active,
  restarts 0, no FR24 errors, ~59% CPU, 53 °C.

### 2026-07-01 — Design tiers 1–4: idle screen, richer cards, polish, prioritization
- **Tier 1 — idle screen** (`scenes/idle.py`, replaces the old single-panel
  clock/date/day/weather): when no aircraft is overhead, all 3 panels show a big
  blinking clock (middle), day/date/year (left), and weather (right), with a
  radar sweep across the board. Weather from **Open-Meteo** (`setup/weather.py`,
  free/no-key, 10-min refresh) in **both °C and °F**. `setup/fonts.py` +`huge`
  (10x20). `display` wires `IdleScene` + `weather.start()`.
- **Tier 2 — richer telemetry** (`scenes/flightdetails.py`): ARR/DEP status tag
  (green down / amber up, from BOS origin/dest + climb/descent), ground speed,
  and an **emergency-squawk alert** (7500/7600/7700 → flashing red HIJACK/NORDO/
  EMERG). `overhead.py` now enriches flights with ground_speed/heading/squawk/
  registration/distance/bearing.
- **Tier 3 — polish**: **dynamic icons** — helicopter rotor + prop SPIN
  (`setup/aircraft.py` marks `*` animated px; `airlinelogo.py` sweeps a bright
  spot); pulsing LIVE dot. (Split-flap already transitions each flight; a
  full-board plane flyover was left out — packed layout, no free strip.)
- **Tier 4 — smart prioritization** (`overhead.py`): sort overhead flights by
  interest (commercial + arriving-low) then nearest, so the board leads with the
  best flight.
- **Verified:** idle + flight previews; live on the Pi (weather 28C/83F, ARR/DEP
  tags, 7700 alert, service healthy, ~64% CPU, 52 °C).

## (template)
### YYYY-MM-DD — <step>
- Did:
- Verified:
- Changed from brief:
- Next:

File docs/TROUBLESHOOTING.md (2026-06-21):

# TROUBLESHOOTING
| Symptom | Cause | Fix |
|---|---|---|
| No output (black) | Panel needs init (rare for FM6124) | Try `--led-panel-type=FM6126A`, then `=FM6127`; remove again if no help |
| Dim/reddish | Power sag / voltage drop | Confirm 5V/60A PSU on + wired (Pi can't power panels). Far panels redshift if the 5V trunk is thin/CCA — inject at ≥2 points/half, use copper (INVENTORY §7.1). It's a power fault, NOT an rgb-sequence bug. |
| Panels different shades | Per-panel LED variance | hzeller is GLOBAL-only — can't per-panel calibrate. Mitigate: same batch, low brightness, dark content (INVENTORY §7.2). Last resort: `MapColors()` C++ fork. |
| Dead 16-px column / horizontal line | Dead FM6124 IC / dead row | Hardware defect — RMA the panel, swap a spare. Found via incoming-QC `demo -D5` (INVENTORY §7.3). |
| Garbage pixels | Pi 4 too fast | `--led-slowdown-gpio` 4→5 |
| Colors swapped | RGB order | `--led-rgb-sequence` RBG/BGR/GRB |
| Rows scrambled | Addressing | `--led-row-addr-type` 0→3→5 |
| Flicker | Sound on / HW pulse off | blacklist snd_bcm2835 + audio=off + disable_hardware_pulsing=False |
| Won't boot after cmdline edit | Malformed cmdline.txt | Restore cmdline.txt.bak on Mac |
| No flights | FlightRadarAPI change | `pip install FlightRadarAPI -U` or merge upstream |
| Service dead | Path/env/caps | Check EnvironmentFile, venv path, setcap, journalctl |
| No SSH | WiFi/SSH not baked | Re-flash custom.toml; SSID + country=US |

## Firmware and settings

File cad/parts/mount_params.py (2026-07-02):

#!/usr/bin/env python3
"""
mount_params.py — the SINGLE source of truth for every mount part.

All parts (top_cleat, anti_swing_foot, seam_key, bars, corner_enclosure, …)
import these. Change a number here and every part + the assembly move together,
so the pieces cannot drift out of alignment. Dimensions in mm.

Coordinate frame (identical to cad/model.py):
    X = along the wall   (0 = far end .. 5118 = inside corner)
    Y = depth into room  (0 = main wall surface, +Y toward the viewer)
    Z = vertical         (0 = TOP of the wooden piece, −down)

Side view of the wall interface (what the parts clip into):

    Y=0        14   34        <- wall / groove / piece / room
    │  TOPgrv  │piece│
  Z=0 ┌────────┼─────┐ ── piece top ────────────────────────────
      │  (14)  │ 20  │   TOP groove: Y 0..14, Z 0..-50  OPEN TOP
  -50 ├────────┤     │   groove floor
      │ attach │     │   MIDDLE band solid Y 0..34, Z -50..-83
  -83 ├────────┤     │
      │ BOTgrv │     │   BOTTOM groove: Y -4..14, Z -83..-140 OPEN BOTTOM
 -140 └────────┴─────┘ ── piece bottom ─────────────────────────
"""

# ── wall interface (Y, depth) ───────────────────────────────────────────────
WALL_Y        = 0.0     # main wall surface
TOP_GRV_GAP   = 14.0    # top groove width (wall→piece back)
PIECE_BACK_Y  = 14.0    # piece back face
PIECE_FRONT_Y = 34.0    # piece front face (3.4 cm proud)
PIECE_THICK   = 20.0
WALL_STEP     = 4.0     # wall cut 4 mm deeper below the attach band
BOT_GRV_BACK_Y = -WALL_STEP   # -4  (bottom-groove back wall)
BOT_GRV_GAP    = PIECE_BACK_Y - BOT_GRV_BACK_Y   # 18 wide

# ── wall interface (Z, vertical; 0 = piece top) ─────────────────────────────
PIECE_TOP_Z   = 0.0
TOP_GRV_FLOOR = -50.0   # top groove is 50 mm deep, open at the top
ATTACH_TOP_Z  = -50.0
ATTACH_BOT_Z  = -83.0   # solid attach band -50..-83  (nothing may pass here)
BOT_GRV_TOP_Z = -83.0   # bottom groove closed top
PIECE_BOT_Z   = -140.0  # piece bottom == bottom groove open mouth

# ── the mount stackup (Y): cleat face → STEEL rail → magnet → panel ──────────
# CHANGED after the manufacturing-strategy research (docs/design/MANUFACTURING_PLAN.md):
# the rails are now STEEL, not aluminium + a glued steel strip. Steel IS the magnet
# target (bare low-carbon steel is what neodymium actually grips — a thin/coated/
# alloy strip silently loses 40-60% of hold), it is 3× stiffer than aluminium (holds
# the flat datum plane), and it expands half as much — so there is no separate strip
# to shear-peel. The rail front face IS the magnet contact plane.
FACE_Y      = 40.0      # front face of every wall bracket (6 mm proud of the piece)
RAIL_THK    = 5.0       # steel rail depth (Y) — bare low-carbon steel, the magnet target
RAIL_FRONT_Y = FACE_Y + RAIL_THK       # 45  (magnet contact plane)
STEEL_Y     = RAIL_FRONT_Y             # alias: the magnet contacts the rail front directly
MAGNET_STAND = 11.0     # magnet-screw protrusion off the panel back
PANEL_BACK_Y = RAIL_FRONT_Y + MAGNET_STAND  # 56
PANEL_D      = 15.0
PANEL_FACE_Y = PANEL_BACK_Y + PANEL_D  # 71 (~37 mm proud of the piece)
# back-compat alias (older parts referenced BAR_FRONT_Y / BAR_THK)
BAR_THK, BAR_FRONT_Y = RAIL_THK, RAIL_FRONT_Y

# ── panels / rows ───────────────────────────────────────────────────────────
PANEL_W, PANEL_H = 320.0, 160.0
N_PANELS = 16
ROW_W    = PANEL_W * N_PANELS          # 5120
WALL_USABLE = 5118.0
PANEL_TOP_Z, PANEL_BOT_Z = 0.0, -PANEL_H            # 0 .. -160
M3_TOP_Z, M3_BOT_Z = -8.0, -152.0      # the two M3 hole rows (144 mm pitch)
M3_V_PITCH = 144.0

# ── the two STEEL rails (run along X) ───────────────────────────────────────
# TOP rail = steel flat bar (magnet target only). BOTTOM rail = steel ANGLE: its
# vertical leg is the magnet target, its horizontal leg is a CONTINUOUS ledge every
# panel bottom RESTS on — so the magnets never carry the panel weight in shear (the
# validated fix), and it deletes the 16 separate printed rest-shoes.
BAR_H       = 26.0      # rail face height (Z) — tall enough for magnet-screw wiggle room
TOP_BAR_CZ  = M3_TOP_Z  # -8   (centred on the top M3 row)
BOT_BAR_CZ  = M3_BOT_Z  # -152 (centred on the bottom M3 row)
def bar_z(cz):          # (z0, z1) of a rail face centred at cz
    return (cz - BAR_H / 2, cz + BAR_H / 2)
LEDGE_Z     = PANEL_BOT_Z          # -160  bottom-angle ledge top (panel rests here)
LEDGE_THK   = 4.0                  # steel angle leg thickness
LEDGE_FRONT_Y = PANEL_BACK_Y + 8   # 64    ledge reaches under the panel back edge

# THERMAL: a 5 m steel rail grows ~1.2 mm per 20 °C. Anchor each rail to ONE central
# cleat only; every other cleat's rail-bolt hole is SLOTTED in X so the rail breathes.
# Leave a sub-mm gap at the row ends (hidden at the corner).

# ── stations (vertical lines of hardware) ───────────────────────────────────
N_STATIONS   = 13
STATION_PITCH = ROW_W / (N_STATIONS - 1)   # ≈ 427 mm (≤450 keeps rail sag invisible)
def station_x(i):
    return i * STATION_PITCH
ANCHOR_STATION = N_STATIONS // 2   # the one cleat that rigidly anchors the rails (rest slot)
FOOT_EVERY = 2          # an anti-swing tab at every 2nd station (~854 mm)

# ── ceiling gap (electronics plenum above the panels) ──────────────────────
# Behind the panels is only ~1 cm; all electronics live in the ~22.5 cm gap between
# the piece top (Z=0) and the ceiling, on a backer strip hung from the SAME top groove.
CEIL_Z          = 225.0   # ceiling, above the piece top (22.5 cm)
STRIP_FRONT_Y   = 30.0    # backer-strip front face — electronics hang forward of this
STRIP_BACK_Y    = 18.0
VALANCE_BACK_Y  = 61.0    # valance board back
VALANCE_FRONT_Y = PANEL_FACE_Y   # 71 — valance flush with the panel face (one clean plane)
VALANCE_TOP_Z   = 208.0   # stop below the ceiling → a continuous vent reveal for the PSUs
HANGER_TOP_Z    = 200.0   # top of the gap-hanger bracket

# ── fasteners ───────────────────────────────────────────────────────────────
M4_CLR = 4.5            # M4 clearance hole
M3_CLR = 3.4
BOLT_DX = 15.0          # bar-to-bracket bolt pair, ±X from station centre

# ── print material note ─────────────────────────────────────────────────────
# PLA now (over-built; every part is in compression or light shear). Reprint the
# load path (top_cleat) in PETG/ASA later — PLA creeps under sustained load.

if __name__ == "__main__":
    print(f"stackup Y: face {FACE_Y} → bar {BAR_FRONT_Y} → steel {STEEL_Y} → "
          f"panel back {PANEL_BACK_Y} → face {PANEL_FACE_Y}")
    print(f"bars: top z{bar_z(TOP_BAR_CZ)}  bottom z{bar_z(BOT_BAR_CZ)}")
    print(f"{N_STATIONS} stations @ {STATION_PITCH:.0f} mm; foot every {FOOT_EVERY}")

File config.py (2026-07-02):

"""Vestor configuration (committed — NO secrets).

Location: 540 Memorial Drive, Cambridge MA (~42.354 N, -71.107 W), facing
south/southeast toward Logan/BOS traffic over Dorchester and the harbor.

Secrets (API keys) are NOT stored here. They are read from the environment,
populated by the gitignored `.env` (loaded via the systemd EnvironmentFile, or
`source .env` for manual runs). See `.env.example` / `config_secrets.example.py`.
"""

import os

# ---- Flight tracking zone (bounding box: top-left + bottom-right lat/lon) ----
ZONE_HOME = {
    "tl_y": 42.400,   # north edge (past Logan)
    "tl_x": -71.120,  # west edge (near home)
    "br_y": 42.280,   # south edge (Dorchester/Quincy)
    "br_x": -70.980,  # east edge (over the harbor)
}

# ---- Home location [lat, lon, altitude_km] — used to sort flights by distance ----
LOCATION_HOME = [42.354, -71.107, 0.005]

# ---- Weather ----
WEATHER_LOCATION = "Cambridge,MA,US"
TEMPERATURE_UNITS = "imperial"

# ---- Flight filtering / display ----
MIN_ALTITUDE = 100              # feet — filters out planes on the tarmac
MAX_ALTITUDE = 10000            # feet — only low "visible overhead" traffic (planes
                                # you can actually see from the window). Raise toward
                                # 40000 to also catch cruise overflights.

# ---- Panel geometry ----
# Number of 64x32 panels chained on the data line (left->right, calibrated
# 2026-07-01: canvas col 0..63 = physical LEFT panel, 64..127 = middle, 128..191
# = right; no mirror/flip). Drives the multi-panel departure-board layout.
CHAIN_LENGTH = 3

# ---- Live data source: airplanes.live (positions+type) + adsbdb.com (routes) ----
# Free, no-key community ADS-B (replaces the throttled FR24 unofficial feed).
# We query airplanes.live by point+radius, then (if USE_ZONE_BOX) keep only the
# aircraft inside the ZONE_HOME bounding box above — the same area FR24 used.
SEARCH_RADIUS_NM = 10           # nm around LOCATION_HOME to query (must cover ZONE_HOME)
POLL_SECONDS = 10               # how often to poll airplanes.live for what's overhead
MAX_FLIGHTS = 5                 # show the nearest N aircraft (cycled on the board)
USE_ZONE_BOX = True             # True = filter to ZONE_HOME box; False = full radius circle
JOURNEY_CODE_SELECTED = "BOS"   # bolds Logan as the local airport
JOURNEY_BLANK_FILLER = " ? "

# Demo mode: skip FlightRadar24 and cycle a fixed set of sample flights. Useful
# when the (free, rate-limited) FR24 feed is throttled or during a real lull, so
# the board still shows the flight card. Set False for live data.
DEMO_MODE = False

# Scene transitions: a big jet swoops across (new screen left of it, old to the
# right) on every flight<->flight / flight<->clock change. Set False for hard cuts.
TRANSITIONS_ENABLED = True

# ---- Display / hardware (Triple Bonnet, Pi 4) ----
BRIGHTNESS = 50                 # 0-100
GPIO_SLOWDOWN = 4               # Pi 4 starting value (try 5 on hardware if garbage)
HAT_PWM_ENABLED = False         # ignored now that hardware_mapping is hardcoded "regular"

# ---- Secrets from environment (never hardcode keys in this committed file) ----
OPENWEATHER_API_KEY = os.environ.get("OPENWEATHER_API_KEY", "")
MBTA_API_KEY = os.environ.get("MBTA_API_KEY", "")

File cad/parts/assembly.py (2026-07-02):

#!/usr/bin/env python3
"""
assembly.py — put every mount part together in ONE wall-coordinate frame and prove
they fit. Because all parts import mount_params, unioning them here cannot drift.

Outputs:
  • assembly_section.png — the full vertical cross-section (top cleat → top bar →
    panel → bottom bar → anti-swing foot → rest shoe): the money shot.
  • assembly_3d.png      — a shaded 3D of a ~2-panel section with all hardware.
Run the individual parts first (they write the per-part STLs); this writes the
section STLs into out/asm/ and renders them.
"""
import os, sys, glob
sys.path.insert(0, os.path.dirname(os.path.abspath(__file__)))
import cadquery as cq
import mount_params as P
from util import box, OUT, IMG
import top_cleat, anti_swing_foot, bars

ASM = os.path.join(OUT, "asm"); os.makedirs(ASM, exist_ok=True)
SECT_X = 700.0     # render a 700 mm slice (~2 panels)

PALETTE = {
    "wall": (0.66, 0.52, 0.35), "piece": (0.55, 0.41, 0.26), "bridge": (0.55, 0.41, 0.26),
    "panel": (0.11, 0.11, 0.14), "screen": (0.10, 0.55, 0.85),
    "cleat": (0.93, 0.80, 0.52), "foot": (0.93, 0.80, 0.52), "tab": (0.96, 0.66, 0.30),
    "rest": (0.85, 0.72, 0.45), "bar": (0.78, 0.80, 0.84), "steel": (0.62, 0.64, 0.68),
}
def color_for(name):
    for k, c in PALETTE.items():
        if name.startswith(k):
            return c
    return (0.7, 0.7, 0.7)


def section_solids():
    """[(name, solid)] for a SECT_X slice with all hardware + context."""
    S = []
    # ---- wall context ----
    S.append(("wall",   box(-40, SECT_X + 40, -25, 0, -320, 40)))
    S.append(("piece",  box(-40, SECT_X + 40, P.PIECE_BACK_Y, P.PIECE_FRONT_Y, P.PIECE_BOT_Z, 0)))
    S.append(("bridge", box(-40, SECT_X + 40, 0, P.PIECE_BACK_Y, P.ATTACH_BOT_Z, P.ATTACH_TOP_Z)))
    # ---- the two STEEL rails over the slice (bottom rail = angle w/ rest ledge) ----
    S.append(("bar_top", bars.build_top_rail(SECT_X)))
    S.append(("bar_bot", bars.build_bottom_rail(SECT_X)))
    # ---- tall station cleats (each carries BOTH rails) ----
    for i, x0 in enumerate((40.0, 440.0)):
        S.append((f"cleat_{i}", top_cleat.build(x0)))
    # ---- one anti-swing tab foot (pure anti-swing; sits BETWEEN cleat stations so
    #      its base clears the tall spine; bolts to the continuous bottom rail) ----
    S.append(("foot_0", anti_swing_foot.build_base(240.0)))
    S.append(("tab_0",  anti_swing_foot.build_tab(240.0)))
    # ---- two panels (front) ----
    for i, a in enumerate((0.0, 320.0)):
        S.append((f"panel_{i}", box(a + 1, a + P.PANEL_W - 1, P.PANEL_BACK_Y, P.PANEL_FACE_Y - 1.5, P.PANEL_BOT_Z, 0)))
        S.append((f"screen_{i}", box(a + 4, a + P.PANEL_W - 4, P.PANEL_FACE_Y - 1.5, P.PANEL_FACE_Y, P.PANEL_BOT_Z + 4, -4)))
    return S


def collide_check(S):
    """Real boolean test: no hardware may share solid volume with (a) the panels'
    active volume or (b) the wooden piece. Uses actual intersections, so L-shaped
    parts that merely tuck a ledge under the panel bottom edge pass."""
    panel_vol = box(-40, SECT_X + 40, P.PANEL_BACK_Y, P.PANEL_FACE_Y, P.PANEL_BOT_Z, 0)
    piece_vol = box(-40, SECT_X + 40, P.PIECE_BACK_Y, P.PIECE_FRONT_Y, P.PIECE_BOT_Z, 0)
    def vol(s):
        try:
            r = s.val().Volume()
            return r if r else 0.0
        except Exception:
            return 0.0
    issues = []
    hardware = [(n, s) for n, s in S if n.startswith(("cleat", "foot", "tab", "rest"))]
    for n, s in hardware:
        for label, ref in (("panel", panel_vol), ("piece", piece_vol)):
            if vol(s.intersect(ref)) > 1.0:   # > 1 mm³ of shared solid = a real clash
                issues.append(f"{n} clashes with {label}")
    # hardware-vs-hardware: a foot/tab must not collide with a cleat spine (offset check)
    cleats = [(n, s) for n, s in hardware if n.startswith("cleat")]
    feet   = [(n, s) for n, s in hardware if n.startswith(("foot", "tab"))]
    for fn, fs in feet:
        for cn, cs in cleats:
            if vol(fs.intersect(cs)) > 1.0:
                issues.append(f"{fn} clashes with {cn}")
    return issues


def write_stls(S):
    for f in glob.glob(os.path.join(ASM, "*.stl")):
        os.remove(f)
    for n, s in S:
        cq.exporters.export(s, os.path.join(ASM, f"{n}.stl"))


OPACITY = {"wall": 0.06, "piece": 0.5, "bridge": 0.5, "panel": 0.22, "screen": 0.32}

def render_3d():
    import pyvista as pv
    pv.OFF_SCREEN = True
    p = pv.Plotter(off_screen=True, window_size=(1900, 1250))
    p.set_background("white")
    for stl in sorted(glob.glob(os.path.join(ASM, "*.stl"))):
        name = os.path.splitext(os.path.basename(stl))[0]
        m = pv.read(stl)
        op = next((v for k, v in OPACITY.items() if name.startswith(k)), 1.0)
        p.add_mesh(m, color=color_for(name), opacity=op, show_edges=(op == 1.0),
                   edge_color=(.25, .2, .12), line_width=1, ambient=0.4, diffuse=0.7, specular=0.1)
    # front-left, slightly above, looking back at the wall down the row
    p.camera_position = [(-520, 1000, 430), (360, 55, -95), (0, 0, 1)]
    p.camera.zoom(1.45)
    p.screenshot(os.path.join(IMG, "assembly_3d.png"))
    print("  wrote assembly_3d.png")
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

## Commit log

2026-06-14 feat(display): Triple Bonnet active3 options (regular/parallel/FM6126A)
    Upstream hardcoded single-bonnet defaults (adafruit-hat, parallel=1,
    disable_hardware_pulsing=True) which are wrong for the Adafruit Triple RGB
    Matrix Bonnet 6358. Set hardware_mapping="regular", add panel_type="FM6126A"
    for the FM6124-family init, enable native hardware PWM, and keep
    drop_privileges=True. Configured for the Phase 0 single-panel test
    (chain_length=1, parallel=1) with full-wall values (6/3) commented inline.
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2026-06-14 Rebrand project to "vestor" (owner code name)
    Rename entry point flight-tracker.py -> vestor-tracker.py and the systemd
    unit flightwall.service -> vestor.service. Standardize hostname (vestor.local),
    on-Pi path (/home/pi/vestor), repo refs (g-vansh/vestor), and the FlightWall
    brand across README, NOTICE, config, scripts, and docs. Fix stale main.py
    entry-point references to vestor-tracker.py.
    [config.py]
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2026-06-15 fix(build): adapt Pi provisioning to upstream scikit-build-core matrix layout
    Modern hzeller upstream builds the rgbmatrix Python binding from the repo
    root via scikit-build-core/CMake (no bindings/python/setup.py), needs
    cmake+ninja, and its unconditional pillow.c shim needs Pillow's libImaging
    headers (fetched onto CPATH at build time only; no runtime Pillow dep).
    - setup_pi.sh: drop interactive Adafruit installer -> apt cmake/ninja +
    clone upstream; newline-safe single-line cmdline.txt edit
    - install_app.sh: build from matrix repo root + CPATH Pillow headers,
    filter rgbmatrix out of requirements, correct ordering, setcap
    - install_service.sh: install unit only (no enable --now); Phas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
2026-06-15 test(phase0): pre-hardware validation + FM6124D config fix + weather crash fix
    While the 16 P5 panels ship (~2 weeks out), confirm the full hardware chain and
    exercise every panel-free software path to de-risk the Phase 0 single-panel test.
    - Research (primary sources): Triple Bonnet 6358 = hardware_mapping="regular" +
    parallel=3 (confirms committed config); 2x LRS-350-5 (120A) is comfortable for
    real content but ~107% at all-white, so BRIGHTNESS=50 caps worst case; injection
    + geometry math (6+5+5 -> 384x96 canvas, 2 dark tail slots) documented in BUILD_LOG.
    - FM6124D is a STANDARD driver (no init), NOT the FM6126A family: set panel_type=""
    with FM6126A/FM6127 demoted to fallback-i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
2026-06-18 feat(sim): carrier-led flight redesign + procedural airline branding
    Lead the flight display with the airline (brand colour + emblem + city
    journey), the way a real gate board identifies a flight before you read
    any text — inspired by TheFlightWall's clean single-flight card.
    - airlines.js: ~27 carriers keyed by ICAO operator code (works SIM+LIVE),
    LED-boosted brand colours, procedural marks (tail-fin + bespoke Delta
    widget / United globe / Southwest heart / Lufthansa ring / AC roundel)
    that render crisp at any size with no bitmaps/PNGs/CORS.
    - scenes.js FlightScene: compact (64px) + wide (320px) now open with the
    emblem + brand wordmark, show ORIG CITY -> DEST CITY, carrier-tinte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
2026-06-21 docs: verify panel-spec compatibility + lock single-row data routing (2x8 center-feed)
    Owner shared the real MUEN P5 specs/photos (FM6124(Z)D, HUB75-D) and locked the
    layout to one long 16-wide row. Verified every spec is end-to-end compatible
    (64x32, 1/16 scan, A-D address, standard HUB75 pinout, FM6124 = no init).
    Key decision: a 5m single row + co-located bonnet ports makes the old 6+5+5
    plan need 1.9-3.5m HUB75 jump cables (>50cm limit -> corruption). Switch to
    Pi+bonnet center-mounted, 2 chains of 8 daisy-chaining outward (parallel=2,
    chain=8): every ribbon stays short, 16=2x8 (no wasted slots), refresh fine on
    Pi 4. Trade-off: left 8 panels mount 180deg + software-flipped (snake).
    Up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
2026-06-21 docs: add review/QC hardening (CCA wire, shade uniformity, incoming-QC) — §7
    AliExpress reviews are sourcing/QC issues, not spec mismatches: panel
    compatibility (§6) and the 2x8 center-feed topology (§5) are unchanged.
    Add INVENTORY §7 (CCA voltage-drop fix, hzeller global-only color limits,
    per-panel demo-mode test protocol), align §2 harness wire/fuse rows to
    pure-copper AWG6 + ~40A, and log the 3-agent research pass.
2026-06-21 fix(display): replace stale 6+5+5 wall comments with locked 2x8 center-feed plan
    The live display/__init__.py still instructed a future hardware session to
    configure parallel=3/chain=6 and build a pixel_mapper for "uneven 6+5+5
    chains" — the topology we rejected (needs >50cm jump cables). Rewrote the
    comments to the locked 2x8 center-feed plan (parallel=2, chain=8; 1024x32 ->
    512x64 canvas with the left half rotated 180deg in our code, not a mapper).
    Also lower the config-fallback BRIGHTNESS 100->50 so a missing config can't
    over-draw the 120A PSU budget. Add ROADMAP wall-composition build note +
    TROUBLESHOOTING rows (voltage-drop redshift, shade variation, dead IC/row).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
2026-06-21 docs: add §8 mounting & frame — won't free-stand, build a ~$200 wall-mount
    Answer the owner's frame questions (3 research agents). Trace the
    "magnets/screws" claim to the MUEN listing's Free Parts image (not a
    datasheet) and flag confirm-on-unboxing. Document why a 16.8ft x 6.3in
    strip can't free-stand, why no off-the-shelf frame fits, and give a
    buildout: 80/20 1530 stud-mount (~$210) or French-cleat + toggle-bolt
    renter variant (~$190). Key gotchas: magnets need a ferrous surface
    (or screw the M3 corners), support every ~3-4ft, ~30-35mm depth.
2026-06-21 docs: add MIT_RESOURCES — build the frame on campus free/cheap
    Owner is an MIT grad student. Add a campus-resources guide: where to
    fabricate (Hobby Shop, MITERS, Project Manus — free for grads), free/cheap
    materials (reuse@mit.edu, Swapfest, Edgerton Project Lab), funding (Project
    Manus $500 Design-to-Making grant + MakerBucks), and a print-vs-buy split
    with specific 3D-printable parts (corner brackets, cable raceways, PSU/Pi
    trays) in ABS/PETG. Cross-link from INVENTORY §8.
2026-06-21 docs: vet + recommend Hanson hanpaneldistro fused power board (§7.1)
    The Hanson "Panel Power Distribution" board is a passive 5V-in -> 4x fused
    (7A) 5V-out PCB that bolts to a panel back — i.e. bus-bar + fuses + mount in
    one part, fully controller-agnostic (power only, no HUB75). It's the
    recommended way to build the §7.1 injection points, with per-panel fusing
    that beats one 40A PSU fuse. P5 derate: 1 panel/7A fuse = 4 panels/board =
    buy 4 (2 per PSU). Bench-verify 144mm M3 hole fit + all-white amps + bracket
    hole contention first. US-stocked. Doesn't replace PSUs/trunk/ground bond.
2026-06-21 docs: add GEAR.md — 5-domain ecosystem scout for build-easier tech
    Ranked findings (power, HUB75 cabling, mounting, front-face/diffusion,
    reliability) with honest SKIP flags. Top wins: ferrule crimper (the CCA fix),
    DC clamp meter, Smoke-Gray #2064 contrast tint front face (not a white
    diffuser — it smears 5mm text), smart plug + free systemd watchdog/overlayfs
    hardening. Refines the plan: Hanson PDist1 at the PSU, trim PSU output to
    ~5.1-5.2V (no remote-sense). Logs the hard constraint that the Triple Bonnet
    blocks all GPIO HATs. Cross-linked into INVENTORY §7.1 and ROADMAP.
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2026-06-29 docs: resolve mounting + cabling from real panel/cable photos
    Confirmed from photos: 16 individual CnGear-framed panels, 320x158x~15mm,
    non-interlocking. Mounting interface = 6 brass M3 holes in the frame (4
    corners + 2 mid-edge, ~144mm vertical pitch) — the magnet-mount points, but
    zero magnets shipped, so holes take screws/brackets. Recommend 80/20 +
    3D-printed brackets (free at MIT) locating panels coplanar. Cabling fully
    included: 16 short 16-pin IDC data ribbons + 16 fork-terminated power
    pigtails — buy neither; distro mounts on the backbone (144mm-on-panel fit
    now moot). Updated INVENTORY §6/§7.1/§7.3/§8.0 + BUILD_LOG.
2026-06-29 docs: 3-agent optimization → §9 final no-solder build (~$100, half the parts)
    Optimization pass (power/mounting/prebuilt+control research across web +
    Reddit + xLights/Falcon forums) against owner priorities: fewest parts,
    cheap, no soldering, buy-don't-build. Outcome:
    - Control $0: keep Pi 4 + Triple Bonnet (no prebuilt 1024x32 worth buying;
    NovaStar/ESP32 are downgrades). Keep 2x8 center-feed; reject the 3-lane
    idea (>50cm jump in a 1-D row).
    - Power ~$52 no-solder: one 8-way ATC fuse block per PSU, panel forks land
    directly. Drops Hanson distros/bus bars/crimping. Fix: PSU->block trunk
    carries full 32A -> 10 AWG not 14 AWG.
    - Mounting ~$48 + free MIT parts: 2020 extrusion + 3D-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
2026-06-29 docs: log PSU/magnet order; revise mounting to magnetic; flag AC-cord gap
    Wired Watts #225740: 2x LRS-350-5 (power blocker resolved), Double Stack
    Mount Kit, 100 panel magnets. Gap: no AC cords ordered (LRS has bare
    terminals) -> still need 2. With magnets in hand, revise mounting to
    MAGNETIC: screw a magnet into each panel's 6 holes, snap onto 2 ferrous
    rails (Unistrut/steel bar) -- tool-free, no bracket printing (the earlier
    "reject magnets" was about a full steel sheet, not narrow rails). Add §9.5:
    measure panel pigtail length to finalize the power-distribution layout.
2026-06-29 docs: lock physical layout from 55cm pigtail → 4 fuse blocks, center brain box
    Owner measured power pigtail = 55cm. At 320mm panel pitch that reaches ~±1.7
    panels, so one fuse block serves ~4 panels → 4x 6-way blocks (not 2x 12-way),
    one per 4-panel group, fed by 10 AWG trunk from center-stacked PSUs. Center
    "brain box" (Pi+bonnet+2 PSUs via the stack kit + AC entry); data 2x8
    center-feed and magnetic mount unchanged. No redesign — only fuse-block
    count/spacing changed (2->4, +~$18). Update INVENTORY §9.2/§9.5 + BUILD_LOG.
    Background agent validating injection spacing/voltage-drop/grounding.
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2026-06-29 docs: confirm PSU sizing — keep 2x LRS-350-5 (don't downsize/cancel)
    Worked the draw math: ~4A/panel full-white max (2.4A measured), 16 panels =
    64A max but only ~5-16A in real capped/dark use. One 60A unit is too tight
    (64A max) and worsens distribution, so keep two. 2x LRS-350-5 = 53% at peak,
    ~10-20% typical (overspecced = cooler/longer life; thermostatic fan won't run
    at this load). 2x fanless LRS-200-5 (40A) would also suffice (80% peak) but
    that's a fanless preference, not a fix. Decision: keep the order as-is.
2026-06-29 docs: lock specific fuse block (tatida 6-way B096Z1WNLW) into BOM
    Vetted the tatida 6-way ATC fuse block: works at 5V (passive, rated to 32V
    despite "12V" label), 100A/30A vs our 16A/4A, M4 output studs fit the panel
    fork terminals, negative bus, $9.99. Buy 4. Buy separate 7.5A fuses (included
    20/15/10/5A are wrong sizes for ~4A panels). Fix wire note: split PSUs mean
    each PSU->block trunk carries ~16A (not 32A). Remove duplicate fuse row.
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2026-06-29 docs: cable ties ordered; add §9.7 hybrid mounting technique
    Mark cable ties + tie mounts ordered. Add §9.7: mounting = two problems
    (HOLD via magnets, LOCATE via 3D prints) → light hybrid = magnetic hold on
    2 steel rails + a few 3D-printed end-stops/registration combs. Keeps
    tool-free panel swaps (key for QC/dead-panel replacement), uses the magnets
    + free MIT printing, no bolting 16 panels; printed end-stops fix magnetic
    mounting's lateral-drift weakness. Down to ~$20 essential left to buy.
2026-06-29 docs: ring-terminal qty (~8) + bare-hook alternative
    Only the 10 AWG trunk ends at the fuse-block studs need ring terminals: ~8
    (4 blocks x +input & V- return). Crimper is free at MIT, so spend is just
    ~$6 of ring terminals. Document the bare-wire J-hook alternative ($0, no
    tool) and its drawback (stranded wire loosens over thermal cycling ->
    resistance/heat at 16A 24-7). PSU-end is screw-clamp so bare wire is fine
    there. Note in §9.2 + §9.4.
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2026-07-01 docs: log Pi-online milestone + WiFi root cause (cmdline instance-id lock)
    Bring-up resolved. Root cause of the WiFi saga: cmdline.txt hardcoded the
    cloud-init instance-id (ds=nocloud;i=...), overriding meta-data, so the added
    Vestor network never applied and only MIT was ever configured. Fixed by
    changing i= in cmdline.txt. Confirmed via root Tailscale SSH: online on MIT
    5GHz (bonnet does NOT degrade WiFi: -52->-48 dBm), clean power with the riser,
    hzeller demo present. Operational wall should use MIT 5GHz/wired, not the
    2.4GHz hotspot. First light pending panel power.
2026-07-01 docs: FIRST LIGHT — Phase 0 complete
    One panel fully lit and animating over Tailscale SSH. Confirmed working
    config matches the locked plan: standard driver (no FM6126A init), regular
    mapping, slowdown-gpio=4, default RGB (colors correct). The only gotcha was
    physical — ribbon was on bonnet Port 3, demo drove Port 1; a panel on the
    wrong port shows a stuck "top-half white" block that mimics a driver fault.
    Drove it via --led-parallel=3. Mark Phase 0 DONE in the status summary.
2026-07-01 docs: mark Tailscale + Phase-0 hardware questions resolved post-first-light
    OPEN_QUESTIONS: #8 Tailscale reachability DONE (root SSH works; cmdline
    instance-id gotcha fixed); #6 RGB/row-addr/slowdown CONFIRMED (RGB, type 0,
    slowdown 4 worked first try); #7 FM6126A NOT needed (standard driver). Fix
    the stale INVENTORY headline ("can't light one panel") -> Phase 0 done.
2026-07-01 feat(flight-card): legendary airline-branded 64x32 flight scene
    Redesign the single-panel flight tracker into a boarding-pass-style
    departure card with real airline branding, reusing the sim's 64 wordmark
    logos + ICAO->IATA manifest.
    - Logo band (NEW scenes/airlinelogo.py): full-colour wordmark, marquee for
    wide logos, brand-colour livery rule, name/ICAO fallback. Logos pre-baked
    offline (tools/bake_logos.py -> assets/airline_logos.pkl, ~75KB) and
    rendered with SetPixel -> no runtime Pillow, rides the Port-3 shim.
    - Route band (journey.py): split-flap flip-in of airport codes + a
    brand-colour chase marker along a journey track; home airport bold+warm.
    - Telemetry (flightdetails.py):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
2026-07-01 fix(logos): render real logos on-Pi with Pillow + LED legibility lift
    American (and other dark-navy wordmarks) rendered as barely-visible gray
    text — navy on black is the worst case on HUB75 (dimmest subpixel + the
    driver's CIE1931 curve). Two changes:
    - Add an LED legibility lift (raise HSV value, keep hue) so dark liveries
    read and their colourful marks pop (AA eagle, BA Speedmarque), while
    already-bright logos barely move.
    - Replace the offline pre-baked pixel-pack (assets/airline_logos.pkl +
    tools/bake_logos.py) with runtime rendering via Pillow straight from
    sim/logos/*.png, cached per carrier (setup/logos.py). Removes a custom
    byte-format and needless wheel-reinvention; Pi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
2026-07-01 feat(flights): configurable MAX_ALTITUDE + demo-mode fallback
    The board sat on the idle clock because (a) MAX_ALTITUDE was hardcoded to
    10000ft — excluding all cruise/overflight traffic, so the ~8x7mi box was
    usually empty — and (b) FR24's free API throttles under heavy polling and
    returns 0 flights.
    - MAX_ALTITUDE is now a config value (default 40000) so Logan climb/descent
    + overflights show; lower it for see-it-overhead-only mode.
    - DEMO_MODE (config, default False) serves a fixed set of realistic KBOS
    sample flights and skips FR24 — useful during a lull or when the free
    feed is throttled, so the flight card still shows.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
    [config.py]
2026-07-01 feat(data): replace FR24 with airplanes.live + adsbdb (free, no key, 10s poll)
    FR24's unofficial feed throttles/blocks under continuous polling. Switch to
    free community ADS-B with no key and no aggressive rate limits:
    - positions + aircraft type: airplanes.live /v2/point/{lat}/{lon}/{radius}
    - route (origin->destination): adsbdb.com callsign lookup, cached per callsign
    (the same enricher upstream its-a-plane uses)
    New utilities/overhead.py self-polls on a background thread every POLL_SECONDS
    (config, default 10) and emits the identical per-flight dict, so every scene
    works unchanged and display/__init__.py needs no edit. Config adds
    SEARCH_RADIUS_NM, POLL_SECONDS, MAX_FLIGHTS. FR24 impl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
    [config.py]
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2026-07-01 fix(render): logos were invisible — SetPixel monkeypatch fails on C-ext type
    Root cause: the Port-3 shim tried to add the +64 lane offset by monkeypatching
    FrameCanvas.SetPixel, but that's an immutable method on the compiled rgbmatrix
    type (TypeError, swallowed by try/except). So every SetPixel-drawn element (the
    whole logo, chase marker, vs triangle, loading dot) was written to lane 0
    (Port 1 = no panel) and vanished, while DrawText/DrawLine (module-level, truly
    patched) rendered on Port 3 — hence route/telemetry showed but logos never did.
    Fix: stop monkeypatching. Route pixel writes through a real Display.set_pixel()
    that adds self._lane_offset_y (0 in-repo, 64 on the Pi shim), mirro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
    [config.py]
2026-07-02 feat(board): 3-panel departure board (airline | route | telemetry)
    Two panels added left of the original (chained). Calibrated the geometry
    (canvas col 0..63 = physical LEFT, 64..127 = middle, 128..191 = right; no
    mirror/flip) and rebuilt the card as a 192x32 three-zone board:
    - LEFT (airlinelogo.py): the airline logo rendered big + static (fit within
    62x22) with the carrier name beneath in the brand colour, and a livery rule.
    - MIDDLE (journey.py): big stacked ORIGIN / DEST codes with split-flap flip-in,
    a plane sprite flying a dotted track between them; home airport bold+warm.
    - RIGHT (flightdetails.py): callsign, big FR24-coloured altitude with a
    climb/descent marker, aircraft type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
    [config.py]
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2026-07-02 fix(board): JetBlue name overflow + stale-route plausibility correction
    - JetBlue "cut off": jetBlue's logo is tall, so with a 13px name below the
    left-panel group was 35px > 32 and the name clipped off the bottom. Fix:
    BOX_H 22->20 (cap logo height) + always render the name in the 5x8 font, so
    logo + rule + name always fits 32 rows. Also BOX_W 62->56 to give wide
    wordmarks (jetBlue) a margin so they don't touch/clip at the seam.
    - Wrong route (AA909 showed ORD->MSP; real is BOS->DFW): free callsign->route
    DBs (adsbdb AND hexdb) both carry stale scheduled routes and disagree. Since
    we only track low-altitude traffic near BOS, such a flight almost always
    touches BOS. utilities/o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
2026-07-02 feat: plane-swoop scene transitions + fuller center jet sprite
    A big airliner swoops left->right on every scene change (flight<->flight,
    flight<->clock): everything left of the plane is the NEW screen, everything
    right is the OLD one, with a bright sweep line at the seam + a contrail.
    - utilities/transition.py: the effect works on the single persistent canvas by
    installing a CLIP WINDOW [0,edge) that all primitives honour during a wipe, so
    scenes only repaint the revealed left side and the OLD frame stays frozen on
    the right. Text is glyph-clipped (whole-glyph prefix that fits) via the real
    binding's CharacterWidth. Steady-state hot path is byte-identical (clip=None).
    install() al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
    [config.py]
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2026-07-02 cad: PARTS 2-6 + assembly — full mount hardware on shared params
    Every mount part as a real CadQuery solid on one shared parameter set
    (cad/parts/mount_params.py) so nothing drifts:
    1 top_cleat (rebuilt on params; upright now flush on piece front)
    2 anti_swing_foot (base + slide-up tab into the bottom groove)
    3 panel_rest (rest shoe; creep stop + height set)
    4 bars (2 alu bars + steel strip; cut list)
    5 corner_enclosure (Pi 4 + Triple Bonnet tray, hangs on left-wall groove)
    6 psu_bracket (LRS-350-5 cradle, vented)
    assembly.py unions all parts + renders the full cross-section and a 3D section;
    an automated boolean collide_check() confirms no bracke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
    [anti_swing_foot.py, assembly.py, bars.py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]
2026-07-02 cad: revise mount per manufacturing research (steel rails, tall cleat, -shoes)
    4 web-research agents (best-practice / off-the-shelf / process-labor / adversarial
    engineering) → docs/design/MANUFACTURING_PLAN.md. Method confirmed: print the custom
    parts + saw/drill the rails is least human labor. Validation forced 3 design changes:
    1 cleat -> tall C-bracket carrying BOTH rails on one spine (the coplanarity datum
    you laser-level once; jackscrew + slotted holes). Fixes the #1 risk that
    made a roughly-straight bar + 96 magnet screws telegraph waviness into seams.
    4 rails -> STEEL (flat bar top + ANGLE bottom whose leg is a continuous rest ledge ->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
    [anti_swing_foot.py, assembly.py, bars.py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]
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2026-07-02 docs+cad: reliability hardening synthesis (6 research streams) + cable clip
    Six cited reliability passes (strain relief / IDC ribbons / grounding+decoupling /
    24/7 failure modes / power terminals / EMI) -> docs/HARDENING.md: ranked failure modes,
    design-in-now vs add-later checklist, spares kit, maintenance schedule. Key items:
    retain all ~17 HUB75 connectors + first-anchor strain relief (screw-down, NOT adhesive
    - Part 8 cable_clip), service loops cut into cables, chimney valance (add low intake),
    wired Ethernet (disable WiFi - broadband emitter next to Pi), bulk decoupling caps at
    center feeds, bootlace ferrules + Belleville washers + latching JST-VH plugs, re-torque
    at 30 days. CORRECTS e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
    [08_cable_clip.stl]
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2026-07-21 docs: evidence-based print profiles + computed plate/batching plan
    PRINT_PROFILES.md (research-backed, supersedes PRINTING.md's 4-5 walls/15-20% infill):
    'Vestor Structural' = 8 wall loops + 100% infill + 0.16mm + 0.55 inner-wall width +
    230C + 40% cooling, supports off. Key data: orientation ~2x (already correct); 2->4
    walls = +65%; infill 20-80% is FLAT, only 100% matters; 0.3mm layers halve interlayer
    strength; annealing rejected (0 layer gain, 10% distortion); heated chamber harmful to
    PLA. PLA confirmed as the right material (beats PETG/ASA on strength+stiffness+adhesion;
    creep is not the failure mode at ~0.1-0.2 MPa = <2% UTS) — with one on-site check: IR
    the temp behind the panels (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
    [plate_plan.py]
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2026-07-21 fix(profiles): grid infill is invalid at 100% density -> rectilinear
    Bambu Studio rejects sparse_infill_pattern=grid when density=100%. At 100% the
    pattern is moot (solid), and rectilinear is Studio's own suggested substitute.
    Rebuilt both H2S + P2S profiles and added a sanity-check pass for known-invalid
    combos (pattern-vs-100%, inner-outer-inner needing >=3 walls, line width vs nozzle).
    [Vestor_Structural_H2S.3mf, Vestor_Structural_P2S.3mf]
2026-07-21 fix(profiles): 'rectilinear' is an invalid enum -> 'zig-zag'; pin inherits
    Verified against BambuStudio source (PrintConfig.cpp / ConfigManipulation.cpp):
    - s_keys_map_InfillPattern has NO 'rectilinear' key — Rectilinear serializes as
    'zig-zag'. A bad coEnum value is SILENTLY replaced by the option default (cubic),
    with no error dialog. Fixed to 'zig-zag'.
    - inherits set to '' explicitly: when inherits is non-empty, any key not listed in
    different_settings_to_system is silently overwritten from the system preset. Also
    populated different_settings_to_system[0] with all 16 changed keys as belt-and-braces.
    - infill_wall_overlap 25% -> 15% (ratio is over inner_wall_line_width; 25% over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
    [Vestor_Structural_H2S.3mf, Vestor_Structural_P2S.3mf]
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
